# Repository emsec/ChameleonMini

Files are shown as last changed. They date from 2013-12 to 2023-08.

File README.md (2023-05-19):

Chameleon-Mini
==============
This is the official repository of ChameleonMini, a freely programmable, portable tool for NFC security analysis that can emulate and clone contactless cards, read RFID tags and sniff/log RF data. Thanks to over 1700 backers from our [Kickstarter project](https://www.kickstarter.com/projects/1980078555/chameleonmini-a-versatile-nfc-card-emulator-and-mo), the current Revision G has been realized by Kasper & Oswald GmbH.

The ChameleonMini RevG is now also available via the Kasper & Oswald [Webshop](https://shop.kasper.it/). Thank you for supporting the project!

IMPORTANT: Third-party Clones
------------------
We are aware of various third-party ChameleonMini clones or modified variants that are available on the Internet. Warning: We have evidence that some of these devices are defective or suffer from reading problems et cetera. Please understand that we cannot give support for these non-official devices, as we have no schematics / layout or other information, nor do we know the manufacturers. In case of problems, please contact the manufacturers of your device directly.

Note to the manufacturers: Some of the third-party ChameleonMini are violating the ChameleonMini license, please obey the license (see LICENSE.txt)!

First Steps
-----------
To upgrade the firmware of your ChameleonMini, please visit the [Getting Started page](https://cdn.statically.io/gh/emsec/ChameleonMini/master/Doc/Doxygen/html/Page_GettingStarted.html) from the [doxygen documentation](https://cdn.statically.io/gh/emsec/ChameleonMini/master/Doc/Doxygen/html/index.html).

Supported Cards and Codecs
--------------------------
See [here](https://github.com/emsec/ChameleonMini/wiki/Supported-Cards-and--Codecs). The linked wiki page also includes notes on DESFire emulation and certain cases of application specific emulation (Gallagher).

Questions
---------
If you have any questions, please visit the [Issues page](https://github.com/emsec/ChameleonMini/issues) and ask your questions there so everyone benefits from the answer.

**Please note that we cannot give any support if you have issues with the RevE-rebooted hardware or any GUI. Please use this issues page only for problems with the RevG hardware as distributed by Kasper & Oswald and for problems with the firmware from this page.** 

External Contributions
----------------------
We appreciate every contribution to the project. Have a look at the [External Contributions page](https://github.com/emsec/ChameleonMini/wiki/External-Contributions).

Repository Structure
--------------------
The code repository contains
* Doc: A doxygen documentation
* Drivers: Chameleon drivers for Windows and Linux
* Dumps: Dumps of different smartcards
* Hardware: The layout and schematics of the PCB
* Firmware: The complete firmware including a modified Atmel DFU bootloader and LUFA
* Software: Contains a python tool for an easy configuration (and more) of the ChameleonMini, Note that this is currently under construction
* RevE: Contains the whole contents of the discontinued RevE repository.
* RevE-light: Contains our development files for the RevE-light - **WARNING:** currently not supported / not functional

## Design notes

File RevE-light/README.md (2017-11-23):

Chameleon-Mini RevE-light
==============

**WARNING:** The files in this folder are our current development version. *The hardware and software is not functional yet* - so do not use it. We will not answer any support inquiry regarding this version at the moment.

Structure
--------------------
This part of the code repository contains

* Hardware: The layout and schematics of the RevE-light - *NOT FUNCTIONAL*
* Firmware: The RevE-light firmware - *NOT FUNCTIONAL*

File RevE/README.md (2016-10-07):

Warning
=======
The whole content of this directory is outdated and discontinued.

Chameleon-Mini
==============

Further information can be found in the [project wiki](https://github.com/emsec/ChameleonMini/wiki) 
and the [doxygen documentation](http://htmlpreview.github.io/?https://github.com/emsec/ChameleonMini/blob/master/Doc/Doxygen/html/index.html)

The code repository contains
* Doc: A doxygen documentation 
* Drivers: LUFA Drivers for the USB-CDC interface
* Dumps: Dumps of different smart cards
* EAGLE: The full EAGLE board and schematics in two alternate versions
* Firmware: The complete firmware including a modified Atmel DFU bootloader and LUFA

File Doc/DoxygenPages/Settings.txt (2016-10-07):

/** \file */
/**
 * \page Page_Settings Settings
 * 
 * The ChameleonMini can act in different ways, the behavior is defined by \ref Page_Configurations "configurations". But also, the ChameleonMini has slots, which are a layer above the configurations. With the slots, it is possible to switch between different configurations and respective content, e.g., a card dump together with the configuration as Mifare Classic 1k card.
 * 
 * Properties
 * ==========
 * A slot is defined by settings: \ref SettingsEntryType.
 * 
 * Slot Changing Procedure
 * =======================
 * When the current slot is changed, the following procedure is applied:
 * -# Break potentially pending timeout commands.
 * -# Store the memory of the setting to the Flash.
 * -# Set the slot number of the currently active slot to the number of the new slot.
 * -# Set the slot pointer of the currently active slot to the pointer of the new slot.
 * -# Since the slot also contains the configuration, apply the \ref Anchor_ConfigurationChange "configuration changing procedure" with the new configuration for the new slot.
 * -# Log the slot change.
 * -# Recall the new content of the slot from the permanent Flash.
 * -# Signalize the slot change with an \ref Page_LED "LED", if an LED is configured to `SETTING_CHANGE`.
 */

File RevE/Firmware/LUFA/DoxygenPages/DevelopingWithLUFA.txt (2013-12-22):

/** \file
 *
 *  This file contains special DoxyGen information for the generation of the main page and other special
 *  documentation pages. It is not a project source file.
 */

/**
 *  \page Page_DevelopingWithLUFA Developing With LUFA
 *
 *  This section of the manual contains information on LUFA development, such as Getting Started information,
 *  information on compile-time tuning of the library and other developer-related sections.
 *
 *  <b>Subsections:</b>
 *  \li \subpage Page_BuildSystem - The LUFA Buildsystem
 *  \li \subpage Page_TokenSummary - Summary of Compile Time Tokens
 *  \li \subpage Page_Migration - Migrating from an Older LUFA Version
 *  \li \subpage Page_VIDPID - Allocated USB VID and PID Values
 *  \li \subpage Page_OSDrivers - Operating System Driver Information
 *  \li \subpage Page_BuildLibrary - Building as a Linkable Library
 *  \li \subpage Page_ExportingLibrary - Exporting LUFA for IDE Use
 *  \li \subpage Page_WritingBoardDrivers - How to Write Custom Board Drivers
 *  \li \subpage Page_SoftwareBootloaderStart - How to jump to the bootloader in software
 */

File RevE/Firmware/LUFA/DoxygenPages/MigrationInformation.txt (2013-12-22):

/** \file
 *
 *  This file contains special DoxyGen information for the generation of the main page and other special
 *  documentation pages. It is not a project source file.
 */

/** \page Page_Migration Migrating from Older Versions
 *
 *  Below is migration information for updating existing projects based on previous versions of the LUFA library
 *  to the next version released. It does not indicate all new additions to the library in each version change, only
 *  areas relevant to making older projects compatible with the API changes of each new release.
 *
 *  \section Sec_Migration130901 Migrating from 130303 to 130901
 *  <b>Non-USB Library Components</b>
 *    - The Board Dataflash \c Dataflash_Init() function now automatically configures the appropriate communication interface.
 *
 *  \section Sec_Migration130303 Migrating from 120730 to 130303
 *  <b>Device Mode</b>
 *    - The \ref HID_KEYBOARD_LED_KANA macro was previously misspelled as \c HID_KEYBOARD_LED_KATANA, and had an incorrect value. User applications requiring this
 *      constant should use the new name, and remove any workarounds for the previously incorrect macro definition.
 *    - The \c HID_KEYBOARD_SC_EQUAL_SIGN macro has been renamed to \ref HID_KEYBOARD_SC_KEYPAD_EQUAL_SIGN, and the previous definition of
 *      \c HID_KEYBOARD_SC_KEYPAD_EQUAL_SIGN has been renamed \ref HID_KEYBOARD_SC_KEYPAD_EQUAL_SIGN_AS400 to conform to the definitions in the HID specification.
 *
 *  <b>Host Mode</b>
 *    - The \ref HID_KEYBOARD_LED_KANA macro was previously misspelled as \c HID_KEYBOARD_LED_KATANA, and had an incorrect value. User applications requiring this
 *      constant should use the new name, and remove any workarounds for the previously incorrect macro definition.
 *    - The \c HID_KEYBOARD_SC_EQUAL_SIGN macro has been renamed to \ref HID_KEYBOARD_SC_KEYPAD_EQUAL_SIGN, and the previous definition of
 *      \c HID_KEYBOARD_SC_KEYPAD_EQUAL_SIGN has been renamed \ref HID_KEYBOARD_SC_KEYPAD_EQUAL_SIGN_AS400 to conform to the definitions in the HID specification.
 *
 *  \section Sec_Migration120730 Migrating from 120219 to 120730
 *  <b>Device Mode</b>
 *    - The device mode Audio Class driver now requires an additional configuration parameter, the Audio Control interface index. Existing applications should
 *      be adjusted to specify the additional configuration parameter.
 *    - The HID_DESCRIPTOR_JOYSTICK() macro no longer takes a variable number of axis as a parameter, due to OS incompatibilities; this macro now uses a fixed
 *      3 axis of data. User applications should update their calls to this macro and their report structures to suit a fixed 3-axis joystick report. If a user
 *      application requires more than 3 axis' of data, a custom report descriptor will need to be constructed by hand.
 *    - The \ref Endpoint_ConfigureEndpoint() function no longer takes in masks for the banks and direction; the number of banks is now an integer argument, and
 *      the direction is obtained from the full endpoint address within the device. Applications calling Endpoint_ConfigureEndpoint() should update their API
 *      call to use a full endpoint address (including ENDPOINT_DIR_IN or ENDPOINT_DIR_OUT direction in the MSB of the endpoint address) and an integer number
 *      of banks.
 *    - All endpoint functions now operate on full endpoint addresses within the device, rather than a directionless endpoint index. Applications should update
 *      their API calls to use full endpoint addresses when required within the device.
 *    - All device mode class drivers have been updated to use a new unified endpoint description structure for all endpoints; existing applications will need
 *      to update their class driver struct instantiation to match the new scheme (see \ref USB_Endpoint_Table_t).
 *    - The \c ENDPOINT_BANKS_SUPPORTED() and \c ENDPOINT_MAX_ENDPOINT_SIZE() macros have been removed, as these do not function correctly with the new addressing
 *      scheme for the endpoint APIs. Please refer to the target device's datasheet for the maximum bank size of each endpoint.
 *    - The MIDI class driver \ref MIDI_EventPacket_t event packet no longer contains separate \c CableIndex and \c Command entries; these have been combined
 *      into a single \c Event element which can be constructed using the new macro \ref MIDI_EVENT(). Existing applications should use the new macro and structure
 *      element name.
 *
 *  <b>Host Mode</b>
 *    - The Android Accessory Host class driver property strings are now a array of \c char* rather than a struct of named pointers. Existing applications
 *      should use C99 Designated Initializers with the property string indexes located in \ref AOA_Strings_t instead.
 *    - The \ref Pipe_ConfigurePipe() function no longer takes in masks for the banks and token; the number of banks is now an integer argument, and the token
 *      is now inferred from the full pipe address within the device, and the pipe type. Applications calling Pipe_ConfigurePipe() should update their API
 *      call to use a full pipe address (including PIPE_DIR_IN or PIPE_DIR_OUT direction in the MSB of the pipe address) and an integer number of banks.
 *    - All pipe functions now operate on full pipe addresses within the device, rather than a directionless pipe index. Applications should update their API
 *      calls to use full pipe addresses when required within the device.
 *    - All host mode class drivers have been updated to use a new unified pipe description structure for all pipes; existing applications will need to update
 *      their class driver struct instantiation to match the new scheme (see \ref USB_Pipe_Table_t).
 *    - The MIDI class driver \ref MIDI_EventPacket_t event packet no longer contains seperate \c CableIndex and \c Command entries; these have been combined
 *      into a single \c Event element which can be constructed using the new macro \ref MIDI_EVENT(). Existing applications should use the new macro and structure
 *      element name.
 *    - The library "LUFA/Drivers/USB/Core/ConfigDescriptor.c" source file has been renamed "LUFA/Drivers/USB/Core/ConfigDescriptors.c" as this was clashing with
 *      files in some low level host mode demo applications, preventing parallel project builds. If you are referencing the project source files directly instead
 *      of using the makefile module names, you will need to adjust your project makefile.
 *
 *  \section Sec_Migration120219 Migrating from 111009 to 120219
 *  <b>USB Core</b>
 *    - The HID_KEYBOARD_MODIFER_* macros in the HID class driver have been corrected to HID_KEYBOARD_MODIFIER_* (note the spelling of "modifier").
 *      Existing applications should switch over to the correctly spelled macro names.
 *    - The names of the USB Device and USB Host class driver files have changed; a new "ClassDevice" and "ClassHost" postfix has been added to the
 *      respective class driver files. Projects referencing the class driver source files by filename rather than the LUFA_SRC_USBCLASS makefile
 *      variable should append these postfixes to the source file names. Projects including the USB class driver dispatch headers directly should either
 *      switch to including the main USB driver header instead, or use the updated header filenames.
 *    - The USB_CONFIG_ATTR_BUSPOWERED constant has been renamed to USB_CONFIG_ATTR_RESERVED, as this was misnamed. All devices must set this bit in
 *      the Configuration descriptor's attributes field. As all devices are assumed to be bus-powered unless stated otherwise with the
 *      USB_CONFIG_ATTR_SELFPOWERED flag a replacement constant for bus powered devices is not provided.
 *
 *  <b>Device Mode</b>
 *    - The device mode Audio class driver now requires a new user application callback, \ref CALLBACK_Audio_Device_GetSetInterfaceProperty().
 *      Existing applications must implement this new callback, however if no audio entities are defined in the audio device's descriptors,
 *      this function may be hard-coded to always return false for previous behaviour to be retained.
 *
 *  \section Sec_Migration111009 Migrating from 110528 to 111009
 *  <b>Non-USB Library Components</b>
 *    - The \c JTAG_DEBUG_ASSERT() macro has been renamed \ref JTAG_ASSERT() to be consistent with \ref STDOUT_ASSERT().
 *
 *  <b>USB Core</b>
 *    - By default, unordered Endpoint and Pipe configuration is now allowed once again, via the previous workaround of
 *      reconfiguring all Endpoints/Pipes in order each time a new Endpoint/Pipe is created. To minimize the compiled program
 *      size, the new \c ORDERED_EP_CONFIG compile time option may be defined in the project makefile to restrict the ordering
 *      in exchange for a smaller compiled binary size.
 *    - The previous \c F_CLOCK symbol, required in the project makefile, has been renamed to \c F_USB. This is due to the previous name
 *      being far too generic for use in future architecture ports, where multiple clock domains are used.
 *
 *  <b>Device Mode</b>
 *    - The Endpoint stream functions now all require a \c BytesProcessed parameter instead of the previous callback parameter.
 *      This should be set to \c NULL to retain previous behaviour of the functions, or point to a location where the number of bytes
 *      processed in the current transaction can be stored. If the \c BytesProcessed parameter is non \c NULL, each time the endpoint
 *      bank becomes full and the packet is sent, the routine will exit with the new \ref ENDPOINT_RWSTREAM_IncompleteTransfer
 *      error code to allow the user application to determine when to send the next chunk of data.
 *    - The \ref CDC_Device_SendString() function now expects a null terminated string instead of an explicit length. Existing code
 *      should use the new \ref CDC_Device_SendData() function, or remove the length parameter from the function call.
 *    - The \c Endpoint_ResetFIFO() function has been renamed to \ref Endpoint_ResetEndpoint(), to make the API function names more
 *      consistent. Existing applications using the old function name should simply replace it with a call to the new function name.
 *    - The \c Endpoint_*_Byte() functions have been renamed Endpoint_*_8() to ensure they are correct across all architectures. Existing
 *      code using these functions should replace the previous function names with the new function names.
 *    - The \c Endpoint_*_Word() functions have been renamed Endpoint_*_16() to ensure they are correct across all architectures. Existing
 *      code using these functions should replace the previous function names with the new function names.
 *    - The \c Endpoint_*_DWord() functions have been renamed Endpoint_*_32() to ensure they are correct across all architectures. Existing
 *      code using these functions should replace the previous function names with the new function names.
 *    - The Device mode RNDIS class driver no longer stores the incoming and outgoing packets in the class driver instance; the user is
 *      now expected to manually define a storage location for the packet data. Packets must now be sent and received manually via a call
 *      to \ref RNDIS_Device_ReadPacket() and/or \ref RNDIS_Device_SendPacket().
 *    - The definition of the Audio class \ref USB_Audio_Descriptor_Format_t has been altered, to remove the fixed singular
 *      audio sample rate in the descriptor definition, and to rename the \c SampleFrequencyType to the more appropriate
 *      \c TotalDiscreteSampleRates. Existing applications will need to add an array of \ref USB_Audio_SampleFreq_t elements
 *      immediately following any \ref USB_Audio_Descriptor_Format_t descriptors, and insert the appropriate sampling rates
 *      supported by the device, as well as rename the descriptor elements to match the updated element names.
 *    - The device mode Audio class driver now requires a new user application callback, \ref CALLBACK_Audio_Device_GetSetEndpointProperty().
 *      Existing applications must implement this new callback, however if multiple sample rates or pitch control is not used,
 *      this function may be hard-coded to always return false for previous behaviour to be retained.
 *    - The \c USB_ConfigurationNumber, \c USB_RemoteWakeupEnabled and \c USB_CurrentlySelfPowered globals have been renamed to
 *      \ref USB_Device_ConfigurationNumber, \ref USB_Device_RemoteWakeupEnabled and \ref USB_Device_CurrentlySelfPowered to clearly indicate
 *      the USB mode they relate to. Existing applications using these variables should rename all references to the previous names.
 *    - The \c ENDPOINT_DESCRIPTOR_DIR_IN and \c ENDPOINT_DESCRIPTOR_DIR_OUT macros have now been replaced by \ref ENDPOINT_DIR_IN and
 *      \ref ENDPOINT_DIR_OUT to improve code clarity.
 *    - The \ref HID_DESCRIPTOR_JOYSTICK() macro now takes an additional (first) parameter indicating the number of axis in the joystick.
 *
 *  <b>Host Mode</b>
 *    - The Pipe stream functions now all require a \c BytesProcessed parameter instead of the previous callback parameter.
 *      This should be set to \c NULL to retain previous behaviour of the functions, or point to a location where the number of bytes
 *      processed in the current transaction can be stored. If the BytesProcessed parameter is non \c NULL, each time the pipe
 *      bank becomes full and the packet is sent, the routine will exit with the new \ref PIPE_RWSTREAM_IncompleteTransfer
 *      error code to allow the user application to determine when to send the next chunk of data.
 *    - The \ref PRNT_Host_SendString() and \ref CDC_Host_SendString() functions now expect a null terminated string instead of an explicit
 *      length. Existing code should use the new \ref PRNT_Host_SendData() and \ref CDC_Host_SendData() functions, or remove the
 *      length parameter from the function call.
 *    - The \c Pipe_ClearErrorFlags() function has been removed, as the pipe error flags are now automatically cleared when the
 *      \ref Pipe_ClearError() function is called.
 *    - The \c Pipe_*_Byte() functions have been renamed Pipe_*_8() to ensure they are correct across all architectures. Existing code using
 *      these functions should replace the previous function names with the new function names.
 *    - The \c Pipe_*_Word() functions have been renamed Pipe_*_16() to ensure they are correct across all architectures. Existing code using
 *      these functions should replace the previous function names with the new function names.
 *    - The \c Pipe_*_DWord() functions have been renamed Pipe_*_32() to ensure they are correct across all architectures. Existing code using
 *      these functions should replace the previous function names with the new function names.
 *    - The \c USB_Host_ClearPipeStall() function has been renamed to USB_Host_ClearEndpointStall(), as it operates on a full endpoint address
 *      within the attached device and not a pipe within the host. Existing code using the old function name should update the function calls and
 *      check for correct usage.
 *
 *  \section Sec_Migration101122 Migrating from 100807 to 101122
 *  <b>USB Core</b>
 *    - A new USB driver source file, \c Drivers/USB/HighLevel/EndpointStream.c now exists. This source file should be added
 *      to all project makefiles using the USB driver of LUFA, or the makefile should be updated to use the new module source
 *      variables.
 *    - A new USB driver source file, \c Drivers/USB/HighLevel/PipeStream.c now exists. This source file should be added to all
 *      project makefiles using the USB driver of LUFA, or the makefile should be updated to use the new module source variables.
 *    - The \c EVENT_USB_InitFailure() event has been removed, as the \ref USB_Init() function will no longer fail; if not USB mode is
 *      specified, the controller will default to UID selection mode.
 *    - The USB mode specifier constants have been moved into a new enum and renamed. Existing projects should use the equivalent
 *      value in the new \ref USB_Modes_t enum.
 *    - All class driver headers are now included as part of the standard \c LUFA/Drivers/USB/USB.h master dispatch header, and should
 *      no longer be included separately. Class driver module source files must still be added as a separate module in the project's
 *      makefile if used.
 *
 *  <b>Device Mode</b>
 *    - Endpoints MUST be allocated in ascending order to ensure that bank corruption does not occur. Ensure that your user application
 *      allocated endpoints in ascending order - or if your application uses the USB device mode class drivers, ensure that each instance's
 *      endpoint indexes are not overlapped with other interface's endpoints.
 *    - The signature for the \ref CALLBACK_USB_GetDescriptor() callback has changed, the \c void** \c const \c DescriptorAddress parameter is
 *      now \c const \c void** \c const \c DescriptorAddress. Existing applications should update their callback signatures to match this, and
 *      eliminate any casting of descriptor pointers to a non \c const pointer.
 *    - The names of the class specific descriptor type defines in the USB Class drivers have changed - refer to the driver documentation
 *      for each class driver for the new class specific descriptor type names.
 *    - The \c ENDPOINT_DOUBLEBANK_SUPPORTED() macro is has been renamed \c ENDPOINT_BANKS_SUPPORTED() and now returns the total number of
 *      banks supported by the given endpoint. Existing code should switch to the new naming scheme, and test that the return value of the
 *      macro is equal to or greater than 2 to regain the previous functionality.
 *    - The \c EVENT_USB_Device_UnhandledControlRequest() event is now named \ref EVENT_USB_Device_ControlRequest() and fires before (not after)
 *      the internal library event handlers. Existing code should rename the event handlers in the user application to match the new event
 *      name, and should ensure that the new execution order does not affect the application's operation.
 *
 *  <b>Host Mode</b>
 *    - Pipes MUST be allocated in ascending order to ensure that bank corruption does not occur. Ensure that your user application
 *      allocated pipes in ascending order - or if your application uses the USB host mode class drivers, ensure that each instance's
 *      pipe indexes are not overlapped with other interface's pipes.
 *    - The \c PRNT_Host_SendData() function has been renamed to \ref PRNT_Host_SendString(). Existing applications should simply
 *      replace all references to the obsolete function name with the new function name.
 *    - The names of the class specific descriptor type defines in the USB Class drivers have changed - refer to the driver documentation
 *      for each class driver for the new class specific descriptor type names.
 *    - The Still Image Host class' function prefix has been changed from \c SImage_ to  \c SI_, to remain consistent with the rest of the
 *      driver's enums, type defines and constants.
 *
 *  \section Sec_Migration100807 Migrating from 100513 to 100807
 *
 *  <b>Non-USB Library Components</b>
 *    - The Dataflash board driver stub file has changed, as dataflash functions previously located in the internal
 *      Dataflash driver of the library have now been moved to the individual board files. Existing drivers can
 *      copy-paste the new functions from the board Dataflash stub driver.
 *
 *  <b>USB Core</b>
 *    - A new USB driver source file, \c Drivers/USB/LowLevel/Device.c now exists. This source file should be added to all project
 *      makefiles using the USB driver of LUFA, or the makefile should be updated to use the new module source variables.
 *    - The \c Drivers/USB/LowLevel/DevChapter9.c source file has moved to \c Drivers/USB/HighLevel/DeviceStandardReq.c - this should
 *      be updated in all project makefiles, or the makefile should be updated to use the new module source variables.
 *    - The \c Drivers/USB/LowLevel/HostChapter9.h source file has moved to \c Drivers/USB/HighLevel/HostStandardReq.c - this should
 *      be updated in all project makefiles, or the makefile should be updated to use the new module source variables.
 *    - The \c Drivers/USB/LowLevel/LowLevel.c source file has moved to \c Drivers/LowLevel/USBController.c - this should be updated
 *      in all project makefiles, or the makefile should be updated to use the new module source variables.
 *
 *  <b>Device Mode</b>
 *    - The \c USB_Device_IsRemoteWakeupSent() macro has been removed, as the remote wakeup request is now fully handled by the
 *      enhanced \ref USB_Device_SendRemoteWakeup() function. Existing code may now discard any checks to \c USB_Device_IsRemoteWakeupSent().
 *    - The \c USB_Device_IsUSBSuspended() macro has been removed, as it is obsolete. Existing code should compare \ref USB_DeviceState
 *      to see if it the device is in the \ref DEVICE_STATE_Suspended state instead.
 *    - The \ref CDC_Device_ReceiveByte() function has changed, and now returns a signed 16-bit integer, with -1 indicating no data was
 *      received. This allows for more efficient coding, as a call to \ref CDC_Device_BytesReceived() is no longer needed if the exact
 *      number of queued bytes received is not needed.
 *
 *  <b>Host Mode</b>
 *    - The \ref CDC_Host_ReceiveByte() function has changed, and now returns a signed 16-bit integer, with -1 indicating no data was
 *      received. This allows for more efficient coding, as a call to \ref CDC_Host_BytesReceived() is no longer needed if the exact
 *      number of queued bytes received is not needed.
 *    - The \ref CDC_Host_USBTask() now calls \ref CDC_Host_Flush() automatically, flushing any queued data to the attached device. Manual
 *      flushing of the interface is no longer needed if the flushes should be in sync with calls to \ref CDC_Host_USBTask().
 *
 *  \section Sec_Migration100513 Migrating from 100219 to 100513
 *
 *  <b>Non-USB Library Components</b>
 *    - The \ref TWI_StartTransmission() function now takes in a timeout period, expressed in milliseconds, within which the addressed
 *      device must respond or the function will abort.
 *
 *  <b>Device Mode</b>
 *    - The \ref USB_Init() function no longer calls \c sei() to enable global interrupts, as the user application may need
 *      to perform other initialization before it is ready to handle global interrupts. The user application is now responsible
 *      for enabling global interrupts before or shortly after calling \ref USB_Init() to ensure that the enumeration process
 *      functions correctly.
 *    - The \c USBInterrupt.c USB driver source file has been relocated from \c LUFA/Drivers/USB/HighLevel/ to \c LUFA/Drivers/USB/LowLevel.
 *      Projects must update their makefile SRC values accordingly.
 *    - The HID Device Class driver's function signature for the \ref CALLBACK_HID_Device_ProcessHIDReport() function has been changed, to
 *      allow for a new \c ReportType parameter. This new parameter must be added in all user applications using the Device mode HID Class
 *      Driver, but may be ignored unless Host-to-Device FEATURE HID reports are used.
 *
 *  <b>Host Mode</b>
 *    - The \ref USB_Init() function no longer calls \c sei() to enable global interrupts, as the user application may need
 *      to perform other initialization before it is ready to handle global interrupts. The user application is now responsible
 *      for enabling global interrupts before or shortly after calling \ref USB_Init() to ensure that the enumeration process
 *      functions correctly.
 *    - The \c USBInterrupt.c USB driver source file has been relocated from \c LUFA/Drivers/USB/HighLevel/ to \c LUFA/Drivers/USB/LowLevel.
 *      Projects must update their makefile \c SRC values accordingly.
 *    - The HID Host Class driver's function signature for the \ref HID_Host_SendReportByID() function has been changed, to allow for a new
 *      ReportType parameter. Existing calls to this function should substitute \c REPORT_ITEM_TYPE_Out as this parameter's value.
 *
 *  \section Sec_Migration100219 Migrating from 091223 to 100219
 *
 *  <b>Non-USB Library Components</b>
 *    - Due to some ADC channels not being identical to their ADC MUX selection masks for single-ended conversions on some AVR models,
 *      the ADC driver now has explicit masks for each of the standard ADC channels (see \ref Group_ADC). These masks should be used
 *      when calling the ADC functions to ensure proper operation across all AVR models. Note that the \ref ADC_SetupChannel() function
 *      is an exception, and should always be called with a channel number rather than a channel mask.
 *
 *  <b>Host Mode</b>
 *    - The MIDI Host Class driver send and receive routines now operate on packed events, where multiple MIDI events may be
 *      packed into a single USB packet. This means that the sending of MIDI events will now be delayed until the MIDI send
 *      pipe bank is full. To override this new behaviour and revert to the previous behaviour, the user application may manually
 *      flush the queued event(s) to the device by calling \ref MIDI_Host_Flush().
 *    - The \ref Pipe_IsEndpointBound() function now takes the endpoint's direction into account, by checking if the MSB of the endpoint's address
 *      is set to denote IN endpoints. If the previous functionality where the direction is to be discounted is required, mask the endpoint
 *      address against the \ref PIPE_EPNUM_MASK token before calling \ref Pipe_IsEndpointBound().
 *
 *  <b>Device Mode</b>
 *    - The MIDI Device Class driver send and receive routines now operate on packed events, where multiple MIDI events may be
 *      packed into a single USB packet. This means that the sending of MIDI events will now be delayed until the MIDI send
 *      endpoint bank is full. To override this new behaviour and revert to the previous behaviour, the user application may manually
 *      flush the queued event(s) to the host by calling \ref MIDI_Device_Flush().
 *
 *  \section Sec_Migration091223 Migrating from 091122 to 091223
 *
 *  <b>Host Mode</b>
 *    - The Still Image Host Class driver \ref SI_Host_USBTask() and \ref SI_Host_ConfigurePipes() functions were misnamed, and are
 *      now named \c SImage_Host_USBTask() and \c SImage_Host_ConfigurePipes() respectively.
 *    - The \c HOST_SENDCONTROL_DeviceDisconnect enum value has been renamed to \ref HOST_SENDCONTROL_DeviceDisconnected to be in
 *      line with the rest of the library error codes.
 *    - The HID Parser item usages no longer contain separate minimum and maximum values, as this was a violation of the HID
 *      specification. Instead, the values are distributed evenly across each item as its usage value, to ensure that all items
 *      can be distinguished from one-another.
 *
 *  <b>Device Mode</b>
 *    - The \ref CALLBACK_HID_Device_CreateHIDReport() HID Device Class driver callback now has a new \c ReportType parameter to
 *      indicate the report type to generate. Existing applications may simply add and ignore this additional parameter.
 *
 *  \section Sec_Migration091122 Migrating from 090924 to 091122
 *
 *  <b>Host Mode</b>
 *    - The \c HID_PARSE_UsageStackOverflow HID parser error constant is now named \ref HID_PARSE_UsageListOverflow
 *    - The \ref CALLBACK_HIDParser_FilterHIDReportItem() HID Parser callback now passes a complete \ref HID_ReportItem_t to the
 *      user application, instead of just its attributes.
 *    - The \c USB_GetDeviceConfigDescriptor() function was incorrectly named and is now called \ref USB_Host_GetDeviceConfigDescriptor().
 *
 *  \section Sec_Migration090924 Migrating from 090810 to 090924
 *
 *  <b>Non-USB Library Components</b>
 *    - The \c ADC_Off() function has been renamed to \c ADC_ShutDown() to be consistent with the rest of the library.
 *    - The \ref SPI_Init() routine's parameters have changed, so that the clock polarity and data sampling modes can be set. See
 *      the \ref SPI_Init() function documentation for more details
 *    - The \ref Dataflash_Init() routine no longer initializes the SPI bus - the SPI bus should be initialized manually via a
 *      call to \ref SPI_Init() before using the Dataflash driver
 *
 *  <b>Host Mode</b>
 *    - The \c USB_GetDeviceConfigDescriptor() function's parameters and behaviour has changed; the user is required to
 *      preallocate the largest allowable buffer, and pass the size of the buffer to the function. This allows for a single
 *      call to the function to retrieve, size check and validate the Configuration Descriptor rather than having the user
 *      application perform these intermediary steps.
 *    - The HID report parser now requires a mandatory callback in the user code, to filter only the items the application
 *      is interested in into the processed HID report item structure to save RAM. See \ref CALLBACK_HIDParser_FilterHIDReportItem().
 *    - The HID report parser now always parses FEATURE and always ignores constant-data items - the \c HID_ENABLE_FEATURE_PROCESSING
 *      and \c HID_INCLUDE_CONSTANT_DATA_ITEMS compile time tokens now have no effect.
 *    - The \c USE_NONSTANDARD_DESCRIPTOR_NAMES compile time token has been removed - there are now separate \c USB_Descriptor_*
 *      and \c USB_StdDescriptor_* structures for both the LUFA and standardized element naming conventions so that both may be used in
 *      the one project. For existing projects using the standardized names, change all code to use the \c USB_StdDescriptor_* variants.
 *
 *  <b>Device Mode</b>
 *    - The \c USE_NONSTANDARD_DESCRIPTOR_NAMES compile time token has been removed - there are now separate \c USB_Descriptor_*
 *      and \c USB_StdDescriptor_* structures for both the LUFA and standardized element naming conventions so that both may be used in
 *      the one project. For existing projects using the standardized names, change all code to use the \c USB_StdDescriptor_* variants.
 *
 *  \section Sec_Migration090810 Migrating from 090605 to 090810
 *
 *  <b>All</b>
 *    - The "Simple Scheduler" has been <i>deprecated</i>, as it was little more than an abstracted loop and caused much confusion.
 *      User applications using the scheduler should switch to regular loops instead. The scheduler code will be removed in a future
 *      release.
 *    - The "Dynamic Memory Block Allocator" has been removed, as it was unused in (and unrelated to) the LUFA library and never
 *      used in user applications.
 *
 *  <b>Non-USB Library Components</b>
 *    - The \c ATTR_NOINLINE function attribute macro has been renamed to \ref ATTR_NO_INLINE to be in line with the rest of the function attribute
 *      macro names.
 *
 *  <b>Library Demos</b>
 *    - Most demos now have a corresponding Class Driver implementation, which uses the new internal library class drivers for the standard
 *      USB classes. This allows for more rapid device and host development, and so should be used in preference to the low level APIs where
 *      possible so that fixes to the class drivers propagate to all applications which use them automatically with each new LUFA release.
 *
 *  <b>Host Mode</b>
 *    - The \c HIDParser.c module has moved from \c LUFA/Drivers/USB/Class/ to \c LUFA/Drivers/USB/Class/Host/.
 *    - The \c USB_GetDeviceConfigDescriptor() function now requires the desired configuration index within the device as its first
 *      parameter, to add support for multi-configuration devices. Existing code should use a configuration index of 1 to indicate the
 *      first configuration descriptor within the device.
 *    - The non-standard "Ready" host state has been removed. Existing \ref HOST_STATE_Configured code should be moved to the end of
 *      the existing \ref HOST_STATE_Addressed state, and the existing HOST_STATE_Ready state code should be moved to the \ref HOST_STATE_Configured
 *      state.
 *    - The \c USB_IsConnected global has been removed, as it is too vague for general use. Test \ref USB_HostState explicitly to ensure the host is
 *      in the desired state instead.
 *    - The USB event names have been changed and their firing conditions changed to properly separate out Host mode events from Device mode
 *      events. See the \ref Group_Events page for details on the new event names and firing conditions.
 *
 *  <b>Device Mode</b>
 *    - The \ref CALLBACK_USB_GetDescriptor() function now takes an extra parameter to specify the descriptor's memory space so that
 *      descriptors in mixed memory spaces can be used. The previous functionality can be returned by defining the \c USE_FLASH_DESCRIPTORS
 *      token in the project makefile to fix all descriptors into FLASH space and remove the extra function parameter.
 *    - The \c USB_IsSuspended global has been removed - test \ref USB_DeviceState against \ref DEVICE_STATE_Suspended instead.
 *    - The \c USB_IsConnected global has been removed, as it is too vague for general use. Test \ref USB_DeviceState explicitly to ensure the device
 *      is in the desired state instead.
 *    - The VBUS events have been removed, as they are already exposed to the user via the \c USB_Connect and \c USB_Disconnect events.
 *    - The USB event names have been changed and their firing conditions changed to properly separate out Host mode events from Device mode
 *      events. See the \ref Group_Events page for details on the new event names and firing conditions.
 *
 *  \section Sec_Migration090605 Migrating from 090510 to 090605
 *
 *  <b>Device Mode</b>
 *    - Support for non-control data endpoint interrupts has been dropped due to many issues in the implementation. All existing
 *      projects using interrupts on non-control endpoints should switch to polling. For control interrupts, the library can
 *      manage the control endpoint via interrupts automatically by compiling with the \c INTERRUPT_CONTROL_ENDPOINT token defined.
 *    - The \c DESCRIPTOR_ADDRESS() macro has been removed. User applications should use normal casts to obtain a descriptor's memory
 *      address.
 *    - The library events system has been rewritten, so that all macros have been removed to allow for clearer user code. See
 *      \ref Group_Events for new API details.
 *    - The \c STREAM_CALLBACK() macro has been removed. User applications should replace all instances of the macro with regular
 *      function signatures of a function accepting no arguments and returning a \c uint8_t value.
 *    - The \c Event_DeviceError() event no longer exists, as its sole caller (unlinked \c USB_GetDescriptor() function) now produces a
 *      compilation error rather than a runtime error. The \c StdDescriptors.c file no longer exists as a result, and should be removed
 *      from project makefiles.
 *    - The \c USB_GetDescriptor() function has been renamed to \ref CALLBACK_USB_GetDescriptor() to be in line with the new \c CALLBACK_
 *      function prefixes for functions which <i>must</i> be implemented in the user application.
 *
 *  <b>Host Mode</b>
 *    - Support for non-control data pipe interrupts has been dropped due to many issues in the implementation. All existing
 *      projects using interrupts on non-control pipes should switch to polling.
 *    - The library events system has been rewritten, so that all macros have been removed to allow for clearer user code. See
 *      \ref Group_Events for new API details.
 *    - The \c STREAM_CALLBACK() macro has been removed. User applications should replace all instances of the macro with regular
 *      function signatures of a function accepting no arguments and returning a \c uint8_t value.
 *    - The \c DESCRIPTOR_COMPARATOR() macro has been removed. User applications should replace all instances of the macro with
 *      regular function signatures of a function accepting a void pointer to the descriptor to test, and returning a \c uint8_t value.
 *
 *  \section Sec_Migration090510 Migrating from 090401 to 090510
 *
 *  <b>All</b>
 *    - The \c ButtLoadTag.h header has been removed, as it was never used for its intended purpose. Projects should either remove all
 *      \c BUTTLOADTAG() elements, or download and extract \c ButtLoadTag.h header from the ButtLoad project.
 *    - The \c Drivers/AT90USBXXX/ directory has been renamed to \c Drivers/Peripheral/.
 *    - The \c Serial_Stream driver has been renamed to \c SerialStream to remain consistent with the rest of the library naming scheme.
 *    - The HWB driver has changed to the \c Buttons driver. See the board Buttons driver documentation for the new API.
 *
 *  <b>Dual Role Mode</b>
 *    - The \c USB_PowerOnFail event has been renamed to \c USB_InitFailure.
 *    - The functions in \c OTG.h have been renamed to remain more consistent with the library API. See the functions in \c OTG.h for more
 *      details.
 *
 *  <b>Device Mode</b>
 *    - The \c Endpoint_ClearCurrentBank() macro has been removed, and is now replaced with the \ref Endpoint_ClearIN(), \ref Endpoint_ClearOUT()
 *      macros. See \c Endpoint.h documentation for more details on the new endpoint management macros.
 *    - The \c Endpoint_ReadWriteAllowed() macro has been renamed to \ref Endpoint_IsReadWriteAllowed() to be more consistent with the rest of
 *      the API naming scheme.
 *    - The \c Endpoint_IsSetupINReady() and \c Endpoint_IsSetupOUTReceived() macros have been renamed to \ref Endpoint_IsINReady() and
 *      \ref Endpoint_IsOUTReceived() respectively.
 *    - The \c Endpoint_IsSetupReceived() macro has been renamed to \ref Endpoint_IsSETUPReceived().
 *    - The \c Endpoint_ClearSetupReceived() macro has been renamed to \ref Endpoint_ClearSETUP().
 *    - All endpoint read/write/discard aliases which did not have an explicitly endianness specifier (such as \c Endpoint_Read_Word()) have
 *      been removed for clarity. Existing projects should use the \c _LE suffix on such calls to use the explicit Little Endian versions.
 *    - The \c USB_UnhandledControlPacket event no longer has any parameters. User code should no longer attempt to read in the remainder of
 *      the Control Request header as all Control Request header data is now preloaded by the library and made available in the
 *      USB_ControlRequest structure.
 *    - The \c FEATURELESS_CONTROL_ONLY_DEVICE token has been renamed to \c CONTROL_ONLY_DEVICE.
 *    - The \c STATIC_ENDPOINT_CONFIGURATION is no longer applicable as the library will apply this optimization when appropriate automatically.
 *    - The values of the \ref Endpoint_Stream_RW_ErrorCodes_t and \ref Endpoint_ControlStream_RW_ErrorCodes_t enums have had the \c ERROR_ portion
 *      of their names removed.
 *
 *  <b>Host Mode</b>
 *    - The \ref USB_Host_SendControlRequest() function no longer automatically selects the Control pipe (pipe 0) to allow it to be used on
 *      other control type pipes. Care should be taken to ensure that the Control pipe is always selected before the function is called
 *      in existing projects where the Control pipe is to be operated on.
 *    - The USB Host management task now saves and restores the currently selected pipe before and after the task runs. Projects no longer
 *      need to manage this manually when calling the USB management task.
 *    - The \c Pipe_ClearCurrentBank() macro has been removed, and is now replaced with the Pipe_ClearIN(), Pipe_ClearOUT() macros. See
 *      Pipe.h documentation for more details on the new pipe management macros.
 *    - The \c Pipe_ReadWriteAllowed() macro has been renamed to \ref Pipe_IsReadWriteAllowed() to be more consistent with the rest of the API
 *      naming scheme.
 *    - The \c Pipe_IsSetupINReceived() and \c Pipe_IsOutReady() macros have been renamed to \ref Pipe_IsINReceived() and \ref Pipe_IsOUTReady()
 *      respectively.
 *    - The new \ref Pipe_ClearSETUP() macro should be used to send SETUP transactions, rather than the previous \c Pipe_ClearSetupOUT() macro.
 *    - The \c Pipe_IsSetupSent() macro has been renamed to \ref Pipe_IsSETUPSent().
 *    - The \c Pipe_ClearSetupSent() macro is no longer applicable and should be removed.
 *    - All pipe read/write/discard aliases which did not have an explicitly endianness specifier (such as \c Pipe_Read_Word()) have
 *      been removed for clarity. Existing projects should use the \c _LE suffix on such calls to use the explicit Little Endian versions.
 *    - The \c Host_IsResetBusDone() macro has been renamed to \c Host_IsBusResetComplete().
 *    - The \c Pipe_Ignore_Word() and \c Pipe_Ignore_DWord() functions have been renamed to \c Pipe_Discard_Word() and \c Pipe_Discard_DWord()
 *      to remain consistent with the rest of the pipe API.
 *    - It is no longer needed to manually include the headers from \c LUFA/Drivers/USB/Class, as they are now included along with the rest
 *      of the USB headers when \c LUFA/Drivers/USB/USB.h is included.
 *    - Functions in the \c ConfigDescriptor.h header file no longer have \c Host_ as part of their names.
 *    - The \c ProcessHIDReport() has been renamed to \ref USB_ProcessHIDReport(), \c GetReportItemInfo() has been renamed to \ref USB_GetHIDReportItemInfo()
 *      and \c SetReportItemInfo() has been renamed to \ref USB_GetHIDReportItemInfo().
 *    - The values of the \ref DSearch_Return_ErrorCodes_t and \ref DSearch_Comp_Return_ErrorCodes_t enums have had their respective \c Descriptor_Search
 *      and \c Descriptor_Search_Comp prefixes changed to all caps.
 *    - The \c USB_HostRequest global has been renamed to \ref USB_ControlRequest, and is used in Device mode also. The \c USB_Host_Request_Header_t
 *      structure type has been renamed to \ref USB_Request_Header_t.
 *    - The values of the \ref Pipe_Stream_RW_ErrorCodes_t enum have had the \c ERROR_ portion of their names removed.
 *
 *  \section Sec_Migration090401 Migrating from 090209 to 090401
 *
 *  <b>All</b>
 *    - LUFA projects must now give the raw input clock frequency (before any prescaling) as a compile time constant \c F_USB,
 *      defined in the project makefile and passed to the compiler via the -D switch.
 *    - The makefile EEPROM programming targets for FLIP and dfu-programmer no longer program in the FLASH data in addition to the
 *      EEPROM data into the device. If both are to be programmed, both the EEPROM and FLASH programming targets must be called.
 *    - As the avr-libc macro has been corrected in recent avr-libc distributions, the \c SetSystemClockPrescaler() macro has been removed.
 *      Include \c <avr/power.h> and call \c clock_prescale_set(clock_div_1); instead on recent avr-libc distributions.
 *
 *  <b>Library Demos</b>
 *    - The USBtoSerial demo now discards all data when not connected to a host, rather than buffering it for later transmission.
 *
 *  <b>Non-USB Library Components</b>
 *    - The \c ATTR_ALWAYSINLINE function attribute macro has been renamed to \ref ATTR_ALWAYS_INLINE.
 *    - Custom board Dataflash drivers now require the implementation of \ref Dataflash_SelectChipFromPage() and \ref Dataflash_SendAddressBytes().
 *
 *  <b>Device Mode</b>
 *    - The \c NO_CLEARSET_FEATURE_REQUEST compile time token has been renamed to \c FEATURELESS_CONTROL_ONLY_DEVICE, and its function expanded
 *      to also remove parts of the Get Status chapter 9 request to further reduce code usage. On all applications currently using the
 *      \c NO_CLEARSET_FEATURE_REQUEST compile time token, it can be replaced with the \c FEATURELESS_CONTROL_ONLY_DEVICE token with no further
 *      modifications required.
 *
 *  \section Sec_Migration090209 Migrating from 081217 to 090209
 *
 *  <b>Device Mode</b>
 *    - The \c ENDPOINT_MAX_ENDPOINTS constant has been renamed to the more appropriate name of \c ENDPOINT_TOTAL_ENDPOINTS.
 *    - The \c USB_STREAM_TIMEOUT_MS stream timeout default period has been extended to 100ms. This can be overridden in the user
 *      makefile if desired to restore the previous 50ms timeout.
 *
 *  <b>Host Mode</b>
 *    - The \c PIPE_MAX_ENDPOINTS constant has been renamed to the more appropriate name of \c PIPE_TOTAL_ENDPOINTS.
 *    - The \c USB_STREAM_TIMEOUT_MS stream timeout default period has been extended to 100ms. This can be overridden in the user
 *      makefile if desired to restore the previous 50ms timeout.
 *    - The \c USB_DeviceEnumerationFailed event now contains a second \c SubErrorCode parameter, giving the error code of the function
 *      which failed.
 *    - The \c HID_PARSE_Sucessful enum member constant name has been corrected to \ref HID_PARSE_Successful.
 *
 *  <b>Non-USB Library Components</b>
 *    - The previous \c SPI_SendByte() functionality is now located in \ref SPI_TransferByte(). \ref SPI_SendByte() now discards the return byte
 *      for speed, to compliment the new \ref SPI_ReceiveByte() function. If bidirectional SPI transfers are required, calls to \ref SPI_SendByte()
 *      should be changed to \ref SPI_TransferByte().
 *    - The serial driver now sets the Tx line as an output explicitly, and enables the pull-up of the Rx line.
 *    - The \ref Serial_Init() and \c SerialStream_Init() functions now take a second \c DoubleSpeed parameter, which indicates if the USART
 *      should be initialized in double speed mode - useful in some circumstances for attaining baud rates not usually possible at the given AVR
 *      clock speed.
 *
 *  \section Sec_Migration171208 Migrating from V1.5.3 to 081217
 *
 *  <b>All</b>
 *    - The MyUSB project name has been changed to LUFA (Lightweight Framework for USB AVRs). All references to MyUSB, including macro names,
 *      have been changed to LUFA.
 *
 *  <b>Library Demos</b>
 *    - The ReconfigureUSART() routine in the USBtoSerial demo was not being called after new line encoding
 *      parameters were set by the host. Projects built on the USBtoSerial code should update to the latest version.
 *    - The HID Parser now supports multiple report (on a single endpoint) HID devices. The MouseHostWithParser and
 *      KeyboardHostWithPaser demos use the updated API functions to function correctly on such devices. Projects
 *      built on either "WithParser" demo should update to the latest code.
 *    - The RNDIS demo TCP stack has been modified so that connections can be properly closed. It is still not
 *      recommended that the MyUSB RNDIS demo TCP/IP stack be used for anything other than demonstration purposes,
 *      as it is neither a full nor a standards compliant implementation.
 *
 *  <b>Non-USB Library Components</b>
 *    - The Serial_IsCharReceived() macro has been changed to the correct spelling of Serial_IsCharReceived() in Serial.h.
 *
 *  <b>Device Mode</b>
 *    - The MANUAL_PLL_CONTROL compile time token has been removed, and replaced with a USB_OPT_MANUAL_PLL mask
 *      to be used in the Options parameter of the USB_Init() function.
 *    - Calling USB_Init() now forces a complete USB interface reset and enumeration, even if the USB interface is
 *      currently initialized.
 *    - Interrupts are now disabled when processing control requests, to avoid problems with interrupts causing the library
 *      or user request processing code to exceed the strict USB timing requirements on control transfers.
 *    - The USB Reset event now resets and disables all device endpoints. If user code depends on endpoints remaining configured
 *      after a Reset event, it should be altered to explicitly re-initialize all user endpoints.
 *    - The prototype for the GetDescriptor function has been changed, as the return value was redundant. The function now
 *      returns the size of the descriptor, rather than passing it back via a parameter, or returns NO_DESCRIPTOR if the specified
 *      descriptor does not exist.
 *    - The NO_DESCRIPTOR_STRING macro has been renamed NO_DESCRIPTOR, and is now also used as a possible return value for the
 *      GetDescriptor function.
 *
 *  <b>Host Mode</b>
 *    - The MANUAL_PLL_CONTROL compile time token has been removed, and replaced with a USB_OPT_MANUAL_PLL mask
 *      to be used in the Options parameter of the USB_Init() function.
 *    - The HID report parser now supports multiple Report IDs. The HID report parser GetReportItemInfo() and
 *      SetReportItemInfo() routines now return a boolean, set if the requested report item was located in the
 *      current report. If sending a report to a multi-report device, the first byte of the report is automatically
 *      set to the report ID of the given report item.
 *    - Calling USB_Init() now forces a complete USB interface reset and enumeration, even if the USB interface is
 *      currently initialized.
 *
 *  \section Sec_Migration152 Migrating from V1.5.2 to V1.5.3
 *
 *  <b>Library Demos</b>
 *    - Previously, all demos contained a serial number string descriptor, filled with all zeros. A serial number
 *      string is required in Mass Storage devices, or devices which are to retain settings when moved between
 *      ports on a machine. As people were not changing the serial number value, this was causing conflicts and so
 *      the serial number descriptor has been removed from all but the Mass Storage demo, which requires it.
 *    - The AudioOut and AudioIn demos did not previously silence their endpoints when the host has deactivated
 *      them. Projects built upon either demo should upgrade to the latest code.
 *    - The FEATURE_ENDPOINT macro has been renamed FEATURE_ENDPOINT_HALT, and is now correctly documented.
 *    - The MassStoreHost demo contained errors which caused it to lock up randomly on certain devices. Projects built
 *      on the MassStoreDemo code should update to the latest version.
 *    - The Interrupt type endpoint in the CDC based demos previously had a polling interval of 0x02, which caused
 *      problems on some Linux systems. This has been changed to 0xFF, projects built on the CDC demos should upgrade
 *      to the latest code.
 *    - The HID keyboard and mouse demos were not previously boot mode compatible. To enable boot mode support, projects
 *      built on the keyboard or mouse demos (or derivatives) should upgrade to the latest code.
 *    - The Mass Storage demo was not previously standards compliant. Projects built on the Mass Storage demo should
 *      upgrade to the latest code.
 *    - The USART was not being reconfigured after the host sent new encoding settings in the USBtoSerial demo. This was
 *      previously discovered and fixed, but the change was lost. Projects built on the USBtoSerial demo should update
 *      to the latest code.
 *
 *  <b>Device Mode</b>
 *    - The endpoint non-control stream functions now have a default timeout of 50ms between packets in the stream.
 *      If this timeout is exceeded, the function returns the new ENDPOINT_RWSTREAM_ERROR_Timeout error value. The
 *      timeout value can be overridden by defining the USB_STREAM_TIMEOUT_MS in the project makefile to the desired
 *      timeout duration in ms.
 *    - Rather than returning fixed values, the flags indicating if the device has Remote Wakeup currently enabled
 *      and/or is self-powered are now accessed and set through the new USB_RemoteWakeupEnabled and
 *      USB_CurrentlySelfPowered macros. See the DevChapter9.h documentation for more details.
 *    - All endpoint stream functions now require an extra Callback function parameter. Existing code may be updated
 *      to either supply NO_STREAM_CALLBACK as the extra parameter, or disable stream callbacks altogether by passing
 *      the token NO_STREAM_CALLBACKS to the compiler using the -D switch.
 *
 *  <b>Host Mode</b>
 *    - The pipe non-control stream functions now have a default timeout of 50ms between packets in the stream.
 *      If this timeout is exceeded, the function returns the new PIPE_RWSTREAM_ERROR_Timeout error value. The
 *      timeout value can be overridden by defining the USB_STREAM_TIMEOUT_MS in the project makefile to the desired
 *      timeout duration in ms.
 *    - CollectionPath_t has been renamed to HID_CollectionPath_t to be more in line with the other HID parser structures.
 *    - All pipe stream functions now require an extra Callback function parameter. Existing code may be updated
 *      to either supply NO_STREAM_CALLBACK as the extra parameter, or disable stream callbacks altogether by passing
 *      the token NO_STREAM_CALLBACKS to the compiler using the -D switch.
 *
 *  \section Sec_Migration151 Migrating from V1.5.1 to V1.5.2
 *
 *  <b>Library Demos</b>
 *    - The RNDIS demo application has been updated so that it is functional on Linux under earlier implementations
 *      of the RNDIS specification, which had non-standard behaviour. Projects built upon the demo should upgrade
 *      to the latest code.
 *    - The DFU class bootloader has had several bugs corrected in this release. It is recommended that where
 *      possible any existing devices upgrade to the latest bootloader code.
 *
 *  \section Sec_Migration150 Migrating from V1.5.0 to V1.5.1
 *
 *  <b>Library Demos</b>
 *    - The USBtoSerial demo was broken in the 1.5.0 release, due to incorrect register polling in place of the
 *      global "Transmitting" flag. The change has been reverted in this release. Projects built upon the demo
 *      should upgrade to the latest code.
 *    - The HID class demos did not implement the mandatory GetReport HID class request. Projects built upon the HID
 *      demos should upgrade to the latest code.
 *    - The HID class demos incorrectly reported themselves as boot-protocol enabled HID devices in their descriptors.
 *      Projects built upon the HID demos should upgrade to the latest code.
 *    - The MIDI device demo had incorrect AudioStreaming interface descriptors. Projects built upon the MIDI demo
 *      should upgrade to the latest code.
 *    - The AudioOut demo did not correctly tristate the speaker pins when USB was disconnected, wasting power.
 *      Projects built upon the AudioOut demo should upgrade to the latest code.
 *
 *  \section Sec_Migration141 Migrating from V1.4.1 to V1.5.0
 *
 *  <b>Library Demos</b>
 *    - Previous versions of the library demos had incorrectly encoded BCD version numbers in the descriptors. To
 *      avoid such mistakes in the future, the VERSION_BCD macro has been added to StdDescriptors.h. Existing
 *      projects should at least manually correct the BCD version numbers, or preferably update the descriptors to
 *      encode the version number in BCD format using the new macro.
 *    - The mandatory GetReport class-specific request was accidentally omitted from previous versions of the demos
 *      based on the Human Interface Device (HID) class. This has been corrected, and any user projects based on the
 *      HID demos should also be updated accordingly.
 *    - The CDC demos now correctly send an empty packet directly after a full packet, to end the transmission.
 *      Failure to do this on projects which always or frequently send full packets will cause buffering issues on
 *      the host OS. All CDC user projects are advised to update their transmission routines in the same manner as
 *      the library CDC demos.
 *    - The previous interrupt-driven Endpoint/Pipe demos did not properly save and restore the currently selected
 *      Endpoint/Pipe when the ISR fired. This has been corrected - user projects based on the interrupt driven
 *      demos should also update to properly save and restore the selected Endpoint/Pipe.
 *
 *  <b>Non-USB Library Components</b>
 *    - The Atomic.h and ISRMacro.h header files in MyUSB/Common have been removed, as the library is now only
 *      compatible with avr-libc library versions newer than the time before the functionality of the deleted
 *      headers was available.
 *
 *  <b>Device Mode</b>
 *    - The GetDescriptor function (see StdDescriptors.h) now has a new prototype, with altered parameter names and
 *      functions. Existing projects will need to update the GetDescriptor implementation to reflect the new API.
 *      The previously split Type and Index parameters are now passed as the original wValue parameter to the
 *      function, to make way for the USB specification wIndex parameter which is <i>not</i> the same as the
 *      previous Index parameter.
 *    - The USB_UnhandledControlPacket event (see Events.h) now has new parameter names, to be in line with the
 *      official USB specification. Existing code will need to be altered to use the new parameter names.
 *    - The USB_CreateEndpoints event (see Events.h) has been renamed to USB_ConfigurationChanged, which is more
 *      appropriate. It fires in an identical manner to the previously named event, thus the only change to be made
 *      is the event name itself in the user project.
 *    - The USB_Descriptor_Language_t structure no longer exists in StdDescriptors.h, as this was a
 *      pseudo-descriptor modeled on the string descriptor. It is replaced by the true USB_Descriptor_String_t type
 *      descriptor as indicated in the USB specification, thus all device code must be updated accordingly.
 *    - The names of several Endpoint macros have been changed to be more consistent with the rest of the library,
 *      with no implementation changes. This means that existing code can be altered to use the new macro names
 *      with no other considerations required. See Endpoint.h for the new macro names.
 *    - The previous version of the MassStorage demo had an incorrect value in the SCSI_Request_Sense_Response_t
 *      structure named SenseData in SCSI.c which caused some problems with some hosts. User projects based on this
 *      demo should correct the structure value to maintain compatibility across multiple OS platforms.
 *    - By default, the descriptor structures use the official USB specification names for the elements. Previous
 *      versions of the library used non-standard (but more verbose) names, which are still usable in the current
 *      and future releases when the correct compile time option is enabled. See the StdDescriptors.h file
 *      documentation for more details.
 *
 *  <b>Host Mode</b>
 *    - The USB_Host_Request_Header_t structure in HostChapter9.h (used for issuing control requests) has had its
 *      members renamed to the official USB specification names for requests. Existing code will need to be updated
 *      to use the new names.
 *    - The names of several Pipe macros have been changed to be more consistent with the rest of the library,
 *      with no implementation changes. This means that existing code can be altered to use the new macro names
 *      with no other considerations required. See Pipe.h for the new macro names.
 *    - By default, the descriptor structures use the official USB specification names for the elements. Previous
 *      versions of the library used non-standard (but more verbose) names, which are still usable in the current
 *      and future releases when the correct compile time option is enabled. See the StdDescriptors.h file
 *      documentation for more details.
 *    - The names of the macros in Host.h for controlling the SOF generation have been renamed, see the Host.h
 *      module documentation for the new macro names.
 *
 *  <b>Dual Role Mode</b>
 *    - The OTG.h header file has been corrected so that the macros now perform their stated functions. Any existing
 *      projects using custom headers to fix the broken OTG header should now be altered to once again use the OTG
 *      header inside the library.
 *    - The USB_DeviceEnumerationComplete event (see Events.h) now also fires in Device mode, when the host has
 *      finished enumerating the device. Projects relying on the event only firing in Host mode should be updated
 *      so that the event action only occurs when the USB_Mode global is set to USB_MODE_HOST.
 */

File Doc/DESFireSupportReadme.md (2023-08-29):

# Chameleon Mini firmware support for DESFire tag emulation

## Quick configuration of cloned DESFire tags

### Chameleon Mini terminal addons to support DESFire tag configurations

#### Selecting a DESFire configuration

```bash
CONFIG=?
CONFIG=MF_DESFIRE
CONFIG=MF_DESFIRE_2KEV1
CONFIG=MF_DESFIRE_4KEV1
CONFIG=MF_DESFIRE_4KEV2
```

#### DF_SETHDR -- Set PICC header information 

The UID for the tag can be set using separate Chameleon terminal commands as 
usual for all other configurations.
We can modify the remaining tag header information emulated by the tag as follows:
```bash
DF_SETHDR=ATS NNxxxx[...]
DF_SETHDR=ATQA xxxx
DF_SETHDR=ManuID xx
DF_SETHDR=HwType xx
DF_SETHDR=HwSubtype xx
DF_SETHDR=HwProtoType xx 
DF_SETHDR=HwVers mmMM
DF_SETHDR=SwType xx
DF_SETHDR=SwSubtype xx
DF_SETHDR=SwProtoType xx
DF_SETHDR=SwVers mmMM
DF_SETHDR=BatchNo xxxxxxxxxx
DF_SETHDR=ProdDate WWYY
```
Warning! The ATS bytes have the following structure `NNxxxx[...]` where NN is the length of the entire ATS, including the length byte. The ATS (inc. the len byte) can be from 3 to 20 bytes long. The default is `067577810280`.

##### Examples:

The default ATS bytes for a DESFire tag are the same as specifying:
```bash
DF_SETHDR=ATS 067577810280
```
To set the ATS bytes reported to emulate a JCOP tag:
```bash
DF_SETHDR=ATS 0675f7b102
```
To reset the ATQA value returned in the anticollision loop handshaking:
```
DF_SETHDR=ATQA 0344
DF_SETHDR=ATQA 2838
```

##### Documentation for cloning specific tag types

```cpp
/* Other HW product types for DESFire tags: See page 7 of
 * https://www.nxp.com/docs/en/application-note/AN12343.pdf
 */
// typedef enum DESFIRE_FIRMWARE_ENUM_PACKING {
//     NATIVEIC_PHYS_CARD                 = 0x01,
//     LIGHT_NATIVEIC_PHYS_CARD           = 0x08,
//     MICROCONTROLLER_PHYS_CARDI         = 0x81,
//     MICROCONTROLLER_PHYS_CARDII        = 0x83,
//     JAVACARD_SECURE_ELEMENT_PHYS_CARD  = 0x91,
//     HCE_MIFARE_2GO                     = 0xa1,
// } DESFireHWProductCodes;
```
An up-to-date listing of bytes that indicate the tag manufacturer ID is 
found in the [Proxmark3 client source](https://github.com/RfidResearchGroup/proxmark3/blob/65b9a9fb769541f5d3e255ccf2c17d1cb77ac126/client/src/cmdhf14a.c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):
```cpp
static const manufactureName_t manufactureMapping[] = {
    // ID,  "Vendor Country"
    { 0x01, "Motorola UK" },
    { 0x02, "ST Microelectronics SA France" },
    { 0x03, "Hitachi, Ltd Japan" },
    { 0x04, "NXP Semiconductors Germany" },
    { 0x05, "Infineon Technologies AG Germany" },
    { 0x06, "Cylink USA" },
    { 0x07, "Texas Instrument France" },
    { 0x08, "Fujitsu Limited Japan" },
    { 0x09, "Matsushita Electronics Corporation, Semiconductor Company Japan" },
    { 0x0A, "NEC Japan" },
    { 0x0B, "Oki Electric Industry Co. Ltd Japan" },
    { 0x0C, "Toshiba Corp. Japan" },
    { 0x0D, "Mitsubishi Electric Corp. Japan" },
    { 0x0E, "Samsung Electronics Co. Ltd Korea" },
    { 0x0F, "Hynix / Hyundai, Korea" },
    { 0x10, "LG-Semiconductors Co. Ltd Korea" },
    { 0x11, "Emosyn-EM Microelectronics USA" },
    { 0x12, "INSIDE Technology France" },
    { 0x13, "ORGA Kartensysteme GmbH Germany" },
    { 0x14, "SHARP Corporation Japan" },
    { 0x15, "ATMEL France" },
    { 0x16, "EM Microelectronic-Marin SA Switzerland" },
    { 0x17, "KSW Microtec GmbH Germany" },
    { 0x18, "ZMD AG Germany" },
    { 0x19, "XICOR, Inc. USA" },
    { 0x1A, "Sony Corporation Japan" },
    { 0x1B, "Malaysia Microelectronic Solutions Sdn. Bhd Malaysia" },
    { 0x1C, "Emosyn USA" },
    { 0x1D, "Shanghai Fudan Microelectronics Co. Ltd. P.R. China" },
    { 0x1E, "Magellan Technology Pty Limited Australia" },
    { 0x1F, "Melexis NV BO Switzerland" },
    { 0x20, "Renesas Technology Corp. Japan" },
    { 0x21, "TAGSYS France" },
    { 0x22, "Transcore USA" },
    { 0x23, "Shanghai belling corp., ltd. China" },
    { 0x24, "Masktech Germany Gmbh Germany" },
    { 0x25, "Innovision Research and Technology Plc UK" },
    { 0x26, "Hitachi ULSI Systems Co., Ltd. Japan" },
    { 0x27, "Cypak AB Sweden" },
    { 0x28, "Ricoh Japan" },
    { 0x29, "ASK France" },
    { 0x2A, "Unicore Microsystems, LLC Russian Federation" },
    { 0x2B, "Dallas Semiconductor/Maxim USA" },
    { 0x2C, "Impinj, Inc. USA" },
    { 0x2D, "RightPlug Alliance USA" },
    { 0x2E, "Broadcom Corporation USA" },
    { 0x2F, "MStar Semiconductor, Inc Taiwan, ROC" },
    { 0x30, "BeeDar Technology Inc. USA" },
    { 0x31, "RFIDsec Denmark" },
    { 0x32, "Schweizer Electronic AG Germany" },
    { 0x33, "AMIC Technology Corp Taiwan" },
    { 0x34, "Mikron JSC Russia" },
    { 0x35, "Fraunhofer Institute for Photonic Microsystems Germany" },
    { 0x36, "IDS Microchip AG Switzerland" },
    { 0x37, "Thinfilm - Kovio USA" },
    { 0x38, "HMT Microelectronic Ltd Switzerland" },
    { 0x39, "Silicon Craft Technology Thailand" },
    { 0x3A, "Advanced Film Device Inc. Japan" },
    { 0x3B, "Nitecrest Ltd UK" },
    { 0x3C, "Verayo Inc. USA" },
    { 0x3D, "HID Global USA" },
    { 0x3E, "Productivity Engineering Gmbh Germany" },
    { 0x3F, "Austriamicrosystems AG (reserved) Austria" },
    { 0x40, "Gemalto SA France" },
    { 0x41, "Renesas Electronics Corporation Japan" },
    { 0x42, "3Alogics Inc Korea" },
    { 0x43, "Top TroniQ Asia Limited Hong Kong" },
    { 0x44, "Gentag Inc. USA" },
    { 0x45, "Invengo Information Technology Co.Ltd China" },
    { 0x46, "Guangzhou Sysur Microelectronics, Inc China" },
    { 0x47, "CEITEC S.A. Brazil" },
    { 0x48, "Shanghai Quanray Electronics Co. Ltd. China" },
    { 0x49, "MediaTek Inc Taiwan" },
    { 0x4A, "Angstrem PJSC Russia" },
    { 0x4B, "Celisic Semiconductor (Hong Kong) Limited China" },
    { 0x4C, "LEGIC Identsystems AG Switzerland" },
    { 0x4D, "Balluff GmbH Germany" },
    { 0x4E, "Oberthur Technologies France" },
    { 0x4F, "Silterra Malaysia Sdn. Bhd. Malaysia" },
    { 0x50, "DELTA Danish Electronics, Light & Acoustics Denmark" },
    { 0x51, "Giesecke & Devrient GmbH Germany" },
    { 0x52, "Shenzhen China Vision Microelectronics Co., Ltd. China" },
    { 0x53, "Shanghai Feiju Microelectronics Co. Ltd. China" },
    { 0x54, "Intel Corporation USA" },
    { 0x55, "Microsensys GmbH Germany" },
    { 0x56, "Sonix Technology Co., Ltd. Taiwan" },
    { 0x57, "Qualcomm Technologies Inc USA" },
    { 0x58, "Realtek Semiconductor Corp Taiwan" },
    { 0x59, "Freevision Technologies Co. Ltd China" },
    { 0x5A, "Giantec Semiconductor Inc. China" },
    { 0x5B, "JSC Angstrem-T Russia" },
    { 0x5C, "STARCHIP France" },
    { 0x5D, "SPIRTECH France" },
    { 0x5E, "GANTNER Electronic GmbH Austria" },
    { 0x5F, "Nordic Semiconductor Norway" },
    { 0x60, "Verisiti Inc USA" },
    { 0x61, "Wearlinks Technology Inc. China" },
    { 0x62, "Userstar Information Systems Co., Ltd Taiwan" },
    { 0x63, "Pragmatic Printing Ltd. UK" },
    { 0x64, "Associacao do Laboratorio de Sistemas Integraveis Tecnologico - LSI-TEC Brazil" },
    { 0x65, "Tendyron Corporation China" },
    { 0x66, "MUTO Smart Co., Ltd. Korea" },
    { 0x67, "ON Semiconductor USA" },
    { 0x68, "TUBITAK BILGEM Turkey" },
    { 0x69, "Huada Semiconductor Co., Ltd China" },
    { 0x6A, "SEVENEY France" },
    { 0x6B, "ISSM France" },
    { 0x6C, "Wisesec Ltd Israel" },
    { 0x7C, "DB HiTek Co Ltd Korea" },
    { 0x7D, "SATO Vicinity Australia" },
    { 0x7E, "Holtek Taiwan" },
    { 0x00, "no tag-info available" } // must be the last entry
};
```
Similarly, the PM3 source maintains the authoritative way to 
fingerprint the DESFire tag subtype in the 
[client source files](https://github.com/RfidResearchGroup/proxmark3/blob/65b9a9fb769541f5d3e255ccf2c17d1cb77ac126/client/src/cmdhfmfdes.c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):
```cpp
    if (major == 0x00)
        return DESFIRE_MF3ICD40;
    if (major == 0x01 && minor == 0x00)
        return DESFIRE_EV1;
    if (major == 0x12 && minor == 0x00)
        return DESFIRE_EV2;
    if (major == 0x22 && minor == 0x00)
        return DESFIRE_EV2_XL;
    if (major == 0x42 && minor == 0x00)
        return DESFIRE_EV2;
    if (major == 0x33 && minor == 0x00)
        return DESFIRE_EV3;
    if (major == 0x30 && minor == 0x00)
        return DESFIRE_LIGHT;
    if (major == 0x11 && minor == 0x00)
        return PLUS_EV1;
    if (major == 0x10 && minor == 0x00)
        return NTAG413DNA;
    return DESFIRE_UNKNOWN;
```
Table 2 in section 2.1 of [NXP AN10833](https://www.nxp.com/docs/en/application-note/AN10833.pdf) (page 5) lists
standard Mifare tag identifications for several tags. This byte is represented by setting 
``Picc.HwType`` using the Chameleon terminal command ``DF_SETHDR=HwType xx``. The default setting for the 
Chameleon DESFire tags is ``0x01`` (*MIFARE DESFire*). The table in the application note is reproduced 
below for reference. The NXP documentation says: "*The upper nibble [X] defines if the
device is a native MIFARE IC (``0x0``), an implementation (``0x8``), an applet on a Java Card
(``0x9``) or MIFARE 2GO (``0xA``).*"

| Second Byte of GetVersion Response (``Picc.HwType``) | NXP Type Tag |
| :---: | :-- |
| ``0xX1`` | *MIFARE DESFire* |
| ``0xX2`` | *MIFARE Plus* |
| ``0xX3`` | *MIFARE Ultralight* |
| ``0xX4`` | *NTAG* |
| ``0xX5`` | *RFU* |
| ``0xX6`` | *RFU* |
| ``0xX7`` | *NTAG I2C* |
| ``0xX8`` | *MIFARE DESFire Light* |

#### DF_COMM_MODE -- Manually sets the communication mode of the current session

The supported (work in progress) DESFire communication modes include: 
PLAINTEXT, PLAINTEXT-MAC, ENCIPHERED-CMAC-3DES, and ENCIPHERED-CMAC-AES128. 
It should be clear from the prior commands issued in the session which ``CommMode`` 
congiguration we are supposed to be working within. This command let's the user 
reset it intentionally at will for testing and debugging purposes. 

The syntax is as follows:
```bash
DF_COMM_MODE=Plaintext
DF_COMM_MODE=Plaintext:MAC
DF_COMM_MODE=Enciphered:3K3DES
DF_COMM_MODE=Enciphered:AES128
```
Use of this experimental command may cause unexpected results, vulnerabilities exposing 
your keys and sensitive (a priori) protected data to hackers and sniffers, and is 
discouraged unless you know what you are doing :) Try not to report bugs with the 
DESFire emulation if things suddenly fail after a call to this terminal command. 
Putting the Chameleon through a full power recycle (battery off) should reset the setting 
to the defaults. 

#### DF_COMM_MODE -- Manually sets the communication mode of the current session

This commanf sets the encryption mode for cryptographic operations. 
The two supported modes are ECB and CBC. 
The default mode for AES and DES (all types) of encryption is ECB mode. 
This is the supported mode for DESFire tags using the latest Proxmark3 software. 

The syntax is demonstrated by the following examples:
```bash
DF_ENCMODE=ECB
DF_ENCMODE=DES:ECB
DF_ENCMODE=AES:ECB
DF_ENCMODE=CBC
DF_ENCMODE=DES:CBC
DF_ENCMODE=AES:CBC
```

## Supported functionality

### Proxmark3 (PM3) compatibility and support 

The next PM3 commands are known to work with the Chameleon DESFire tag emulation (using both the RDV4 and Easy device types). 
The sample outputs obtained running the ``pm3`` command line utility below may vary by usage and proximity to the PM3 hardware.

#### PM3 logging and debugging setup script (run this first)

```bash
hw dbg -4
prefs set clientdebug --full
data setdebugmode -2
```

#### Listing initial tag response

```bash
[usb] pm3 --> hf mfdes list
[=] downloading tracelog data from device
[+] Recorded activity (trace len = 146 bytes)
[=] start = start of start frame end = end of frame. src = source of transfer
[=] ISO14443A - all times are in carrier periods (1/13.56MHz)

      Start |        End | Src | Data (! denotes parity error)                                           | CRC | Annotation
------------+------------+-----+-------------------------------------------------------------------------+-----+--------------------
          0 |        992 | Rdr |52                                                                       |     | WUPA
       2116 |       4484 | Tag |04  03                                                                   |     | 
       7040 |       9504 | Rdr |93  20                                                                   |     | ANTICOLL
      10580 |      16404 | Tag |88  08  e2  38  5a                                                       |     | 
      19072 |      29600 | Rdr |93  70  88  08  e2  38  5a  95  d5                                       |  ok | SELECT_UID
      30660 |      34180 | Tag |24  d8  36                                                               |     | 
      35584 |      38048 | Rdr |95  20                                                                   |     | ANTICOLL-2
      39124 |      44948 | Tag |f6  12  53  42  f5                                                       |     | 
      47616 |      58080 | Rdr |95  70  f6  12  53  42  f5  cb  66                                       |  ok | SELECT_UID-2
      59220 |      62804 | Tag |20  fc  70                                                               |     | 
      64512 |      69280 | Rdr |e0  80  31  73                                                           |  ok | RATS
```

#### Getting a summary of tag information

The output of this command will change significantly if the header and 
manufacturer bytes are changed using the Chameleon terminal commands above. 
The tag type reported will also vary depending on which EV0/EV1/EV2 generation of the
DESFire configuration is used:
```bash
[usb] pm3 --> hf mfdes info
[#] BCC2 incorrect, got 0xf5, expected 0x12
[#] Aborting
[#] Can't select card
[#] switch_off
[!] ⚠️  Can't select card
[usb] pm3 --> hf mfdes info
[#] pcb_blocknum 0 == 2 
[#] [WCMD <--: : 08/08] 02 90 60 00 00 00 14 98 
[#] pcb_blocknum 1 == 3 
[#] [WCMD <--: : 08/08] 03 90 af 00 00 00 1f 15 
[#] pcb_blocknum 0 == 2 
[#] [WCMD <--: : 08/08] 02 90 af 00 00 00 34 11 
[#] halt warning. response len: 4
[#] Halt error
[#] switch_off

[=] ---------------------------------- Tag Information ----------------------------------
[+]               UID: 08 E2 38 F6 12 53 42 
[+]      Batch number: BB 27 CB 35 08 
[+]   Production date: week 01 / 2005

[=] --- Hardware Information
[=]    raw: 04010100011A05
[=]      Vendor Id: NXP Semiconductors Germany
[=]           Type: 0x01
[=]        Subtype: 0x01
[=]        Version: 0.1 ( DESFire MF3ICD40 )
[=]   Storage size: 0x1A ( 8192 bytes )
[=]       Protocol: 0x05 ( ISO 14443-2, 14443-3 )

[=] --- Software Information
[=]    raw: 04010100011805
[=]      Vendor Id: NXP Semiconductors Germany
[=]           Type: 0x01
[=]        Subtype: 0x01
[=]        Version: 0.1
[=]   Storage size: 0x18 ( 4096 bytes )
[=]       Protocol: 0x05 ( ISO 14443-3, 14443-4 )

[=] --------------------------------- Card capabilities ---------------------------------
[#] error DESFIRESendRaw Current configuration/status does not allow the requested command
[#] error DESFIRESendRaw Unknown error
[#] error DESFIRESendRaw Current configuration/status does not allow the requested command
[#] error DESFIRESendApdu Command code not supported
[#] error DESFIRESendApdu Command code not supported
[+] ------------------------------------ PICC level -------------------------------------
[+] Applications count: 0 free memory n/a
[+] PICC level auth commands: 
[+]    Auth.............. YES
[+]    Auth ISO.......... YES
[+]    Auth AES.......... YES
[+]    Auth Ev2.......... NO
[+]    Auth ISO Native... NO
[+]    Auth LRP.......... NO

[=] --- Free memory
[+]    Card doesn't support 'free mem' cmd
```

#### ISODES authentication with the PICC and PICC master key

```bash
[usb] pm3 --> hf mfdes auth -n 0 -t 3tdea -k 000000000000000000000000000000000000000000000000 -v -c native -a
[=] Key num: 0 Key algo: 3tdea Key[24]: 00 00 00 00 00 00 00 00 00 00 00 00 00 00 00 00 00 00 00 00 00 00 00 00 
[=] Secure channel: n/a Command set: native Communication mode: plain
[+] Setting ISODEP -> inactive
[+] Setting ISODEP -> NFC-A
[=] AID 000000 is selected
[=] Auth: cmd: 0x1a keynum: 0x00
[+] raw>> 1A 00 
[+] raw<< AF EE 91 30 1E E8 F5 84 D6 C7 85 1D 05 65 13 90 A6 C6 D5 
[#] encRndB: EE 91 30 1E E8 F5 84 D6 
[#] RndB: CA FE BA BE 00 11 22 33 
[#] rotRndB: FE BA BE 00 11 22 33 CA FE BA BE 00 11 22 33 CA 
[#] Both   : 01 02 03 04 05 06 07 08 09 10 11 12 13 14 15 16 FE BA BE 00 11 22 33 CA FE BA BE 00 11 22 33 CA 
[+] raw>> AF 30 EB 55 F3 29 39 04 96 77 88 CE EF 33 A3 C8 7B 18 66 1A F1 62 78 A0 28 53 84 67 98 7C BB DB 03 
[+] raw<< 00 9B 71 57 8F FB DF 80 A8 F6 EF 33 4A C6 CD F9 7A 7D BE 
[=] Session key : 01 02 03 04 CA FE BA BE 07 08 09 10 22 33 CA FE 13 14 15 16 00 11 22 33 
[=] Desfire  authenticated
[+] PICC selected and authenticated succesfully
[+] Context: 
[=] Key num: 0 Key algo: 3tdea Key[24]: 00 00 00 00 00 00 00 00 00 00 00 00 00 00 00 00 00 00 00 00 00 00 00 00 
[=] Secure channel: ev1 Command set: native Communication mode: plain
[=] Session key [24]: 01 02 03 04 CA FE BA BE 07 08 09 10 22 33 CA FE 13 14 15 16 00 11 22 33  
[=]     IV [8]: 00 00 00 00 00 00 00 00 
[+] Setting ISODEP -> inactive
```

#### AES (128-bit) authentication with the PICC and PICC master key

```bash
[usb] pm3 --> hf mfdes auth -n 0 -t aes -k 00000000000000000000000000000000 -v -c native -a
[=] Key num: 0 Key algo: aes Key[16]: 00 00 00 00 00 00 00 00 00 00 00 00 00 00 00 00 
[=] Secure channel: n/a Command set: native Communication mode: plain
[+] Setting ISODEP -> inactive
[+] Setting ISODEP -> NFC-A
[=] AID 000000 is selected
[=] Auth: cmd: 0xaa keynum: 0x00
[+] raw>> AA 00 
[+] raw<< AF EA 8C 8F 55 42 BB 7B 81 7C 26 44 EC EC 73 85 AB 8B AF 
[#] encRndB: EA 8C 8F 55 42 BB 7B 81 
[#] RndB: CA FE BA BE 00 11 22 33 
[#] rotRndB: FE BA BE 00 11 22 33 CA FE BA BE 00 11 22 33 CA 
[#] Both   : 01 02 03 04 05 06 07 08 09 10 11 12 13 14 15 16 FE BA BE 00 11 22 33 CA FE BA BE 00 11 22 33 CA 
[+] raw>> AF 04 25 9E 8B C4 49 26 DD 5D 9F 1E 84 1F 2F 13 E4 F1 BD 8E 58 72 AD A6 29 D3 CC 93 91 52 99 BC 71 
[+] raw<< 00 59 2D 75 D8 BE 6A 4B C1 25 E9 9D 95 D4 B1 B0 D2 D1 5D 
[=] Session key : 01 02 03 04 CA FE BA BE 13 14 15 16 00 11 22 33 
[=] Desfire  authenticated
[+] PICC selected and authenticated succesfully
[+] Context: 
[=] Key num: 0 Key algo: aes Key[16]: 00 00 00 00 00 00 00 00 00 00 00 00 00 00 00 00 
[=] Secure channel: ev1 Command set: native Communication mode: plain
[=] Session key [16]: 01 02 03 04 CA FE BA BE 13 14 15 16 00 11 22 33  
[=]     IV [16]: 00 00 00 00 00 00 00 00 00 00 00 00 00 00 00 00 
[+] Setting ISODEP -> inactive
```

### Compatibility with external USB readers and LibNFC

The DESFire configurations are known to work with the anticollision and RATS handshaking utility ``nfc-anticol`` 
from [LibNFC](https://github.com/nfc-tools/libnfc). The following is the output of this utility using the 
ACS ACR-122U reader over USB (with the ``pcscd`` dameon not running):
```bash
$ sudo nfc-anticol -f
NFC reader: ACS / ACR122U PICC Interface opened

Sent bits:     26 (7 bits)
Received bits: 04  03  
Sent bits:     93  20  
Received bits: 88  08  c7  df  98  
Sent bits:     93  70  88  08  c7  df  98  9c  ae  
Received bits: 24  d8  36  
Sent bits:     95  20  
Received bits: f1  02  fc  6c  63  
Sent bits:     95  70  f1  02  fc  6c  63  3a  98  
Received bits: 20  fc  70  
Sent bits:     e0  50  bc  a5  
Received bits: 06  75  00  81  02  80  66  fd  
Sent bits:     50  00  57  cd  
Received bits: 50  00  57  cd  

Found tag with
 UID: 08c7dff102fc6c
ATQA: 0304
 SAK: 20
 ATS: 06  75  00  81  02  80  66  fd
```
The DESFire support for the Chameleon Mini is tested with the LibNFC-based source code 
[developed in this directory](https://github.com/emsec/ChameleonMini/tree/master/Software/DESFireLibNFCTesting) with 
[sample dumps and output here](https://github.com/emsec/ChameleonMini/tree/master/Software/DESFireLibNFCTesting/SampleOutputDumps).
The Mifare DESFire commands installed by [LibFreefare](https://github.com/nfc-tools/libfreefare) 
do not work with the Chameleon Mini. 

The developers are actively working to ensure compatibility of the Chameleon DESFire emulation with external USB readers used 
running ``pcscd`` and ``pcsc_spy``. This support does not work with the HID Omnikey 5022CL reader. 
The ACS ACR-122U reader recognizes the Chameleon running the vanilla ``CONFIG=MF_DESFIRE`` over PCSC (driver ``pcscd``) 
as shown in the output of the ``pcsc_spy -v`` command:
```bash
$ sudo pcsc_scan -v
Using reader plug'n play mechanism
Scanning present readers...
Waiting for the first reader...found one
Scanning present readers...
0: ACS ACR122U PICC Interface 00 00
 
Mon Jul 25 19:26:28 2022
 Reader 0: ACS ACR122U PICC Interface 00 00
  Event number: 3
  Card state: Card removed, 
   
Mon Jul 25 19:26:37 2022
 Reader 0: ACS ACR122U PICC Interface 00 00
  Event number: 4
  Card state: Card inserted, 
  ATR: 3B 81 80 01 80 80

ATR: 3B 81 80 01 80 80
+ TS = 3B --> Direct Convention
+ T0 = 81, Y(1): 1000, K: 1 (historical bytes)
  TD(1) = 80 --> Y(i+1) = 1000, Protocol T = 0 
-----
  TD(2) = 01 --> Y(i+1) = 0000, Protocol T = 1 
-----
+ Historical bytes: 80
  Category indicator byte: 80 (compact TLV data object)
+ TCK = 80 (correct checksum)

Possibly identified card (using /usr/share/pcsc/smartcard_list.txt):
3B 81 80 01 80 80
	RFID - ISO 14443 Type A - NXP DESFire or DESFire EV1 or EV2
	"Reiner LoginCard" (or "OWOK", how they name it) - they have been distributed by a german computer magazine ("Computer BILD")
	https://cardlogin.reiner-sct.com/
	Belgium A-kaart (Antwerp citycard)
	Oyster card - Transport for London (second-gen "D")
	https://en.wikipedia.org/wiki/Oyster_card
	Kaba Legic Advant 4k
	Sydney Opal card public transport ticket (Transport)
	https://www.opal.com.au
	TH Köln (University of Applied Sciences Cologne) - Student Identity Card
	https://www.th-koeln.de/en/academics/multica_5893.php
	German red cross blood donation service
	http://www.blutspende-nordost.de/
	Greater Toronto/Hamilton/Ottawa PRESTO contactless fare card
	http://en.wikipedia.org/wiki/Presto_card
	Electic vehicle charging card of the EMSP EnBW Energie Baden-Württemberg AG, Tarif ADAC e-Charge, Germany
   
Mon Jul 25 19:26:37 2022
 Reader 0: ACS ACR122U PICC Interface 00 00
  Event number: 5
  Card state: Card removed, 
```

## Credits 

### Direct funding sources for this project

The author would like to thank the following direct sources of funding and support
for development of this project:
* Professor [Josephine Yu](http://people.math.gatech.edu/~jyu67/) and the
  [School of Mathematics](https://math.gatech.edu) at the
  Georgia Institute of Technology for allowing me to work on this as a secondary
  project as a Ph.D. candidate over the Summer and Fall of 2020. 
* More work to improve and add compatibility with the PM3 devices over the Spring of 2022 was supported by
  Georgia Tech to work as a RA through the university COVID-19 relief funding.
* The [KAOS manufacturers](https://shop.kasper.it) for providing support in the form of discounted Chameleon RevG
  devices to support my active development on the project.

### Sources of external code and open information about the DESFire specs

The project began based on a few open source Java-based emulation projects (Android based) and the 
prior initial work to add this support on the Chameleon Mini by **@dev-zzo**. 
The starting point of the current firmware code for this project was compiled from 
[this firmware mod fork](https://github.com/dev-zzo/ChameleonMini/tree/desfire) as 
were the known instruction (command) and status codes from the 
[Android HCE (Java based code)](https://github.com/jekkos/android-hce-desfire) 
repository maintained by **@jekkos**. 
After that point, **@maxieds** reorganized and began work modifying and debugging the 
compiled source base in [this repository](https://github.com/maxieds/ChameleonMiniDESFireStack). 
Most of the preliminary testing of these firmware mods was done using the 
[Chameleon Mini Live Debugger](https://github.com/maxieds/ChameleonMiniLiveDebugger) 
Android logger application, and with ``libnfc`` via a 
USB NFC tag reader (host-based testing code is 
[available here](https://github.com/maxieds/ChameleonMiniDESFireStack/tree/master/Firmware/Chameleon-Mini/Application/DESFire/Testing)). 

The source code for much of this implementation has been directly adapted, or modified, from mostly Java
language open source code for Android using several primary sources. Where possible, the license and credits
for the original sources for this ``avr-gcc``-compatible C language code are as specified in the next
repositories and code bases:
* [Prior DESFire Chameleon Mini Firmware Sourced (dev-zzo)](https://github.com/dev-zzo/ChameleonMini)
* [Android DESFire Host Card Emulation / HCE (jekkos)](https://github.com/jekkos/android-hce-desfire)
* [Android HCE Framework Library (kevinvalk)](https://github.com/kevinvalk/android-hce-framework)
* [AVRCryptoLib in C](https://github.com/cantora/avr-crypto-lib)
* [LibFreefare DESFire Code (mostly as a reference and check point)](https://github.com/nfc-tools/libfreefare/tree/master/libfreefare)

### Links to public datasheets and online specs 

The following links are the original online resource links are
archived here for documentation on how this firmware operates:
* [ISO/IEC 7816-4 Standard](http://www.unsads.com/specs/ISO/7816/ISO7816-4.pdf)
* [DESFire Functional specification (MF3ICD81, November 2008)](https://web.archive.org/web/20201115030854/https://marvin.blogreen.org/~romain/nfc/MF3ICD81%20-%20MIFARE%20DESFire%20-%20Functional%20specification%20-%20Rev.%203.5%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)
* [DESFire EV0 Datasheet (M075031, April 2004)](https://web.archive.org/web/20170201031920/http://neteril.org/files/M075031_desfire.pdf)
* [NXP Application Note AN12343](https://www.nxp.com/docs/en/application-note/AN12343.pdf) 
* [TI DESFire EV1 Tag AES Auth Specs (sloa213.pdf)](https://www.ti.com/lit/an/sloa213/sloa213.pdf)
* [NXP Application Note AN10833](https://www.nxp.com/docs/en/application-note/AN10833.pdf)
* My favorite conference submission in grad school is (by far) about this project -- even though I did not present my talk that year.
  In rare form, the [presentation slides (tentative; see uploads)](https://archive.org/details/@maxiedschmidt) and the 
  [accepted manuscript](https://archive.org/download/ftc2021-presentation-slides-with-notes/schmidt-ftc2021-submission.pdf) 
  (published in print form by Springer) document the scarce details of the DESFire spec and command sets gleaned while working 
  on this project as a conference proceedings article.
  Grace Hopper would have approved :)

## New development sources of DESFire support for the Chameleon Mini

David Oswald has added a [DESFire emulation project](https://github.com/orgs/emsec/projects?type=classic) to organize tasks in 
progress for DESFire emulation support on the Chameleon Mini. The 
[original development sources](https://github.com/maxieds/ChameleonMiniDESFireStack/releases) are now archived and 
not kept up to date with the latest firmware pull requests and development sources. There are development sources for pull request projects in 
progress written by **@maxieds** are [located here](https://github.com/maxieds/ChameleonMini). 
For example, a newer branch can be built by running
```bash
$ git clone https://github.com/maxieds/ChameleonMini.git
$ cd ChameleonMini
$ git checkout DESFireNFCExternalUSBReaderPatches-LibNFCTestCode
$ cd Firmware/ChameleonMini
$ make desfire-dev
```
Other GitHub users are developing modifications of the main firmware sources for projects that include Mifare DESFire Plus support elsewhere.

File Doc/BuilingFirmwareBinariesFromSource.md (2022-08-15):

# Building the Chameleon Mini RevG firmware from source

Users that are preparing to reflash their older generation RevE devices should 
see [this software](https://github.com/iceman1001/ChameleonMini-rebooted) 
for the latest sources to compile fresh binaries to flash onto their Chameleon Mini. 
Because the AVR chips on the Chameleon Mini RevE devices have less memory, the configurations 
such as those for 
[DESFire tags](https://github.com/emsec/ChameleonMini/blob/master/Doc/DESFireSupportReadme.md) 
will (most likely) not work if the firmware binaries are built 
using the source code in this repository. 

## Prerequisites

Users need to install ``avr-gcc`` developer packages and GNU ``make`` to compile the sources.
To flash the firmware onto the Chameleon over USB, users will need to install software such as 
``avrdude``. On Linux and Unix systems, users will likely need to setup extra ``udev`` rules on their 
system so the Chameleon Mini is recognized as a USB device in bootloader (flash) and runtime modes. 
Details on this configuration are found on the 
[getting started WIKI](https://rawgit.com/emsec/ChameleonMini/master/Doc/Doxygen/html/_page__getting_started.html).

## Cloning

```bash
$ git clone ttps://@github.com/emsec/ChameleonMini.git
$ cd ChameleonMini/Firmware/ChameleonMini
```
If you are working from an older cloned source, make sure to update to the latest by running 
```bash
$ git pull
```

## Customizing the build

The complexity and memory requirements needed to have all possible 
[configurations](https://rawgit.com/emsec/ChameleonMini/master/Doc/Doxygen/html/_page__configurations.html) 
(list not comprehensive) 
enabled for use on the Chameleon are too demanding for the onboard AVR chip. 
Users will have to choose a subset that includes support for only a few configurations at 
a time (reflash to use firmware built with others). 
There are several custom targets that make building specialized firmware possible. 
They include one of the following strings (henceforth ``BUILD_TARGET``):
```bash
mifare, mifare-classic, desfire, desfire-dev, iso-modes, ntag215, vicinity, sls2s2002, titagit, em4233, misc-tags
```
Precise up-to-date information about which configurations are supported by each build variant are found by reviewing the 
[build script source](https://github.com/emsec/ChameleonMini/blob/master/Firmware/Chameleon-Mini/BuildScripts/custom_build_targets.mk). 
The per-build configuration lists are currently as follows:

* ``mifare``: ``MF_CLASSIC_MINI_4B``, ``MF_CLASSIC_1K``, ``MF_CLASSIC_1K_7B``, ``MF_CLASSIC_4K``, ``MF_CLASSIC_4K_7B`` and ``MF_ULTRALIGHT``
* ``mifare-classic``: ``MF_CLASSIC_MINI_4B``, ``MF_CLASSIC_1K``, ``MF_CLASSIC_1K_7B``, ``MF_CLASSIC_4K`` and ``MF_CLASSIC_4K_7B``
* ``desfire``, ``desfire-dev``: ``MF_DESFIRE``, ``MF_DESFIRE_2KEV1``, ``MF_DESFIRE_4KEV1`` and ``MF_DESFIRE_4KEV2``
* ``iso-modes``: ``ISO14443A_SNIFF``, ``ISO14443A_READER``, ``ISO15693_SNIFF`` and ``MF_ULTRALIGHT``
* ``ntag215``: ``NTAG215``
* ``vicinity``: ``VICINITY``
* ``sl2s2002``: ``SL2S2002``
* ``titagit``: ``TITAGITSTANDARD`` and ``TITAGITPLUS``
* ``em4233``: ``EM4233``
* ``misc-tags``: ``NTAG215``, ``VICINITY``, ``SL2S2002``, ``TITAGITSTANDARD``, ``TITAGITPLUS`` and ``EM4233``

### Choosing prepacakaged firmware binaries

Latest builds supporting ISO14443, ISO1593 and DESFire (non development) are generated automatically on the 
main Chameleon Mini firmware repository 
(see [this listing](https://github.com/emsec/ChameleonMini/actions) and the [active latest firmware builds here](https://github.com/emsec/ChameleonMini/releases)). 

### More customized builds

Users that wish to build a hybrid of any of the above ``make`` targets may edit the 
``Makefile`` in the current working directory (as set in the cloning step above) and set the 
``BUILD_TARGET`` varaible to empty (i.e., build the source by just running ``make`` below). 
*Caveat emptor*: the warning is again that enabling too much functionality in the firmware build may cause 
errors due to memory restrictions. 

## Compiling the source

Build the source by running
```bash
$ make $BUILD_TARGET
```
For example, to build the firmware with DESFire support and extra printing of debugging information that 
can be printed with ``LOGMODE=LIVE`` and viewed with the 
[Chameleon Mini Live Debugger](https://github.com/maxieds/ChameleonMiniLiveDebugger) 
application for Android phones, we run
```bash
$ make desfire-dev
```

## Flashing the firmware 

See the [getting started documentation](https://rawgit.com/emsec/ChameleonMini/master/Doc/Doxygen/html/_page__getting_started.html) 
for more information. The flash command using ``avrdude`` on Linux is the following:
```bash
$ export FIRMWARE_TARGET=Chameleon-Mini
$ sudo avrdude -c flip2 -p ATXMega128A4U -B 60 -P usb -U application:w:$FIRMWARE_TARGET.hex:i -U eeprom:w:$FIRMWARE_TARGET.eep:i
```
More information about flashing Chameleon devices on odd platforms and hardware setups is 
[found here (Linux/Unix)](https://github.com/iceman1001/ChameleonMini-rebooted/wiki/Flashing-Linux-(Unix)) and [here (Mac OSX)](https://github.com/iceman1001/ChameleonMini-rebooted/wiki/Flashing-OSX).

## Getting up and running with the Chameleon Mini over serial USB

Users can install ``minicom`` to interface to the Chameleon Mini. 
Configuration details are OS specific and are found elsewhere. 
Alternately, if users wish to use a portable interface and log viewer on their 
Android device with Google Play Store, see the 
[CMLD application WIKI](https://github.com/maxieds/ChameleonMiniLiveDebugger/wiki/GettingStarted).
Python-based software to download and view the logs on the Chameleon is located 
[in this directory](https://github.com/emsec/ChameleonMini/tree/master/Software/ChamTool). 
Sample dumps for several configuration types that can be uploaded onto the running 
Chameleon device are [located here](https://github.com/emsec/ChameleonMini/tree/master/Dumps).

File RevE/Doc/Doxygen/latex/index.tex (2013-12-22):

Chameleon is a versatile emulator for I\-S\-O 14443 contactless smartcards. It is meant to be a programmable platform to assess security aspects in R\-F\-I\-D environments and can be used in different attack scenarios like replay or relay attacks and even for emulating an existing smartcard, thus behaving as a perfect clone of a given card.

The Chameleon Project has been started by the Chair for Embedded Security at the German University in Bochum and has been licensed as open source to let everyone benefit from the work that has been done so far.

We are always looking forward to any means of contributing or contacting us.

{\itshape Pages\-:}
\begin{DoxyItemize}
\item \hyperlink{Page_GettingStarted}{Getting Started}
\item \hyperlink{Page_CommandLine}{The chameleon command line}
\item \hyperlink{Page_FirmwareUpgrade}{Device Firmware Upgrade (D\-F\-U)}
\item \hyperlink{Page_UploadingDownloading}{Uploading and Downloading Memory dumps} 
\end{DoxyItemize}

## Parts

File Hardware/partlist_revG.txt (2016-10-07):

Partlist

Exported from ChameleonMini-RevG.sch at 07.10.2016 23:09:59

EAGLE Version 6.6.0 Copyright (c) 1988-2014 CadSoft

Assembly variant: 

Part     Value            Device                  Package             Library                    Sheet

B+       TPTP18SQ         TPTP18SQ                TP18SQ              testpad                    1
B-       TPTP18SQ         TPTP18SQ                TP18SQ              testpad                    1
BAT1     3002             3002                    BATTCON_20MM        Keystone-3002              1
C1       10n              C-EUC1206K              C1206K              rcl                        1
C2       10n              C-EUC1206K              C1206K              rcl                        1
C3       4u7              C-EUC0603K              C0603K              rcl                        1
C4       4u7/10V/X5R      C-EUC0603K              C0603K              rcl                        1
C5       10n              C-EUC0603K              C0603K              rcl                        1
C6       22p              C-EUC0603K              C0603K              rcl                        1
C7       22p              C-EUC0603K              C0603K              rcl                        1
C8       4u7              C-EUC0603K              C0603K              rcl                        1
C9       4u7              C-EUC0603K              C0603K              rcl                        1
C10      100n             C-EUC0603K              C0603K              rcl                        1
C11      150p             C-EUC0603K              C0603K              rcl                        2
C12      100n             C-EUC0603K              C0603K              rcl                        2
C13      100n             C-EUC0603K              C0603K              rcl                        1
C14      100n             C-EUC0603K              C0603K              rcl                        1
C15      100n             C-EUC0603K              C0603K              rcl                        1
C16      100p             C-EUC0603K              C0603K              rcl                        2
C17      100p             C-EUC0603K              C0603K              rcl                        2
C18      100n             C-EUC0603K              C0603K              rcl                        1
C19      100n             C-EUC0603K              C0603K              rcl                        1
C20      150p/NP0         C-EUC0603K              C0603K              rcl                        2
C22      100n             C-EUC0603K              C0603K              rcl                        2
C23      1n               C-EUC0603K              C0603K              rcl                        2
C24      22p              C-EUC0603K              C0603K              rcl                        2
C25      22p              C-EUC0603K              C0603K              rcl                        2
C26      22p              C-EUC0603K              C0603K              rcl                        2
C27      22p              C-EUC0603K              C0603K              rcl                        2
C28      150p             C-EUC0603K              C0603K              rcl                        2
C29      N.M.             C-EUC0603K              C0603K              rcl                        2
C30      N.M.             C-EUC0603K              C0603K              rcl                        2
C31      100n             C-EUC0603K              C0603K              rcl                        2
C32      100n             C-EUC0603K              C0603K              rcl                        2
C33      100n             C-EUC0603K              C0603K              rcl                        1
D1       N.M.             SMAJ                    DO214AC             Suppressor                 2
D2       BAS70-05W        BAS70-05W               SOT323              NXP-Diode                  2
D3       BAS70-05W        BAS70-05W               SOT323              NXP-Diode                  2
D4       BAS70-05W        BAS70-05W               SOT323              NXP-Diode                  2
D5       Schottky         1PS76SB70               SOD323(F)           nxp_60                     2
D8       BAS70-05W        BAS70-05W               SOT323              NXP-Diode                  2
IC1      ATxmega128A4U-AU ATXMEGA_A4-A            TQFP44              _ATxmega                   1
IC2      MCP1700          MCP1702                 SOT23               Microchip-MCP1702          1
IC3      7408             74LVC1G08DCK            SC70-5              74xx-little-de             1
IC4      7486             74AHC1G86DCK            SC70-5              74xx-little-de             1
IC5      MB85RS256        MB85RS                  SO-08               Fujitsu-FRAM               1
IC6      7474             74LVC1G74DC             VSSOP8              74LVC1G74                  2
IC7      7432             74AHC1G32DCK            SC70-5              74xx-little-de             2
IC9      7432             74AHC1G32DCK            SC70-5              74xx-little-de             2
J1       Micro USB        USB-MICROB-2            USB-MICROB-10118194 we-con                     1
L1       33R@100MHz       L-EUL2012C              L2012C              rcl                        1
L2       270n             L-EUL2012C              L2012C              rcl                        2
L3       270n             L-EUL2012C              L2012C              rcl                        2
LBUTTON                   SWITCH_SPST_4_PINSQUARE TACTILE-SWITCH-SMD  SparkFun-Electromechanical 1
LEDGREEN HSMG-C190        LED-0603                CHIPLED-0603        led                        1
LEDRED   HSMS-C190        LED-0603                CHIPLED-0603        led                        1
PE0      PAD              WIREPADSMD1,27-254      SMD1,27-2,54        wirepad                    1
Q1       Si1967DH         BSS84AKS                SOT363              NXP-MOS                    1
Q2       13.56 MHz        TXC7B                   5MMX3.2MM           TXC-Crystal                1
Q3       BSS138           BSS138BKW               SOT323              NXP-MOS                    2
Q4       BC846W           BC84XW                  SOT323              NXP-BJT                    2
Q5       BSS84            BSS84AKW                SOT323              NXP-MOS                    2
Q6       BSS84            BSS84AKW                SOT323              NXP-MOS                    2
Q7       BSS138           BSS138BKW               SOT323              NXP-MOS                    2
Q8       BSS138           BSS138BKW               SOT323              NXP-MOS                    2
R1       10k              R-EU_R0603              R0603               rcl                        1
R2       4k7              R-EU_R0603              R0603               rcl                        1
R3       10k              R-EU_R0603              R0603               rcl                        1
R4       47k              R-EU_R0603              R0603               rcl                        1
R5       1Meg             R-EU_R0603              R0603               rcl                        1
R6       3R3              R-EU_R0603              R0603               rcl                        2
R7       3R3              R-EU_R0603              R0603               rcl                        2
R8       100k             R-EU_R0603              R0603               rcl                        2
R9       47k              R-EU_R0603              R0603               rcl                        2
R10      1k               R-EU_R0603              R0603               rcl                        2
R11      10k              R-EU_R0603              R0603               rcl                        2
R12      100k             R-EU_R0603              R0603               rcl                        1
R13      220R             R-EU_R0603              R0603               rcl                        1
R14      220R             R-EU_R0603              R0603               rcl                        1
R15      0R               R-EU_R0603              R0603               rcl                        2
R16      100k             R-EU_R0603              R0603               rcl                        2
R17      0R               R-EU_R0603              R0603               rcl                        2
R18      0R               R-EU_R0603              R0603               rcl                        2
R19      220R             R-EU_R0603              R0603               rcl                        2
R20      100k             R-EU_R0603              R0603               rcl                        2
R21      6k8              R-EU_R0603              R0603               rcl                        2
R22      220R             R-EU_R0603              R0603               rcl                        2
R23      10k              R-EU_R0603              R0603               rcl                        2
R24      47k              R-EU_R0603              R0603               rcl                        1
R25      47k              R-EU_R0603              R0603               rcl                        2
R26      680R             R-EU_R0603              R0603               rcl                        2
R27      100k             R-EU_R0603              R0603               rcl                        2
R29      0R               R-EU_R0603              R0603               rcl                        2
R30      100k             R-EU_R0603              R0603               rcl                        2
R31      10k              R-EU_R0603              R0603               rcl                        2
RBTN                      SWITCH_SPST_4_PINSQUARE TACTILE-SWITCH-SMD  SparkFun-Electromechanical 1
SW1      AYZ0102AGRLC     AYZ0102AGRLC            AYZ0102AGRLC        C&K-Switch                 1
U1       MCP73832T        MCP73831                SOT23-5             SparkFun                   1
X1       N.M.             PINHD-2X3-2.54-EDGE     PINHD-2X3-2.54-EDGE PINHD                      1
X3       U.FL-R-SMT       U.FL-R-SMT              U.FL-R-SMT          Hirose-UFL                 2

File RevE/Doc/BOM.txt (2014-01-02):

Stückliste exportiert aus D:/Chameleon-Mini/trunk/EAGLE/Chameleon-Mini-RevE-2.sch am 02.01.2014 08:00:53

Menge Wert            Device              Bauteile                                   
1                     PINHD-2X3-2.54-EDGE X2                                         
1     1Meg            R-EU_R1206          R14                                        
2     1k              R-EU_R0603          R2, R9                                     
1     1k              R-EU_R1206          R7                                         
1     4k7             R-EU_R0603          R8                                         
1     10R             R-EU_R0603          R3                                         
4     10k             R-EU_R0603          R1, R6, R12, R27                           
2     10n             C-EUC1206K          C1, C16                                    
1     10u/6.3V/X5R    C-EUC1206K          C3                                         
1     12MHz           TXC7B               Q4                                         
1     22R             R-EU_R1206          R19                                        
2     22p             C-EUC0603K          C7, C8                                     
1     22p/NP0         C-EUC0603K          C6                                         
1     33R@100MHz      L-EUL2012C          L1                                         
1     47k             R-EU_R0603          R11                                        
2     100k            R-EU_R0603          R10, R16                                   
9     100n            C-EUC0603K          C10, C11, C12, C13, C14, C15, C17, C18, C19
1     100n            C-EUC1206K          C5                                         
1     120k            R-EU_R0603          R15                                        
1     200k            R-EU_R0603          R13                                        
5     220R            R-EU_R0603          R4, R17, R18, R28, R29                     
1     220p            C-EUC0603K          C9                                         
1     470R            R-EU_R1206          R5                                         
1     AT45DB081D-SSU  AT45DB041B          IC10                                       
1     ATxmega32A4U-AU ATXMEGA_A4-A        IC2                                        
1     B3U-3000P-B     B3U-3000P-B         SW2                                        
6     BAS70-07S       BAS70-07S           D1, D2, D3, D4, D6, D8                     
1     BC846B          BC846BSMD           Q3                                         
1     BSS138BK        BSS123              Q1                                         
1     BZX384-C2V7     BZX384              D5                                         
1     HSMG-C110       HSMX-C110           LED4                                       
1     HSMS-C110       HSMX-C110           LED2                                       
1     N.M.            C-EUC1206           C4                                         
1     SN74LVC1G08DCK  74LVC1G08DCK        IC1                                        
1     SN74LVC1G74DCU  74LVC1G74DC         IC3                                        
1     SN74LVC1G86DCK  74AHC1G86DCK        IC4                                        
1     TLVH431(A)IDBZR TLVH431-SOT23       VR1                                        
1     TZC3P200A110    TZC3P               C2                                         
1     U.FL-R-SMT      U.FL-R-SMT          X3                                         
1     ZX62-B-5PA      ZX62-B-5PA-LONG     X1

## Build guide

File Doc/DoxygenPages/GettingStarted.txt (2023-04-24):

/** @file */

/** @page Page_GettingStarted Getting Started
 *
 * Finally, you hold your brand-new ChameleonMini RevG in your hands! What to do now?!
 * In the factory, a test firmware including a USB bootloader has been programmed into the microcontroller of the Chameleon. This page describes the next steps in order to upload the current firmware, as developed in this project, via the USB bootloader. After having done that, you may want to have a look at the \ref Page_CommandLine page or explore the [Chameleon Android App](https://play.google.com/store/apps/details?id=com.maxieds.chameleonminilivedebugger), which is an external contribution to this project. Development and maintenance can be found [here](https://github.com/maxieds/ChameleonMiniLiveDebugger) (please also ask questions regarding the app there).
 *
 * Step 1: Trigger the USB Bootloader
 * =================================
 * The bootloader can be executed in two different ways:
 * -# Make sure the Chameleon is switched off (power switch on the side is in the position `OFF`). Now, hold down the right button (RBUTTON) and keep it pressed while connecting the Chameleon to a PC via a USB cable.
 * -# OR: Plug your Chameleon via USB to a PC and use your favorite terminal application to connect with the test firmware of the ChameleonMini. Type `upgrade` and hit Enter.
 *
 *
 * In either way, the ChameleonMini now jumps to the bootloader and waits patiently for a firmware upgrade.
 *
 *
 * Step 2: Upgrade the Firmware
 * ===========================
 * Once the ChameleonMini is in the bootloader, you can flash a new firmware, i.e., the files Chameleon-Mini.hex and the Chameleon-Mini.eep, into the microcontroller. The [release page](https://github.com/emsec/ChameleonMini/releases) contains these files precompiled but you can of course also compile the code yourself. Create a new folder and copy the two files into it. The following depends on your operating system:
 *
 * ## Upgrade Procedure for Linux Users ##
 * In order to upgrade the firmware under Linux you first have to install `avrdude`, e.g. under Ubuntu with the command `sudo apt-get install avra avrdude`. Then change to the directory where you have saved the hex and eep files and run `sudo avrdude -c flip2 -p ATXMega128A4U -B 60 -P usb -U application:w:Chameleon-Mini.hex:i -U eeprom:w:Chameleon-Mini.eep:i`.
 *
 * You also can use `sudo make program` in the source code directory, which basically does the same.
 *
 * After running this command you need to restart your Chameleon, e.g. by reattaching the Chameleon to the PC.
 *
 * \note If you are using Ubuntu 14.04, avrdude may not support flip2. In this case, you can run `add-apt-repository ppa:pmjdebruijn/avrdude-release`, then `apt-get update` and finally `apt-get install avrdude` to upgrade to a version of avrdude that supports flip2.
 *
 * Optionally copy [Drivers/98-ChameleonMini.rules](https://cdn.statically.io/gh/emsec/ChameleonMini/master/Drivers/98-ChameleonMini.rules) to /etc/udev/rules.d/, to allow non-root users to open the chameleon serial port at /dev/chameleon.
 * `sudo cp (Path to Chameleon Repo)/Drivers/98-ChameleonMini.rules /etc/udev/rules.d/`
 * Remember to restart the udev daemon, or reboot to activate the rule.
 * 'sudo udevadm control --reload'
 *
 * ## Upgrade Procedure for Mac OS Users ##
 * When running [Homebrew](https://brew.sh) you can install avrdude with `brew install avrdude`. After this, change to the directory where you have saved the hex and eep files and run `sudo avrdude -c flip2 -p ATXMega128A4U -B 60 -P usb -U application:w:Chameleon-Mini.hex:i -U eeprom:w:Chameleon-Mini.eep:i`.
 *
 * ## Upgrade Procedure for Windows Users ##
 * For upgrading the firmware under Windows please
 * -# download https://github.com/emsec/ChameleonMini/raw/master/Doc/DoxygenPages/dfu-programmer-win-0.7.2.zip and extract to an arbitrary directory. Make sure to use the DFU programmer Version 0.7.2!
 * -# Go to the extraction directory and then open the folder `dfu-prog-usb-1.2.2`. Install the `atmel_usb_dfu.inf` driver (right click -> install).
 * -# Copy `dfu-programmer.exe` from the extraction directory to the directory where you have saved the hex and eep files.
 * -# Save the [ChameleonFirmwareUpgrade.bat](https://cdn.statically.io/gh/emsec/ChameleonMini/master/Firmware/Chameleon-Mini/ChameleonFirmwareUpgrade.bat) in the same directory as the hex and eep files.
 * -# Run the `ChameleonFirmwareUpgrade.bat` as Administrator (right click -> run as Administrator) and wait for the firmware upgrade to terminate. Upon success, the green LED of the ChameleonMini should light up.
 *
 * Finally, install the driver for Chameleon:
 * Download both [ChameleonDriver.inf](https://cdn.statically.io/gh/emsec/ChameleonMini/master/Drivers/ChameleonDriver.inf) and [ChameleonDriver.cat](https://cdn.statically.io/gh/emsec/ChameleonMini/master/Drivers/ChameleonDriver.cat) from the Drivers directory and install the INF file (right click -> install). \note If you have problems with the driver installation, try the instructions in [sections 6.2.1 and 6.2.2 from this Atmel document](http://www.atmel.com/images/doc8429.pdf).
 *
 * Now, Chameleon should appear in the Windows device manager and you should be able to open a terminal program such as TeraTerm and connect to the Chameleon-Mini via the COM port shown in the device manager. On Mac or Linux you can use screen (`screen /dev/tty.usbmodem1421`, please replace your device path with the appropriate one) to communicate with your Chameleon. Further information about how to "talk" to the Chameleon can be found here: \ref Page_CommandLine.
 */

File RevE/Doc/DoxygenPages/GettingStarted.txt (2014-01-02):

/** @file */

/** @page Page_GettingStarted Getting Started
 * The first thing you should do is to program the fuse bits and the bootloader 
 * to the Chameleon-Mini.
 * Use your preferred tool to set the fuse bits as follows:
 * 
 * - FUSE1: 0x00
 * - FUSE2: 0xBE
 * - FUSE4: 0xFF
 * - FUSE5: 0xE9
 * 
 * Next, program the appropriate bootloader from the Firmware/Bootloader directory into the chip.
 * The ATxmega chip now automatically enumerates with its DFU bootloader. 
 * Now you can use Atmel's FLIP software or the open source dfu-programmer to program the 
 * Chameleon-Mini.hex/.eep into the FLASH and EEPROM using the bootloader. For this you should
 * follow the instructions of the particular DFU tool.
 * For windows machines, there is an example batch file in the Firmware/Chameleon-Mini directory.
 *
 * Once you have got the Chameleon up and running, it should enumerate as the LUFA CDC device.
 * On windows, you should use the supplied LUFA VirtualSerial.inf in the Drivers folder.
 * When the installation is successful, a new COM port or /dev/ttyS shows up on your system.
 * 
 * This serial port is your means of controlling the Chameleon-Mini from any computer either
 * using a simple terminal emulator, like TeraTerm or your self-crafted scripts and applications.
 *
 * More info on how to use the serial interface can be found here: @ref Page_CommandLine
 *
 */

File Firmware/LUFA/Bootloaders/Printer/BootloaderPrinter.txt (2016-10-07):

/** \file
 *
 *  This file contains special DoxyGen information for the generation of the main page and other special
 *  documentation pages. It is not a project source file.
 */

/** \mainpage Printer Class USB AVR Bootloader
 *
 *  \section Sec_Compat Demo Compatibility:
 *
 *  The following list indicates what microcontrollers are compatible with this demo.
 *
 *  \li Series 7 USB AVRs (AT90USBxxx7)
 *  \li Series 6 USB AVRs (AT90USBxxx6)
 *  \li Series 4 USB AVRs (ATMEGAxxU4)
 *  \li Series 2 USB AVRs (AT90USBxx2, ATMEGAxxU2)
 *
 *  \section Sec_Info USB Information:
 *
 *  The following table gives a rundown of the USB utilization of this demo.
 *
 *  <table>
 *   <tr>
 *    <td><b>USB Mode:</b></td>
 *    <td>Device</td>
 *   </tr>
 *   <tr>
 *    <td><b>USB Class:</b></td>
 *    <td>Printer Class</td>
 *   </tr>
 *   <tr>
 *    <td><b>USB Subclass:</b></td>
 *    <td>Printer Subclass</td>
 *   </tr>
 *   <tr>
 *    <td><b>Relevant Standards:</b></td>
 *    <td>USBIF Printer Class Standard</td>
 *   </tr>
 *   <tr>
 *    <td><b>Supported USB Speeds:</b></td>
 *    <td>Full Speed Mode</td>
 *   </tr>
 *  </table>
 *
 *  \section Sec_Description Project Description:
 *
 *  This bootloader enumerates to the host as a Generic Text Only Printer device, capable of reading and parsing
 *  "printed" plain-text Intel HEX files to load firmware onto the AVR.
 *
 *  Out of the box this bootloader builds for the AT90USB1287 with an 8KB bootloader section size, and will fit
 *  into 4KB of bootloader space. If you wish to alter this size and/or change the AVR model, you will need to
 *  edit the MCU, FLASH_SIZE_KB and BOOT_SECTION_SIZE_KB values in the accompanying makefile.
 *
 *  When the bootloader is running, the board's LED(s) will flash at regular intervals to distinguish the
 *  bootloader from the normal user application.
 *
 *  \section Sec_Running Running the Bootloader
 *
 *  On the USB AVR8 devices, setting the \c HWBE device fuse will cause the bootloader to run if the \c HWB pin of
 *  the AVR is grounded when the device is reset.
 *
 *  The are two behaviours of this bootloader, depending on the device's fuses:
 *
 *  <b>If the device's BOOTRST fuse is set</b>, the bootloader will run any time the system is reset from
 *  the external reset pin, unless no valid user application has been loaded. To initiate the bootloader, the
 *  device's external reset pin should be grounded momentarily.
 *
 *  <b>If the device's BOOTRST fuse is not set</b>, the bootloader will run only if initiated via a software
 *  jump, or if the \c HWB pin was low during the last device reset (if the \c HWBE fuse is set).
 *
 *  For board specific exceptions to the above, see below.
 *
 *  \subsection SSec_XPLAIN Atmel Xplain Board
 *  Ground the USB AVR JTAG's \c TCK pin to ground when powering on the board to start the bootloader. This assumes the
 *  \c HWBE fuse is cleared and the \c BOOTRST fuse is set as the HWBE pin is not user accessible on this board.
 *
 *  \subsection SSec_Leonardo Arduino Leonardo Board
 *  Ground \c IO13 when powering the board to start the bootloader. This assumes the \c HWBE fuse is cleared and the
 *  \c BOOTRST fuse is set as the HWBE pin is not user accessible on this board.
 *
 *  \section Sec_Installation Driver Installation
 *
 *  This bootloader uses the Generic Text-Only printer drivers inbuilt into all modern operating systems, thus no
 *  additional drivers need to be supplied for correct operation.
 *
 *  \section Sec_HostApp Host Controller Application
 *
 *  This bootloader is compatible with Notepad under Windows, and the command line \c lpr utility under Linux.
 *
 *  \subsection SSec_Notepad Notepad (Windows)
 *
 *  While most text applications under Windows will be compatible with the bootloader, the inbuilt Notepad utility
 *  is recommended as it will introduce minimal formatting changes to the output stream. To program with Notepad,
 *  open the target HEX file and print it to the Generic Text Only printer device the bootloader creates.
 *
 *  \subsection SSec_LPR LPR (Linux)
 *
 *  While the CUPS framework under Linux will enumerate the bootloader as a Generic Text-Only printer, many
 *  applications will refuse to print to the device due to the lack of rich formatting options available. As a result,
 *  under Linux HEX files must be printed via the low level \c lpr utility instead.
 *
 *  \code
 *  cat Mouse.hex | lpr
 *  \endcode
 *
 *  \section Sec_API User Application API
 *
 *  Several user application functions for FLASH and other special memory area manipulations are exposed by the bootloader,
 *  allowing the user application to call into the bootloader at runtime to read and write FLASH data.
 *
 *  By default, the bootloader API jump table is located 32 bytes from the end of the device's FLASH memory, and follows the
 *  following layout:
 *
 *  \code
 *  #define BOOTLOADER_API_TABLE_SIZE          32
 *  #define BOOTLOADER_API_TABLE_START         ((FLASHEND + 1UL) - BOOTLOADER_API_TABLE_SIZE)
 *  #define BOOTLOADER_API_CALL(Index)         (void*)((BOOTLOADER_API_TABLE_START + (Index * 2)) / 2)
 *
 *  void    (*BootloaderAPI_ErasePage)(uint32_t Address)               = BOOTLOADER_API_CALL(0);
 *  void    (*BootloaderAPI_WritePage)(uint32_t Address)               = BOOTLOADER_API_CALL(1);
 *  void    (*BootloaderAPI_FillWord)(uint32_t Address, uint16_t Word) = BOOTLOADER_API_CALL(2);
 *  uint8_t (*BootloaderAPI_ReadSignature)(uint16_t Address)           = BOOTLOADER_API_CALL(3);
 *  uint8_t (*BootloaderAPI_ReadFuse)(uint16_t Address)                = BOOTLOADER_API_CALL(4);
 *  uint8_t (*BootloaderAPI_ReadLock)(void)                            = BOOTLOADER_API_CALL(5);
 *  void    (*BootloaderAPI_WriteLock)(uint8_t LockBits)               = BOOTLOADER_API_CALL(6);
 *
 *  #define BOOTLOADER_MAGIC_SIGNATURE_START   (BOOTLOADER_API_TABLE_START + (BOOTLOADER_API_TABLE_SIZE - 2))
 *  #define BOOTLOADER_MAGIC_SIGNATURE         0xDCFB
 *
 *  #define BOOTLOADER_CLASS_SIGNATURE_START   (BOOTLOADER_API_TABLE_START + (BOOTLOADER_API_TABLE_SIZE - 4))
 *  #define BOOTLOADER_PRINTER_SIGNATURE       0xDF20
 *
 *  #define BOOTLOADER_ADDRESS_START           (BOOTLOADER_API_TABLE_START + (BOOTLOADER_API_TABLE_SIZE - 8))
 *  #define BOOTLOADER_ADDRESS_LENGTH          4
 *  \endcode
 *
 *  From the application the API support of the bootloader can be detected by reading the FLASH memory bytes located at address
 *  \c BOOTLOADER_MAGIC_SIGNATURE_START and comparing them to the value \c BOOTLOADER_MAGIC_SIGNATURE. The class of bootloader
 *  can be determined by reading the FLASH memory bytes located at address \c BOOTLOADER_CLASS_SIGNATURE_START and comparing them
 *  to the value \c BOOTLOADER_PRINTER_SIGNATURE. The start address of the bootloader can be retrieved by reading the bytes of FLASH
 *  memory starting from address \c BOOTLOADER_ADDRESS_START.
 *
 *  \subsection SSec_API_MemLayout Device Memory Map
 *  The following illustration indicates the final memory map of the device when loaded with the bootloader.
 *
 *  \verbatim
 *  +----------------------------+ 0x0000
 *  |                            |
 *  |                            |
 *  |                            |
 *  |                            |
 *  |                            |
 *  |                            |
 *  |                            |
 *  |                            |
 *  |      User Application      |
 *  |                            |
 *  |                            |
 *  |                            |
 *  |                            |
 *  |                            |
 *  |                            |
 *  |                            |
 *  +----------------------------+ FLASHEND - BOOT_SECTION_SIZE
 *  |                            |
 *  |   Bootloader Application   |
 *  | (Not User App. Accessible) |
 *  |                            |
 *  +----------------------------+ FLASHEND - 96
 *  |   API Table Trampolines    |
 *  | (Not User App. Accessible) |
 *  +----------------------------+ FLASHEND - 32
 *  |    Bootloader API Table    |
 *  |   (User App. Accessible)   |
 *  +----------------------------+ FLASHEND - 8
 *  |   Bootloader ID Constants  |
 *  |   (User App. Accessible)   |
 *  +----------------------------+ FLASHEND
 *  \endverbatim
 *
 *
 *  \section Sec_KnownIssues Known Issues:
 *
 *  \par On Linux machines, new firmware fails to be sent to the device via CUPS.
 *  Only a limited subset of normal printer functionality is exposed via the
 *  bootloader, causing CUPS to reject print requests from applications that
 *  are unable to handle true plain-text printing. For best results, the low
 *  level \c lpr command should be used to print new firmware to the bootloader.
 *
 *  \section Sec_Options Project Options
 *
 *  The following defines can be found in this demo, which can control the demo behaviour when defined, or changed in value.
 *
 *  <table>
 *   <tr>
 *    <td>
 *     None
 *    </td>
 *   </tr>
 *  </table>
 */

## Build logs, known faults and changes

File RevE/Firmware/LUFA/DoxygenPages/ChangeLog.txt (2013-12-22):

/** \file
 *
 *  This file contains special DoxyGen information for the generation of the main page and other special
 *  documentation pages. It is not a project source file.
 */

 /** \page Page_ChangeLog Project Changelog
  *
  *  \section Sec_ChangeLog130901 Version 130901
  *  <b>New:</b>
  *  - Core:
  *   - Added additional MIDI command definitions to the MIDI class driver (thanks to Daniel Dreibrodt)
  *   - Added new CONCAT() and CONCAT_EXPANDED() convenience macros
  *   - Added new Printer Device Class driver
  *   - Added support for the XMEGA C3 Xplained board
  *   - Added support for the U2S board (thanks to megal0maniac)
  *   - Added TWI Master driver for the XMEGA architecture (thanks to Michael Janssen)
  *  - Library Applications:
  *   - Added new Printer class bootloader
  *   - Added new Mass Storage class bootloader
  *   - Added XMEGA support for class driver device demos (where applicable)
  *   - Added Python host application example for the Generic HID class driver device demo
  *   - Added Python alternative host application for the HID class bootloader
  *
  *  <b>Changed:</b>
  *  - Core:
  *   - Updated the BUILD build system module to produce binary BIN files in addition to Intel HEX files
  *   - Updated the Android Accessory Class to accept version 2 protocol devices (with version 1 functionality)
  *   - All board drivers now implement dummy functions and constants when BOARD is set to NONE
  *   - Added missing LEDs to the XMEGA A3BU Xplained board LED driver (thanks to Michael Janssen)
  *   - Changed board Dataflash drivers to automatically configure the appropriate SPI interface for the selected board
  *  - Library Applications:
  *   - Re-added Set Control Line State request handling to the CDC class bootloader to prevent issues with the .NET serial
  *     class (thanks to Erik Lins)
  *   - TemperatureDataLogger project dummy RTC mode now tracks real time (thanks to David Lazarus)
  *
  *  <b>Fixed:</b>
  *  - Core:
  *   - Fixed Low Speed USB devices broken when using the library HID Class driver (thanks to Michael)
  *   - Fixed possible register corruption in USB Host mode on AVR8 devices when ORDERED_EP_CONFIG is used (thanks to Martin Aakerberg)
  *   - Fixed Pipe_GetBoundEndpointAddress() returning invalid endpoint directions on AVR8 architecture devices (thanks to decerri)
  *     under some circumstances
  *   - Fixed incorrect USB device state set when a suspended LUFA device is woken while addressed but not configured (thanks to Balaji Krishnan)
  *   - Fixed broken USART SPI driver for the AVR8 architecture due to incorrect initialization
  *   - Fixed re-enumeration issue of XMEGA architecture targets (thanks to Jaroslav Jedlinsky)
  *   - Fixed error receiving PIMA events via the Still Image Host class driver
  *  - Library Applications:
  *   - Added handler for SCSI_CMD_START_STOP_UNIT in demos using the Mass Storage class, to prevent ejection errors on *nix systems due to an
  *     unknown SCSI command
  *   - Fixed incorrect HID report descriptor generated for 16-bit axis ranges by the HID_DESCRIPTOR_MOUSE() and HID_DESCRIPTOR_JOYSTICK()
  *     macros (thanks to Armory)
  *   - Fixed incorrect HID report descriptor generated for button multiples of 8 by the HID_DESCRIPTOR_MOUSE() and HID_DESCRIPTOR_JOYSTICK()
  *     macros
  *   - Fixed race condition in the DFU class bootloader causing failed device reprogramming in some circumstances (thanks to Luis Mendes)
  *   - Fixed incorrect time/date configuration data order in the TempDataLogger host application (thanks to David Lazarus)
  *
  *  \section Sec_ChangeLog130303 Version 130303
  *  <b>New:</b>
  *  - Core:
  *   - Added support for the Arduino Leonardo board
  *   - Added support for the Atmel UC3-A3 Xplained board
  *   - Added support for the Xevelabs USB2AX revision 3.1 board
  *   - Added support for the Dimex Stange-ISP board (thanks to Gerhard Wesser)
  *   - Added new \c doxygen_upgrade and \c doxygen_create targets to the DOXYGEN build system module
  *   - Added new Board Hardware Information board driver
  *  - Library Applications:
  *   - Added a different device serial number when the AVRISP-MKII Clone project is in libUSB compatibility mode, so that
  *     both the libUSB and Jungo drivers can be installed at the same time without having to use a filter driver
  *
  *  <b>Changed:</b>
  *  - Core:
  *   - Added workaround for broken VBUS detection on AVR8 devices when a bootloader starts the application
  *     via a software jump without first turning off the OTG pad (thanks to Simon Inns)
  *  - Library Applications:
  *   - Increased throughput in the USBtoSerial project now that data transmission is non-blocking (thanks to Joseph Lacerte)
  *   - Updated bootloader makefiles to remove dependency on the \c bc command line calculator tool
  *   - Updated AVRISP-MKII Clone Programmer project so that the SCK clock period is saved in EEPROM (thanks to Gerhard Wesser)
  *   - Changed all *_SendByte() function prototypes to accept a void pointer for the input buffer (thanks to Simon Kuppers)
  *
  *  <b>Fixed:</b>
  *  - Core:
  *   - Fixed incorrectly issuing STALL response to unsupported control request SETUP packets, rather than in the data/status stage
  *   - Fixed inverted LEDs_GetLEDs() function implementation for the Benito, Minimus and Arduino UNO boards
  *   - Fixed missing Windows 32-bit compatibility sections in the LUFA INF driver files (thanks to Christan Beharrell)
  *   - Fixed logic hole breaking USB operations on a USB controller with only one supported USB mode and no USB_DEVICE_ONLY or USB_HOST_ONLY
  *     configuration token set
  *   - Fixed possible rounding in the VERSION_BCD() macros for some 0.01 step increments (thanks to Oliver Zander)
  *   - Fixed incorrect Dataflash functionality in the USBKEY board if the driver is modified for a single Dataflash chip (thanks to Jonathan Oakley)
  *   - Fixed incorrect definitions of \c HID_KEYBOARD_LED_KANA, \c HID_KEYBOARD_SC_KEYPAD_EQUAL_SIGN and \c HID_KEYBOARD_SC_KEYPAD_EQUAL_SIGN_AS400
  *     and added a missing definition for \c HID_KEYBOARD_SC_APPLICATION (thanks to David Monro)
  *   - Fixed maximum allowed keyboard key code usage of \c 0x65 rather than \c 0xFF for the \c HID_DESCRIPTOR_KEYBOARD() macro (thanks to David Monro)
  *   - Fixed hardware race condition that could cause failed device enumerations for AVR8 and UC3 architectures (thanks to Mike Beyhs)
  *   - Fixed incorrect Minimus board LED definitions (thanks to Joonas Lahtinen)
  *   - Fixed incorrect ordering of the linker options in the build system causing link failures in some cases
  *   - Fixed bug in the TWI peripheral driver for the AVR8 devices causing incorrect failure codes to be returned in some cases (thanks to Peter K)
  *   - Fixed swapped LED3 and LED4 masks for the Olimex-32U4 development board LED driver
  *   - Fixed potential NULL pointer dereference in the HID Host mode Class Driver (thanks to Pavel Kuzmin)
  *  - Library Applications:
  *   - Fixed broken RESET_TOGGLES_LIBUSB_COMPAT compile time option in the AVRISP-MKII project
  *   - Fixed incompatibility in the CDC class bootloader on some systems (thanks to Sylvain Munaut)
  *   - Fixed lengthy timeouts in the USBtoSerial project if no application on the host is consuming data (thanks to Nicolas Saugnier)
  *   - Fixed lengthy automatic data flushing in the CDC and MIDI device class drivers
  *   - Fixed incorrect LED masks for received data display in the Device GenericHID demos (thanks to Denys Berkovskyy)
  *   - Fixed incorrect output in the HIDReportViewer project when no device is connected (thanks to Pavel Kuzmin)
  *
  *  \section Sec_ChangeLog120730 Version 120730
  *  <b>New:</b>
  *  - Core:
  *   - Added new, revamped modular build system with new makefile templates
  *   - Added support for the BitWizard Multio and Big-Multio boards
  *   - Added support for the DorkbotPDX Duce board
  *   - Added support for the Olimex AVR-USB-32U4 board
  *   - Added support for the Olimex AVR-USB-T32U4 board
  *   - Added support for the Olimex AVR-ISP-MK2 board
  *   - Added new Endpoint_ConfigureEndpointTable() function
  *   - Added new Pipe_ConfigurePipeTable() function
  *   - Added build test to verify correct compilation of all board drivers using all driver APIs
  *   - Added build test to verify correct compilation of all bootloaders using all supported devices
  *   - Added build test to verify that there are no detectable errors in the codebase via static analysis
  *   - Added new JTAG_ENABLE() macro for the AVR8 architecture
  *  - Library Applications:
  *   - Modified the CDC Host demos to set a default CDC Line Encoding on enumerated devices
  *   - Added Dataflash operational checks and aborts to all projects using the Dataflash to ensure it is working correctly before use
  *   - Added new SerialToLCD user project contributed by Simon Foster
  *   - Added new RESET_TOGGLES_LIBUSB_COMPAT compile time option to the AVRISP-MKII clone programmer project (thanks to Robert Spitzenpfeil)
  *
  *  <b>Changed:</b>
  *  - Core:
  *   - Android Accessory Host property strings changed from a struct of pointer to an array to prevent unaligned access on greater than 8-bit architectures
  *   - Audio Device Class driver changed to also require the index of the Audio Control interface within the device, for SET/GET/CUR/MIN/MAX/RES property adjustments
  *   - Removed variable axis support from the HID_DESCRIPTOR_JOYSTICK() macro due to OS incompatibilities, replaced with fixed 3-axis joystick report structure
  *   - Removed the old pseudo-scheduler from the library as it was unused and deprecated since the 090810 release
  *   - Endpoint indexes are now specified as full endpoint addresses within the device in device mode, rather than a logical index
  *   - The Endpoint_ConfigureEndpoint() function no longer takes an endpoint direction as a parameter, as this is now deduced from the specified full endpoint
  *     address and type
  *   - The Endpoint_ConfigureEndpoint() function no longer takes a number of banks as a special mask; the number of banks is now specified as an integer parameter
  *   - Endpoints are now configured via instances of a new struct USB_Endpoint_Table_t in all device mode class drivers, rather than a list of endpoint parameters
  *   - Pipe indexes are now specified as full pipe addresses within the host in host mode, rather than a logical index
  *   - The Pipe_ConfigurePipe() function no longer takes an pipe token as a parameter, as this is now deduced from the specified full pipe address and type
  *   - The Pipe_ConfigurePipe() function no longer takes a number of banks as a special mask; the number of banks is now specified as an integer parameter
  *   - Pipes are now configured via instances of a new struct USB_Pipe_Table_t in all host mode class drivers, rather than a list of pipe parameters
  *   - Added support for various assert and debugging macros for the UC3 devices
  *   - Changed MIDI event structure MIDI_EventPacket_t to use a single field for the combined virtual cable index and command ID, to prevent bitfield packing issues
  *     on some architectures (thanks to Darren Gibbs)
  *   - Changed board LED driver implementations of LEDs_ToggleLEDs() for the AVR8 architecture to use the fast PIN register toggle alternative function for speed
  *  - Library Applications:
  *   - Raised the guard bits in the AVRISP-MKII clone project when in PDI and TPI to 32, to prevent communication errors on low quality connections to a target
  *   - Added additional bootloader API data to expose the bootloader start address and class to the DFU and CDC class bootloaders
  *   - Reverted AVRISP-MKII clone project watchdog based command timeout patch in favour of a hardware timer, to allow for use in devices with WDTRST fuse programmed
  *   - The library bootloaders will now correctly start the user application after a watchdog-based application start, even if the /HWB line is held low externally
  *     during the reset phase
  *   - Increased endpoint polling interval for all demos and projects to 5ms, as 1ms was causing some enumeration issues on some machines (thanks to Riku Salminen)
  *
  *  <b>Fixed:</b>
  *  - Core:
  *   - Fixed possible enumeration error if the user application selects a pipe other than the default Control pipe between the Powered and Default states of
  *     the host state machine
  *   - Fixed incorrect call to the user callback CALLBACK_Audio_Device_GetSetInterfaceProperty() in the Audio Class device driver (thanks to Tiit Ratsep)
  *   - Fixed compile error for the UC3 architecture when INTERRUPT_CONTROL_ENDPOINT is specified (thanks to Andrus Aaslaid)
  *   - Fixed compile error if LEDs_Disable() is called and BOARD=NONE is set (thanks to Sam Lin)
  *   - Fixed inverted LED logic in the OLIMEX162 board LED driver
  *   - Fixed incorrect response to GET STATUS requests in device mode if NO_DEVICE_SELF_POWER or NO_DEVICE_REMOTE_WAKEUP tokens are defined (thanks to Georg Glock)
  *   - Fixed inverted LED logic in the USB2AX board LED driver
  *   - Fixed possible deadlock in the CDC device driver if the USB connection is dropped while the CDC_REQ_SetLineEncoding control request is being processed by
  *     the stack (thanks to Jonathan Hudgins)
  *   - Fixed broken MIDI host driver MIDI_Host_ReceiveEventPacket() function due to not unfreezing the MIDI data IN pipe before use (thanks to Michael Brown)
  *   - Fixed swapped Little Endian/Big Endian endpoint and pipe write code for the UC3 devices (thanks to Andrew Chu)
  *   - Fixed the JTAG_DISABLE() macro clearing all other bits in MCUSR when called
  *   - Fixed incorrect Micropendous board LED driver LEDs_SetAllLEDs() and LEDs_ChangeLEDs() function implementations (thanks to MitchJS)
  *   - Fixed endianess issues in the RNDIS host class driver for UC3 devices (thanks to Andrew Chu)
  *  - Library Applications:
  *   - Fixed error in the AVRISP-MKII programmer when ISP mode is used at 64KHz (thanks to Ben R. Porter)
  *   - Fixed AVRISP-MKII programmer project failing to compile for the U4 chips when VTARGET_ADC_CHANNEL is defined to an invalid channel and NO_VTARGET_DETECT is
  *     defined (thanks to Steven Morehouse)
  *   - Fixed AVRISP-MKII programmer project reset line polarity inverted when the generated EEP file is loaded into the USB AVR's EEPROM and avr-dude is used
  *   - Fixed CDC and DFU bootloaders failing to compile when the bootloader section size is 8KB or more (thanks to Georg Glock)
  *   - Fixed CDC and DFU bootloaders API function offsets incorrect on some devices (thanks to Rod DeMay)
  *   - Fixed incorrect DFU version number reported to the host in the  DFU bootloader descriptors (thanks to Georg Glock)
  *   - Fixed incorrect version hundredths value encoding in VERSION_BCD() macro (thanks to Georg Glock)
  *   - Fixed invalid configuration descriptor in the low level KeyboardMouse device demo (thanks to Jun Wako)
  *   - Fixed CDC and DFU bootloaders API page erase and write function failures (thanks to Martin Lambert)
  *
  *  \section Sec_ChangeLog120219 Version 120219
  *  <b>New:</b>
  *  - Core:
  *   - Added support for the XMEGA A3BU Xplained board
  *   - Added support for the new B series XMEGA devices
  *   - Added support for version 2 of the Teensy boards (thanks to Christoph Redecker)
  *   - Added support for the USB2AX boards, hardware revision 1-3
  *   - Added new Android Accessory Host class driver
  *   - Added new USB_Host_GetDescriptor(), USB_Host_GetDeviceConfiguration() and USB_Host_GetInterfaceAltSetting() functions
  *   - Added new CALLBACK_Audio_Device_GetSetInterfaceProperty() callback to the Audio Device Class driver
  *   - Added new LEDs_Disable(), Buttons_Disable() and Joystick_Disable() functions to the board hardware drivers
  *   - Added support for the Micropendous family of boards (Arduino-like revisions 1 and 2, DIP, 32U2, A, 1, 2, 3 and 4)
  *   - Added INVERTED_VBUS_ENABLE_LINE and NO_AUTO_VBUS_MANAGEMENT compile time options (thanks to Opendous Inc.)
  *   - Added support for the Atmel XMEGA B1 Xplained board
  *   - Added Serial USART peripheral driver for the XMEGA architecture
  *   - Added Master Mode SPI USART peripheral driver for the XMEGA and AVR8 architectures
  *   - Added build test to verify correct compilation of as many modules as possible under as many architectures as possible under the C and C++ languages
  *   - Added build test to verify correct compilation of the USB driver when forced into single USB mode under as many architectures as possible
  *  - Library Applications:
  *   - Added User Application APIs to the CDC and DFU class bootloaders
  *   - Added INVERTED_ISP_MISO compile time option to the AVRISP-MKII clone project (thanks to Chuck Rohs)
  *   - Added new Android Accessory Host demo (thanks to Opendous Inc.)
  *
  *  <b>Changed:</b>
  *  - Core:
  *   - When automatic PLL management mode is enabled on the U4 series AVR8 chips, the PLL is now configured for 48MHz and not
  *     a divided 96MHz, to lower power consumption and to keep the system within the datasheet specs for 3.3V operation (thanks to Scott Vitale)
  *   - Added Class, ClassDevice, ClassHost and ClassCommon to the internal class driver source filenames to prevent ambiguities
  *   - Altered the Mass Storage Host class driver so that SCSI data STALLs from the attached device can be recovered from automatically without
  *     having to reset the Mass Storage interface
  *   - USB_CONFIG_ATTR_BUSPOWERED constant renamed to USB_CONFIG_ATTR_RESERVED, as this was misnamed (thanks to NXP Semiconductors)
  *   - Reordered board name definition indexes so that a misspelled BOARD compile option will default to BOARD_USER rather than BOARD_USBKEY
  *   - Altered the HID class driver to only try to construct at maximum one packet per USB frame, to reduce CPU usage
  *   - All USB Class Driver configuration struct values are now non-const, to allow for run-time modifications if required before configuring an instance
  *  - Library Applications:
  *   - Altered the Mass Storage Host LowLevel demo so that SCSI data STALLs from the attached device can be recovered from automatically without
  *     having to reset the Mass Storage interface
  *   - Updated the AVRISP-MKII Clone programmer project to be compatible with the latest version of AVR Studio (version 5.1)
  *   - Changed the AVRISP-MKII Clone programmer project to report a fixed 3.3V VTARGET voltage on USB AVRs lacking an ADC instead of 5V to prevent
  *     warnings in AVR Studio 5.1 when programming XMEGA devices
  *   - Allow serial strings to be generated on the older AVR8 devices which do not explicitly state they contain unique values in the datasheet,
  *     as this appears to be implemented in hardware
  *
  *  <b>Fixed:</b>
  *  - Core:
  *   - Fixed ring buffer size limited to 255 elements, instead of the intended 65535 elements.
  *   - Fixed CDC class drivers not saving and sending all 16-bits of the control line states (thanks to Matthew Swabey)
  *   - Fixed race conditions in the CDC, HID and Mass Storage class drivers when processing some control requests
  *   - Fixed misspelled HID_KEYBOARD_MODIFIER_* macros in the HID class driver (thanks to Laszlo Monda)
  *   - Fixed broken AVR32 endpoint/pipe communications when ORDERED_EP_CONFIG compile time option is not enabled (thanks to Matthias Jahr)
  *   - Fixed broken compilation for the AVR32 devices if the NO_SOF_EVENTS compile time option was not enabled (thanks to Matthias Jahr)
  *   - Fixed compiler warning on GCC with \c -wundef compile flag is used (thanks to Georg Glock)
  *   - Fixed incorrect implementation of LEDs_ToggleLEDs() for the Adafruit-U4 board (thanks to Caroline Saliman)
  *   - Fixed broken compilation of LUFA under C++ compilers when the Serial peripheral module header file is included in a C++ source file
  *   - Fixed missing semicolon in the UC3 architecture host pipe functions
  *   - Fixed failed compilation for the XMEGA architecture if USB_DEVICE_ONLY us not specified
  *   - Fixed UC3 architecture ignoring the pipe size when Pipe_ConfigurePipe() is called
  *  - Library Applications:
  *   - Added reliability patches to the AVRISP-MKII Clone project's PDI/TPI protocols (thanks to Justin Mattair)
  *   - Fixed AVRISP-MKII Clone compile warning on AVR8 U4 targets even when NO_VTARGET_DETECT is enabled
  *   - Fixed AVRISP-MKII Clone failing to start application firmware once a TPI programming session is exited
  *   - Fixed DFU class bootloader not resetting the LED pins as high impedance inputs when a software jump to the user applications is requested
  *   - Fixed AVRISP-MKII Clone timing out on long programming commands such as programming the EEPROM on an ATMEGA8 (thanks to Martin Kelling)
  *   - Fixed invalid PID value used in the TempDataLogger project host application (thanks to Anupam Pathak)
  *
  *  \section Sec_ChangeLog111009 Version 111009
  *  <b>New:</b>
  *  - Core:
  *   - Added USE_LUFA_CONFIG_HEADER compile time option to include a LUFAConfig.h header in the user director for LUFA configuration
  *     tokens as an alternative to tokens defined in the project makefile
  *   - Added new USB_Host_SetInterfaceAltSetting() convenience function for the selection of an interface's alternative setting
  *   - Added Audio class control request definitions
  *   - Added new CALLBACK_Audio_Device_GetSetEndpointProperty() callback to the Audio Device Class driver to allow for endpoint control manipulations
  *     such as data sample rates
  *   - Added support for the Audio class GET STATUS request in the Audio Device Class driver so that it is correctly ACKed when sent by the host
  *   - Added new EVENT_Audio_Device_StreamStartStop() event to the Audio Device Class driver to detect stream start/stop events
  *   - Added board driver support for the Busware TUL board
  *   - Added board hardware driver support for the EVK1100 board
  *   - Added board hardware driver support for the EVK1104 board
  *   - Added new Host mode Audio Class driver
  *   - Added new SPI_GetCurrentMode() function to the SPI peripheral driver
  *   - Added RingBuffer_GetFreeCount() function to the Ring Buffer driver
  *   - Added new HID_Host_SetIdlePeriod() function to the HID Host Class driver
  *   - Added new USB_Host_ConfigurationNumber global variable to indicate the selected configuration in an attached device
  *   - Added new USB_Host_GetDeviceStatus() function to the host standard request function set
  *   - Added AVR USB XMEGA architecture port (currently incomplete/experimental)
  *   - Added new STRINGIFY() and STRINGIFY_EXPANDED() convenience macros
  *   - Added new JTAG_DISABLE() macro for the AVR8 architecture
  *   - Added Device Qualifier standard descriptor structure definitions USB_StdDescriptor_DeviceQualifier_t and USB_Descriptor_DeviceQualifier_t
  *  - Library Applications:
  *   - Added RNDIS device mode to the Webserver project
  *   - Added new incomplete AndroidAccessoryHost Host LowLevel demo
  *   - Added new HIDReportViewer project
  *   - Added new MediaControl project
  *   - Added new AudioInputHost Host ClassDriver demo
  *   - Added new AudioOutputHost Host ClassDriver demo
  *   - Added new AudioInputHost Host LowLevel demo
  *   - Added new AudioOutputHost Host LowLevel demo
  *   - Added new "checksource" target to all library project makefiles
  *   - Added new VTARGET_USE_INTERNAL_REF configuration option to the AVRISP-MKII clone project (thanks to Volker Bosch)
  *
  *  <b>Changed:</b>
  *  - Core:
  *   - Altered the definition of the USB_Audio_Descriptor_Format_t descriptor so that the user is now responsible for supplying
  *     the supported audio sampling rates, to allow for multiple audio interfaces with different numbers of supported rates and/or
  *     continuous sample rates
  *   - Pipe_BoundEndpointNumber() has been renamed to Pipe_GetBoundEndpointAddress(), and now returns the correct endpoint direction
  *     as part of the endpoint address
  *   - Renamed global state variables that are specific to a certain USB mode to clearly indicate which mode the variable relates to,
  *     by changing the USB_* prefix to USB_Device_* or USB_Host_*
  *   - Removed the HOST_STATE_WaitForDeviceRemoval and HOST_STATE_Suspended host state machine states, as these are no longer required
  *   - Altered the USB_Host_SetDeviceConfiguration() function to update the global Host state machine state and the new
  *     USB_Host_ConfigurationNumber global as required
  *   - Added endian correcting code to the library USB class drivers for multiple architecture support
  *   - Removed the ENDPOINT_DESCRIPTOR_DIR_* macros, replaced by ENDPOINT_DIR_* instead
  *   - Renamed the JTAG_DEBUG_ASSERT() macro to JTAG_ASSERT()
  *   - Added variable number of axis to HID_DESCRIPTOR_JOYSTICK() for multi-axis joysticks above just X and Y
  *   - Renamed USB_Host_ClearPipeStall() to USB_Host_ClearEndpointStall() as the function works on an endpoint address within the attached device,
  *     and not a Pipe within the host
  *   - The MS_Host_ResetMSInterface() now performs a full Mass Storage reset sequence to prevent data corruption in the event of a device
  *     lock up or timeout (thanks to David Lyons)
  *   - Added endian-correction to the CDC driver's Line Encoding control request handlers.
  *  - Library Applications:
  *   - Modified the Low Level and Class Driver AudioInput and AudioOutput demos to support multiple audio sample rates
  *   - Updated all host mode demos and projects to use the EVENT_USB_Host_DeviceEnumerationComplete() event callback for device configuration
  *     instead of manual host state machine manipulations in the main application task
  *   - Changed the reports in the GenericHID device demos to control the board LEDs, to reduce user confusion over the callback routines
  *   - Added reliability patches to the AVRISP-MKII Clone project's ISP and PDI/TPI protocols (thanks to Justin Mattair)
  *
  *  <b>Fixed:</b>
  *  - Core:
  *   - Large number of documentation and code comment corrections (thanks to Andrey from Microsin.ru)
  *   - Fixed possibility of the AVR's SPI interface being pulled out of master mode if the /SS pin is a input and pulled low (thanks
  *     to Andrey from Microsin.ru)
  *   - Fixed compile error when FIXED_CONTROL_ENDPOINT_SIZE compile time option was disabled, and a USE_*_DESCRIPTORS compile time
  *     option was not enabled on the AVR8s
  *   - Fixed lack of C++ compatibility in some internal header files causing compile errors when using LUFA in C++ projects
  *   - Fixed error in the pipe unordered allocation algorithm for the AVR8 devices breaking compatibility with some devices
  *   - Fixed USB_USBTask not being called internally in stream transfers between packets when Partial Stream Transfers are used
  *   - Fixed swapped TWI_ADDRESS_READ and TWI_ADDRESS_WRITE values
  *   - Fixed TWI_ReadPacket() not releasing the TWI bus on read completion
  *   - Fixed optimization error in the HID Parser item value USB_SetHIDReportItemInfo() and USB_GetHIDReportItemInfo() routines if the report item was
  *     \c NULL (which should be allowable according to the API)
  *   - Fixed HID Parser CALLBACK_HIDParser_FilterHIDReportItem() callback function not being passed a cacheable report item pointer
  *   - Fixed HID Parser's largest report size bit count not including the size of the last parsed report item
  *   - Fixed HID host driver's largest HID report size count corrupt when the number of report bits exceeds 255
  *  - Library Applications:
  *   - Fixed incorrect signature in the CDC and DFU class bootloaders for the ATMEGA8U2
  *   - Fixed KeyboardHost and KeyboardHostWithParser demos displaying incorrect values when numerical keys were pressed
  *   - Fixed compile errors in the incomplete BluetoothHost demo application (thanks to Timo Lindfors)
  *   - Fixed incorrect Dataflash buffer use in the DataflashManager_WriteBlocks_RAM() function of several demos/projects (thanks to Jeremy Willden)
  *   - Fixed incorrect logging interval (always 500ms longer than requested) in the TempDataLogger project
  *   - Fixed incorrect buffer size check in the USBtoSerial project (thanks to Yuri A Nikiforov)
  *   - Fixed port state table corruption in the TCP layer of the RNDIS Ethernet device demos
  *
  *  \section Sec_ChangeLog110528 Version 110528
  *  <b>New:</b>
  *  - Core:
  *   - Added new ORDERED_EP_CONFIG compile time option to restrict endpoint/pipe configuration to ascending order
  *     in exchange for a smaller compiled program binary size
  *   - Added a new general RingBuff.h miscellaneous ring buffer library driver header
  *   - Added new GCC_FORCE_POINTER_ACCESS() macro to correct GCC's mishandling of struct pointer accesses
  *   - Added new GCC_MEMORY_BARRIER() macro to prevent instruction reordering across boundaries
  *   - Added basic driver example use code to the library documentation
  *   - Added new Endpoint_Null_Stream() and Pipe_Null_Stream() functions
  *   - Added new ADC_GET_CHANNEL_MASK() convenience macro
  *   - Added new HID report item macros (with HID_RI_ prefix) to allow for easy creation and editing of HID report descriptors
  *   - Added new HID_DESCRIPTOR_MOUSE(), HID_DESCRIPTOR_KEYBOARD(), HID_DESCRIPTOR_JOYSTICK() and HID_DESCRIPTOR_VENDOR() macros
  *     for easy automatic creation of basic USB HID device reports
  *   - Added new MAX() and MIN() convenience macros
  *   - Added new Serial_SendData() function to the Serial driver
  *   - Added board driver support for the Sparkfun ATMEGA8U2 breakout board
  *   - Added TWI baud rate prescaler and bit length parameters to the TWI_Init() function (thanks to Thomas Herlinghaus)
  *   - Internal restructuring for eventual multiple architecture ports
  *   - Added AVR32 UC3 architecture port (currently incomplete/experimental)
  *   - Added new architecture independent functions to enable, disable, save and restore the Global Interrupt Enable flags
  *   - Added new RNDIS Device Class Driver packet send and receive functions
  *  - Library Applications:
  *   - Added ability to write protect Mass Storage disk write operations from the host OS
  *   - Added new MIDIToneGenerator project
  *   - Added new KeyboardMouseMultiReport Device ClassDriver demo
  *   - Added new VirtualSerialMassStorage Device ClassDriver demo
  *   - Added HID class bootloader, compatible with a modified version of the command line Teensy loader from PJRC.com
  *   - Added LED flashing to the CDC and DFU class bootloaders to indicate when they are running
  *
  *  <b>Changed:</b>
  *  - Core:
  *   - Unordered Endpoint/Pipe configuration is now allowed once again by default via the previous reconfig workaround
  *   - Refactored Host mode Class Driver *_Host_ConfigurePipes() routines to be more space efficient when compiled
  *   - Added new *_ENUMERROR_PipeConfigurationFailed error codes for the *_Host_ConfigurePipes() routines
  *   - The USARTStream global is now public and documented in the SerialStream module, allowing for the serial USART
  *     stream to be accessed via its handle rather than via the implicit stdout and stdin streams
  *   - The FAST_STREAM_TRANSFERS compile time option has been removed due to lack of use and low cost/benefit ratio
  *   - Altered all endpoint/pipe stream transfers so that the new BytesProcessed parameter now points to a location
  *     where the number of bytes in the transfer that have been completed can be stored (or NULL if entire transaction
  *     should be performed in one chunk)
  *   - The NO_STREAM_CALLBACKS compile time option has now been removed due to the new partial stream transfer feature
  *   - Changed over all project and demo HID report descriptors to use the new HID report item macros
  *   - Moved the HIDParser.c source file to the LUFA/Drivers/USB/Class/Common/ directory from the LUFA/Drivers/USB/Class/Host/
  *   - Added support to the HID parser for extended USAGE items that contain the usage page as well as the usage index
  *   - Removed the SerialStream driver, rolled functionality into the regular Serial peripheral driver via the new
  *     Serial_CreateStream() and Serial_CreateBlockingStream() functions
  *   - Renamed the low level Serial byte send/receive functions, to be consistent with the CDC class driver byte functions
  *   - Altered the behaviour of the serial byte reception function so that is is non-blocking, and now returns a negative
  *     value if no character is received (to remain consistent with the CDC class driver byte reception routines)
  *   - Renamed the PRNT_Host_SendString(), CDC_Host_SendString() and CDC_Device_SendString() functions to *_SendData(), and
  *     added new versions of the *_SendString() routines that expect a null terminated string instead
  *   - Renamed all driver termination *_ShutDown() functions to the more logical name *_Disable()
  *   - Reduced latency for executing the Start-Of-Frame events (if enabled in the user application)
  *   - Removed Pipe_ClearErrorFlags(), pipe error flags are now automatically cleared when Pipe_ClearError() is called
  *   - Endpoint_ResetFIFO() renamed to Endpoint_ResetEndpoint(), to be consistent with the Pipe_ResetPipe() function name
  *   - Implemented on-demand PLL clock generation for the U4, U6 and U7 series USB AVRs when automatic PLL mode is specified
  *   - F_CLOCK changed to F_USB to be more descriptive, and applicable on future architecture ports
  *   - Renamed all low level Endpoint_Read_*, Endpoint_Write_* and Endpoint_Discard_* functions to use the number of bits instead of
  *     a symbolic size (Byte, Word, DWord) so that the function names are applicable and correct across all architectures
  *   - Renamed all low level Pipe_Read_*, Pipe_Write_* and Pipe_Discard_* functions to use the number of bits instead of
  *     a symbolic size (Byte, Word, DWord) so that the function names are applicable and correct across all architectures
  *   - Separated out board drivers by architecture in the library internals for better organisation
  *  - Library Applications:
  *   - Changed the XPLAINBridge software UART to use the regular timer CTC mode instead of the alternative CTC mode
  *     via the Input Capture register, to reduce user confusion
  *   - Combined page and word ISP programming mode code in the AVRISP-MKII clone project to reduce compiled size and
  *     increase maintainability of the code
  *   - Changed over library projects to use the new general ring buffer library driver module
  *   - Added new high level TWI packet read/write commands, altered behaviour of the TWI_StartTransmission() function
  *   - Changed TempDataLogger project's DS1307 driver to simplify the function interface and prevent a possible race condition
  *   - Changed AVRISP-MKII project to use the Watchdog interrupt for command timeouts, to reduce CPU usage and free timer 0
  *     for other uses
  *   - Updated the software USART code in the XPLAIN Bridge application so that the incoming bits are sampled at their mid-point
  *     instead of starting point, to give maximum reliability (thanks to Anton Staaf)
  *
  *  <b>Fixed:</b>
  *  - Core:
  *   - Fixed broken USBFOO board drivers due to missing BOARD_USBFOO define
  *   - Fixed HID host class driver incorrectly binding to HID devices that do not have an OUT endpoint
  *   - Fixed incorrect definition of the HID_KEYBOARD_SC_D constant in the HID class driver (thanks to Opendous Inc.)
  *   - Fixed incorrect definition of the HID_KEYBOARD_SC_RIGHT_ARROW constant in the HID class driver (thanks to Joby Taffey)
  *   - Fixed incorrect endpoint initialisation order in the several device demos (thanks to Rick Drolet)
  *   - Fixed inverted Minimus board LEDs
  *   - Fixed incorrect byte ordering in the Audio_Device_WriteSample24 function (thanks to WZab)
  *   - Fixed several functions in the Host mode Still Image Class driver returning an error code from the incorrect
  *     error code enum (thanks to Daniel Seibert)
  *   - Fixed ReportID not being removed from the feature/out report data array in the HID class driver when Report IDs are used
  *   - Fixed incorrect BUTTONS_BUTTON1 definition for the Minimus board
  *   - Fixed Still Image Host class driver exiting the descriptor search routine prematurely if the data pipes (but not event pipe)
  *     is found
  *   - Fixed missing call to Pipe_SetInfiniteINRequests() in the Pipe_ConfigurePipe() routine
  *   - Fixed Remote Wakeup broken on the AVRs due to the mechanism only operating when the SUSPI bit is set (thanks to Holger Steinhaus)
  *   - Fixed possible invalid program execution when in host mode if corrupt descriptor lengths are supplied by the attached device
  *  - Library Applications:
  *   - Fixed Benito project discarding incoming data from the USB virtual serial port when the USART is busy
  *   - Fixed broken DFU bootloader, added XPLAIN support for bootloader start when XCK jumpered to ground
  *   - Fixed broken HID_REQ_GetReport request handler in the Low Level GenericHID demo
  *   - Fixed possible lost data in the XPLAINBridge, USBtoSerial and Benito projects when the host exceeds the packet
  *     timeout period on received packets as set by USB_STREAM_TIMEOUT_MS (thanks to Justin Rajewski)
  *   - Fixed possible programming problem in the AVRISP-MKII clone project when programming specific patterns into a target
  *     memory space that is only byte (not page) addressable
  *   - Fixed errors in the incomplete Test and Measurement device demo preventing proper operation (thanks to Pavel Plotnikov)
  *   - Fixed programming errors in the AVRISP-MKII project when the programming packet is a round multiple of the endpoint bank
  *     size under avrdude (thanks to Steffan Woltjer)
  *
  *
  *  \section Sec_ChangeLog101122 Version 101122
  *  <b>New:</b>
  *  - Core:
  *    - Added new SCSI_ASENSE_NOT_READY_TO_READY_CHANGE constant to the Mass Storage class driver, to indicate when a previously
  *      not ready removable medium has now become ready for the host's use (thanks to Martin Degelsegger)
  *    - Moved the Pipe and Endpoint stream related code to two new USB library core source files EndpointStream.c and PipeStream.c
  *    - Added new USB_Device_GetFrameNumber() and USB_Host_GetFrameNumber() functions to retrieve the current USB frame number
  *    - Added new USB_Host_EnableSOFEvents(), USB_Host_DisableSOFEvents() and EVENT_USB_Host_StartOfFrame() for the user application
  *      handling of USB Start of Frame events while in USB Host mode
  *    - Added new PRNT_Host_BytesReceived(), PRNT_Host_ReceiveByte(), PRNT_Host_SendByte() and PRNT_Host_Flush() functions to the
  *      Print Host Class driver
  *    - Added class specific descriptor alternative struct type defines with standard USB-IF element naming
  *    - Added new project makefile template to the library and moved board driver stub files into in a new "CodeTemplates" directory
  *    - Added board hardware driver support for the Adafruit U4 breakout board
  *    - Added board hardware driver support for the Arduino Uno development board
  *    - Added board hardware driver support for the Blackcat USB JTAG board (thanks to the PSGroove team)
  *    - Added board hardware driver support for the Busware BUI development board
  *    - Added board hardware driver support for the Busware CUL V3 868MHZ radio board (thanks to Dirk Tostmann)
  *    - Added board hardware driver support for the Kernel Concepts USBFOO development board
  *    - Added board hardware driver support for the Linnix UDIP development board
  *    - Added board hardware driver support for the Olimex AVR-USB-162 development board (thanks to Steve Fawcett)
  *    - Added board hardware driver support for the Maximus board (thanks to the PSGroove team)
  *    - Added board hardware driver support for the Microsin AVR-USB162 breakout board
  *    - Added board hardware driver support for the Minimus board (thanks to the PSGroove team)
  *    - Added new NO_CLASS_DRIVER_AUTOFLUSH compile time option to disable automatic flushing of interfaces when the USB management
  *      tasks for each driver is called
  *    - Added standard keyboard HID report scan-code defines (thanks to Laszlo Monda)
  *    - Added new Pipe_GetBusyBanks(), Endpoint_GetBusyBanks() and Endpoint_AbortPendingIN() functions
  *  - Library Applications:
  *    - Added default test tone generation mode to the Device mode AudioInput demos
  *    - Added new NO_BLOCK_SUPPORT, NO_EEPROM_BYTE_SUPPORT, NO_FLASH_BYTE_SUPPORT and NO_LOCK_BYTE_WRITE_SUPPORT compile time options to the
  *      CDC class bootloader
  *    - Added new XCK_RESCUE_CLOCK_ENABLE compile time option to the AVRISP-MKII clone programmer project (thanks to Tom Light)
  *
  *  <b>Changed:</b>
  *  - Core:
  *    - Removed complicated logic for the Endpoint_ConfigureEndpoint() function to use inlined or function called versions
  *      depending of if the given bank size is a compile time constant, as the compiler does a better job of optimizing
  *      with basic code
  *    - Changed the signature of the CALLBACK_USB_GetDescriptor() callback function so that the descriptor pointer is const, to remove
  *      the need for extra casting inside the callback (thanks to Jonathan Kollasch)
  *    - Reduced HOST_DEVICE_SETTLE_DELAY_MS to 1000ms down from 1500ms to improve device compatibility while in USB Host mode
  *    - Removed the EVENT_USB_InitFailure() event, not specifying a USB mode correctly now defaults to UID selection mode
  *    - Renamed and moved class driver common constant definitions to make the naming scheme more uniform
  *    - Moved the USB mode specifier constants into a new enum, so that they are semantically related to one another
  *    - Renamed ENDPOINT_DOUBLEBANK_SUPPORTED() to ENDPOINT_BANKS_SUPPORTED() and changed it to return the maximum number of supported banks for
  *      the given endpoint
  *    - Better algorithm to extract and convert the internal device serial number into a string descriptor (if present)
  *    - All USB class drivers are now automatically included when LUFA/Drivers/USB.h is included, and no longer need to be separately included
  *    - The MIDI class drivers now automatically flushes the MIDI interface when the MIDI class driver's USBTask() function is called
  *    - Renamed the EVENT_USB_Device_UnhandledControlRequest() event to EVENT_USB_Device_ControlRequest() as it is now fired before the library
  *      request handlers, not afterwards
  *  - Library Applications:
  *    - Changed over all device demos to use a clearer algorithm for the configuring of the application's endpoints
  *    - Added missing DataflashManager_CheckDataflashOperation() function to the MassStorageKeyboard demo, removed redundant
  *      SCSI_Codes.h file as these values are part of the MassStorage Class Driver
  *    - Added compile time error to the AVRISP-MKII project when built for the U4 chips, as the default VTARGET detection ADC channel
  *      does not exist on these chips (thanks to Marco)
  *    - Changed all Device mode LowLevel demos and Device Class drivers so that the control request is acknowledged and any data
  *      transferred as quickly as possible without any processing in between sections, so that long callbacks or event handlers will
  *      not break communications with the host by exceeding the maximum control request stage timeout period
  *    - Changed over all demos, drivers and internal functions to use the current frame number over the Start of Frame flag where possible
  *      to free up the Start of Frame flag for interrupt use in the user application
  *    - All project makefiles now correctly clean intermediate build files from assembly and C++ sources (thanks to Daniel Czigany)
  *    - Changed default value for the reset polarity parameter in the AVRISP-MKII project so that it defaults to active low drive
  *    - Changed configuration descriptor parser for all host mode projects and class drivers to ensure better compatibility with devices
  *    - All LowLevel demos changed to use the constants and types defined in the USB class drivers
  *    - Changed AudioInput and AudioOutput demos to reload the next sample via an interrupt rather than polling the sample timer
  *    - Rescue clock of the AVRISP-MKII moved to the AVR's OCR1A pin, so that the clock can be generated at all times
  *    - Changed ClassDriver MIDI demos to process all incoming events in a loop until the bank becomes empty rather than one at a time
  *    - Changed LowLevel MIDI demos to only clear the incoming event bank once it has become empty to support packed event packets
  *
  *  <b>Fixed:</b>
  *  - Core:
  *    - Fixed USB_GetHIDReportItemInfo() function modifying the given report item's data when the report item does not exist
  *      within the supplied report of a multiple report HID device
  *    - Fixed critical pipe/endpoint memory allocation issue where the bank memory address space could be silently overlapped
  *      in the USB controller if the endpoints or pipes were allocated in anything other than ascending order (thanks to Martin Degelsegger)
  *    - Added LEDs_ToggleLEDs() function to several board LED drivers which were missing it (thanks to Andrei Krainev)
  *    - Fixed SET FEATURE and CLEAR FEATURE control requests directed at an unconfigured endpoint causing request timeouts
  *    - Fixed USB_Host_ClearPipeStall() incorrectly determining the endpoint direction from the currently selected pipe
  *    - Fixed JTAG_DEBUG_POINT() and JTAG_DEBUG_BREAK() macros not compiling under pure C99 standards mode
  *    - Fixed endpoint selection within the CALLBACK_HID_Device_CreateHIDReport() callback function causing broken GET REPORT requests
  *    - Fixed incorrect command name for EEPROM memory programming in the makefile dfu-ee target
  *    - Fixed incorrect LEDs_ChangeLEDs() function in the Benito board LED driver
  *    - Fixed incorrect USB_DeviceState value when unconfiguring the device without an address set
  *    - Fixed SPI driver not explicitly setting /SS and MISO pins as inputs when SPI_Init() is called
  *    - Fixed random enumeration failure while in device mode due to interrupts causing the Set Address request to exceed maximum timings
  *    - Fixed MIDI_Host_Flush() not aborting early when the specified MIDI host interface was not configured
  *    - Fixed MIDI class driver send routines silently discarding packets if the endpoint or pipe is busy (thanks to Robin Green)
  *  - Library Applications:
  *    - Fixed MassStorage based demos and projects resetting the SCSI sense values before the command is executed, leading to
  *      missed SCSI sense values when the host retrieves the sense key (thanks to Martin Degelsegger)
  *    - Fixed USBtoSerial and Benito project SetLineEncoding calls failing if the USART is busy, due to the RX ISR delaying the control
  *      request handler
  *    - Fixed LowLevel PrinterHost demo not sending control requests to the attached printer with the correct printer interface wIndex value
  *    - Fixed incorrect signature reported in the CDC class bootloader for the ATMEGA32U2
  *    - Fixed BootloaderCDC project failing on some operating systems due to removed Line Encoding options (thanks to Alexey Belyaev)
  *    - Fixed broken FLASH/EEPROM programming in the AVRISP-MKII clone project when writing in non-paged mode and the polling byte cannot be used
  *    - Fixed ISR definition conflict in the XPLAIN bridge between the software UART and the AVRISP-MKII ISP modules
  *    - Fixed USBtoSerial and XPLAINBridge demos discarding data from the PC if the send buffer becomes full
  *    - Fixed broken input in the MagStripe reader project due to an incorrect HID report descriptor
  *    - Fixed incorrect PollingIntervalMS values in the demo/project/bootloader endpoint descriptors (thanks to MCS Electronics)
  *    - Fixed AVRISP-MKII clone project not starting the target's program automatically after exiting TPI programming mode
  *
  *
  *  \section Sec_ChangeLog100807 Version 100807
  *  <b>New:</b>
  *  - Added new ADC_DisableChannel() function (thanks to Mich Davis)
  *  - Added new VTARGET_REF_VOLTS and VTARGET_SCALE_FACTOR compile time defines to the AVRISP-MKII programmer project to set
  *    the VTARGET reference voltage and scale factor
  *  - Added new pgm_read_ptr() macro to Common.h for reading of pointers out of flash memory space
  *  - Added new SWAPENDIAN_16() and SWAPENDIAN_32() macros to Common.h for statically initialized variables at compile time
  *  - Added new Drivers/USB/LowLevel/Device.c file to house Device mode specific functions that are more complicated than simple macros
  *  - Added new AVRStudio 4 project files for all library demos, projects and bootloaders
  *  - Added ability to set the serial baud rate via the user's terminal in the XPLAINBridge project
  *  - Added new LUFA module variables for the different source modules in the core library makefile to simplify project makefiles
  *  - Added start of a new Test and Measurement class demo (thanks to Peter Lawrence)
  *  - Added new SPI_ORDER_* data order masks to the SPI peripheral driver
  *  - Added support to the AVRISP-MKII project for ISP speeds slower than 125KHz via a new software SPI driver
  *  - Added support for the new button/LED on the latest model USBTINY-MKII
  *
  *  <b>Changed:</b>
  *  - The RingBuff library code has been replaced in the XPLAINBridge, Benito and USBtoSerial projects with an ultra lightweight
  *    ring buffer to help improve the reliability of the projects
  *  - The EEPROM stream read/write functions now use eeprom_update_byte() instead of eeprom_write_byte(), so that only
  *    changed bytes are written to EEPROM to preserve its lifespan
  *  - Changed over the AVRISP-MKII and TemperatureDataLogger projects to use eeprom_update_byte() when writing non-volatile
  *    parameters to EEPROM to preserve its lifespan
  *  - Removed unused line encoding data and control requests from the CDC Bootloader code, to save space
  *  - Renamed SERIAL_STREAM_ASSERT() macro to STDOUT_ASSERT()
  *  - The USB_Device_IsRemoteWakeupSent() and USB_Device_IsUSBSuspended() macros have been deleted, as they are now obsolete
  *  - Rewrote the implementation of the SwapEndian_16() and SwapEndian_32() functions so that they compile down in most instances to
  *    minimal loads and stores rather than complicated shifts
  *  - The software UART in the XPLAINBridge has been largely altered to try to improve upon its performance and reliability
  *  - The USBtoSerial and Benito projects now flushes received data via a flush timer, so that several bytes can be transmitted at once
  *  - Removed the automated checking of event names in the demo, project and bootloader makefiles due to inconsistencies between the
  *    behaviour of the command line tools used to perform the check on each platform
  *  - Internal USB driver source files renamed and moved to ease future possible architecture ports
  *  - All internal pseudo-function macros have been converted to true inline functions for type-safety and readability
  *  - Changed LED indicator masks for the AVRISP-MKII project, so that there are defined roles for each LED
  *  - Altered the CDC Device and Host Class drivers' receive byte routines, so that no data is indicated by the function returning a
  *    negative value (thanks to Andreas Paulin)
  *  - Added auto flushing of OUT data to the CDC Host Class driver's USBTask function to automatically flush the send pipe buffer
  *
  *  <b>Fixed:</b>
  *  - Fixed AVRISP project sending a LOAD EXTENDED ADDRESS command to 128KB AVRs after programming or reading from
  *    the last page of FLASH (thanks to Gerard Sexton)
  *  - Fixed AVRISP project not sending a full erase-and-write EEPROM command to XMEGA targets when writing to the EEPROM
  *    instead of the split write-only command (thanks to Tim Margush)
  *  - Fixed RNDISEthernet demos crashing when calculating checksums for Ethernet/TCP packets of more than ~500 bytes due to
  *    an overflow in the checksum calculation loop (thanks to Kevin Malec)
  *  - Fixed XPLAINBridge project not correctly reading the XMEGA's supply voltage when reporting back to the host
  *  - Fixed incorrect signature for the ATMEGA32U2 in the DFU bootloader (thanks to Axel Rohde)
  *  - Fixed internal device serial not being accessible on the ATMEGAXXU2 AVRs (thanks to Axel Rohde)
  *  - Fixed void pointer arithmetic in ConfigDescriptor.h breaking C++ compatibility (thanks to Michael Hennebry)
  *  - Fixed broken PDI EEPROM Section Erase functionality in the AVRISP-MKII project
  *  - Fixed USB_Device_SendRemoteWakeup() not working when the USB clock was frozen during USB bus suspend (thanks to Brian Dickman)
  *  - Fixed occasional lockup of the AVRISP project due to the timeout extension code incorrectly extending the timeout in
  *    PDI and TPI programming modes infinitely
  *  - Fixed HID device class driver still using PrevReportINBuffer for GetReport control requests even when it has been
  *    set to NULL by the user application (thanks to Axel Rohde)
  *  - Fixed MIDI_Device_SendEventPacket() not correctly waiting for the endpoint to become ready (thanks to Robin Green)
  *  - Fixed Benito and USBtoSerial projects not turning off the USART before reconfiguring it, which could cause incorrect
  *    operation to occur (thanks to Bob Paddock)
  *  - Fixed Serial peripheral driver not turning off the USART before reconfiguring it, which would cause incorrect operation
  *    to occur (thanks to Bob Paddock)
  *  - Fixed software application start command broken in the DFU class bootloader when dfu-programmer is used due to application
  *    start address corruption
  *
  *
  *  \section Sec_ChangeLog100513 Version 100513
  *  <b>New:</b>
  *  - Added incomplete MIDIToneGenerator project
  *  - Added new Relay Controller Board project (thanks to OBinou)
  *  - Added board hardware driver support for the Teensy, USBTINY MKII, Benito and JM-DB-U2 lines of third party USB AVR boards
  *  - Added new ATTR_NO_INIT variable attribute for global variables that should not be automatically cleared on startup
  *  - Added new ENDPOINT_*_BusSuspended error code to the Endpoint function, so that the stream functions early-abort if the bus
  *    is suspended before or during a transfer
  *  - Added new EVENT_CDC_Device_BreakSent() event and CDC_Host_SendBreak() function to the Device and Host CDC Class drivers
  *  - Added ReportType parameter to the HID device class driver CALLBACK_HID_Device_ProcessHIDReport() function so that FEATURE
  *    reports from the host to the device can be correctly processed
  *  - Added ReportType parameter to the HID host class driver HID_Host_SendReportByID() function so that FEATURE reports can be
  *    issued to the attached device
  *
  *  <b>Changed:</b>
  *  - AVRISP programmer project now has a more robust timeout system
  *  - Added a timeout value to the TWI_StartTransmission() function, within which the addressed device must respond
  *  - Webserver project now uses the board LEDs to indicate the current IP configuration state
  *  - Added ENABLE_TELNET_SERVER compile time option to the Webserver project to disable the TELNET server if desired
  *  - Increased throughput of the USBtoSerial demo on systems that send multiple bytes per packet (thanks to Opendous Inc.)
  *  - Double bank CDC endpoints in the XPLAIN Bridge project, re-enable JTAG once the mode selection pin has been sampled.
  *  - Standardized the naming scheme given to configuration descriptor sub-elements in the Device mode demos, bootloaders
  *    and projects
  *  - All Class Driver Host mode demos now correctly set the board LEDs to READY once the enumeration process has completed
  *  - Added LIBUSB_FILTERDRV_COMPAT compile time option to the AVRISP programmer project to make the code compatible with Windows
  *    builds of avrdude at the expense of AVRStudio compatibility
  *  - Removed two-step endpoint/pipe bank clear and switch sequence for smaller, faster endpoint/pipe code
  *  - The USB_Init() function no longer calls sei() - the user is now responsible for enabling interrupts when they are ready
  *    for them to be enabled (thanks to Andrei Krainev)
  *  - The Audio_Device_IsSampleReceived() and Audio_Device_IsReadyForNextSample() functions are now inline, to reduce overhead
  *  - Removed the cast to uint16_t on the set baud rate in the USBtoSerial project, so that the higher >1M baud rates can be
  *    selected (thanks to Steffan Woltjer)
  *  - Removed software PDI and TPI emulation from the AVRISP-MKII clone project as it was very buggy and slow - PDI and TPI must
  *    now be implemented via separate programming headers
  *  - The CDC class bootloader now uses a watchdog reset rather than a soft-reset when exited to ensure that all hardware is
  *    properly reset to their defaults
  *  - Device mode class driver callbacks are now fired before the control request status stage is sent to prevent the host from
  *    timing out if another request is immediately fired and the device has a lengthy callback routine
  *  - The TeensyHID bootloader has been removed, per request from Paul at PJRC
  *  - The LIBUSB_FILTERDRV_COMPAT compile time option in the XPLAINBridge and AVRISP-MKII projects has been renamed
  *    LIBUSB_DRIVER_COMPAT, as it applies to all software on all platforms using the libUSB driver
  *
  *  <b>Fixed:</b>
  *  - Fixed possible device lockup when INTERRUPT_CONTROL_ENDPOINT is enabled and the control endpoint is not properly
  *    selected when the ISR completes
  *  - Fixed AVRISP-MKII clone project not correctly issuing LOAD EXTENDED ADDRESS commands when the extended address
  *    boundary is crossed during programming or read back (thanks to Gerard Sexton)
  *  - Fixed warnings when building the AVRISP-MKII clone project with the ENABLE_XPROG_PROTOCOL compile time option disabled
  *  - Fixed software PDI/TPI programming mode in the AVRISP project not correctly toggling just the clock pin
  *  - Fixed TWI_StartTransmission() corrupting the contents of the GPIOR0 register
  *  - Fixed TWI driver not aborting when faced with no response after attempting to address a device on the bus
  *  - Fixed ADC routines not correctly returning the last result when multiple channels were read
  *  - Fixed ADC routines failing to read the extended channels (Channels 8 to 13, Internal Temperature Sensor) on the
  *    U4 series USB AVR parts
  *  - Fixed LowLevel MassStorage demo broken on the U2 series USB AVRs due to unsupported double-banked endpoint modes used
  *  - Fixed compilation error in the AudioInput demos when MICROPHONE_BIASED_TO_HALF_RAIL is defined (thanks to C. Scott Ananian)
  *  - Fixed incorrect definition of HID_ALIGN_DATA() causing incorrect HID report item data alignment
  *  - Fixed Still Image Host class driver not resetting the transaction ID when a new session is opened, fixed driver not sending
  *    a valid session ID to the device
  *  - Removed invalid dfu and flip related targets from the bootloaders - bootloaders can only be replaced with an external programmer
  *  - Fixed Set/Clear Feature requests directed to a non-configured endpoint not returning a stall to the host
  *  - Fixed HID Device Class Driver not allocating a temporary buffer when the host requests a report via the control endpoint and the
  *    user has set the PrevReportINBuffer driver configuration element to NULL (thanks to Lars Noschinski)
  *  - Fixed device state not being reset to DEVICE_STATE_Default if the host sets a 0x00 device address
  *  - Fixed device not stalling configuration requests before the device's address has been set
  *  - Fixed possibility of internal signature retrieval being corrupted if an interrupt occurs during a signature byte
  *    read (thanks to Andrei Krainev)
  *  - Fixed device state not being reset back to the default state if the host sets the address to 0
  *  - Fixed Set Configuration requests not being stalled until the host has set the device's address
  *  - Fixed Host mode HID class driver not sending the correct report type when HID_Host_SendReportByID() was called and the
  *    HID_HOST_BOOT_PROTOCOL_ONLY compile time option is set
  *  - Fixed INTERRUPT_CONTROL_ENDPOINT compile time option preventing other interrupts from occurring while the control endpoint
  *    request is being processed, causing possible lockups if a USB interrupt occurs during a transfer
  *  - Remove incorrect Abstract Call Management class specific descriptor from the CDC demos, bootloaders and projects
  *
  *
  *  \section Sec_ChangeLog100219 Version 100219
  *
  *  <b>New:</b>
  *  - Added TPI programming support for 6-pin ATTINY devices to the AVRISP programmer project (thanks to Tom Light)
  *  - Added command timeout counter to the AVRISP project so that the device no longer freezes when incorrectly connected
  *    to a target
  *  - Added new TemperatureDataLogger application, a USB data logger which writes to the device's dataflash and appears to
  *    the host as a standard Mass Storage device when inserted
  *  - Added MIDI event packing support to the MIDI Device and Host mode Class drivers, allowing for multiple MIDI events to
  *    sent or received in packed form in a single USB packet
  *  - Added new MIDI send buffer flush routines to the MIDI Device and Host mode Class drivers, to flush packed events
  *  - Added master mode hardware TWI driver for easy TWI peripheral control
  *  - Added ADC MUX masks for the standard ADC input channels on all AVR models with an ADC, altered demos to use these masks
  *    as on some models, the channel number is not identical to its single-ended ADC MUX mask
  *  - New Webserver project, a RNDIS host USB webserver using the open source uIP TCP/IP network stack and FatFS library
  *  - New BOARD value option BOARD_NONE (equivalent to not specifying BOARD) which will remove all board hardware drivers which
  *    do not adversely affect the code operation (currently only the LEDs driver)
  *  - Added keyboard modifier masks (HID_KEYBOARD_MODIFER_*) and LED report masks (KEYBOARD_LED_*) to the HID class driver and
  *    Keyboard demos
  *  - Added .5MHz recovery clock to the AVRISP programmer project when in ISP programming mode to correct mis-set fuses
  *
  *  <b>Changed:</b>
  *  - Slowed down software USART carried PDI programming in the AVRISP project to prevent transmission errors
  *  - Renamed the AVRISP project folder to AVRISP-MKII to reduce confusion
  *  - Renamed the RESET_LINE_* makefile tokens in the AVRISP MKII Project to AUX_LINE_*, as they are not always used for target
  *    reset
  *  - Changed over the MassStorageKeyboard Class driver device demo to use Start of Frame events rather than a timer to keep track
  *    of elapsed milliseconds
  *  - Inlined currently unused (but standardized) maintenance functions in the Device and Host Class drivers to save space
  *  - The XPLAINBridge project now selects between a USB to Serial bridge and a PDI programmer on startup, reading the JTAG port's
  *    TDI pin to determine which mode to use
  *  - Removed the stream example code from the Low Level VirtualSerial demos, as they were buggy and only served to add clutter
  *
  *  <b>Fixed:</b>
  *  - Fixed AVRISP project not able to enter programming mode when ISP protocol is used
  *  - Fixed AVRISP PDI race condition where the guard time between direction changes could be interpreted as a start bit
  *  - Fixed ADC_IsReadingComplete() returning an inverted result
  *  - Fixed blocking CDC streams not aborting when the host is disconnected
  *  - Fixed XPLAIN board Dataflash driver broken due to incorrect preprocessor commands
  *  - Fixed inverted XPLAIN LED driver output (LED turned on when it was supposed to be turned off, and vice-versa)
  *  - Fixed Class Driver struct interface numbers in the KeyboardMouse and VirtualSerialMouse demos (thanks to Renaud Cerrato)
  *  - Fixed invalid USB controller PLL prescaler values for the ATMEGAxxU2 controllers
  *  - Fixed lack of support for the ATMEGA32U2 in the DFU and CDC class bootloaders
  *  - Fixed Benito project not resetting the target AVR automatically when programming has completed
  *  - Fixed DFU bootloader programming not discarding the correct number of filler bytes from the host when non-aligned programming
  *    ranges are specified (thanks to Thomas Bleeker)
  *  - Fixed CDC and RNDIS host demos and class drivers - bidirectional endpoints should use two separate pipes, not one half-duplex pipe
  *  - Fixed Pipe_IsEndpointBound() not taking the endpoint's direction into account
  *  - Fixed EEPROM and FLASH ISP programming in the AVRISP project
  *  - Fixed incorrect values of USB_CONFIG_ATTR_SELFPOWERED and USB_CONFIG_ATTR_REMOTEWAKEUP tokens (thanks to Claus Christensen)
  *  - Fixed SerialStream driver blocking while waiting for characters to be received instead of returning EOF
  *  - Fixed SerialStream driver not setting stdin to the created serial stream (thanks to Mike Alexander)
  *  - Fixed USB_GetHIDReportSize() returning the number of bits in the specified report instead of bytes
  *  - Fixed AVRISP project not extending the command delay after each successful page/word/byte program
  *  - Fixed accuracy of the SERIAL_UBBRVAL() and SERIAL_2X_UBBRVAL() macros for higher baud rates (thanks to Renaud Cerrato)
  *
  *
  *  \section Sec_ChangeLog091223 Version 091223
  *
  *  <b>New:</b>
  *  - Added activity LED indicators to the AVRISP project to indicate when the device is busy processing a command
  *  - The USB target family and allowable USB mode tokens are now public and documented (USB_CAN_BE_*, USB_SERIES_*_AVR)
  *  - Added new XPLAIN USB to Serial Bridge project (thanks to John Steggall for initial proof-of-concept, David Prentice
  *    and Peter Danneger for revised software USART code)
  *  - Added new RNDIS Ethernet Host LowLevel demo
  *  - Added new RNDIS Ethernet Host Class Driver
  *  - Added new RNDIS Ethernet Host ClassDriver demo
  *  - Added CDC_Host_Flush() function to the CDC Host Class driver to flush sent data to the attached device
  *  - Added PDI programming support for XMEGA devices to the AVRISP programmer project (thanks to Justin Mattair)
  *  - Added support for the XPLAIN board Dataflash, with new XPLAIN_REV1 board target for the different Dataflash used
  *    on the first revision boards compared to the one mounted on later revisions
  *  - Added new HID_ALIGN_DATA() macro to return the pre-retrieved value of a HID report item, left-aligned to a given datatype
  *  - Added new PreviousValue to the HID Report Parser report item structure, for easy monitoring of previous report item values
  *  - Added new EVK527 board target
  *  - Added new USB_Host_GetDeviceStringDescriptor() convenience function
  *  - Added new LEDNotification project to the library, to give a visual LED notification on new events from the host
  *  - Added new NO_DEVICE_REMOTE_WAKEUP and NO_DEVICE_SELF_POWER compile time options
  *
  *  <b>Changed:</b>
  *  - Removed code in the Keyboard demos to send zeroed reports between two reports with differing numbers of key codes
  *    as this relied on non-standard OS driver behaviour to repeat key groups
  *  - The SCSI_Request_Sense_Response_t and SCSI_Inquiry_Response_t type defines are now part of the Mass Storage Class
  *    driver common defines, rather than being defined in the Host mode Class driver section only
  *  - The USB_MODE_HOST token is now defined even when host mode is not available
  *  - The CALLBACK_HID_Device_CreateHIDReport() HID Device Class driver callback now has a new ReportType parameter to
  *    indicate the report type to generate
  *  - All Class Drivers now return false or the "DeviceDisconnected" error code of their respective error enums when a function
  *    is called when no host/device is connected where possible
  *  - The HOST_SENDCONTROL_DeviceDisconnect enum value has been renamed to HOST_SENDCONTROL_DeviceDisconnected to be in line
  *    with the rest of the library error codes
  *  - Make MIDI device demos also turn off the on board LEDs if MIDI Note On messages are sent with a velocity of zero,
  *    which some devices use instead of Note Off messages (thanks to Robin Green)
  *  - The CDC demos are now named "VirtualSerial" instead to indicate the demos' function rather than its implemented USB class,
  *    to reduce confusion and to be in line with the rest of the LUFA demos
  *  - The SImage_Host_SendBlockHeader() and SImage_Host_ReceiveBlockHeader() Still Image Host Class driver functions are now public
  *
  *  <b>Fixed:</b>
  *  - Added missing CDC_Host_CreateBlockingStream() function code to the CDC Host Class driver
  *  - Fixed incorrect values for REPORT_ITEM_TYPE_* enum values causing corrupt data in the HID Host Parser
  *  - Fixed misnamed SI_Host_USBTask() and SI_Host_ConfigurePipes() functions
  *  - Fixed broken USB_GetNextDescriptor() function causing the descriptor to jump ahead double the expected amount
  *  - Fixed Pipe_IsEndpointBound() not masking the given Endpoint Address against PIPE_EPNUM_MASK
  *  - Fixed host state machine not enabling Auto VBUS mode when HOST_DEVICE_SETTLE_DELAY_MS is set to zero
  *  - Fixed misnamed Pipe_SetPipeToken() macro for setting a pipe's direction
  *  - Fixed CDCHost failing on devices with bidirectional endpoints
  *  - Fixed USB driver failing to define the PLL prescaler mask for the ATMEGA8U2 and ATMEGA16U2
  *  - Fixed HID Parser not distributing the Usage Min and Usage Max values across an array of report items
  *  - Fixed Mass Storage Host Class driver and Low Level demo not clearing the error condition if an attached device returns a
  *    STALL to a GET MAX LUN request (thanks to Martin Luxen)
  *  - Fixed TeensyHID bootloader not properly shutting down the USB interface to trigger a disconnection on the host before resetting
  *  - Fixed MassStorageHost Class driver demo not having USB_STREAM_TIMEOUT_MS compile time option set properly to prevent slow
  *    devices from timing out the data pipes
  *  - Fixed the definition of the Endpoint_BytesInEndpoint() macro for the U4 series AVR parts
  *  - Fixed MIDI host Class driver MIDI_Host_SendEventPacket() routine not properly checking for Pipe ready before writing
  *  - Fixed use of deprecated struct initializers, removed library unused parameter warnings when compiled with -Wextra enabled
  *  - Fixed Still Image Host Class driver truncating the PIMA response code (thanks to Daniel Seibert)
  *  - Fixed USB_CurrentMode not being reset to USB_MODE_NONE when the USB interface is shut down and both Host and Device modes can be
  *    used (thanks to Daniel Levy)
  *  - Fixed TeensyHID bootloader not enumerating to the host correctly (thanks to Clint Fisher)
  *  - Fixed AVRISP project timeouts not checking for the correct timeout period (thanks to Carl Ott)
  *  - Fixed STK525 Dataflash driver using incorrect bit-shifting for Dataflash addresses (thanks to Tim Mitchell)
  *
  *
  *  \section Sec_ChangeLog091122 Version 091122
  *
  *  <b>New:</b>
  *  - Added new Dual Role Keyboard/Mouse demo
  *  - Added new HID_HOST_BOOT_PROTOCOL_ONLY compile time token to reduce the size of the HID Host Class driver when
  *    Report protocol is not needed
  *  - Added new MIDI LowLevel and ClassDriver Host demo, add new MIDI Host Class driver
  *  - Added new CDC/Mouse ClassDriver device demo
  *  - Added new Joystick Host ClassDriver and LowLevel demos
  *  - Added new Printer Host mode Class driver
  *  - Added new Printer Host mode ClassDriver demo
  *  - Added optional support for double banked endpoints and pipes in the Device and Host mode Class drivers
  *  - Added new stream creation function to the CDC Class drivers, to easily make standard I/O streams from CDC Class driver instances
  *
  *  <b>Changed:</b>
  *  - Removed mostly useless "TestApp" demo, as it was mainly useful only for checking for syntax errors in the library
  *  - MIDI device demos now receive MIDI events from the host and display note ON messages via the board LEDs
  *  - Cleanups to the Device mode Mass Storage demo application SCSI routines
  *  - Changed Audio Class driver sample read/write functions to be inline, to reduce the number of cycles needed to transfer
  *    samples to and from the device (allowing more time for sample processing and output)
  *  - Audio class Device mode demos now work at both 16MHz and 8MHz, rather than just at 8MHz
  *  - The previous USBtoSerial demo has been moved into the projects directory, as it was just a modified CDC demo
  *  - The Endpoint/Pipe functions now use the const qualifier on the input buffer
  *  - Changed the CALLBACK_HIDParser_FilterHIDReportItem() callback to pass a HID_ReportItem_t rather than just the current
  *    item's attributes, to expose more information on the item (including it's type, collection path, etc.)
  *  - Changed MouseHostWithParser demos to check that the report items have a Mouse usage collection as a parent at some point,
  *    to prevent Joysticks from enumerating with the demo
  *  - Corrected the name of the misnamed USB_GetDeviceConfigDescriptor() function to USB_Host_GetDeviceConfigDescriptor().
  *  - Keyboard LowLevel/ClassDriver demos now support multiple simultaneous key presses (up to 6) per report
  *
  *  <b>Fixed:</b>
  *  - Fixed PrinterHost demo returning invalid Device ID data when the attached device does not have a
  *    device ID (thanks to Andrei Krainev)
  *  - Changed LUFA_VERSION_INTEGER define to use BCD values, to make comparisons easier
  *  - Fixed issue in the HID Host class driver's HID_Host_SendReportByID() routine using the incorrect mode (control/pipe)
  *    to send report to the attached device
  *  - Fixed ClassDriver AudioOutput device demo not selecting an audio output mode
  *  - Fixed incorrect SampleFrequencyType value in the AudioInput and AudioOutput ClassDriver demos' descriptors
  *  - Fixed incorrect event name rule in demo/project/bootloader makefiles
  *  - Fixed HID device class driver not reselecting the correct endpoint once the user callback routines have been called
  *  - Corrected HID descriptor in the Joystick Device demos - buttons should be placed outside the pointer collection
  *  - Fixed HID report parser collection paths invalid due to misplaced semicolon in the free path item search loop
  *  - Fixed HID host Class driver report send/receive report broken when issued through the control pipe
  *  - Fixed HOST_STATE_AS_GPIOR compile time option being ignored when in host mode (thanks to David Lyons)
  *  - Fixed LowLevel Keyboard demo not saving the issues report only after it has been sent to the host
  *  - Fixed Endpoint_Write_Control_Stream_* functions not sending a terminating IN when given data Length is zero
  *
  *
  *  \section Sec_ChangeLog090924 Version 090924
  *
  *  <b>New:</b>
  *  - Added new host mode class drivers and matching demos to the library for rapid application development
  *  - Added flag to the HID report parser to indicate if a device has multiple reports
  *  - Added new EVENT_USB_Device_StartOfFrame() event, controlled by the new USB_Device_EnableSOFEvents() and
  *    USB_Device_DisableSOFEvents() macros to give bus-synchronized millisecond interrupts when in USB device mode
  *  - Added new Endpoint_SetEndpointDirection() macro for bidirectional endpoints
  *  - Added new AVRISP project, a LUFA powered clone of the Atmel AVRISP-MKII programmer
  *  - Added ShutDown() functions for all hardware peripheral drivers, so that peripherals can be turned off after use
  *  - Added new CDC_Device_Flush() command to the device mode CDC Class driver to flush Device->Host data
  *  - Added extra masks to the SPI driver, changed SPI_Init() so that the clock polarity and sample modes can be set
  *  - Added new callback to the HID report parser, so that the user application can filter only the items it is interested
  *    in to be stored into the HIDReportInfo structure to save RAM
  *  - Added support for the officially recommended external peripheral layout for the BUMBLEB board (thanks to Dave Fletcher)
  *  - Added new Pipe_IsFrozen() macro to determine if the currently selected pipe is frozen
  *  - Added new USB_GetHIDReportSize() function to the HID report parser to retrieve the size of a given report by its ID
  *  - Added new combined Mass Storage and Keyboard demo (thanks to Matthias Hullin)
  *
  *  <b>Changed:</b>
  *  - SetIdle requests to the HID device driver with a 0 idle period (send changes only) now only affect the requested
  *    HID interface within the device, not all HID interfaces
  *  - Added explicit attribute masks to the device mode demos' descriptors
  *  - Added return values to the CDC and MIDI class driver transmit functions
  *  - Optimized Endpoint_Read_Word_* and Pipe_Read_Word_* macros to reduce compiled size
  *  - Added non-null function parameter pointer restrictions to USB Class drivers to improve user code reliability
  *  - Added new "Common" section to the class drivers, to hold all mode-independent definitions for clarity
  *  - Moved SCSI command/sense constants into the Mass Storage Class driver, instead of the user-code
  *  - Altered the SCSI commands in the LowLevel Mass Storage Host to save on FLASH space by reducing function calls
  *  - Changed the parameters and behaviour of the USB_GetDeviceConfigDescriptor() function so that it now performs size checks
  *    and data validations internally, to simplify user code
  *  - Changed HIDParser to only zero out important values in the Parsed HID Report Item Information structure to save cycles
  *  - The HID report parser now always processed FEATURE items - HID_ENABLE_FEATURE_PROCESSING token now has no effect
  *  - The HID report parser now always ignores constant-data items, HID_INCLUDE_CONSTANT_DATA_ITEMS token now has no effect
  *  - The Benito Programmer project now has its own unique VID/PID pair allocated from the Atmel donated LUFA VID/PID pool
  *  - Add in new invalid event hook check targets to project makefiles to produce compilation errors when invalid event names
  *    are used in a project
  *  - The HID Report Parser now gives information on the total length of each report within a HID interface
  *  - The USE_NONSTANDARD_DESCRIPTOR_NAMES compile time token has been removed - there are now separate USB_Descriptor_* and
  *    USB_StdDescriptor_* structures for both the LUFA and standardized element naming conventions so both may be used
  *
  *  <b>Fixed:</b>
  *  - Fixed possible lockup in the CDC device class driver, when the host sends data that is a multiple of the
  *    endpoint's bank
  *  - Fixed swapped parameters in the HID state memory copy call while processing a HID PUSH item in the HID report parser
  *  - Fixed memory corruption HID report parser when too many COLLECTION or PUSH items were processed
  *  - Fixed HID report parser not resetting the FEATURE item count when a REPORT ID item is encountered
  *  - Fixed USBtoSerial demos not reading in UDR1 when the USART receives data but the USB interface is not enumerated,
  *    causing continuous USART receive interrupts
  *  - Fixed misspelled event name in the Class driver USBtoSerial demo, preventing correct operation
  *  - Fixed invalid data being returned when a GetStatus request is issued in Device mode with an unhandled data recipient
  *  - Added hardware USART receive interrupt and software buffering to the Benito project to ensure received data is not
  *    missed or corrupted
  *  - Fixed Device mode HID Class driver always sending IN packets, even when nothing to report
  *  - Fixed Device mode HID Class driver not explicitly initializing the ReportSize parameter to zero before calling callback
  *    routine, so that ignored callbacks don't cause incorrect data to be sent
  *  - Fixed StillImageHost not correctly freezing and unfreezing data pipes while waiting for a response block header
  *  - Fixed error in the PrinterHost demo preventing the full page data from being sent to the attached device (thanks to John Andrews)
  *  - Fixed CDC based demos and projects' INF driver files under 64 bit versions of Windows (thanks to Ronny Hanson, Thomas Bleeker)
  *  - Re-add in missing flip, flip-ee, dfu and dfu-ee targets to project makefiles (thanks to Opendous Inc.)
  *  - Fix allowable F_CPU values comment in project makefiles to more accurately reflect the allowable values on the USB AVRs
  *  - Fixed DFU and CDC class bootloaders on the series 2 USB AVRs, corrected invalid signatures, added support for the new
  *    ATMEGAxx2 series 2 variant AVRs to the DFU bootloader
  *  - Fixed Low Level USBtoSerial demo not storing received characters (thanks to Michael Cooper)
  *  - Fixed MIDI Device Class driver not sending/receiving MIDI packets of the correct size (thanks to Thomas Bleeker)
  *
  *
  *  \section Sec_ChangeLog090810 Version 090810
  *
  *  <b>New:</b>
  *  - Added new device class drivers and matching demos to the library for rapid application development
  *  - Added new PrinterHost demo (thanks to John Andrews)
  *  - Added USB Missile Launcher project, submitted by Dave Fletcher
  *  - Added new Benito Arduino Programmer project
  *  - Added incomplete device and host mode demos for later enhancement
  *  - Updated MassStorage device block write routines to use ping-pong Dataflash buffering to increase throughput by around 30%
  *  - Error status LEDs shown when device endpoint configuration fails to complete in all demos and projects
  *  - Added new USB_Host_SetDeviceConfiguration() convenience function for easy configuration selection of devices while in USB
  *    host mode
  *  - Added new USB_Host_ClearPipeStall() convenience function to clear a stall condition on an attached device's endpoint
  *  - Added new USB_Host_GetDeviceDescriptor() convenience function to retrieve the attached device's Device descriptor
  *  - Added new Endpoint_ClearStatusStage() convenience function to assist with the status stages of control transfers
  *  - Added new USE_INTERNAL_SERIAL define for using the unique serial numbers in some AVR models as the USB device's serial number,
  *    added NO_INTERNAL_SERIAL compile time option to turn off new serial number reading code
  *  - Added new DATAFLASH_CHIP_MASK() macro to the Dataflash driver, which returns the Dataflash select mask for the given chip index
  *  - Added new HOST_STATE_WaitForDeviceRemoval host state machine state for non-blocking disabling of device communications until the
  *    device has been removed (for use when an error occurs or communications with the device have completed)
  *  - Added new FAST_STREAM_TRANSFERS compile time option for faster stream transfers via multiple bytes copied per stream loop
  *  - Added stdio stream demo code to the CDC device demos, to show how to create standard streams out of the virtual serial ports
  *  - Added new EEPROM and FLASH buffer versions of the Endpoint and Pipe stream functions
  *  - Added new USE_FLASH_DESCRIPTORS and FIXED_NUM_CONFIGURATIONS compile time options
  *  - Added support for the new ATMEGA32U2, ATMEGA16U2 and ATMEGA8U2 AVR models
  *  - Added new USB_DeviceState variable to keep track of the current Device mode USB state
  *  - Added new LEDs_ToggleLEDs() function to the LEDs driver
  *  - Added new Pipe_BoundEndpointNumber() and Pipe_IsEndpointBound() functions
  *  - Added new DEVICE_STATE_AS_GPIOR and HOST_STATE_AS_GPIOR compile time options
  *  - Added 404 Not Found errors to the webserver in the RNDIS demos to indicate invalid URLs
  *
  *  <b>Changed:</b>
  *  - Deprecated pseudo-scheduler and removed dynamic memory allocator from the library (first no longer needed and second unused)
  *  - The device-mode CALLBACK_USB_GetDescriptor() function now has an extra parameter so that the memory space in which the requested
  *    descriptor is located can be specified. This means that descriptors can now be located in multiple memory spaces within a device.
  *  - Removed vague USB_IsConnected global - test USB_DeviceState or USB_HostState explicitly to gain previous functionality
  *  - Removed USB_IsSuspended global - test USB_DeviceState against DEVICE_STATE_Suspended instead
  *  - Extended USB_GetDeviceConfigDescriptor() routine to require the configuration number within the device to fetch
  *  - Dataflash_WaitWhileBusy() now always ensures that the dataflash is ready for the next command immediately after returning,
  *    no need to call Dataflash_ToggleSelectedChipCS() afterwards
  *  - Low level API MIDI device demo no longer blocks if a note change event is sent while the endpoint is not ready
  *  - Pipe_GetErrorFlags() now returns additional error flags for overflow and underflow errors
  *  - Pipe stream functions now automatically set the correct pipe token, so that bidirectional pipes can be used
  *  - Pipe_ConfigurePipe() now automatically defaults IN pipes to accepting infinite IN requests, this can still be changed by calling
  *    the existing Pipe_SetFiniteINRequests() function
  *  - Changed F_USB entries in project makefiles to alias to F_CPU by default, as this is the most common case
  *  - Host mode demos now use sane terminal escape codes, so that text is always readable and events/program output is visually distinguished
  *    from one another using foreground colours
  *  - Internal per-device preprocessing conditions changed to per-device series rather than per-controller group for finer-grain
  *    internal control
  *  - Interrupts are no longer disabled during the processing of Control Requests on the default endpoint while in device mode
  *  - AudioOutput demos now always output to board LEDs, regardless of output mode (removed AUDIO_OUT_LEDS project option)
  *  - Removed SINGLE_DEVICE_CONFIGURATION compile time option in favor of the new FIXED_NUM_CONFIGURATIONS option so that the exact number
  *    of device configurations can be defined statically
  *  - Removed VBUS events, as they are already exposed to the user application via the regular device connection and disconnection events
  *  - Renamed and altered existing events to properly separate out Host and Device mode events
  *  - All demos switched over from GNU99 standards mode to C99 standards mode, to reduce the dependencies on GCC-only language extensions
  *
  *  <b>Fixed:</b>
  *  - Changed bootloaders to use FLASHEND rather than the existence of RAMPZ to determine if far FLASH pointers are needed to fix
  *    bootloaders on some of the USB AVR devices where avr-libc erroneously defines RAMPZ
  *  - Fixes to MassStorageHost for better device compatibility (increase command timeout, change MassStore_WaitForDataReceived()
  *    to only unfreeze and check one data pipe at a time) to prevent incorrect device enumerations and freezes while transferring data
  *  - Make Pipe_ConfigurePipe() mask the given endpoint number against PIPE_EPNUM_MASK to ensure the endpoint IN direction bit is
  *    cleared to prevent endpoint type corruption
  *  - Fixed issue opening CDC-ACM ports on hosts when the CDC device tries to send data before the host has set the line encoding
  *  - Fixed USB_OPT_MANUAL_PLL option being ignored during device disconnects on some models (thanks to Brian Dickman)
  *  - Fixed documentation mentioning Pipe_GetCurrentToken() function when correct function name is Pipe_GetPipeToken()
  *  - Fixed ADC driver for the ATMEGA32U4 and ATMEGA16U4 (thanks to Opendous Inc.)
  *  - Fixed CDCHost demo unfreezing the pipes at the point of configuration, rather than use
  *  - Fixed MassStorage demo not clearing the reset flag when a Mass Storage Reset is issued while not processing a command
  *  - Fixed USB_Host_SendControlRequest() not re-suspending the USB bus when initial device ready-wait fails
  *  - Fixed USB Pad regulator not being disabled on some AVR models when the USB_OPT_REG_DISABLED option is used
  *  - Fixed Host mode to Device mode UID change not causing a USB Disconnect event when a device was connected
  *  - Fixed Mouse/Keyboard demos not performing the correct arithmetic on the Idle period at the right times (thanks to Brian Dickman)
  *  - Fixed GenericHID failing HID class tests due to incorrect Logical Minimum and Logical Maximum values (thanks to Soren Greiner)
  *  - Fixed incorrect PIPE_EPNUM_MASK mask causing pipe failures on devices with endpoint addresses of 8 and above (thanks to John Andrews)
  *  - Fixed report data alignment issues in the MouseHostWithParser demo when X and Y movement data size is not a multiple of 8 bits
  *  - Fixed HID Report Descriptor Parser not correctly resetting internal states when a REPORT ID element is encountered
  *  - Fixed incorrect BUTTONS_BUTTON1 for the STK526 target
  *  - Fixed RNDIS demos freezing when more than one connection was attempted simultaneously, causing memory corruption
  *  - Fixed USBtoSerial demo receiving noise from the USART due to pull-up not being enabled
  *
  *
  *  \section Sec_ChangeLog090605 Version 090605
  *
  *  - Fixed bug in RNDISEthernet and DualCDC demos not using the correct USB_ControlRequest structure for control request data
  *  - Fixed documentation showing incorrect USB mode support on the supported AVRs list
  *  - Fixed RNDISEthernet not working under Linux due to Linux requiring an "optional" RNDIS request which was unhandled
  *  - Fixed Mouse and Keyboard device demos not acting in accordance with the HID specification for idle periods (thanks to Brian Dickman)
  *  - Removed support for endpoint/pipe non-control interrupts; these did not act in the way users expected, and had many subtle issues
  *  - Fixed Device Mode not handling Set Feature and Clear Feature Chapter 9 requests that are addressed to the device (thanks to Brian Dickman)
  *  - Moved control endpoint interrupt handling into the library itself, enable via the new INTERRUPT_CONTROL_ENDPOINT token
  *  - Fixed CDCHost not clearing configured pipes and resetting configured pipes mask when a partially enumerated invalid CDC
  *    interface is skipped
  *  - Clarified the size of library tokens which accept integer values in the Compile Time Tokens page, values now use the smallest datatype
  *    inside the library that is able to hold their defined value to save space
  *  - Removed DESCRIPTOR_ADDRESS() macro as it was largely superfluous and only served to obfuscate code
  *  - Rewritten event system to remove all macros, to make user code clearer
  *  - Fixed incorrect ENDPOINT_EPNUM_MASK mask preventing endpoints above EP3 from being selected (thanks to Jonathan Oakley)
  *  - Removed STREAM_CALLBACK() macro - callbacks now use regular function definitions to clarify user code
  *  - Removed DESCRIPTOR_COMPARATOR() macro - comparators should now use regular function definitions to clarify user code
  *  - USB_IsConnected is now cleared before the USB_Disconnect() event is fired in response to VBUS being removed
  *  - Fixed incorrect PID value being used in the USBtoSerial project (thanks to Phill)
  *  - Deleted StdDescriptors.c, renamed USB_GetDescriptor() to CALLBACK_USB_GetDescriptor, moved ConfigDescriptor.c/.h from the
  *    LUFA/Drivers/USB/Class/ directory to LUFA/Drivers/USB/HighLevel/ in preparation for the new USB class APIs
  *  - Moved out each demos' functionality library files (e.g. Ring Buffer library) to /Lib directories for a better directory structure
  *  - Removed Tx interrupt from the USBtoSerial demo; now sends characters via polling to ensure more time for the Rx interrupt
  *  - Fixed possible enumeration errors from spin-loops which may fail to exit if the USB connection is severed before the exit condition
  *    becomes true
  *
  *
  *  \section Sec_ChangeLog090510 Version 090510
  *
  *  - Added new GenericHIDHost demo
  *  - Corrections to the KeyboardHost and MouseHost demos' pipe handling to freeze and unfreeze the data pipes at the point of use
  *  - KeyboardHost, MouseHost and GenericHIDHost demos now save and restore the currently selected pipe inside the pipe ISR
  *  - Changed GenericHID device demo to use the LUFA scheduler, added INTERRUPT_DATA_ENDPOINT and INTERRUPT_CONTROL_ENDPOINT compile
  *    time options
  *  - All comments in the library, bootloaders, demos and projects have now been spell-checked and spelling mistakes/typos corrected
  *  - Added new PIMA_DATA_SIZE() define to the Still Image Host demo
  *  - Add call to MassStore_WaitForDataReceived() in MassStore_GetReturnedStatus() to ensure that the CSW has been received in the
  *    extended MSC timeout period before continuing, to prevent long processing delays from causing the MassStore_GetReturnedStatus()
  *    to early-abort (thanks to Dmitry Maksimov)
  *  - Move StdRequestType.h, StreamCallbacks.h, USBMode.h from the LowLevel USB driver directory to the HighLevel USB driver directory,
  *    where they are more suited
  *  - Removed all binary constants and replaced with decimal or hexadecimal constants so that unpatched GCC compilers can still build the
  *    code without having to be itself patched and recompiled first
  *  - Added preprocessor checks and documentation to the bootloaders giving information about missing SIGNATURE_x defines due to
  *    outdated avr-libc versions.
  *  - Added support to the CDCHost demo for devices with multiple CDC interfaces which are not the correct ACM type preceding the desired
  *    ACM CDC interface
  *  - Fixed GenericHID demo not starting USB and HID management tasks when not using interrupt driven modes (thanks to Carl Kjeldsen)
  *  - Fixed RNDISEthenet demo checking the incorrect message field for packet size constraints (thanks to Jonathan Oakley)
  *  - Fixed WriteNextReport code in the GenericHIDHost demo using incorrect parameter types and not selecting the correct endpoint
  *  - Adjusted sample CTC timer calculations in the AudioOutput and AudioInput demos to match the CTC calculations in the AVR datasheet,
  *    and to fix instances where rounding caused the endpoint to underflow (thanks to Robin Theunis)
  *  - The USB_Host_SendControlRequest() function no longer automatically selects the Control pipe (pipe 0), so that other control type
  *    pipes can be used with the function
  *  - The USB Host management task now saves and restores the currently selected pipe before and after the task completes
  *  - Fixed GenericHIDHost demo report write routine incorrect for control type requests (thanks to Andrei Krainev)
  *  - Removed Endpoint_ClearCurrentBank() and Pipe_ClearCurrentBank() in favor of new Endpoint_ClearIN(), Endpoint_ClearOUT(),
  *    Pipe_ClearIN() and Pipe_ClearOUT() macros (done to allow for the detection of packets of zero length)
  *  - Renamed *_ReadWriteAllowed() macros to *_IsReadWriteAllowed() to remain consistent with the rest of the LUFA API
  *  - Endpoint_IsSetupReceived() macro has been renamed to Endpoint_IsSETUPReceived(), Endpoint_ClearSetupReceived() macro has been
  *    renamed to Endpoint_ClearSETUP(), the Pipe_IsSetupSent() macro has been renamed to Pipe_IsSETUPSent() and the
  *    Pipe_ClearSetupSent() macro is no longer applicable and should be removed - changes made to compliment the new endpoint and pipe
  *    bank management API
  *  - Updated all demos, bootloaders and projects to use the new endpoint and pipe management APIs (thanks to Roman Thiel from Curetis AG)
  *  - Updated library Doxygen documentation, added groups, changed documentation macro functions to real functions for clarity
  *  - Removed old endpoint and pipe aliased read/write/discard routines which did not have an explicit endian specifier for clarity
  *  - Removed the ButtLoadTag.h header file, as no one used for its intended purpose anyway
  *  - Renamed the main Drivers/AT90USBXXX directory to Drivers/Peripheral, renamed the Serial_Stream driver to SerialStream
  *  - Fixed CDC and USBtoSerial demos freezing where buffers were full while still transmitting or receiving (thanks to Peter Hand)
  *  - Removed "Host_" section of the function names in ConfigDescriptor.h, as most of the routines can now be used in device mode on the
  *    device descriptor
  *  - Renamed functions in the HID parser to have a "USB_" prefix and the acronym "HID" in the name
  *  - Fixed incorrect HID interface class and subclass values in the Mouse and KeyboardMouse demos (thanks to Brian Dickman)
  *  - Capitalized the "Descriptor_Search" and "Descriptor_Search_Comp" prefixes of the values in the DSearch_Return_ErrorCodes_t and
  *    DSearch_Comp_Return_ErrorCodes_t enums
  *  - Removed "ERROR" from the enum names in the endpoint and pipe stream error code enums
  *  - Renamed the USB_PowerOnErrorCodes_t enum to USB_InitErrorCodes_t, renamed the POWERON_ERROR_NoUSBModeSpecified enum value to
  *    USB_INITERROR_NoUSBModeSpecified
  *  - Renamed USB_PowerOnFail event to USB_InitFailure
  *  - Renamed OTG.h header functions to be more consistent with the rest of the library API
  *  - Changed over all deprecated GCC structure tag initializers to the standardized C99 format (thanks to Mike Alexander)
  *  - USB_HostRequest renamed to USB_ControlRequest, entire control request header is now read into USB_ControlRequest in Device mode
  *    rather than having the library pass only partially read header data to the application
  *  - The USB_UnhandledControlPacket event has had its parameters removed, in favor of accessing the new USB_ControlRequest structure
  *  - The Endpoint control stream functions now correctly send a ZLP to the host when less data than requested is sent
  *  - Fixed USB_RemoteWakeupEnabled flag never being set (the REMOTE WAKEUP Set Feature request was not being handled)
  *  - Renamed the FEATURELESS_CONTROL_ONLY_DEVICE compile-time token to CONTROL_ONLY_DEVICE
  *  - Endpoint configuration is now refined to give better output when all configurations have static inputs - removed the now useless
  *    STATIC_ENDPOINT_CONFIGURATION compile time token
  *  - Fixed SPI driver init function not clearing SPI2X bit when not needed
  *  - Fixed PREVENT ALLOW MEDIUM REMOVAL command issuing in the MassStorageHost demo using incorrect parameters (thanks to Mike Alex)
  *  - Fixed MassStorageHost demo broken due to an incorrect if statement test in MassStore_GetReturnedStatus()
  *  - Fixed reversed signature byte ordering in the CDC bootloader (thanks to Johannes Raschke)
  *  - Changed PIPE_CONTROLPIPE_DEFAULT_SIZE from 8 to 64 to try to prevent problems with faulty devices which do not respect the given
  *    wLength value when reading in the device descriptor
  *  - Fixed missing semicolon in the ATAVRUSBRF01 LED board driver code (thanks to Morten Lund)
  *  - Changed LED board driver code to define dummy LED masks for the first four board LEDs, so that user code can be compiled for boards
  *    with less than four LEDs without code modifications (thanks to Morten Lund)
  *  - Changed HWB board driver to Buttons driver, to allow for the support of future boards with more than one mounted GPIO button
  *  - Serial driver now correctly calculates the baud register value when in double speed mode
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

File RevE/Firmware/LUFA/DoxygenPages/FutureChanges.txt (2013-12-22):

/** \file
 *
 *  This file contains special DoxyGen information for the generation of the main page and other special
 *  documentation pages. It is not a project source file.
 */

 /** \page Page_FutureChanges Future Changes
  *
  *  Below is a list of future changes which are proposed for the LUFA library, but not yet started/complete.
  *  This gives an unordered list of future changes which may be available in future releases of the library.
  *  If you have an item to add to this list, please contact the library author via email, the LUFA mailing list,
  *  or post your suggestion as an enhancement request to the project bug tracker.
  *
  *  <b>Targeted for Future Releases:</b>
  *  - Code Features
  *      -# Add hub support when in Host mode for multiple devices
  *      -# Investigate virtual hubs when in device mode instead of composite devices
  *      -# Re-add interrupt Pipe/Endpoint support
  *      -# Update stream APIs to use DMA transfers on supported architectures
  *      -# Pull out third party libraries into a separate folder and reference them as required
  *      -# Add a LUFA_YIELD macro for integration into a third-party RTOS
  *      -# Abstract out Mass Storage byte send/receive to prevent low level API use in projects
  *      -# Fix HID report parser usage support for array types
  *      -# Make HOST_DEVICE_SETTLE_DELAY_MS a global variable that can be changed
  *      -# Add MANDATORY_EVENT_FUNCTIONS compile time option
  *      -# Add watchdog support to the library and apps/bootloaders
  *  - Testing/Verification
  *      -# Re-run USBIF test suite on all classes to formally verify operation
  *      -# Implement automated functional testing of all demos
  *  - Documentation/Support
  *      -# Add detailed overviews of how each demo works
  *      -# Add board overviews
  *      -# Write LUFA tutorials
  *  - Demos/Projects
  *      -# Add class driver support for Test and Measurement class
  *      -# Add class driver support for EEM class
  *      -# Add class driver support for ECM class
  *      -# Add class driver generic HID report host demo
  *      -# Implement flow control for USB to Serial project
  *  - Ports
  *      -# Port all demos to multiple architectures
  *      -# Finish USB XMEGA port
  *      -# Add AVR32 UC3C, UC3D and UC3L support
  *      -# Other (commercial) C compilers
  */

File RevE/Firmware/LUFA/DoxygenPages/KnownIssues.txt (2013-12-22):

/** \file
 *
 *  This file contains special DoxyGen information for the generation of the main page and other special
 *  documentation pages. It is not a project source file.
 */

 /** \page Page_KnownIssues Known Issues
  *  The following are known issues present in each official LUFA release. This list should contain all known
  *  issues in the library. Most of these issues should be corrected in the future release - see
  *  \ref Page_FutureChanges for a list of planned changes in future releases.
  *
  *  \section Sec_KnownIssues130901 Version 130901
  *  - AVR8 Architecture
  *    - No known issues.
  *  - UC3 Architecture
  *    \warning The UC3 device support is currently <b>experimental</b> (incomplete and/or non-functional), and is included for preview purposes only. \n
  *
  *    - No demos, bootloaders or projects have been ported for the UC3 devices in the current release,
  *      although the architecture is supported in the LUFA core library.
  *    - DMA transfers to and from the USB controller are not yet implemented for this release.
  *    - The UC3C, UC3D and UC3L sub-families of UC3 are not currently supported by the library due to their
  *      altered USB controller design.
  *    - The various \c *_CreateStream() functions for creating standard \c <stdio.h> compatible virtual file
  *      streams are not available on the UC3 architecture, due to a lack of suitable library support.
  *  - XMEGA Architecture
  *    \warning The XMEGA device support is currently <b>experimental</b> (incomplete and/or non-functional), and is included for preview purposes only.
  *
  *    - Endpoints of more than 64 bytes are not currently supported in this release.
  *    - Isochronous endpoints are not currently supported in this release. As a result, the audio class
  *      cannot be used on XMEGA devices.
  *    - Multiple-bank endpoints are not currently supported in this release.
  *    - Early silicon revisions of the ATXMEGA128A1U are incompatible with LUFA, due to their various errata
  *      relating to the USB controller.
  *  - Architecture Independent
  *    - The LUFA library is not watchdog aware, and thus timeouts are possible if short periods are used
  *      and a lengthy USB operation is initiated.
  *    - No LUFA provided driver INF files for Windows are signed, and thus may fail to install on systems where driver signing is enforced (e.g. Windows 8).
  *  - Build System
  *    - No known issues.
  *  - Atmel Studio Integration
  *    - Not all devices are listed in the "Supported Parts" screen when selecting a device. To select an alternative device, change the "Show Device" drop-down to "All Parts".
  *    - When switching boards after changing the device selection, a second conflicting BOARD symbol definition can be created that prevents successful compilation. To fix, open the project properties window (<i>Project->Project {name} Properties...</i> menu item), click the Toolchain tab, click "Symbols" under the "AVR/GNU C Compiler" section and remove the incorrect definition.
  *
  *  \section Sec_KnownIssues130303 Version 130303
  *  - AVR8 Architecture
  *    - No known issues.
  *  - UC3 Architecture
  *    \warning The UC3 device support is currently <b>experimental</b> (incomplete and/or non-functional), and is included for preview purposes only. \n
  *
  *    - No demos, bootloaders or projects have been ported for the UC3 devices in the current release,
  *      although the architecture is supported in the LUFA core library.
  *    - DMA transfers to and from the USB controller are not yet implemented for this release.
  *    - The UC3C, UC3D and UC3L sub-families of UC3 are not currently supported by the library due to their
  *      altered USB controller design.
  *    - The various \c CreateStream() functions for creating standard \c <stdio.h> compatible virtual file
  *      streams are not available on the UC3 architecture, due to a lack of suitable library support.
  *  - XMEGA Architecture
  *    \warning The XMEGA device support is currently <b>experimental</b> (incomplete and/or non-functional), and is included for preview purposes only.
  *
  *    - No demos, bootloaders or projects have been ported for the XMEGA devices in the current release,
  *      although the architecture is supported in the LUFA core library.
  *    - Endpoints of more than 64 bytes are not currently supported in this release.
  *    - Isochronous endpoints are not currently supported in this release. As a result, the audio class
  *      cannot be used on XMEGA devices.
  *    - Multiple-bank endpoints are not currently supported in this release.
  *    - Early revisions of the ATXMEGA128A1U are incompatible with LUFA, due to their various errata
  *      relating to the USB controller.
  *  - Architecture Independent
  *    - The LUFA library is not watchdog aware, and thus timeouts are possible if short periods are used
  *      and a lengthy USB operation is initiated.
  *    - No LUFA provided driver INF files for Windows are signed, and thus may fail to install on systems where driver signing is enforced (e.g. Windows 8).
  *  - Build System
  *    - No known issues.
  *
  *  \section Sec_KnownIssues120730 Version 120730
  *  - AVR8 Architecture
  *    - No known issues.
  *  - UC3 Architecture
  *    \warning The UC3 device support is currently <b>experimental</b> (incomplete and/or non-functional), and is included for preview purposes only. \n
  *
  *    - No demos, bootloaders or projects have been ported for the UC3 devices in the current release,
  *      although the architecture is supported in the LUFA core library.
  *    - DMA transfers to and from the USB controller are not yet implemented for this release.
  *    - The UC3C, UC3D and UC3L sub-families of UC3 are not currently supported by the library due to their
  *      altered USB controller design.
  *    - The various \c CreateStream() functions for creating standard \c <stdio.h> compatible virtual file
  *      streams are not available on the UC3 architecture, due to a lack of suitable library support.
  *  - XMEGA Architecture
  *    \warning The XMEGA device support is currently <b>experimental</b> (incomplete and/or non-functional), and is included for preview purposes only.
  *
  *    - No demos, bootloaders or projects have been ported for the XMEGA devices in the current release,
  *      although the architecture is supported in the LUFA core library.
  *    - Endpoints of more than 64 bytes are not currently supported in this release.
  *    - Isochronous endpoints are not currently supported in this release. As a result, the audio class
  *      cannot be used on XMEGA devices.
  *    - Multiple-bank endpoints are not currently supported in this release.
  *    - Early revisions of the ATXMEGA128A1U are incompatible with LUFA, due to their various errata
  *      relating to the USB controller.
  *  - Architecture Independent
  *    - The LUFA library is not watchdog aware, and thus timeouts are possible if short periods are used
  *      and a lengthy USB operation is initiated.
  *    - No LUFA provided driver INF files for Windows are signed, and thus may fail to install on systems where driver signing is enforced (e.g. Windows 8).
  *  - Build System
  *    - No known issues.
  */

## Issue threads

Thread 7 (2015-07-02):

how to calibrate C2 value ?

Georges760, 2015-07-02:
i have made a ChameleonMini, successfully installed firmware, and have access to console configuration.

When trying to emulate a card, I found cannot scan it with a reader (phone or ACR121). Maybe it is due to the RF antenna filtering, and specially the C2 value.

Can you advise a way to diagnose this issue ? and a explanation of C2 value over antenna spec ?

Thanks

david-oswald, 2015-07-03:
Hi,

a few things to check:

Which card type have you selected in the terminal? Did you check the soldering in the RF area? Some components are quite tiny there. You could probe signals (e.g. DEMOD should show some data from the reader, LOADMOD should be driven by the Xmega, SUBCARRIER as well) and check they are OK. Same goes for the field, use a few turns of wire or an RF probe if you have connected to your scope to see if the chameleon load-modulates correctly.

C2 is not crucial to the function, but can improve range. Bringing the antenna to exact resonance is easiest with a VNA.

You can also remove the circuitry for the passive mode (R5, D2A, D2B, D4A, D4B), some readers don't like it / have minimal range.

Best
David

Closed 2015-08-09.

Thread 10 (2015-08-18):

A problem about the "unknown device"

wyatuestc, 2015-08-18:
I made a ChameleonMini by myself.
Here is my step to download the firmware:
1. connect the board to PC
2. use avr isp mkii to download the bootloader(RevE-atxmega32a4u_104_modified.hex)
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

I can see a device named ATxmega32A4U
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

3.after that, I dowload the firmware/eeprom Chameleon-Mini.hex/Chameleon-Mini.elf with avr isp mkii,and I got this:"Unknown device"(at that time, one led turns on), and I also use the FLIP to download the firmware/eeprom, I got the same result.

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

I want to know what happened.

Tanks :)

--------------------------------------------
I can download the frimware which is provided by the AVR studio6
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

and I got this
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

It seemed like working well...

wyatuestc, 2015-08-18:
There must be something wrong.
When I open VMware and run a virtual machine(ubuntu 14.04),  I found the hardware is working, I test it many times.....
It's wired....
I guess there is something wrong in the USB driver......

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

wyatuestc, 2015-08-19:
I think I solve problem when I used the newest firmware....
There are something promblems on my hardware.....

david-oswald, 2015-08-19:
Yes, you for sure need the newest FW - the older one contained a bug that caused the Chameleon to fail with newer Flash chips (actually this error should have also affected older Flash, but it seemed more tolerant). Anyway, this is fixed in the new FW.

Re VMWare: Have not tried, any reason why you need this? Also, wasn't VMware working before (and now stopped)? Strange bug, if you find out anything pls let us know.

Re command line: Have you seen this page: https://htmlpreview.github.io/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

theforcedk, 2015-09-16:
In order to use USB's in virtualized environments, you usually have to add filters to ensure that the USB is grabbed by the guest OS before the host OS when plugged in, otherwise you'll get stability issues and the USB will connect/disconnect/connect/disconnect. For VirtualBox, this works with ChameleonMini: http://www.atmel.com/webdoc/atmelstudio/atmelstudio.faq.virtualbox.html

Closed 2015-08-21.

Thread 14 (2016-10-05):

Missing RevG BOM/CAD Files

Chankster, 2016-10-05:

emsec, 2016-10-07:
sorted.

Closed 2016-10-07.

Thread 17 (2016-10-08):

Windows 10 can't find the ChameleonMini

PetersPGM, 2016-10-08:
I received my ChameleonMini today. Great!

I checked the Getting Started to learn I had to upgrade the firmware. I downloaded the files and hit the first bump. It needed libusb0.dll. After getting and installing that, I continued.

Pressing the RBUTTON when connecting the device to the PC does not show anything on the device. Is that correct? I expected some indication the device is in bootloader mode.
Connecting the device to the computer without pressing a button shows one green LED.

The second solution, using the test firmware, implies the computer should be able to detect the device. I don't seem to be able to find the device in Device Manager.

david-oswald, 2016-10-08:
Do you have Windows 10 anniversary update? After upgrading one of my systems to this version, I initially noticed similar problems.

I blamed this on the fact that I had the earlier (unsigned) Chameleon driver installed (did you?). Anyway, for me this was fixed by:

- Manually installing the new driver (right-click .inf file, select install)
- Fully unplugging Chameleon and making sure it is fully powered off (removed battey)
- Re-plugged and device shows up

emsec, 2016-10-08:
Hi, we have tested with Windows 10 and there should be no problem. In the bootloader, there is no LED lit so it is a good sign that you have succeeded with the first step to trigger the bootloader. Next you have to follow the "Upgrade Procedure for Windows Users", have you done that? most importantly hav you followed Step 2:  Install the atmel_usb_dfu.inf driver (right click -> install).
After this the ATXmega128A4U DFU should appear in the device manager.  Now you can proceed with the FirmwareUpgrade.bat.

SuperVirus, 2016-10-08:
I had problems installing the driver via right click => install, too. I didn't install the libub0.dll.
Instead installed the driver from the device manager, which worked for me.

With the test-firmware windows 10 it showed up as an com port device, without installing any driver.

SuperVirus, 2016-10-08:
I had problems installing the driver via right click => install, too: I didn't install the libub0.dll.
Instead installed the driver from the device manager, which worked for me.

With the test-firmware windows 10 it showed up as an com port device "USB Serial Device (COMx)", without installing any driver, because it uses the built-in serial port class driver.

Cybersloth, 2016-10-10:
This info may help someone, Devs feel free to pull it if you don't agree

The first problem I overcame was that my browser wanted to display rather than download the .eep and .hex files, not a big problem I selected all (CNTRL A) and copied (CNTRL C), then created new files with the correct filenames and pasted (CNTRL B).  But when I ran the .bat file got the Chameleon may not be in bootloader mode message, but more importantly it mentioned line 7 in the error, this was the clue !. The Chameleon was in bootloader mode, but you can't tell as there is no feedback.  When I copied and pasted the file contents I failed to add a return (Carriage return) after the last line of both files, the .hex file would have given a line 6512 error.

The second issue was that windows did not want to install the unsigned drivers, this can be easily overcome, just google

All working very well now

Note to Devs....is there some way that the Chameleon could indicate it is in bootloader mode ?  I think some people with the issues above will assume the Chameleon has a problem as it provides no feedback

r4b3, 2016-10-10:
@SuperVirus -> when u see the com port, open install new driver and point to the directory where the drivers are.

PetersPGM, 2016-10-10:
I have installed everything according to the manual. I see neither a COMx serial port nor anything similar to ATXmega128A4U DFU in my Device Manager. I will try to find another Windows system this week to test it on that. I will also get my hands on a linux (Raspberry PI) somewhere this week too.

emsec, 2016-10-10:
@Cybersloth: the drivers ARE signed (?!)  you need the .inf and .cat in the same folder, of course. The copy paste approch is NOT recommended as it may result in corrupted firmware files (and this in turn in a defetive ChameleonMini...). Just use right mouse button and "save target as..", that works fine for me. Indication for bootloader mode is that no LED is lit AND something appears in device manager ; even without driver, a new device apperas in the device manager (for Windows). Changes are not planned: The Bootloader is factory-programmed and cannot be updated via USB.

Cybersloth, 2016-10-10:
@emsec  Unfortunately and absolutely the cut an paste will have stripped the signing, maybe a slightly more descriptive getting started would help folk like me ref the lack of indication that bootloader mode is not fed back ?

zenroth1752, 2016-10-14:
Hi,
I have seen the lsusb problem before on Win7 64 bit and Win 10 64bit cant install .inf on a 64 bit machine. I used http://zadig.akeo.ie/ from the days of HackRfOne and SDR. Download it, installed and follow the simple instructions. This will then recognise the usb device ChameleonMini and let you install the rest via Device Manager , ( Right click, browse to ChameleonMini.inf and install ) It is a simple and some say dirty trick but it works. Cheers Zen Roth

theGRK, 2016-10-15:
@zenroth1752 thanks for your suggestion, I got the same issue on win7 64bit.
When installing Zadig what driver should I better choose?

zenroth1752, 2016-10-15:
@theGRK I just installed the default WinUSB as it has the libusb1-0.
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. Then you should be good to go. All the best. Zen

theGRK, 2016-10-23:
Unfortunately, I still cannot make it working on win7 x64
After installing the driver via Zadig, as @zenroth1752 kindly suggested, I see 2 different behaviours.
1. if the device is connected without holding the RBUTTON, windows identifies the device as
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
2.  if the device is connected holding the RBUTTON, windows identifies the device as
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
In any case I cannot locate the COM port to connect to and Tera Term got a grayed out menu for serial communications
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
Also the ChameleonFirmwareUpgrade ends with
> There was an error with executing this command. Maybe your ChameleonMini is not in bootloader mode?

(dfu-programmer error 0xc000007b)

Any other hint?
Thanks

g-c-n, 2016-10-23:
Hi. Just in case, I was just saying in another thread that I was in a similar situation - I thought I tried everything including changing the cables. After trying a third cable out of despair, the Chameleon got detected immediately.

geo-rg, 2016-10-24:
Hi @theGRK,
it seems like you are on the right way: connecting the device holding RBUTTON is correct and the Chameleon also shows up correctly as DFU ATXMEGA128A4U. This means, that the Chameleon is in bootloader mode, where it waits for a new firmware to be flashed via USB.

Unfortunately, I do not know the dfu-programmer error. I suggest using another program for flashing instead of the .bat file, which uses dfu-programmer. An idea would be using http://www.atmel.com/tools/FLIP.aspx. In FLIP it is important that you select ("Device Selection") the correct controller (ATxmega128A4U) and then program the hex file to the flash program memory. For flashing the EEPROM ("Select EEPROM") it is important that you _uncheck_ the first two checkboxes ("Erase", "Blank check").

zenroth1752, 2016-10-25:
Hi,
Did you go into device an install the drivers?
Go to devices the you install the chameleon drives that that will provide the bridge to the vertical port Com6. This is from memory. I will type it too properly if this does not work out.

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

theGRK, 2016-11-05:
Dear @geo-rg and @zenroth1752,
    sorry for the late follow-up.
After many attempts I changed the usb driver with Zadig from WinUSB to libusb-win32.
Using FLIP I programmed the chameleon, which now shows up in Windows Devices as Chameleon-Mini instead of LUFA CDC Demo.
Now I'm trying to connect with TeraTerm but the serial box is still disabled. Any suggestion here?
Thanks for your kindly help.

domoarigatosan, 2016-11-08:
@theGRK
I has similar issue but I read out that you have reinstall the libusb-win32 from Zadig.

Try activate the ChameleonFirmwareUpgrade.bat (Doesn't matter if you can't see the serial box on TeraTerm).

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

Hope it helps

geo-rg, 2016-11-21:
Sorry for the late reply. Are there any updates? Does everything work for you?

theGRK, 2016-12-04:
Sorry guys but I'm abroad without my Chameleon, I'll update you in next few weeks.

cyb4bit, 2016-12-19:
@domoarigatosan
Very good tips i just folow the steps after the uprgrading mode: Go to device manager > install driver > choose "have disk" > Select "ChameleonDriver.inf" and now i have the Chameleon fully functional on Tera Term. I use Xp pro sp3 OS. Thanks for your apport.

geo-rg, 2017-04-05:
Since there has been no updates on this issue, I assume that everything works fine now. If not so, please re-open this issue.

bjenky, 2021-07-01:
today i am going to fucking blow my brains out because i couldnt figure this out. this is unreasonably complicated.  i hate this fucking thing and iceman and all of you for not making this at least graspable for the common man. wtf. yall are elitist pos, and i will haunt you all. fuck the world and everything in it. i hate .all. seeya

bjenky, 2021-07-01:
FUCKING HEEEEEELLLLLPPPPPP
BJENKINSPDX@GMAIL.COM
IM TYING A FUCKING NOOSE IM FUCKING LOSING IT
FUCK THIS COMPLICATED BS! ICEMAN FUCKING HELP ME!!!!!!!

bjenky, 2021-07-01:
I HAVE SPENT 1000$ 10000 HRS HALF A HEAD OF HAIR AND 10 SLEEPLESS NIGHTS STRAIGHT TRYING TO GET THIS OR A PROXMARK WORKING AND NOW I WANT TO END  MY LIFE
I HATE THIS SHIT
PLEASE HELP
BJENKINSPDX@GMAIL.COM

Closed 2017-04-05.

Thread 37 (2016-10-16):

Poor reception/transmission

derfloh, 2016-10-16:
I've been playing around with my Hotel Door (seems to be a Messerschmitt Classic 3 in the mifare version) and after countless hours of wondering what magic cards Messerschmitt is using, because the cards are identifying as MF Ultralight, but the Chameleon can't sniff anything or when emulating a MF Ultralight I didn't even see read requests....

It took me quite a while to notice, that I have to hold the Chameleon in a very specific angle in a very specific distance to get some data with sniffing. In emulation mode I saw some traffic, but in 30 minutes waving the Chameleon in various speeds, angles, directions&distances at the door, I managed to open it only once (so I know it _does_ work... but not reproducible).

I also noticed that when I use my usb dongle (scl3711) I have to be careful with the Chameleon as well. It mustn't be too close, or it would not be recognized. And it happens quite often, that a "nfc-list" lists 2 (identical) tags.

So, as the noob I am... I'm wondering if
- That's an issue "by design"? (Laws of Physics are a b*tch?)
- My device is faulty?
- The readers are stupid?

And if that can be improved somehow? (There's a u-fl-r-smt connector.. can it be used out-of-the-box?)

aleksil, 2016-10-17:
I can confirm having the same issues. Using the Mifare Classic Toolkit on my phone (Sony Xperia Z5) I can sometimes read the emulated mifare classic card, but most of the time i just get an infinite loop of "tag lost/new tag" sounds. Sometimes it will read some sectors, but randomly fail to read others.

Proper card readers that only check the UID usually work. Readers that authenticate with the card and read contents have never worked for me.

david-oswald, 2016-10-17:
We've actually tested full card readouts both with several phones and different types of readers and tried to optimize it as much as possible - including the SCL3711. Do you have a look to determine at which step it fails?

derfloh, 2016-10-17:
So, I don't have any problems with the card if I place it correctly (For example I noticed that it works great if i place the 'empty dummy end' of the chameleon directly on the SCL3711, so that the coil is next to the dongle... if i place the middle of the coil/chameleon on the dongle it doesn't work at all)

So, although it's not like with real Tags that I can drop on the dongle in any position as I want, it's ok for me in that use case.
For "real" use cases, like the hotel door it's simply not acceptable (in the sense of I don't want to do it.. not in the blaming sense ;) ) to have to figure out how to place the chameleon to get a result.

I'll check it later, but what I remember from yesterday was the following:

1) 05976 ms < +5976 ms>:CODEC RX         (1   bytes) [26]
2) 05976 ms <    +0 ms>:GENERIC          (0   bytes) []
3) 05976 ms <    +0 ms>:CODEC TX         (2   bytes) [4400]
4) 05976 ms <    +0 ms>:CODEC RX         (2   bytes) [9320]
5) 05976 ms <    +0 ms>:GENERIC          (0   bytes) []
6) ....

If I placed the chameleon correctly, I see the "26" arriving and transmission of the 4400.. Then purely based on luck (or if my hand holding the chameleon hasn't shaken too much) I'll receive the 9320..
Sometimes it goes a couple of steps further but often communication breaks during the first steps..

Could it be that the Door reader (which is battery powered..) is simply "not strong enough"? (Which is probably a stupid question, because there should be specificiations for that in the ISO I guess...?)

derfloh, 2016-10-18:
As a follow up to my observations with a SCL3711:

I've "destroyed" my Ultralight Application by putting the following at the start of MifareUltralightAppProcess:
```
    uint16_t alevel = AntennaLevelGet();
    LogEntry(LOG_INFO_GENERIC,&alevel,sizeof(uint16_t));

    Buffer[0] = NAK_INVALID_ARG;
    return NAK_FRAME_SIZE;

```

And then started to watch the live logs when I issue a nfc-list on the SCL3711:

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

This is pretty much expected... The chameleon was held with it's center ~5cm above the dongle.

If I move the chameleon closer (the following log was from ~1cm) i get surprising results:

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

(I occasionally also see the 'normal 3 times 0x26 blocks' at that distance)

And I've also seen stuff like this:

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

But that's not very common (I would simply ignore it..)
The "0x85 instead of 0x26" is easily reproducible though.

Any clues where to dive into?

david-oswald, 2016-10-19:
Thanks for the data. There is some tradeoffs between good reading range and emulation range in the Chameleon, which Timo can better explain, so he'll get back.

doegox, 2016-10-25:
@derfloh about the emulation problem with the hotel door you mentioned initially, you may check if it gets better now that the fix for issue #46 has been merged.

derfloh, 2016-10-25:
@doegox I haven't tried the new firmware yet, but on Sunday I had a try with one where I merged your PR for #46 . The result was the same, since communication either breaks at REQA or SELECT for me, so HALT isn't an issue there :(

twiddern, 2017-01-26:
Is it now working @derfloh? With #ea9938b a [new firmware](https://github.com/emsec/ChameleonMini/commit/2316aa5ee8f612ec03ff35b48395acb18d8952d8) was released which seems to be working much better :) See also #83

derfloh, 2017-01-28:
@twiddern I couldn't test it yet, since I'm not booking that hotel anymore. At the one where I'm now usually staying the chameleon is working ;)

geo-rg, 2017-02-13:
@derfloh Do you think your problem is solved or should we leave this issue open?

Closed 2017-02-13.

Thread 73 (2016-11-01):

Test  Buttons: FAILED

testtest666, 2016-11-01:
After the boot, the following error, how to solve?（Repeatedly restarted）

===================================
You can also use the following commands:
* Type "showlog" to show the factory test log
* Type "reset" to re-run the self test (you need to power cycle the Chameleon)

Generating Test Report from SRAM:
Test Report for Chameleon-Mini
* FW version: 0.5
* Test      Buttons: FAILED (Took 16584ms) Time exceeded without input on Left Button, time exceeded without input on Right Button.
* Test       Reader: FAILED (Took 529ms) Could not perform a whole ISO14443A select protocol and finally receive a SAK without errors. Used threshold range: 50 - 4095.
* Test         FRAM: PASSED (Took 149ms) Wrote 32768 pseudorandom bytes to FRAM. Successfully read the same bytes from FRAM.
* Test        Fuses: PASSED (Took 1ms) Read the following fuse bytes (the values in brackets have the form <reference value;mask>). 1: 00(00;FF) - 2: BE(BE;63) - 4: F3(F3;1F) - 5: ED(ED;3F).
* Test    Signature: PASSED (Took 0ms) Read the Device ID 1E9746, expected 1E9746.
* Test     USB Enum: PASSED (Took 137ms) USB Device State is ADDRESSED.
* Test          VCC: PASSED (Took 106ms) Measured a VCC of 3330 mV.
* Test      Antenna: PASSED (Took 107ms) Measured the following RSSI values: 12632 mV, 12503 mV, 12468 mV, 12562 mV, 12457 mV.
* Total Testing Time: 17614ms
Your Chameleon will emulate a card with the UID 3D03F2C9.
Sorry. Some test(s) have FAILED, please unplug chameleon, fix errors and re-test.
Welcome to your ChameleonMini! This is test firmware version 0.5.

Sorry. Some test(s) have FAILED, please unplug chameleon, fix errors and re-test.

Type "upgrade" to jump to the bootloader and install new firmware as described on https://github.com/emsec/chameleonmini

dev-zzo, 2016-11-01:
Have you tried the advice it gives you at the very end (flashing the production firmware)? Do buttons work then?

geo-rg, 2016-11-01:
@testtest666 Please tell us what exactly you did. You received your Chameleon and then plugged it in and typed `showlog` and received this test log? Or did you type `reset` and rebooted the Chameleon in between?

emsec, 2016-11-01:
the test firmware expects you to place a card on the antenna, then press both buttons, and then all tests will pass. however, you don't need the test firmware any more (that was for the factory) so please follow the getting started to program the current firmware.

testtest666, 2016-11-02:
Thank you all。

I have updated the firmware to
Version?
Based on the open-source NFC tool ChameleonMini. Https://github.com/emsec/ChameleonMini commit 2005f46

But I have not tested, I do not know if there are any problems.

Where can I download test firmware version 0.5 (has been compiled)?
I would like to test again. Thank you.

geo-rg, 2016-11-02:
There is no possibility to download it. The test firmware was designed so the factory can check whether there are problems with some of the components. You are not supposed to use the test firmware for testing, it was just for the factory.

If you received your Chameleon and after powering it, _only_ the green LED turned on, everything is fine and you can enjoy your Chameleon. If you do not remember, just try to use the Chameleon as a reader (config=iso14443a_reader) and try to use the buttons (type rbutton=? for help).

testtest666, 2016-11-02:
in my impression：
The first time you use Tera Term to connect to Chameleon-mini, all tests are OK.
Once, I test firmware version 0.5,
executed the  “upgrade”  command, nothing has been done. Because there are other things, I left.
come back, I restart the Chameleon-mini. There  Test Buttons: FAILED.

geo-rg, 2016-11-02:
Ok, then everything is fine. I also noticed, that the test report you gave us in your first post states "Generating Test Report from SRAM". If this would have been the factory test, it would have been generated from FRAM. So what happened is that you restarted the test (I don't know how) and left it alone. Thus, the button test and the reader test failed.

Enjoy your Chameleon!

Closed 2016-11-02.

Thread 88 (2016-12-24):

Bootloader gone

hdpro4u, 2016-12-24:
I seem to have botched the bootloader setup, and now i cannot get the .hex back onto the board.  how do i start over from scratch?  Right now, when plugged into USB, i dont get the Chameleon driver, only the ATMEGA in device manager.

.hex on github only says not valid in FLIP.

hdpro4u, 2016-12-24:
little more update....
When i plug in chameleon, i get "ATMEL USB DEVICES" 'ATxmega128a4u' in device manager.
i cannot update to chameleon firmware using the .bat file.  i cannot get out of bootloader mode.

when i run the .bat file, i get
"Checking memory from 0x0 to 0x1FFFF... Emplty.
Chip already blank, to force erase use --force.
Error Reading Line 1.
there was an error with executing this command.  Maybe your chameleon is not in bootloader mode?"

Thanks.

geo-rg, 2017-01-02:
Since no one else has the problem of a broken hex file, I assume that the current hex file is not broken. (To be sure, you could clone the repository and compile it on your own.)

Usually, it should not be possible to delete or alter the bootloader unless you used an external programmer. Is your Chameleon powered by battery while flashing the Firmware? This could cause problems, so please turn off the battery power! Also, only flash the firmware after pressing the right button on power-up.

hdpro4u, 2017-01-05:
Maybe I'm confused as to how to load the .hex. I have done something that yields no lights on the board at all, I assume it is in boot loader mode since it shows up as a device in dev manager. FLIP doesn't recognize it as a valid hex downloaded right off the repository.

Unplugging and powering on via battery with known good voltage yields no lights either.

hdpro4u, 2017-01-07:
How do i go about erasing everything on the chip and starting over with the boot loader and chameleon hex?  in AVR Stuido i can read the chip, but still says it cannot enter boot loader mode.  holding the RBUTTON does not do anything when powering up.  it still loads in windows device manager as an ATMEL Device "ATxMega128A4U".

domoarigatosan, 2017-01-26:
@hdpro4u

I had similar issue initially, till I have found out the solution. Your bootloader is not erase/empty. It's the upgrade.bat unable to identify the bootloader.

Try check on my step-by-step at here:
https://github.com/emsec/ChameleonMini/issues/17

Try activate the ChameleonFirmwareUpgrade.bat (Doesn't matter if you can't see the serial box on TeraTerm).

Now your Chameleon RevG should be upgrading mode.
Once done, close the ChameleonFirmwareUpgrade.bat
Go to device manager > install driver > choose "have disk" > Select "ChameleonDriver.inf"
Try communicate from TeraTerm again.

geo-rg, 2017-02-13:
@hdpro4u Does this solve your problem?

Peterthegreat, 2017-03-04:
@hdpro4u Are you sure you downloaded the file correctly? My guess is that you right clicked and selected the web link to "save as" instead of the file. You must first click on the link, then you right-click on RAW and select save as.

http://i.imgur.com/B0Y9kD7.png

hdpro4u, 2017-03-06:
Peterthegreat is the GREATEST!  That was it... i was saving as at the level of the initial link, and not clicking raw.  followed the process again, and now have the green light!  good work team.

Closed 2017-03-06.

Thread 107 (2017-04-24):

RF carrier, sub-carrier frequency tuning parameters

ogsts, 2017-04-24:
I observe very weak sensitivity between NFC reader and ChameleonMini while in Mifare Ultralight emulation mode. I can read/write successfully ChameleonMini using Android phone though. Same NFC reader works without issues with http://emutag.com. I assume some fine-grained RF carrier, sub-carrier frequencies tuning is required.
Can this be done by adjusting Codec parameters ?

ogsts, 2017-04-24:
Looks like carrier frequency can be adjusted by changing Codec.h:
#define CODEC_CARRIER_FREQ          13560000
and sub-carrier
#define ISO14443A_SUBCARRIER_DIVIDER    16

geo-rg, 2017-04-25:
Hi @ogsts
the Chameleon actually uses the field generated by the reader. If you change ISO14443A_SUBCARRIER_DIVIDER, the subcarrier definitely will have the wrong frequency.

CODEC_CARRIER_FREQ is only used by the reader part of the Chameleon and thus has no effect on the emulation.

If you have trouble with emulation, this could have different reasons: At first, if your Android phone has a metallic case, the reading range is very limited. The Chameleon also tends to emulate not so good in short ranges and better in like 1cm distance to the reader. Both of the things you want to adjust are with 95 % prob not the cause of your errors.

What is the exact type of your NFC reader?

ogsts, 2017-04-25:
Hi @geo-rg

I want to use ChameleonMini with NFC reader which is out of my
control - I dont have any additional information about model.

What I know is that reader accepts Mifare Ultralight
card emulated by http://emutag.com if it is at the distance ~0-3 cm
from reader.

However, ChameleonMini has several advantages over http://emutag.com:

a) fully open source firmware
b) possibility to use ChameleonMini as NFC reader (without use of phone)
   to clone Mifare Ultralight cards

> the Chameleon actually uses the field generated by the reader

I know that in emulation mode ChameleonMini uses reader field.
My assumption was that reader which I use ChameleonMini with
could use carrier frequency which is slightly off from
standard 13.56 MHz but ChameleonMini is sensitive only in
this standard frequency.

When I turn LOGMODE=memory I dont get anything in the log
after use with reader. Not even ATQA. So, I believe issue is
at RF level

geo-rg, 2017-04-26:
Hi @ogsts
> My assumption was that reader which I use ChameleonMini with
could use carrier frequency which is slightly off from
standard 13.56 MHz but ChameleonMini is sensitive only in
this standard frequency.
I think I was not clear enough in my previous comment about this ;) What I meant is: the Chameleon really uses the frequency from your reader.  If it is slightly different, the Chameleon still should recognize the readers request.

OK, so you are doing `logmode=memory` and there is not even a REQA (0x26) or a WUPA (0x52) from the reader? Or does the Chameleon recognize one message (REQA/WUPA) and does not respond? An idea would be to set `logmode=memory` and `config=ISO14443A_SNIFF` and hold this to your reader. Usually, this should detect the readers requests. You could also set `ledred=field_detected` to see, if the Chameleon even recognizes a 13.56 MHz field.

ogsts, 2017-04-28:
Hi @geo-rg
Led function LED_FIELD_DETECTED is really useful. I captured log using CONFIG_ISO14443A_SNIFF (attached). It contains 0x52 for couple of times but otherwise it looks pretty random.
[data.txt](https://github.com/emsec/ChameleonMini/files/964065/data.txt)

geo-rg, 2017-06-23:
Hi @ogsts
last week we have made an update within the ISO 14443 A emulation codec, just try again with the current "latest" firmware. Does this solve your problem?

geo-rg, 2017-07-26:
I assume your problem is solved. Please simply re-open this issue if not so.

Closed 2017-07-26.

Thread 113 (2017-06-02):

Chameleon memory problem

Peterthegreat, 2017-06-02:
Hello,
So this is a pretty annoying issue. The memory of the IC somehow gets corrupted (mostly if you power it off during startup). The ChameleonMini is not responding - the LEDs power off and not seen on USB. To reproduce the problem, (optional? load some data to be emulated) toggle the power switch fast a couple of times.

I am uploading the boot-loader with an USBASP, using this config for the IC:

part parent ".xmega"
    id      = "x128a4u";
    desc    = "ATxmega128A4U";
    signature   = 0x1e 0x97 0x46;
//    usbpid  = 0x2fde;

    memory "eeprom"
        size        = 0x800;
        offset      = 0x8c0000;
        page_size   = 0x20;
        readsize    = 0x100;
    ;

    memory "application"
        size        = 0x20000;
        offset      = 0x800000;
        page_size   = 0x100;
        readsize    = 0x100;
    ;

    memory "apptable"
        size        = 0x1000;
        offset      = 0x81f000;
        page_size   = 0x100;
        readsize    = 0x100;
    ;

    memory "boot"
        size        = 0x00002000;
        offset      = 0x00820000;
        page_size   = 0x100;
        readsize    = 0x100;
    ;

    memory "flash"
        size        = 0x22000;
        offset      = 0x800000;
        page_size   = 0x100;
        readsize    = 0x100;
    ;

    memory "usersig"
        size        = 0x100;
        offset      = 0x8e0400;
        page_size   = 0x100;
        readsize    = 0x100;
    ;
;
`
Then I upload the code via USB with "ChameleonFirmwareUpgrade.bat"

I don't know sure if the problem is in the flash, in the EEPROM or somewhere else, but one time while having this issue the Chameleon got into boot-loader mode and I was able to rewrite the memory. First I uploaded only the EEPROM.
```
"%~dp0dfu-programmer.exe" atxmega128a4u flash-eeprom "%~dp0Chameleon-Mini.eep" --force
"%~dp0dfu-programmer.exe" atxmega128a4u launch
```
 This did not made any difference, the LEDs where still off, and the Chameleon was still in boot-loader mode. Then I uploaded only the flash, and the result was the same.

To make it work, I have to erase the IC and rewrite the boot-loader and the flash+EEPROM

Things that I have tried:

- different firmware "ChameleonMini RevG 161024 using LDFA 151115 compiled with AVR-GCC 4.9.2"
  (but the same boot-loader version bootloader-atxmega128a4u-104-PA6-SPM)
- replace C1 and C2 with higher values (10u)
- replace the IC with a new one

Attached are the eeprom and flash of the IC when this issue happens

[dead-FLASH.hex.txt](https://github.com/emsec/ChameleonMini/files/1048440/dead-FLASH.hex.txt)
[dead-EEPROM.eep.txt](https://github.com/emsec/ChameleonMini/files/1048441/dead-EEPROM.eep.txt)

My guess is that my power on switch has imperfect contacts and sometimes an on-off toggle is happening while powering on the ChameleonMini. I will replace the switch but it doesn't guarantee that it won't happen again.

Peterthegreat, 2017-06-02:
Also, when this happens, there is no 13.56mhz signal on the oscilator

Peterthegreat, 2017-06-06:
The problem appeared again, this time after using chamlog.py. First the chamlog did not respond, so i did a restart. Then the PC could not see the Chameleon on USB. After another restart, the device was in bootloader mode. I took the chance and uploaded the EEPROM, without erasing the chip first.
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

This made the device disappear from USB, but after pressing RBTN, it was back to bootloader mode.

Then I uploaded the .hex, again without an initial erase:
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

And then with --force argument:
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

And the device was seen via USB. I will now reproduce the problem and will try to upload the flash memory first (.hex)

Peterthegreat, 2017-06-06:
Ok, so that writing without erasing the chip did not lasted long. While trying to reproduce the problem with the on/off toggle, the device was not recognize anymore (VID&PID)
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

After a few more attempts, the correct com was shown and this is what the gui shows
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

After resetting the comunication, the device is unrecognized again.

Peterthegreat, 2017-06-13:
./avrdude -C avrdude.conf -c usbasp -p x128a4u -U flash:v:bootloader-atxmega128a4u-104-PA6-SPM.hex:i -E noreset

avrdude: AVR device initialized and ready to accept instructions

Reading | ################################################## | 100% 0.01s

avrdude: Device signature = 0x1e9746
avrdude: NOTE: Programmer supports page erase for Xmega devices.
         Each page will be erased before programming it, but no chip erase is performed.
         To disable page erases, specify the -D option; for a chip-erase, use the -e option.
avrdude: verifying flash memory against bootloader-atxmega128a4u-104-PA6-SPM.hex:
avrdude: load data flash data from input file bootloader-atxmega128a4u-104-PA6-SPM.hex:
avrdude: input file bootloader-atxmega128a4u-104-PA6-SPM.hex contains 139252 bytes
avrdude: reading on-chip flash data:

Reading | ################################################   | 95% 1.25savrdude: paged_load failed
avr_read(): error reading address 0x20000
    read operation not supported for memory "flash"
avrdude: failed to read all of flash memory, rc=-2

Obvious, the eeprom/flash verify will fail since I upload some data to the slots.

geo-rg, 2017-06-23:
Sorry for the late reply.
We really could not reproduce your problem. Have you tried to replace your power switch? However, I cannot imagine how a bad contact on the power switch would cause memory corruptions within the flash memory. Have you gained any new information on your problem?

Peterthegreat, 2017-06-23:
No worries.
Do you think that my method of programming the IC is ok? I am using a patched fw for my USBASP that allows me to write to Xmega cips, but I am using it only to upload the bootloader, and avrdude verificiation step shows that is done correctly. The UpdateFirmware.bat uses USB and also has an erase command before writing the flash.

Peterthegreat, 2017-06-23:
I did not changed the power switch yet. Meanwhile, I will try my best to find exactly why this is happening, so you can reproduce the problem. Thank you for the support

Peterthegreat, 2017-06-27:
Just changed the power switch and I still get the random "death" of the board. Since I am the only one having this problem, I will recheck the values from the BoM

skuep, 2017-06-27:
Can you give the microcontrollers fuse settings? Maybe the brown out detector is not correctly configured.

Peterthegreat, 2017-06-27:
avrdude -v option doesn't show the fuse bits, I will have to get them some other way. I did not changed the default fuse settings

Peterthegreat, 2017-06-27:
I am not sure this is correct, but here is my attempt:
fuse0: 0xff
fuse1: 0x0
fuse2: 0xff
fuse4: 0xfe
fuse5: 0xff

Peterthegreat, 2017-06-27:
Rechecked the BoM and everything looks fine (I have an equivalent for D5). Did a reflow on the left part of the board, but the problem is still there. Next step I will try a bigger value for C8 and C9 (input and output of the 3.3 voltage regulator)

geo-rg, 2017-06-30:
@Peterthegreat The Fuses you have set are not correct. Just try these:
fuse1: 0x00
fuse2: 0xBE
fuse4: 0xF3
fuse5: 0xED

Peterthegreat, 2017-06-30:
I would gladly try those fuse settings, but first, can you please confirm I got the memory address right? Here is my avrdude config:

`
memory "fuse0"
        size		= 1;
        offset		= 0x8f0020;
    ;

    memory "fuse1"
        size		= 1;
        offset		= 0x8f0021;
    ;

    memory "fuse2"
        size		= 1;
        offset		= 0x8f0022;
    ;

    memory "fuse4"
        size		= 1;
        offset		= 0x8f0024;
    ;

    memory "fuse5"
        size		= 1;
        offset		= 0x8f0025;
    ;`

Peterthegreat, 2017-06-30:
Forgot to post an update. Changed Q1 and got bigger values for C8 and C9, but did not solved anything, except a slightly better read from my phone's NFC . Now I uploaded the fuse bit configuration. Will post the results

Peterthegreat, 2017-07-01:
That was it! No idea how the fuse bits got changed.. Maybe they were wrong form the start. I got the problem a long time ago, but only recent had time to play more intensively with the chameleon.

Thank you guys, now I can focus on closing the other issues.

Closed 2017-07-01.

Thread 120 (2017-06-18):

RevG Board Not Recognized by Computer

ekurt1, 2017-06-18:
I only just discovered this issue recently when attempting to update the firmware, but my ChameleonMini RevG is not being recognized by my computer over USB (in Windows 10 and Ubuntu 16.04). Usually, it is assigned to COM4 in Windows, but I keep getting an error of an "unrecognized USB device." I reinstalled all drivers, and after several restarts, the card is still not recognized under the normal or bootloader modes.

Searching through previous issues, this may be related to the memory corruption issue. However, my ChameleonMini is working fine apart from the terminal connection to program it (I can toggle through my already programmed slots, and I can read/write to the slots from an NFC writer), so I am not sure what the issue could be. The board seems fine physically, so any help in pin-pointing the problem would be appreciated.

The last time I had the board connected to the computer was about 2 months ago, updating to the MFClassic_patch branch, since I was not having any luck in getting the card recognized by a specific  reader.

geo-rg, 2017-06-23:
Hi @ekurt1
first of all: The MFClassic_patch branch has been merged to the master branch and there also have been some bug fixes within the MF Classic emulation.

Regarding your problem: Since your Chameleon works fine, I cannot imagine that the problem is on the Chameleon firmware or hardware. Can you please do the following steps under Ubuntu:
1. Turn off the power switch of your Chameleon
2. Connect the Chameleon to your PC.
3. Type `dmesg | tail -n 20` in a terminal and print the output here in the issue.

Which program are you using within ubuntu to connect with the Chameleon?

ekurt1, 2017-06-26:
My primary way of connecting to the Chameleon had been on my Windows system, using TeraTerm and then the GUI-based application. I had never used Ubuntu to work with the device until I realized that it was not connecting on Windows, but I tried to use the socat method in the terminal to connect (but to no avail).

As for the terminal output (cut it down to just the USB activity):

ekurt@myLinux:~$ dmesg | tail -n 20
[ 3137.154548] usb 3-3: new full-speed USB device number 9 using xhci_hcd
[ 3137.266593] usb 3-3: device descriptor read/64, error -71
[ 3137.482594] usb 3-3: device descriptor read/64, error -71
[ 3137.698584] usb 3-3: new full-speed USB device number 10 using xhci_hcd
[ 3137.810597] usb 3-3: device descriptor read/64, error -71
[ 3138.027366] usb 3-3: device descriptor read/64, error -71
[ 3138.242493] usb 3-3: new full-speed USB device number 11 using xhci_hcd
[ 3138.242621] usb 3-3: Device not responding to setup address.
[ 3138.446748] usb 3-3: Device not responding to setup address.

Peterthegreat, 2017-06-26:
@ekurt1 Do you have a programmer that supports the atxmega family? I recommend an erase and re-flashing the bootloader

ekurt1, 2017-06-26:
I have a USBASP (via my Arduino), which can be modified to work with PDI to program the chip. However, can this be done with the chip still soldered to the Chameleon board, or will I have to unsolder the chip completely?

Peterthegreat, 2017-06-26:
You have breakout for VCC, GND, DATA and CLOCK. There is no need to remove the chip.

Endres, 2017-06-26:
As @Peterthegreat said, you just need to simply solder an 2x6 0.1" header (or bend it a bit to contact nicely even without soldering) on the edge where the PDI-pins are broken out anyway. There should be no need to cut traces or even remove the chip.

Peterthegreat, 2017-06-26:
I am using a patched USBASP and a modified AVR ISP adapter
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

geo-rg, 2017-07-05:
Any news on this, @ekurt1?

ekurt1, 2017-07-05:
Unfortunately no. I have been having trouble with trying to connect to the board to flash the bootloader. I patched my USBasp using two different methods, and despite the wiring modifications being correct, I have not been able to get avrdude to recognize the xmega. I took a break from it over the weekend, but I will take a look at it more this week.

Peterthegreat, 2017-07-05:
I followed [this tutorial for the USBASP and avrdude patch](http://szulat.blogspot.ro/2012/08/atxmega-programmer-for-050.html), and for the avrdude.conf you can take a look at issue #113

geo-rg, 2017-07-06:
@ekurt1 To be honest I cannot imagine a way how your bootloader has been altered as this usually is only possible by using a USBASP or by a bad firmware. However, the latter one can not be the case if you only used our firmware (since nobody else got this problem) and if you are sure you haven't used an ASP by accident ;) - then I think this could be a problem with your PC. Can you try flashing with another PC?

ekurt1, 2017-07-06:
I forgot to mention in my original post, but I have tried to connect the board to several computers (Windows and Linux), and none could recognize the device, even with the correct drivers installed. The Chameleon does everything as expected when connecting or going into bootloader mode (based on the LEDs), but it will just not be recognized correctly. Could the issue be something wrong with the USB circuit? I have not tried a reflow of the board as I am not sure if that would cause more harm.

I am also still not able to get the USBasp to communicate with the board, and I had followed both of the links from Peterthegreat previously, so the USBasp works (used it to program another chip as proof) and it has the correct conf for the xmega. So could the issue be something wrong with the xmega communication in general? However, I am not sure how to go about resolving that.

ekurt1, 2017-07-07:
Actually, I spoke too soon on the board's status. The antenna no longer works, or there is just no RFID signal coming from it. The LEDs light as they should, but I am not getting any signal from the antenna. It is possible the USBasp further messed something up, even though it could not recognize the chip.

Peterthegreat, 2017-07-07:
@ekurt1 If the USBASP with avrdude did not recognized the chip (and you also had the wiring correct), there should be no change from the previous state. How can you tell the antenna no longer works? You tried a reader with the chameleon and it is not longer recognized?

ekurt1, 2017-07-07:
Yes. I tried the chameleon with a reader since it had been working up until now, just not communicating over USB, but it is no longer recognized by the reader. I am not sure what the cause of this could be, but it is a separate issue from the USB issue.

Of note, I did have to resolder the battery case a few days ago since that fell off, and this would have been the first time I tried to use the chameleon after that, so something may have been damaged on the board.

Peterthegreat, 2017-07-07:
What was the response from avrdude when you tried to connect ? Can you post pictures with the terminal?

ekurt1, 2017-07-07:
I will post the terminal information once I return from work. Won't be for few more hours though.

ekurt1, 2017-07-07:
Here is the output from avrdude:

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

skuep, 2017-07-07:
What directly pops into my mind is that the sck period is too low. This results in a SPI frequency that is too high and thus the SPI programming data transfer does not work. The SPI frequency has to be smaller than 1/4th of the ATxmega's clock frequency. Try setting the sck period to 10µs for example. If I remember correctly you have to use `-B 10`

Peterthegreat, 2017-07-08:
also, try adding -E noreset to the command line

ekurt1, 2017-07-08:
Thanks for the ideas. Neither had worked, that was until I discovered that putting physical pressure on the board caused it to work. Only when I press down on the xmega chip itself did the RFID signal work and the computer recognize the board. In the end, it seems the issue was the physical connection of the components, so I think I will need to reflow the board.

For now, any advice on reflowing the board to reconnect the many solder points?

Peterthegreat, 2017-07-09:
Take a look [at this video](https://youtu.be/b9FC9fAlfQE?t=19m17s). Clean and tin the soldering iron first. You will need to apply a lot of flux and use a good solder (60/40 or 63/37 Sn-Pb solder). Also use solder wick for the solder excess.

ekurt1, 2017-07-09:
Would it be better to use a solder reflow oven, since I don't not know which connections are bad? I use the oven to normally repair motherboards and GPUs, but I don't know how a small board like the Chameleon would respond with it.

I can also just go through each pin manually to resolder, but this just seems to be more error-prone with the many small components.

Peterthegreat, 2017-07-14:
If you have soldering paste and you can dispense it properly to the terminals, you can go for the reflow oven (especially if you have done this before).

Whichever method you choose, always do a visual inspection for the soldering.

ekurt1, 2017-07-14:
I forgot to post my update, but since USB seemed to be the only issue, I resoldered Pins 25-27 (PD5-7) individually on the xmega, since they correspond to the USB controls.  Since then, I have had no issue in getting a consistent connection from the board via USB, and I was able to update the firmware to the latest version.  For now, with the board working from the minimal repair, I will save a full reflow for when more extensive repairs are necessary.

Thanks again for everyone's help on the issue.

Closed 2017-07-14.

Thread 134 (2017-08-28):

External antenna for emulation little tag

etmatrix, 2017-08-28:
Can I use an external antenna and replace PCB? I need emulate a mifare with a diamter about 2cm (0.79 inches), ChameleonMini is a good choice for that scope?

geo-rg, 2017-08-29:
Hi @etmatrix,
adjusting the antenna is very complex and we can give no guarantees that emulation or any other functionality will work after your changes. However, it is possible that it could work.

kaliginium, 2018-01-24:
Hi,

 do you know what type is exactly connector on chameleon board?

Endres, 2018-01-24:
It is a standard U.FL plug, so you will need a U.FL jack (usually mounted on a pigtail-style-cable) for connecting to the antenna signal. It is the same type of plug used in modern laptop computers for the Wi-Fi antenna.

kaliginium, 2018-01-31:
Thank you,

 I order connector, make antenna a try if antenna is working on proxmark. Then I connect antenna to chameleon and it did not working. I there needed to somehow switch which antenna either internal oe external should be used?

geo-rg, 2018-02-02:
Hi @kaliginium
it is not trivial / highliy difficult to use another antenna. Note that the whole circuitry is adjusted to the standard antenna. Any small change on the antenna may change the signal arbitrarily and thus may break functionality.

kaliginium, 2018-02-09:
I note that. I hope I can calculate that, but there is the trouble, that I do not know the circuit. I have trouble, that my application is able to comunicate with chameleon only in distance cca 9-13 cm from reader. I rewrite FW to log me, what is happen and chameleon response in standard way. But on standard card is reader responsible only in distance 2-3 cm. So maybe I am not able to emulate a card. Thus I am about to create external antenna to maybe solve this problem.

geo-rg, 2018-03-22:
OK, @kaliginium, let us know if you have success, I hope you can solve your problem. However, do you have any remaining (and related) questions? If so, please re-open this issue. Same for @etmatrix.

Closed 2018-03-22.

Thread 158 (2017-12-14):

no device present

peseta3, 2017-12-14:
Hallo together,
I am a Newbee,  I have the follow problem.
I make all I have to do with the getting started page

[http://rawgit.com/emsec/ChameleonMini/master/Doc/Doxygen/html/Page_GettingStarted.html](url)

And I get with win10 the Massage

> dfu-programmer: no device present.
> There was an error with executing this command. Maybe your ChameleonMini is not in bootloader mode?
>
what can I do with this?

gtpy, 2017-12-14:
@peseta3 Is the LED at the chameleon off if connected it via USB in bootloader mode? - Run as administrator?

>Make sure the Chameleon is switched off (power switch on the side is in the position OFF). Now, hold >down the right button (RBUTTON) and keep it pressed while connecting the Chameleon to a PC via a >USB cable.

peseta3, 2017-12-14:
Yes the LED is off.
I press the black right Bottum and make an usb conection the the cable, together.

Yes I run it with the admin.

gtpy, 2017-12-14:
@peseta3
Question: is it an original from Kasper&Oswald (Rev.G) or chameleon revE rebooted like from iceman1001/ChameleonMini-rebooted
Because you opened one issue here and in iceman1001/ChameleonMini-rebooted
Black button sounds like the RevE Rebooted
If it is so, then please close this issue and let the other one open.

peseta3, 2017-12-14:
ah ok
Yes it is so as you say.
But I get this page from the buyer Homepage with link to link to link bla bla

Ok You sa I am not right here.
thank you for all fast, very fast post.

peseta3, 2017-12-14:
hallo again,
iceman says I have to go to you
hm
and now

iceman1001, 2017-12-14:
Well, I say I don't offer support.  That project just got the firmware to compile...
Basic operations should be covered in the wiki on this repo.

peseta3, 2017-12-14:
Hmm I don`t understand it, the wiki?

I can not open it.

Mist my english is not so well.

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

geo-rg, 2017-12-19:
Hi @peseta3
since your Chameleon is not a genuine one from us but a remake, we cannot give support, especially for the hardware. Your problem looks like a hardware problem, or maybe these Chameleons have another way to enter the bootloader? Did you get any description of how to do firmware upgrades? Anyways, I'm afraid, we cannot give support for this.

peseta3, 2017-12-19:
hmm
but the Company write on her Page that this Page is right for Questions and so on
please have a lock for this
[https://lab401.com/collections/rfid-tools/products/chameleon-mini-reve-rebooted](url)
you can see it under
Community / Usage / Tutorial Resources
[https://github.com/emsec/ChameleonMini/wiki](url)

What can you tell me about that?

geo-rg, 2017-12-19:
Again I'm afraid, but we do not have any knowledge about the product that you have bought. The vendor used this open source project as a base. The have changed many things on hardware and since we do not know anything about what they did exactly, we assume they may also have changed the bootloader software. Anyways, to be clear: **we cannot give support for products that we are not related to**.

gtpy, 2017-12-19:
Hi @peseta3

 The one from Lab401 is maybe own developed from them and also different/modified in the coding_

I never owned a Rev.E neither original nor clone.
But I think if someone of the community have time and money to check it out, they’ll help and contribute with some tips and descriptions.
I can not do it until the new year (maybe I’ll buy the same and test and try to contribute for it)

Maybe you have already seen, that we (some people from the community) are about to expand the repository in the iceman-fork -> like descriptions and some guidelines for this device (see your other issue iceman1001/ChameleonMini-rebooted#9
You are cordially invited to contribute to it, with informations or other help.

Have you already contacted the Lab401 team about you problem or did you get the driver installed and the device running? (issue iceman1001/ChameleonMini-rebooted#9)

peseta3, 2017-12-19:
Hi geo-rg
but why can Lab401 link it to emsec when nobody knows about that????

peseta3, 2017-12-19:
Hallo gtpy,

The company Lab 401 is not the fast one with reanswere for my problems.
I can conect it with win10 with thair GUI-Software.
But in the moment I cannot test it in realtime.
I write them with a discription for firmeware update, but I didn`t heard something from them.

iceman1001, 2017-12-19:
Since the Lab401 revE rebooted version is based upon offical revE,  but it had a locked down firmware and a custom GUI.    As mentioned several times before,  I got the source code for the lockdown firmware and made it open-source again and some people are trying to figure out what it does and not.
..and how to fix the obivous bugs and add all fixes from this repo..

All we got at the moment is the idea that the normal setting up / flashing instructions from this offical repo should work.  That is why everyone pointing back to this wiki here.   Noone knows, not the retailer (lab401) and the manufacturer just say "use the gui".  As @gtpy @geo-rg  et al are saying,  since its not a offical chameleon mini revE,   this repo can't help you either.

The work with filling the wiki at iceman-fork, has begun.  Its not a fast job not do anyone claim to give support,  its a voluntered one.  I understand its frustrating thing to not be able to use your new gadget but this is how it is right now.

peseta3, 2017-12-19:
ok danke iceman

peseta3, 2017-12-19:
@iceman1001
corespodenz with Lab401

•	You can always flash back to the firmware we provide
•	You can always flash to whichever firmware you want
You will need the AVRISP MKII hardware to do any flashing.
https://lab401.com/collections/flashing-tools/products/avrisp-mkii?variant=5004374835231

You would use the software AVR Studio to do your flashing. There are many tutorials online, and it is very easy to do.
A good reference point is here: http://www.atmel.com/webdoc/avrispmkii/avrispmkii.intro_connecting.html

peseta3, 2017-12-19:
@iceman1001

I am a absolute Newbee for that.
I don´t know what I do, or I have to do.
Iceman, do you speak german?
maybe I can speak  per phone or so a few minutes if you want and have time.
thanks a lot

iceman1001, 2017-12-19:
Sorry, I have too little time left as it is.

peseta3, 2017-12-19:
@iceman1001
hmm ok
thank you for all

gtpy, 2017-12-19:
@peseta3 how can I contact you? Mail? IRC? Signal?
We can write in German and I can try to help you with the first steps.

peseta3, 2017-12-19:
great
chameleonatmtrackdotorg

iceman1001, 2017-12-19:
Some great succes tonite,  the firmware compiles and we figured out how to flash the device with it.
Finally bugfixes and enhancements are available!

Closed 2017-12-14.

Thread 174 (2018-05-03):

Broken USB Connector (Please help fix it!)

maxieds, 2018-05-03:
Good morning. I have been testing out my [Android app](https://github.com/maxieds/ChameleonMiniLiveDebugger) and adding some nice new features to it. But before I can get them all working, the microusb connector broke off of the board (pretty flimsy to begin with: see the first image). Now it looks like in there are only three connections broken off and I noticed in the second image that there are three leads that are easily solderable. Can someone confirm / instruct me on which raw wires from a cut up microusb cable I can attach to these pads to get my Chameleon working again? Thank you very much!

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

Peterthegreat, 2018-05-03:
Hello @maxieds
Didn't tried your app yet, but i'm looking forward to do that. Great work btw!

It looks like the pads are not peeled off. Put some solder on the pins then carefully clean it with solder wick. If the solder sticks to the pad, you're all good!

So, if the connector is intact, I would recommend to re-solder it. Use a lot of flux (e.g B-223) and high temperature 300 degrees on the cleaned soldering iron. Don't be afraid to take your time for each USB pin (about 5-7 seconds per pin) unless it feels like the pads are peeling off the PCB (in this case, reduce the temperature or solder the pin faster.

Good luck!

maxieds, 2018-05-03:
My soldering skills are very unpracticed and I'm working with an old iron from Radio Shack. Will it work to solder a pinned out USB cable to the big pads with lots of solder already on them? I know I can get that attached.

P.S. Since my Chameleon is broken until this weekend, I haven't been able to verify that the code improvements work with the board (just basic testing without USB on my dev phone). Would you mind testing out the new beta version [here (signed APK not yet on Play Store)](https://github.com/maxieds/ChameleonMiniLiveDebugger/releases/tag/0.3.7-free), especially the DUMP_MFU printing and cloning features?

ceres-c, 2018-05-03:
You might need some flux, just in case you end up connecting 2 pins. If you're going to wire the usb to pads it shouldn't be needed, as it's easy to do them properly at first try

Peterthegreat, 2018-05-04:
> Will it work to solder a pinned out USB cable to the big pads with lots of solder already on them

If you want to go with that option, it's very recommended to glue the usb cable to the PCB with a glue gun. This way, you won't stress the PCB pads and end up breaking them.

> Would you mind testing out the new beta version here (signed APK not yet on Play Store), especially the DUMP_MFU printing and cloning features?

If I get the old firmware working, I would gladly test it. Hope I can find some time this weekend.

maxieds, 2018-05-07:
I'm still trying to get my hands on a working soldering iron. Hopefully I will be able to get one tomorrow. Please see [this issue](https://github.com/maxieds/ChameleonMiniLiveDebugger/issues/10) in the meantime. If anyone would be kind enough to check that the latest beta release of my app is working correctly, then I can release it to production. I'd really appreciate the help testing!

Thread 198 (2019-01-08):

Not Able to Transmit

herrmanns, 2019-01-08:
Hi, I have the Cameleon mini revG nad it works like charm except the writing/clone mode. It seems everything which has to do with transmitting from device to some reader doesnt work.
when i hold it on to a reader nohting happens. i tried to flash firmware which didnt make a difference.
I got the revG 180912. any help appreciated.

gtpy, 2019-01-08:
Can you give a bit more input.
Which type of config you are using?
Type of Reader?

herrmanns, 2019-01-08:
i tried to read with proxmark3rdv2 also with rdv4. currently i tried it with an acs acr122 reader.
not one card emulation mode works with chameleon.
lets say i set mode to MF_CLASSIC_1K and UID BB9944AA and hold it to any of the reader it just act like nothings there. really odd. i had the chameleon in a box for some months and it was working like charm. but now i got this problem. i have no clue what happened to it.

geo-rg, 2019-01-09:
Hi @herrmanns,
did you buy your Chameleon from Kasper & Oswald or a remake from another vendor? Please note, that some of the remakes do not work well and we cannot give support for this since we do not know any changes they made in the internals.

However, if you bought your ChameleonMini from Kasper & Oswald: Can you please set `logmode=memory`, then `config=MF_CLASSIC_1k`, then hold the Chameleon to the acr122 and run `nfc-list` from libnfc. Then download the log via `logdownload` or with the chamlog tool and finally decode the log with the chamlog tool (if you need any help for these last steps, I can also give you more detailed instructions). Then, post the log here, so we can see what goes on.

herrmanns, 2019-01-09:
yes it is the original from kasper n oswald.
hm thats exactly the problem. no reader could read anything because chameleon is not transmitting at all (or the signal is so weak for some reason that no reader could react).
the antenna and also the antenna connection seems to be fine. because when i turn the chameleon to act like a reader with mode ISO14443A_READER then there is no problem at all. i could hold the card 3 - 5 cm away and chameleon is reading with out any trouble. is there any other firmware i could try (newer)?
--> version?
101:OK WITH TEXT
ChameleonMini RevG 180912 using LUFA 151115 compiled with AVR-GCC 5.4.0. Based on the open-source NFC tool ChameleonMini. https://github.com/emsec/ChameleonMini commit 10144f1

ceres-c, 2019-01-09:
Hi,
I had a similarly curious problem some time ago and it was a PEBKAC error. I had placed the reader on my mouse mat and, for the life of me, couldn't get the chameleon to respond in any way. As it turns out, my mouse mat is made of aluminium, but I couldn't figure it out until I put my hand on it.

I am not saying this is your case, but have you tried to read the chameleon with you cell phone moving away from your current setup?

geo-rg, 2019-01-09:
Hi @herrmanns,
your firmware is up to date. Please set `ledred=codec_rx` and re-try. If the red LED blinks when you hold the Chameleon to the reader, it definitely gets some request (there is no information whether this request is understood correctly, however). As a next step, you could set `ledred=codec_tx`, which would blink, if the Chameleon even responds. In any way it would be useful if you could enable the log and post the decoded log here.

herrmanns, 2019-01-09:
thats the codec_tx log:
https://pastebin.com/VfbWTtCu

thats the codec_rx log:
https://pastebin.com/RF8sfdpv

btw thank you so much for helping me. i m really lost.

geo-rg, 2019-01-09:
Hi @herrmanns,
in both cases, the Chameleon receives and decodes correctly the reader's request and also sends an answer that the reader assumedly does not understand. Please try different setups. Maybe it is really a problem like @ceres-c explained. Have you tried reading the Chameleon with a smartphone?

herrmanns, 2019-01-09:
thats codec_tx first row and second row is rx again but this time i used pm3rdv4 as a reader. hf 14a read.
https://pastebin.com/x2MuzEsy
https://pastebin.com/76VQ4tDu

i was also on the "public real live test reader" and nothing detected. it is just quiet. i coul hold dirty toilet paper on it and i would get the same result (almost) :) .

it is terrible i like this device!

geo-rg, 2019-01-28:
Hi @herrmanns,
since you posted on #196, I assume you solved the problem? If not so, please contact chameleon@kasper-oswald.de and we'll find a way to repair or replace your Chameleon.

herrmanns, 2019-01-30:
yep, problem solved. it was the hardware. a dry solder joint. an extremly rare issue for a chameleon which is a fantastic product... but in general not completely impossible.
my other units running smoothly. the chameleon guys fixed it. thx for that btw !  :D

magicbugpatrol, 2019-11-06:
I have a similar problem. Emulation didn't work.
Reader work.
Tested:
ledred=codec_rx
ledred=codec_tx
How to test further here?
Thanks.

fptrs, 2019-11-08:
Hi @magicbugpatrol,
can you describe your setup (the reader you use, configuration on your chameleon, ...) and provide the chameleon log?

magicbugpatrol, 2019-11-09:
Hi @fptrs,

configuration:
`config=MF_CLASSIC_4K_7B`
`100:OK`
`uid=01020304050607`
`100:OK`
`uid?`
`101:OK WITH TEXT`
`01020304050607`

I use my phone as a reader.
My phone read with NXP taginfo my original classic cards but not the chameleon.
If I configure the chameleon setting to reader it can read the UID of the original card.

With above configuration and
with `ledred=codec_rx` and `ledred=codec_tx`setting the red LED flashes.

Set logmode to memory and get the chameleon log with chamlog.py
https://pastebin.com/6en34Nvj

fptrs, 2019-11-11:
Hi @magicbugpatrol,
in the log you can see that the Chameleon answers with the ATQA to a REQA, so far so good. But afterwards it does not receive a valid command (e.g. SELECT_CL1). Can you try to use an additional reader and provide the corresponding log as well?

magicbugpatrol, 2019-11-11:
Hi @fptrs,
Thanks for the reply.
I was able to borrow an ACR reader from a colleague.
https://pastebin.com/RR3nRFAE
Don't get better results.
Are there other ways to test the functionality?

fptrs, 2019-11-11:
Hi @magicbugpatrol,
sounds like a hardware problem. Where did you order your Chameleon?

magicbugpatrol, 2019-11-11:
Hi @fptrs,
I bought it at Kasper & Oswald (their web shop)
It's been over a year, though.

fptrs, 2019-11-18:
Hi @magicbugpatrol,
since a hardware problem is very unlikely, can tell me which firmware you are using and what the "version?" command answers?

magicbugpatrol, 2019-11-19:
Hi @fptrs,
Now I use the latest firmware.
No change to previous version.
`version?
101:OK WITH TEXT
ChameleonMini RevG 191119 using LUFA 151115 compiled with AVR-GCC 5.4.0. Based on the open-source NFC tool Chameleon
Mini. https://github.com/emsec/ChameleonMini commit a35610f
`

Same problem.

Configuration as reader works:

`setting=2`
`100:OK`
`config=ISO14443A_READER`
`100:OK`
`getuid`
`101:OK WITH TEXT`
`00DDDD1B`
`identify`
`101:OK WITH TEXT`
`MIFARE Classic 1k`
`ATQA:   0400`
`UID:    00DDDD1B`
`SAK:    08`

magicbugpatrol, 2019-12-03:
Thanks. Was fixed by Kasper & Oswald.

Closed 2019-01-28.

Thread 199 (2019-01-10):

Communication problem with chameleon

viertel, 2019-01-10:
Hello Together,

I have flashed the chameleon with respect to this tutorial: https://rawgit.com/emsec/ChameleonMini/master/Doc/Doxygen/html/_page__getting_started.html
Everything seems to work fine. The Chameleon is found into the DeviceManager as "Serial USB-Device (COM7). Then I used TeraTerm to connect to the Chameleon but always the error: "Cannot open COM7 (0x00000079" occurs.

My os is Windows 10 (64bit).

I tried different settings:
Different USB ports, changed the power button from on to off etc.

I have no further ideas why it dont work. Please help me.

Best regards,
viertel

geo-rg, 2019-01-11:
Have you installed the drivers as stated in the [getting started](https://rawgit.com/emsec/ChameleonMini/master/Doc/Doxygen/html/_page__getting_started.html)?

viertel, 2019-01-11:
Hello, thank you for your reply.
Yes I have right clicked the "atmel_usb_dfu.inf" file and clicked install. The Installation was acknowledged successfully.

Greeetings
viertel

geo-rg, 2019-01-11:
Hi @viertel
I am usually not working with Windows but I think the Chameleon should show up as Chameleon Mini in the device manager and not as "Serial USB-Device". Can someone who uses Windows confirm this?

herrmanns, 2019-01-15:
Yes that is correct. It should show something like ChameleonMini Virtual Serial Port (COMX)

jan1702, 2019-01-16:
Hi,
I have a problem with the chameleon mini rev G.
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.

What can i do to fix this?
I tried to upload new firmware 3 times.
May someone has an idea.
Thanks

geo-rg, 2019-01-16:
Hi @jan1702, I opened a new issue #202 for you, since your problem does not refer to this issue.

viertel, 2019-01-18:
Hello toghter,  okay thank you for your feedback. I tried to install the driver multiple times, but in the windows device manager of windows i didn't get something like ChameleonMini Virtual Serial Port (COMX). Any other ideas? Maybe i will try it on linux.
Greetings Fabien

herrmanns, 2019-01-19:
Have you possibly some driver signing issue? (i am not sure if it was proxmark3 or chameleon).
Just in case ... you can try to switch off driver signing. there are several ways to do it but IMHO the "advanced boot version" is the best one to choose.
https://www.howtogeek.com/167723/how-to-disable-driver-signature-verification-on-64-bit-windows-8.1-so-that-you-can-install-unsigned-drivers/
it is only an idea.
I guess you already tried the manual installation of a driver. not automatic.  check this video from minute 1:50
https://www.youtube.com/watch?v=S97hJsg4H20

geo-rg, 2019-02-26:
Hi @viertel
I assume you found a solution. If not so, please re-open this issue and provide further information.

Closed 2019-02-26.

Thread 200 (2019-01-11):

Issue not sure how to resolve?

OlivierLaflamme, 2019-01-11:
when I Run the ChameleonFirmwareUpgrade.bat as Administrator I get this error message in my terminal?

dfu-programmer: no device present.
There was an error with executing this command. Maybe your ChameleonMini is not in bootloader mode?

Do you happen to know what I could do to fix this?

OlivierLaflamme, 2019-01-11:
how would  I put it in bootloader mode?

gtpy, 2019-01-11:
> how would I put it in bootloader mode?

Make sure the Chameleon is switched off (power switch on the side is in the position OFF). Now, hold down the right button (RBUTTON) and keep it pressed while connecting the Chameleon to a PC via a USB cable.

Best way to start is to read the [getting started](https://rawgit.com/emsec/ChameleonMini/master/Doc/Doxygen/html/_page__getting_started.html)

geo-rg, 2019-01-11:
@OlivierLaflamme Does this solve your problem?

OlivierLaflamme, 2019-01-11:
yeah thanks soz for question

Closed 2019-01-11.

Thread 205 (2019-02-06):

Switch button stopped working

dealaddict, 2019-02-06:
My switch button is not working and it is not able to switch cards. This only happens on battery mode. While it is connected to the computer, the switch and lights work, but once disconnected from usb the button no longer works. I can't switch between tags.

Appreciate your help.

gtpy, 2019-02-06:
https://github.com/iceman1001/ChameleonMini-rebooted/issues/65

It sounds that’s a RevE Rebooted device?

Maybe other users of the "RevE rebooted" could tell if it is a normal behavior. I can only guess because I don't own a rebooted device.

gtpy, 2019-02-06:
It looks solved (rebooted device). Pls close issue.

Closed 2019-02-06.

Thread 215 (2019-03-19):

bootloader mode - test FAILED

banannd, 2019-03-19:
HI,
I ran the upgrade command and now I am in the bootloader mode (I did not update firmware). Now when I run the device I have a test failed
showlog
Generating Test Report from SRAM:
Test Report for Chameleon-Mini
* FW version: 0.5
* Test      Buttons: FAILED (Took 16539ms) Time exceeded without input on Left Button, time exceeded without input on Right Button.
* Test       Reader: FAILED (Took 521ms) Could not perform a whole ISO14443A select protocol and finally receive a SAK without errors. Used threshold range: 50 - 4095.
* Test         FRAM: PASSED (Took 143ms) Wrote 32768 pseudorandom bytes to FRAM. Successfully read the same bytes from FRAM.
* Test        Fuses: PASSED (Took 1ms) Read the following fuse bytes (the values in brackets have the form <reference value;mask>). 1: 00(00;FF) - 2: BE(BE;63) - 4: F3(F3;1F) - 5: ED(ED;3F).
* Test    Signature: PASSED (Took 0ms) Read the Device ID 1E9746, expected 1E9746.
* Test     USB Enum: PASSED (Took 120ms) USB Device State is ADDRESSED.
* Test          VCC: PASSED (Took 103ms) Measured a VCC of 3183 mV.
* Test      Antenna: PASSED (Took 104ms) Measured the following RSSI values: 11542 mV, 11625 mV, 11566 mV, 11601 mV, 11660 mV.
* Total Testing Time: 17533ms
Your Chameleon will emulate a card with the UID 8445C51B.
Sorry. Some test(s) have FAILED, please unplug chameleon, fix errors and re-test.
^Croot@nano-LIFEBOOK-E744:~# ^C

geo-rg, 2019-03-19:
Hi @banannd
I assume that before running the upgrade command, the terminal output said something like "all tests have been passed SUCCESSFULLY", right? If so, there is no problem, because your test failed because of two tests that need user interaction. **However, there is no need to restart the test procedure.**

I assume you also typed `reset`, which resets the selftest procedure? This would explain the behavior.

When you are in bootloader mode (directly after typing `upgrage<enter>`), you have to upgrade the firmware according to [the Getting Started](https://rawgit.com/emsec/ChameleonMini/master/Doc/Doxygen/html/_page__getting_started.html) -- please start with Step 2 since you are already in bootloader mode.

banannd, 2019-03-19:
Yes before  Irunning the upgrade command, the terminal output said something like "all tests have been passed SUCCESSFULLY"
and next I also typed reset.

do I have now to upgrade the firmware according ?
or can I abort the procedure and use the device
my FW version: is 0.5
when i now enter the command UID? or VERSION? or HELP system still show:
Welcome to your ChameleonMini! This is test firmware version 0.5.
Sorry. Some test(s) have FAILED, please unplug chameleon, fix errors and re-test.
Type "upgrade" to jump to the bootloader and install new firmware as described on https://github.com/emsec/chameleonmini

You can also use the following commands:
* Type "showlog" to show the factory test log
* Type "reset" to re-run the self test (you need to power cycle the Chameleon)

geo-rg, 2019-03-20:
Hi @banannd
the Chameleon comes with a pre-installed test firmware which is basically useless for you. It has the purpose that you can see that the device did work as expected after production.

You need to upgrade the firmware as I wrote in my last comment.

banannd, 2019-03-20:
Thank you very much.

Closed 2019-03-20.

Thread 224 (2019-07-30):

How to recover bootloader?

gtpy, 2019-07-30:
Hi,

how is the procedure to recover bootloader for RevG with external programmer?

JTAG? MKII? Other? pinout?

Has anybody an idea or a little guideline.

Thanks a lot.

fptrs, 2019-07-31:
Hi @gtpy ,
i think you need to flash the bootloader again. The bootloader firmware is [here](https://github.com/emsec/ChameleonMini/blob/master/Firmware/Atmel%20DFU%20Bootloader/bootloader-atxmega128a4u-104-PA6-SPM.hex).

gtpy, 2019-08-02:
Ok thanks. But how do I flash it?

fptrs, 2019-08-02:
Hi @gtpy,
to flash the bootloader I use an AVR Dragon with the Atmel Studio Software. [Here](http://ww1.microchip.com/downloads/en/devicedoc/atmel-42723-avr-dragon_userguide.pdf) you can find the userguide.

gtpy, 2019-08-08:
Have you a picture how to connect it?

fptrs, 2019-08-09:
Take a look at the picture in section 4.3 of the AVR Dragon user guide. The other end of the cable is connected to the three pins at the bottom of the Chameleon and the read line points to the left. Additionally you have to connect the Chameleon via USB for power.

sp4rrows, 2019-08-11:
Hi @gtpy @fptrs maybe a beginner question:
Where to connect the chameleon RXD?
CLK and DATA I have found on the User Guide.

Would be nice if one of you could help me or expand the doxygen/wiki.

Peterthegreat, 2019-08-26:
Hi. Take a look at my older post. It's a bit of work, but I flashed the bootloader using a patched USBASP

https://github.com/emsec/ChameleonMini/issues/120#issuecomment-313001241

sp4rrows, 2019-08-30:
@Peterthegreat thanks, now I have a AVRispMKii.
But I am not sure how to exactly connect.
Chameleon has 3 points (DATA, RXD, CLK).
My AVRisp has the following pinout:
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
MISO=DATA?
RST=CLK?
Thanks a lot.

Peterthegreat, 2019-08-31:
Yes, that should work.
MISO=DATA
RST=CLK
I am not sure how, but you should change the AVRispMKii to PDI interface. Give it a try

sp4rrows, 2019-08-31:
PDI is possible.
What is RXD on the chameleon for? Anyone knows?

Peterthegreat, 2019-08-31:
I think my comment it's self explanatory. Just connect to the break-out pads. Do you know what breakout means?

> Breakout boards are a common electrical components that take a bundled cable and “breaks out”
> each conductor to a terminal that can easily accept a hook-up wire for distribution to another device.

The ChameleonMini has pads labeled CLK DATA etc. Take a closer look

The next comment (in that issue) by Endres is also helpful

gtpy, 2019-09-01:
@sp4rrows Try to take a look at the schematics.
There you see, that on one side is DATA, RXD, CLK
And on the other you’ll find VCC, TXD, GND.
On the Board maybe a litte bit hidden on one side under some soldering.

gtpy, 2019-09-01:
So you should try a 2x3 Header to connect

Closed 2019-09-02.

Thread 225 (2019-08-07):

Emulating Mifare Classic with 5 sectors

lavanoid, 2019-08-07:
Hello,

I have a dump of a Mifare Classic tag which oddly only has 5 sectors (0-4)? (This tag was read by Mifare Classic Tool, on Android and I have dumped it multiple times with the same result).

I can seem to only get the Chameleon Mini to emulate the tag as if it has 16 sectors (0-15), so it isn't a perfect clone. I am using Chamgo-QT ( https://github.com/WolfgangMau/chamgo-qt ) on Manjaro Linux to write my dumps to the device.

Is it possible to add emulation support for tags that have abnormal sector counts?

I have attached the dumps of the tag:
[Dump_5sec.zip](https://github.com/emsec/ChameleonMini/files/3476190/Dump_5sec.zip)

fptrs, 2019-08-08:
Hi @lavanoid,

I think your tag is a [Mifare Classic Mini](http://www.smartcardworld.com/mifaremini.htm). Currently it is not a supported configuration. We are always happy about contributions and if you send us a tag, we can help you with the development.

lavanoid, 2019-08-08:
Thanks for that! I wasn't aware that Mifare Classic Mini was a thing.

I would love to send a tag, but I no longer have access to the one that I obtained the dump from. I copied it with MFC on Android, back in 2017 and have since lost it ._.

I would assume that we could just modify the current code base for the Mifare Classic and make the Chameleon present only 5 sectors instead of the usual 16, right?

lavanoid, 2019-08-08:
Found some useful information here: https://www.badge-vigik-selecta-copie.fr/index.php/forum/selecta/41-mifare-mini-0-3k-atqa-sens-res-00-04-sak-sel-res-09 and http://newffr.com/viewtopic.php?&forum=235&topic=16208

MFCM ATQA: 0004
MFCM SAK: 09
EEPROM: 320 bytes

Places to purchase:

- https://www.aliexpress.com/item/32812111828.html

Way out of my price range and probably not worth the price since we'd only need a few tags at best.

ceres-c, 2019-08-08:
Last time I had a Mifare Mini on hand it looked like your average Mifare Classic, so I guess you don't need a sample. The datasheet should be enough :-)

timokasper, 2019-08-08:
So probably, duplicating the mf_classic_1k configuration and setting to 5 sectors instead of 16 will result in a suitable "mifare Mini S20" emulation.

lavanoid, 2019-08-08:
🐱 Most likely! Also, I should probably open another issue for this next thing I've encounterd:

When setting a slot to READONLY=1, it doesn't stick when the device is powered off and powered back on. To get around this, I have to use the RECALL command if memory serves correctly for it to save properly?

The READONLY option also seems to apply itself to all slots, meaning that I cannot write to any of my saved tags when I just want one of the slots to be set as read-only.. I don't know if this is reproducible on your end? Some readers check if the UID part of the tag is writable, to determine if it is a clone. And if possible, add an option to make only the UID part of the tag readonly whilst having the other blocks read/write?

lavanoid, 2019-08-10:
For testing purposes, I assume there is more involved than just changing `MIFARE_CLASSIC_1K_MEM_SIZE 1024` to `MIFARE_CLASSIC_1K_MEM_SIZE 320` ?

ceres-c, 2019-08-15:
> For testing purposes, I assume there is more involved than just changing `MIFARE_CLASSIC_1K_MEM_SIZE 1024` to `MIFARE_CLASSIC_1K_MEM_SIZE 320` ?

Well you should create a `MIFARE_CLASSIC_MINI` config and modify accordingly at lease the following files (I might have missed some)

- https://github.com/emsec/ChameleonMini/blob/master/RevE/Firmware/Chameleon-Mini/Configuration.c Here you add the `MIFARE_CLASSIC_MINI` configuration itself
- https://github.com/emsec/ChameleonMini/blob/master/Firmware/Chameleon-Mini/Application/MifareClassic.h Here you add new memory size
- https://github.com/emsec/ChameleonMini/blob/master/Firmware/Chameleon-Mini/Application/MifareClassic.c Here you create the `MifareClassicAppInitMini` function. You'll probably have to check if everything else in this file is already correct or have to be tweaked
- https://github.com/emsec/ChameleonMini/blob/master/RevE/Firmware/Chameleon-Mini/Configuration.c Here, finally, you define your new config alike `CONFIG_MF_CLASSIC_1K_SUPPORT` and `CONFIG_MF_CLASSIC_4K_SUPPORT`

lavanoid, 2019-08-16:
Changes made. The ChameleonMini just freezes when setting a UID for the MifareClassicMini configuration.

These are the changes I made: https://github.com/lavanoid/ChameleonMini/commits/master

lavanoid, 2019-08-16:
Here is a pre-compiled firmware, with the above changes.
[MifareMini-Chameleon-Mini.zip](https://github.com/emsec/ChameleonMini/files/3509428/MifareMini-Chameleon-Mini.zip)

ceres-c, 2019-08-16:
Spotted the bug, I guess. You missed the full configuration in `Configuration.c`, you could use `CONFIG_MF_CLASSIC_4K_SUPPORT` as a reference

lavanoid, 2019-08-16:
Fixed. Now for some reason the emulated tag still has 16 sectors.

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

ceres-c, 2019-08-16:
It might be due to ATQA and SAK values in `MifareClassic.c` which identify your `CONFIG_MF_CLASSIC_MINI` as a Mifare classic for the reader. Set proper values in `MifareClassicAppInitMini`
This document might help: http://www.bdtic.com/DataSheet/NXP/AN10833.pdf

PS Please note there are Mifare Mini with 7 Byte UIDs, so you might want to specify this is a 4 Byte UID version in your config names

lavanoid, 2019-08-16:
It seems that both the 4 byte and 7 byte Mifare Mini cards have the same SAK and ATQA values? Unless I'm missing something?

```4. 4 The 7 byte UID MIFARE Mini has bit 7 = 1, even if the 4 byte NUID mapping is enabled.``` Not sure what that means exactly.

ceres-c, 2019-08-16:
It might be possible. I'm no way expert in ISO14443 since I did not implement anything about it, but if I'm not mistaken the reader gets to know the UID is 7 bytes long during the transmission of the first 4 bytes themselves. So it can be that they have the same SAK/ATQA.
Nonetheless, I'd explicitly mark the configuration as being 4 bytes only, since the UID is hardcoded to be 4 bytes long

lavanoid, 2019-08-16:
Okeydoke, I'll change the configuration name to reflect the fact that it is 4 bytes long.

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

Not sure if those error messages are normal.

ceres-c, 2019-08-16:
Have you had similar errors with an emulated Mifare Classic 1K or with a real Mifare Mini on the same reader?
If any of the two is true I guess we could consider your patches as good, otherwise this has to be digged into

lavanoid, 2019-08-16:
Seems to do it even on a 1K config, so I would assume it has something to do with libnfc not knowing the A and B keys. So that means my patches are fine.
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

ceres-c, 2019-08-16:
Then it's good, I guess :-)

lavanoid, 2019-08-16:
I wonder if we could use the source code for this (when released) to add support for more tags on the Chameleon: https://cyberise.me/multipassme/26-multiclonerv2.html

ceres-c, 2019-08-16:
The fact itself that it's using an ESP32 does not make me fond of it, actually... Apart from personal preferences, the different architecture means it won't probably have any common point with this project so it won't be of any use. It seems to be mainly geared towards programming human implants which can't be produced by your average joe. In fact, if you have a look [at their website](https://cyberise.me) they're selling normal RFID tags, a dumb chinese tag cloner and this product. I could bet this will be just another half-working tag copier...

Also they say it's derived from `Proxmark3 Lite` which I, honestly, don't know what it is.

fptrs, 2019-08-19:
Hi guys,
I have quickly tested your contribution with the NXP TagInfo app and it recognized the Chameleon as a valid MF1S20 tag 👍 Nice work!

Closed 2019-08-19.

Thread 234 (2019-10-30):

Support for Legic Prime

nfc232, 2019-10-30:
Legic Prime is currently not supported. It would be nice, if it were possible to emulate Legic Cards.

david-oswald, 2019-10-31:
Yes, it certainly would - to my knowledge Legic Prime uses an own standard, which they actually tried to standardise as ISO14443 F, see https://events.ccc.de/congress/2009/Fahrplan/attachments/1506_legic-slides.pdf. You will need to write a corresponding codec to sniff or emulate, which is a relatively low-level coding task.

simplysoft, 2020-09-04:
Hi. We are fairly new to this project and have interest in Legic Prime emulation. Given that proxmark3 has working implementation of an emulator, is it doable to implement legic prime emulation for Chameleon? Or are there any limitations (e.g. in terms of hardware) that would make it more difficult to implement it with chameleon compared to proxmark3?
If there are no known road blocks, we might be able to invest some time into this.

david-oswald, 2020-09-07:
@simplysoft that would be really great, a long awaited improvement. Would be great if you could contribute something to the project in this regard.

I don't think there are fundamental issues, see here for the RF layer of Legic Prime:

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

The Chameleon HW should be able to pick up the 10% load mod and generate the reader modulation, however as usual the devil will be in the detail getting the timings right etc.

simplysoft, 2020-09-08:
@david-oswald is there any documentation or other resources that helps getting started with development for the chameleon HW? We did glance though the code and we are still a bit in the dark how to interact with the hardware.

ceres-c, 2020-09-08:
There was a workshop at the 36C3, I don't know whether it was recorded, but the slides are available [here](https://github.com/emsec/ChameleonMini/issues/244)

Also, take a look at ISO14443-2A and ISO15693 codecs, they're well documented and you should be able to understand how data is de/modulated. I've improved ISO15 documentation, but the PR is not yet merged since I still have to fix a compilation error

simplysoft, 2020-09-09:
Thanks for the pointers so far. Any tips on development setup you use for testing / debugging or other tools you wouldn't not want to miss when writing code for Chameleon?

david-oswald, 2020-09-09:
you will definitely need an oscilloscope to check the waveforms on the demod pin etc I'd say. Doesn't have to be high-spec, something like a Rigol DS1054Z (or even cheaper ones) should do.

ceres-c, 2020-09-09:
I thought you might also want to have these
Well you'll need

ceres-c, 2020-09-09:
I thought you might also want to have these Atmel application notes/manuals at hand while reading the code/developing your own

- 8045A-AVR-02/08
- 8071A-AVR-02/08
- 8331F–AVR–04/2013
- DS40002166A

The first two files are specific to interrupts/event system, 8331F is the manual for Xmega AU MCUs (handy to understand ports/interrupts registers) and the last one is the datasheet with all the stuff you'd expect to find in a datasheet and might need.

You'll need:

- An oscilloscope, as David sad. Being a student (≈ poor) I bought an OWON VDS1022I which proved to be sufficient for my needs. Of course a better scope would give better results and probably simplify debugging
- I found myself in need of a programmer to recover a bricked chameleon and opted for a [Atmel ICE](https://eu.mouser.com/ProductDetail/Microchip-Technology-Atmel/ATATMEL-ICE?qs=KLFHFgXTQiDAUrt43H15kQ%3D%3D) which double do as a [debugger](https://ceres-c.it/3debugging-ChameleonMini/). Again, being a student, I bought the [bare PCB](https://eu.mouser.com/ProductDetail/Microchip-Technology-Atmel/ATATMEL-ICE-PCBA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) version of the debugger. Beware, it does not come with cables, so a you'll need a IDC cable (10 pins, 1,27mm pitch) to breakout your own connection board
- A reader/writer compatible with Legic cards, of course

street-grease-coder, 2021-06-26:
Why would a logic analyzer fall short here, compared to an oscilloscope? Asking because they're obviously orders of magnitudes cheaper (and because noob). Thanks for this great code repo.

timokasper, 2021-06-27:
a logic analyzer cannot display analogue signals; you need to see the real voltages at the pins of ChameleonMini in order to set up parameters such as threshold of the comparator, etc.

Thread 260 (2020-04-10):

BOM correction (for selfmade hw)

robots, 2020-04-10:
Hi,
for all of you guys who made Chameleon Mini on their own here is little advice:

Capacitors C29 and C30 should be 47pF.

This tunes the mismatch between transmitter and antenna. It increases reader distance from -1 to about 2-3cm. RSSI without tag changes from 500-600 to ~2500mV.

More about this here: https://my.eng.utah.edu/~mlewis/ref/NFC/AN1445.pdf

timokasper, 2020-04-10:
Hi robots, Thanks for the advice, but I cannot recommend to follow your advice. The RSSI without tag, with exactly the components of the BOM, should be more than 10V - all of the ChameleonMini RevG sold in the webshop of Kasper&Oswald have to pass this test! It seems that you have made some other mistake during manufacture. I have spent about a week for fine-tuning the antenna matching both for emulation and reader operation of Rev.G, before we had several thousand devices produced after the kickstarter project...  and changing the value of a single (or even 2) capacitors affected all capabilities (sniffing, reading, emulating, ...) it was a tidious try-and-improve approach and I think we have found a good compromise for the tuning....     anyway, 2500mV is definitely not enough, there is s.th. wring with your device.

robots, 2020-04-10:
Well, its been 2years since i made the board. I dont remember what parts were ordered, but it could be problem on my side :-) I will replace all RF frontend parts just to be sure.

libin-ka, 2020-05-04:
What is the capacitance value of C29 C30

robots, 2020-05-04:
these capacitors are not populated in BOM

libin-ka, 2020-05-04:
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

libin-ka, 2020-05-04:
> 这些电容器未填充在BOM中
See pictures c29 and c30 in the wiki
https://github.com/emsec/ChameleonMini/wiki

Closed 2020-04-10.

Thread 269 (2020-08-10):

Unable to emulate a card

doublemarkpro, 2020-08-10:
I made the board and SMT all the components by myself. After flashing the hex and eep file by MKII programmer, Rev G can be found at the GUI software. But the RSSI voltage is 0 even when I active one slot and upload the dump file to make the slot a Mifare S50 card.But I can configure the slot to READER mode and read the card type and card number by using _GETUID_ command.

I leave D1 C29 C30 unmounted and C20 is a 150pf capacitor.

Is there a way to find out which part of the circuit is wrong? Like if there should be some waveforms when RSSI works well?
Thanks.

Update: I found the issue: #198 and I config the redled as _CODEC_RX_ and _CODEC_TX_. It blinks when I use my phone or ACR122 reader. I can also read RSSI value in GUI software which is about 2500mV.
I use command _logdownload_ and find that the device only responses 0x04 0x00 which I guess is the card type(Mifare S50 1k).
Below is the decoded data"

_10118ms <+10118 ms?:CODEC RX     (1 bytes)    [26]
10118ms <+        0 ms?:CODEC TX     (2 bytes)    [0400]
10142ms <+      24 ms?:CODEC RX     (2 bytes)    [9201]
11452ms <+  1310 ms?:CODEC RX     (2 bytes)    [ff03]
11452ms <+        0 ms?:CODEC RX     (2 bytes)    [eb01]
11452ms <+        0 ms?:CODEC RX     (3 bytes)    [bddc03]
11452ms <+        0 ms?:CODEC RX     (1 bytes)    [31]
11453ms <+        1 ms?:CODEC RX     (4 bytes)    [6eeca67e]
11465ms <+      12 ms?:CODEC RX     (1 bytes)    [26]
11465ms <+        0 ms?:CODEC TX     (2 bytes)    [0400]
11489ms <+      24 ms?:CODEC RX     (1 bytes)    [cb]
12440ms <+    951 ms?:CODEC RX     (3 bytes)    [38e721]
12441ms <+        1 ms?:CODEC RX     (1 bytes)    [56]
12441ms <+        0 ms?:CODEC RX     (1 bytes)    [31]
12441ms <+        0 ms?:CODEC RX     (4 bytes)    [06ac4c05]
12454ms <+      13 ms?:CODEC RX     (1 bytes)    [26]
12454ms <+        0 ms?:CODEC TX     (2 bytes)    [0400]
12478ms <+      24 ms?:CODEC RX     (3 bytes)    [d9cd03]_

So,could anyone help me with that so I can locate the reason why the transmission is wrong?

Thanks again.

doublemarkpro, 2020-08-15:
Problem solved.

The IC4 74AHC1G86DCK pin 1(_LOADMOD_ pin) and  IC3 pin 4 to Q3 are not mounted well. It works well after I solder them again.

The log system is really useful for me to solve the problem.

Hope everyone can make it successfully. I will close this issue.

Closed 2020-08-15.

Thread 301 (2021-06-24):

Battery draining

overkillzworld, 2021-06-24:
What is the best way to find out why my ChameleonMini always drains the battery even though it is turned off?
Already flashed latest firmware.
Tested different new LIR2032.
Fully charged via USB.
Power switch is turned off.
After one day it is empty.
Some advice on how to proceed would help me.

david-oswald, 2021-06-24:
Hi,

As you can see in the schematics, if the power switch is off the battery is only connected to the charger IC:

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

So I would check how that IC looks / if it gets hot or similar. Another possible issue might be that C4 (parallel to the battery) has failed and conducts (a bit) to ground, do you have a multimeter to check that?

Overall, whether you can repair this yourself would of course depend on your electronics experience.

overkillzworld, 2021-06-25:
Yes I have a multimeter here. However, I am a developer and not an electronics expert :) What is the best way to measure such a small MLCC? Sorry for the stupid question, but only so I can learn something about it.

david-oswald, 2021-06-25:
You can take out the battery and then measure the resistance between battery + and -

This should be high impedance / constantly increase, otherwise there might be an issue with the charging chip or the cap.

overkillzworld, 2021-06-25:
@david-oswald Thanks for the fast reply.
So it is correct:
Position:
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
Measure:
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

david-oswald, 2021-06-25:
Yes, so this looks like there's no low impedance in the cap or charging IC - just to make sure, does it go up further than 3.8 M? (this will depend on the multimeter though)

Also, can you check/read the value of R4 on your device?

Finally, have you measured the battery voltage when "fully charged"?

timokasper, 2021-06-26:
The LIR2032 has 40mAh with 3.6-4.2 Volts. Current=Voltage/Resistance, thus there is a current of about 1 micro Ampere. Thus it takes 40.000 hours / 5 years to drain a full battery ...

so your problem must be elsewhere.

Are you sure you are using an LIR2032 not a CR2032...     You can measure the voltage at the battery. 4.2 is full, 3.6 is empty, <=3.3 is either a wrong battery (CR2032) or a dead LIR cell

overkillzworld, 2021-06-28:
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

It stops at 3.85 M Or like seen in the picture 3.89 M.

overkillzworld, 2021-06-28:
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

I am sure it is a LIR2032. Ordered a pack to test if the old LIR was maybe dead. Measured the LIR2032 full charged it has 4.19 V

overkillzworld, 2021-06-28:
Now that the battery is fully charged, I'll see how long it takes to completely discharge it. Last time it was 1-2 days.

overkillzworld, 2021-07-02:
I have an Idea what could cause the battery problem, but I wanted to look at the schematic first. Short question offtopic: Which program is best to view the Schematic [.sch] files?  If I try it in KiCad it looks not correct
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

david-oswald, 2021-07-02:
It's in Eagle, but there is also a PDF in the folder so that you don't have to install that just to check the schematic.

overkillzworld, 2021-07-02:
Ok. Thanks. I'll take a closer look :)

overkillzworld, 2021-07-06:
Could it have been a short on the board between C15 and IC2 (or C4 and IC2)?  There the solder joints were a bit close together or slightly connected. I have corrected this and now it looks better since a few days. I'll keep watching it.

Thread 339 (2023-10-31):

No communication between old NFC reader and ChameleonTiny Pro

HainBuche, 2023-10-31:
Hi,

I have an old reader (pre 2010) with unknown specifications that was used for 1k MIFARE classic cards.
It can still read the old cards successfully. These cards can also be read on a newer reader (such as ACR-122) and can also be read by the ChameleonTiny and further be successfully copied and emulated and then read by the newer reader. However, emulated cards are not recognized by the old reader, and even more important the ChameleonTiny does not seem to recognize any near field signal from the old reader, as the RF-LED does not light up in neither mode (emulate, read, sniff) and no Log is created.
What might be the reason ? Can there be timing issues ? Other hardware issues ?
Hope you can give me some insights, thanks !

Best regards

ceres-c, 2023-10-31:
Hello, this is the repo for the ChameleonMini, for the ChameleonTiny you should ask [here](https://github.com/RfidResearchGroup/ChameleonMini)

My take on your issue is that the antenna is too small and the reader don’t like it. But I am just guessing

HainBuche, 2023-10-31:
Hey, I actually posted there first, but was unsure.
But thanks for your quick response :-)
If it would be indeed the antenna, how would you approach to fix it, attach some wire?
I had tried moving the ChameleonTiny to different positions and distances, but it did not help.
Thank you for your time!

ceres-c, 2023-10-31:
The problem with the ChameleonTiny is indeed that you can't (AFAIK) attach an external antenna. You can do that on the ChameleonMini, quite easily so with an SMA connector actually, but the other device is more end-user oriented rather than research so IIRC some feature such as the SMA have been dropped in favor of smaller size and sleek looks.
If you were able to, you could indeed try to use an antenna with a different shape/size. There are some tools online to calculate NFC antennas geometries, as well as vendor specific tools: search ST and TI websites.

If I had to guess, I'd say the reader you're dealing with is a bit "deaf" (read: bad antenna design) and doesn't detect the small load induced in its field by the tiny antenna in the ChameleonTiny

HainBuche, 2023-11-01:
Thanks a lot, I'll look into that and see whats possible for me. What puzzles me though is that apparently even when placed between the old reader and a card while they are communicating, no signal is detected by the ChameleonTiny. Might that still be explainable by the antenna issue ?

ceres-c, 2023-11-01:
It is indeed weird, but IIRC the field detector in the ChameleonTiny is essentially just an led connected to the antenna. If indeed the cham/reader antenna coupling is bad, that would explain both because:
1) There will not be enough energy on the Chameleon's side to power up the led
2) It will not be detected by the reader because there is no load

If you think about it, it's like moving a random piece of metal within the reader field

HainBuche, 2023-11-01:
Oh okay that sounds quite plausible. Guess I will have to putter around a little then, hope I don't ruin it.
Thanks again for your quick response.

Closed 2023-11-02.

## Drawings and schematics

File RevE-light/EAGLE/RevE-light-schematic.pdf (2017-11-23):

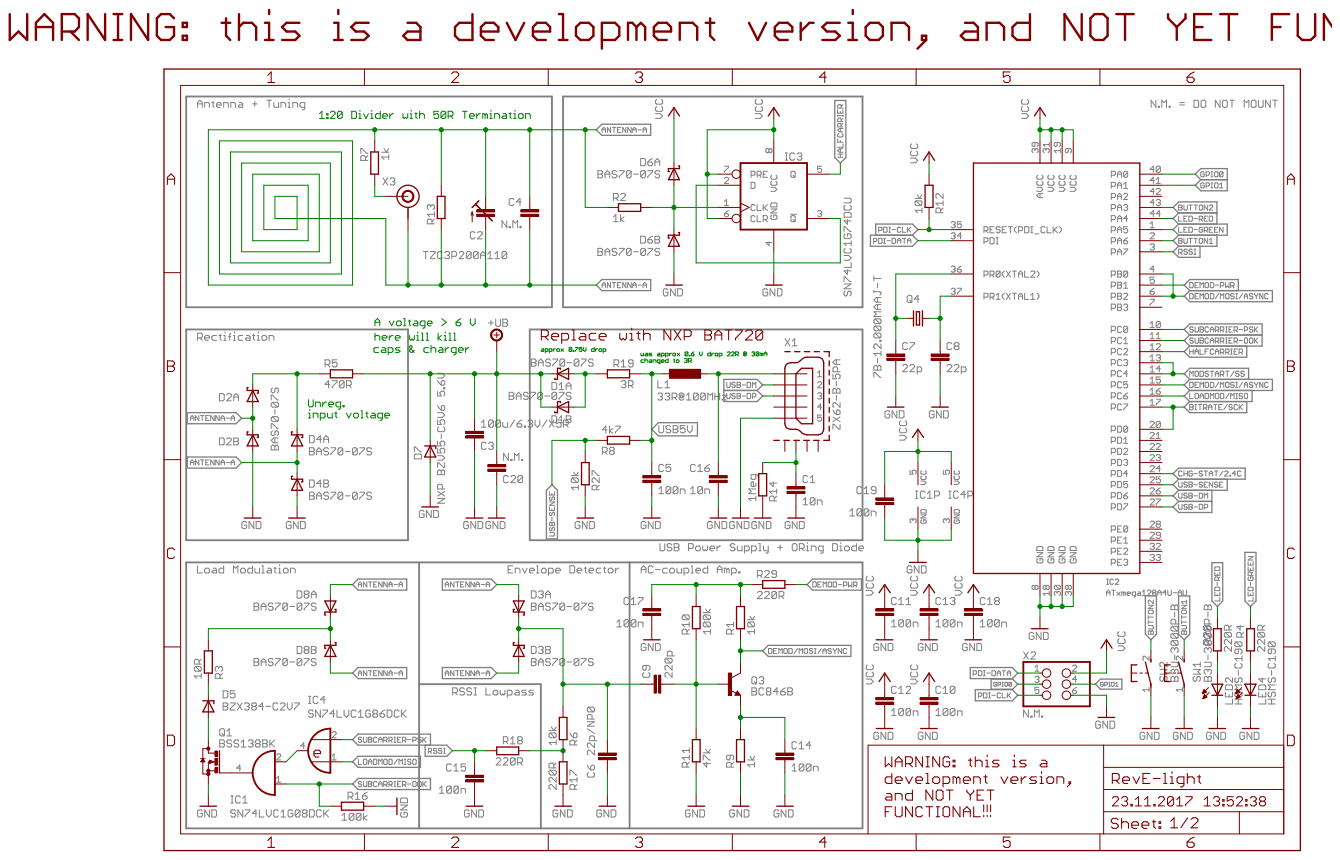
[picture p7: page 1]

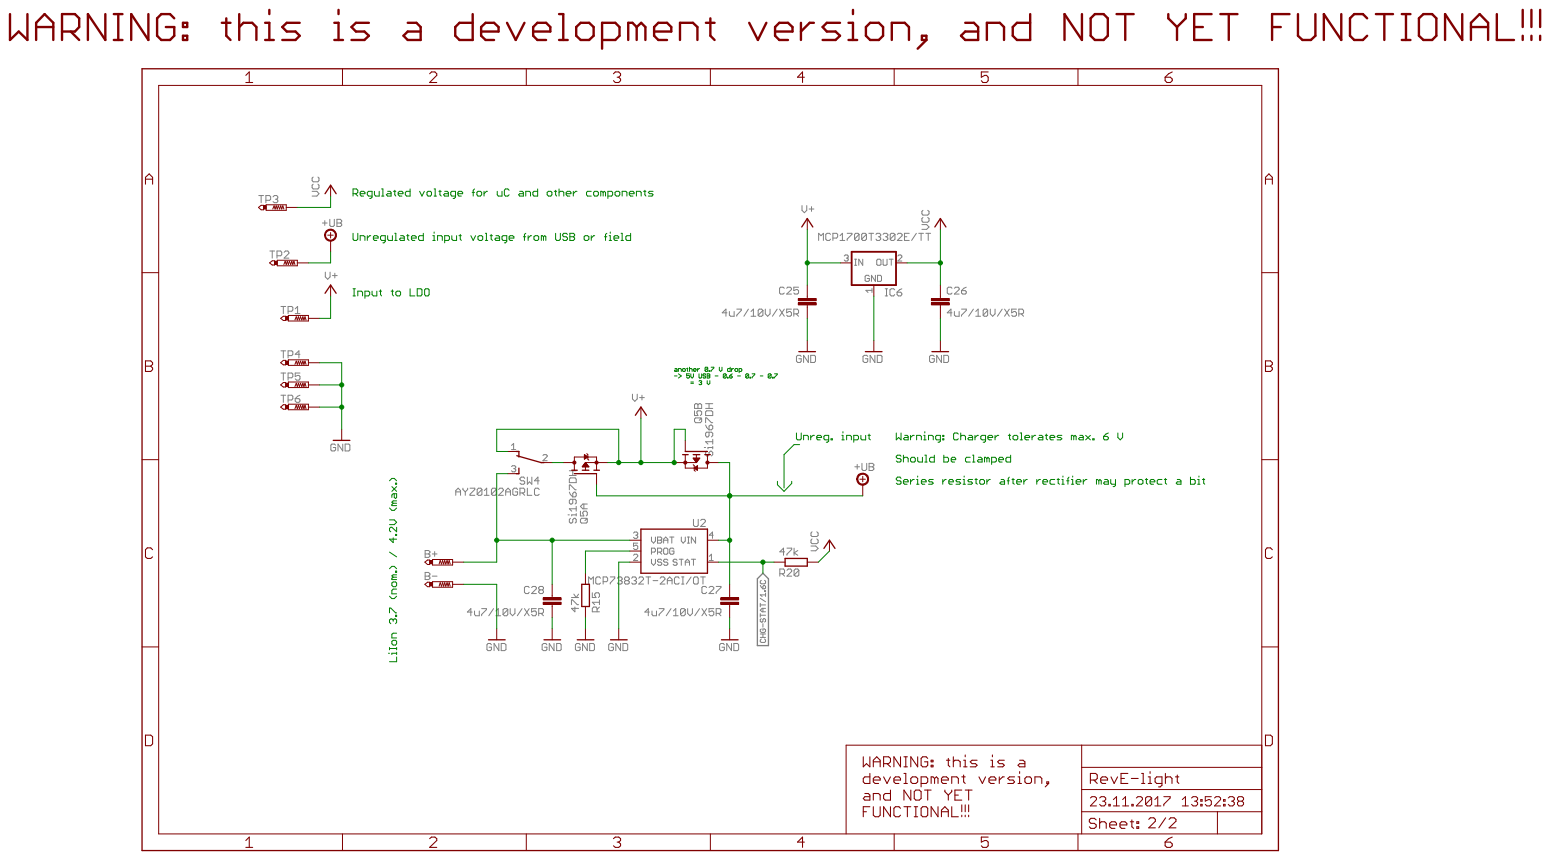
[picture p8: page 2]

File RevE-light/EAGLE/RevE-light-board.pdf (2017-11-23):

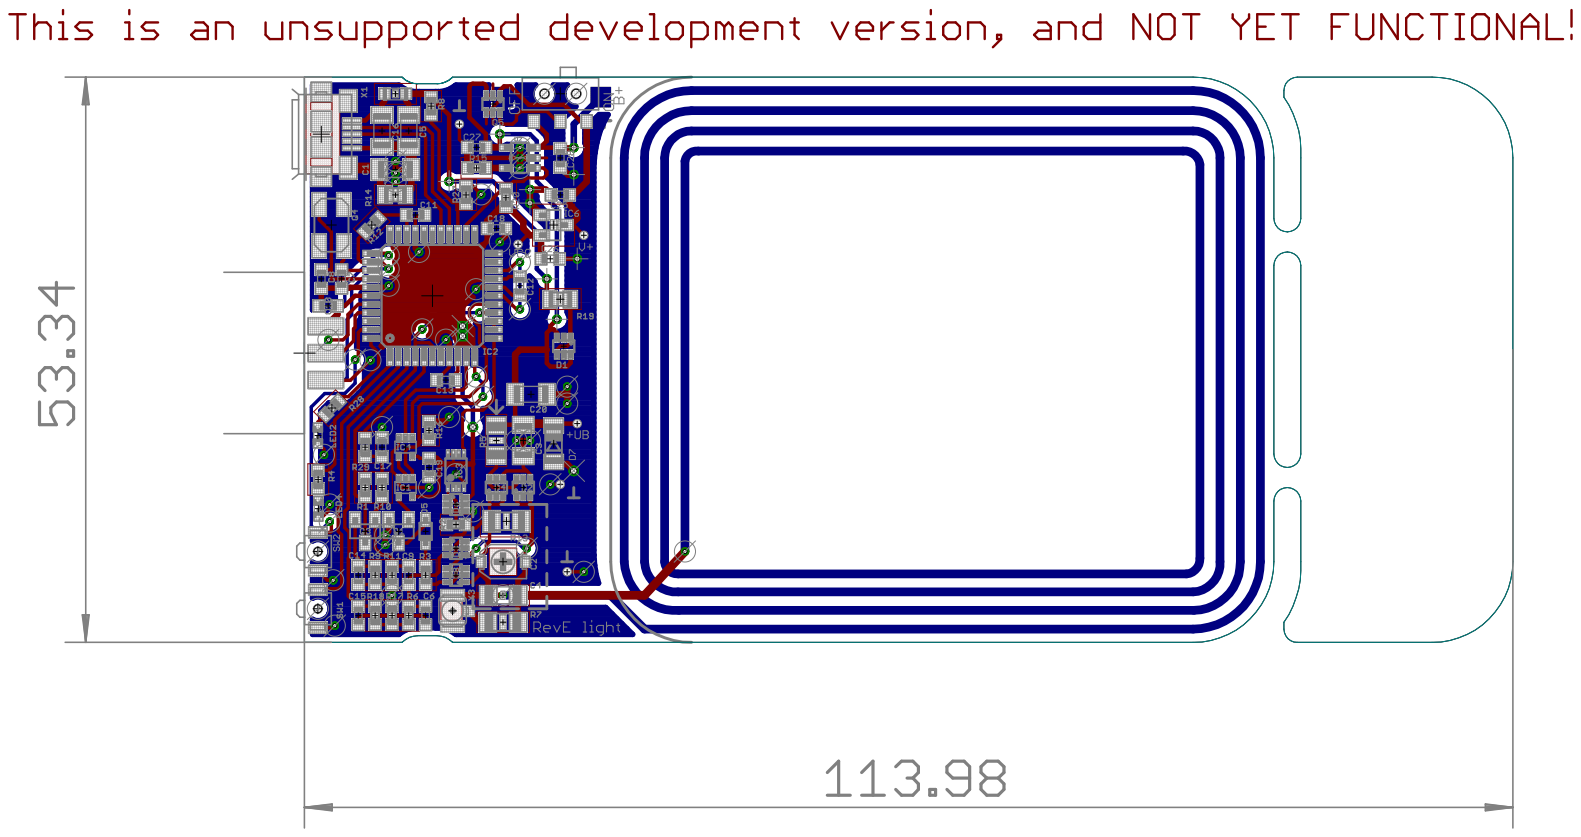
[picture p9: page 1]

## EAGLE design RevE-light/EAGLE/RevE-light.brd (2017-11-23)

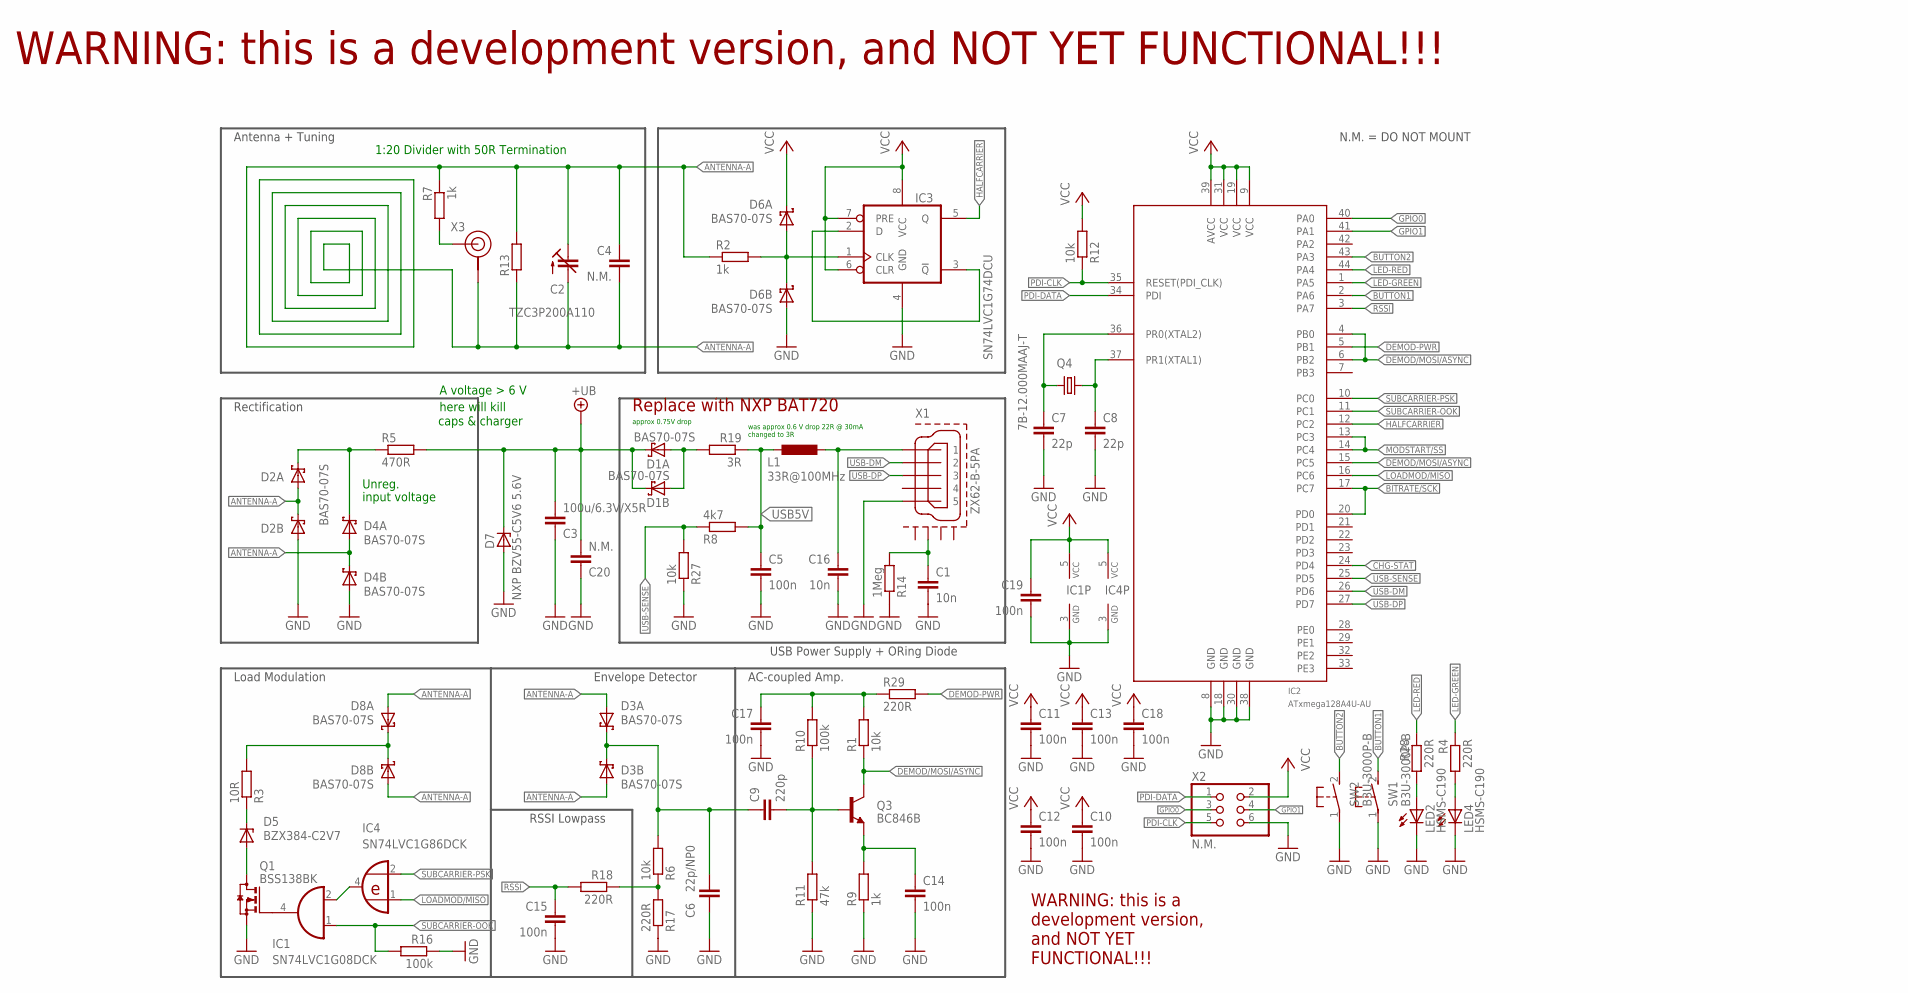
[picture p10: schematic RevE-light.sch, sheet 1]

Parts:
C1, C16: 10n; C1206K
C2: TZC3P200A110; TZC3P
C3: 100u/6.3V/X5R; C1206K
C4: N.M.; C1206
C5: 100n; C1206K
C6: 22p/NP0; C0603K
C7, C8: 22p; C0603K
C9: 220p; C0603K
C10, C11, C12, C13, C14, C15, C17, C18, C19: 100n; C0603K
C20: N.M.; C1206K
D1, D2, D3, D4, D6, D8: BAS70-07S; SOT363_PHILIPS
D5: BZX384-C2V7; SOD323
D7: NXP BZV55-C5V6 5.6V; SOD80C
IC1: SN74LVC1G08DCK; SC70-5
IC2: ATxmega128A4U-AU; TQFP44
IC3: SN74LVC1G74DCU; VSSOP8
IC4: SN74LVC1G86DCK; SC70-5
L1: 33R@100MHz; L2012C
LED2, LED4: HSMS-C190; CHIPLED_0603
Q1: BSS138BK; SOT23
Q3: BC846B; SOT23
Q4: 7B-12.000MAAJ-T; 5MMX3.2MM
R1, R6, R12, R27: 10k; R0603
R2, R9: 1k; R0603
R3: 10R; R0603
R4, R17, R18, R28, R29: 220R; R0603
R5: 470R; R1206
R7: 1k; R1206
R8: 4k7; R0603
R10, R16: 100k; R0603
R11: 47k; R0603
R13: R-EU_M1206; M1206
R14: 1Meg; M0805
R19: 3R; M0805
SW1, SW2: B3U-3000P-B
X1: ZX62-B-5PA; ZX62-B-5PA-LONG
X2: N.M.; PINHD-2X3-2.54-EDGE
X3: U.FL-R-SMT

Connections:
+UB: C3.2, C20.2, D1.3 (C), D1.6 (C), D7.C, R5.2; also elsewhere on the board
ANTENNA-A: C2.1 (A), C2.2 (E), C4.1, C4.2, D2.1 (A), D2.3 (C), D3.1 (A), D3.4 (A), D4.1 (A), D4.3 (C), D8.1 (A), D8.4 (A), R2.1, R7.1, R13.1, R13.2, X3.GND2 (GND)
BITRATE/SCK: IC2.17 (PC7), IC2.20 (PD0)
BUTTON1: IC2.2 (PA6), SW1.2 (S)
BUTTON2: IC2.43 (PA3), SW2.2 (S)
CHG-STAT: IC2.24 (PD4); also elsewhere on the board
DEMOD-PWR: IC2.5 (PB1), R29.2
DEMOD/MOSI/ASYNC: IC2.4 (PB0), IC2.6 (PB2), IC2.15 (PC5), Q3.3 (C), R1.1
GND: C1.2, C3.1, C5.2, C6.2, C7.2, C8.2, C10.2, C11.2, C12.2, C13.2, C14.2, C15.2, C16.2, C17.2, C18.2, C19.2, C20.1, D2.4 (A), D4.4 (A), D6.4 (A), D7.A, IC1.3 (GND), IC2.8 (GND), IC2.18 (GND), IC2.30 (GND), IC2.38 (GND), IC3.4 (GND), IC4.3 (GND), LED2.C, LED4.C, Q1.2 (S), R9.1, R11.1, R14.1, R16.1, R17.1, R27.1, SW1.1, SW2.1, X1.5, X2.6; also elsewhere on the board
GPIO0: IC2.40 (PA0), X2.3
GPIO1: IC2.41 (PA1), X2.4
HALFCARRIER: IC2.12 (PC2), IC3.5 (Q)
LED-GREEN: IC2.1 (PA5), R4.1
LED-RED: IC2.44 (PA4), R28.1
LOADMOD/MISO: IC2.16 (PC6), IC4.1 (I0)
MOD-DEMOD: D8.3 (C), D8.6 (C), R3.2
MOD-DEMOD1: C6.1, C9.1, D3.3 (C), D3.6 (C), R6.2
MODSTART/SS: IC2.13 (PC3), IC2.14 (PC4)
unnamed: C14.1, Q3.2 (E), R9.2
unnamed: D5.2 (A), Q1.3 (D)
unnamed: IC3.2 (D), IC3.3 (!Q)
unnamed: C7.1, IC2.36 (PR0(XTAL2)), Q4.3 (2)
unnamed: R6.1, R17.2, R18.1
unnamed: C16.1, L1.1, X1.1
unnamed: C8.1, IC2.37 (PR1(XTAL1)), Q4.1
unnamed: LED2.A, R28.2
unnamed: D2.6 (C), D4.6 (C), R5.1
unnamed: IC1.2 (I1), IC4.4 (O)
unnamed: D5.1 (C), R3.1
unnamed: LED4.A, R4.2
unnamed: IC1.4 (O), Q1.1 (G)
unnamed: R7.2, X3.SIG
unnamed: C9.2, Q3.1 (B), R10.1, R11.2
unnamed: C1.1, R14.2, X1.P$2 (GND2)
unnamed: D1.1 (A), D1.4 (A), R19.2
unnamed: D6.1 (A), D6.3 (C), IC3.1 (CLK), R2.2
unnamed: C17.1, R1.2, R10.2, R29.1
PDI-CLK: IC2.35 (RESET(PDI_CLK)), R12.1, X2.5
PDI-DATA: IC2.34 (PDI), X2.1
RSSI: C15.1, IC2.3 (PA7), R18.2
SUBCARRIER-OOK: IC1.1 (I0), IC2.11 (PC1), R16.2
SUBCARRIER-PSK: IC2.10 (PC0), IC4.2 (I1)
USB5V: C5.1, L1.2, R8.2, R19.1
USB-DM: IC2.26 (PD6), X1.2
USB-DP: IC2.27 (PD7), X1.3
USB-SENSE: IC2.25 (PD5), R8.1, R27.2
VCC: C10.1, C11.1, C12.1, C13.1, C18.1, C19.1, D6.6 (C), IC1.5 (VCC), IC2.9 (VCC), IC2.19 (VCC), IC2.31 (VCC), IC2.39 (AVCC), IC3.6 (CLR), IC3.7 (PRE), IC3.8 (VCC), IC4.5 (VCC), R12.2, X2.2; also elsewhere on the board

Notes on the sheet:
1:20 Divider with 50R Termination
Envelope Detector
RSSI Lowpass
AC-coupled Amp.
Load Modulation
Rectification
USB Power Supply + ORing Diode
Antenna + Tuning
WARNING: this is a development version, and NOT YET FUNCTIONAL!!!
N.M. = DO NOT MOUNT
Unreg.
input voltage
A voltage > 6 V
here will kill
caps & charger
was approx 0.6 V drop 22R @ 30mA changed to 3R
approx 0.75V drop
Replace with NXP BAT720
WARNING: this is a development version, and NOT YET FUNCTIONAL!!!

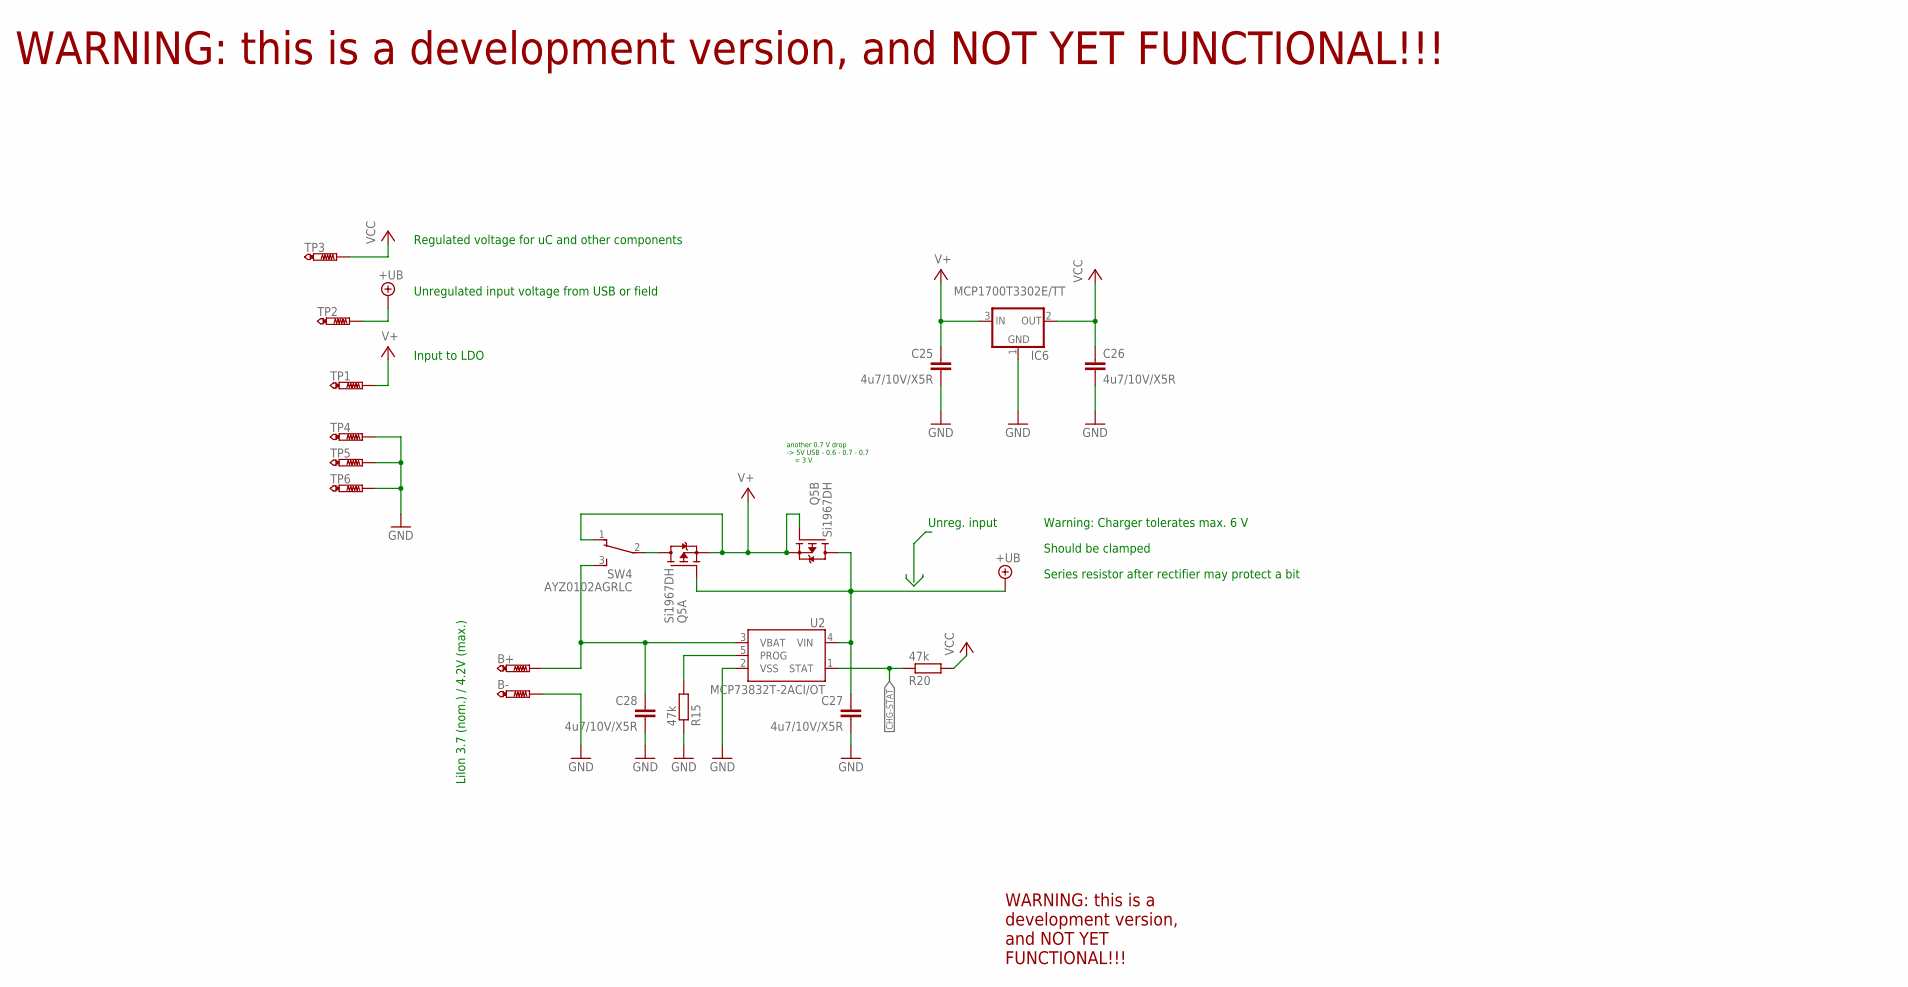
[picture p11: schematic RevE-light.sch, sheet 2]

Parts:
B+: PTR1TP18SQ; TP18SQ
B-: PTR1TP18SQ; TP18SQ
C25, C26, C27, C28: 4u7/10V/X5R; C0603K
IC6: MCP1700T3302E/TT; SOT23
Q5: Si1967DH; SOT363
R15, R20: 47k; R0603
SW4: AYZ0102AGRLC
TP1, TP2, TP3, TP4, TP5, TP6: PTR1TP07R; TP07R
U2: MCP73832T-2ACI/OT; SOT23-5

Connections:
+UB: C27.1, Q5.2 (G), Q5.3 (D), TP2.TP, U2.4 (VIN); also elsewhere on the board
CHG-STAT: R20.1, U2.1 (STAT); also elsewhere on the board
GND: B-.TP, C25.2, C26.2, C27.2, C28.2, IC6.1 (GND), R15.1, TP4.TP, TP5.TP, TP6.TP, U2.2 (VSS); also elsewhere on the board
unnamed: B+.TP, C28.1, SW4.3 (S), U2.3 (VBAT)
unnamed: R15.2, U2.5 (PROG)
unnamed: Q5.6 (D), SW4.2
V+: C25.1, IC6.3 (IN), Q5.1 (S), Q5.4 (S), Q5.5 (G), SW4.1 (O), TP1.TP
VCC: C26.1, IC6.2 (OUT), R20.2, TP3.TP; also elsewhere on the board

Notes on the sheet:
Regulated voltage for uC and other components
Unregulated input voltage from USB or field
Unreg. input
LiIon 3.7 (nom.) / 4.2V (max.)
Input to LDO
Warning: Charger tolerates max. 6 V
Should be clamped
Series resistor after rectifier may protect a bit
another 0.7 V drop -> 5V USB - 0.6 - 0.7 - 0.7 = 3 V
WARNING: this is a development version, and NOT YET FUNCTIONAL!!!
WARNING: this is a development version, and NOT YET FUNCTIONAL!!!

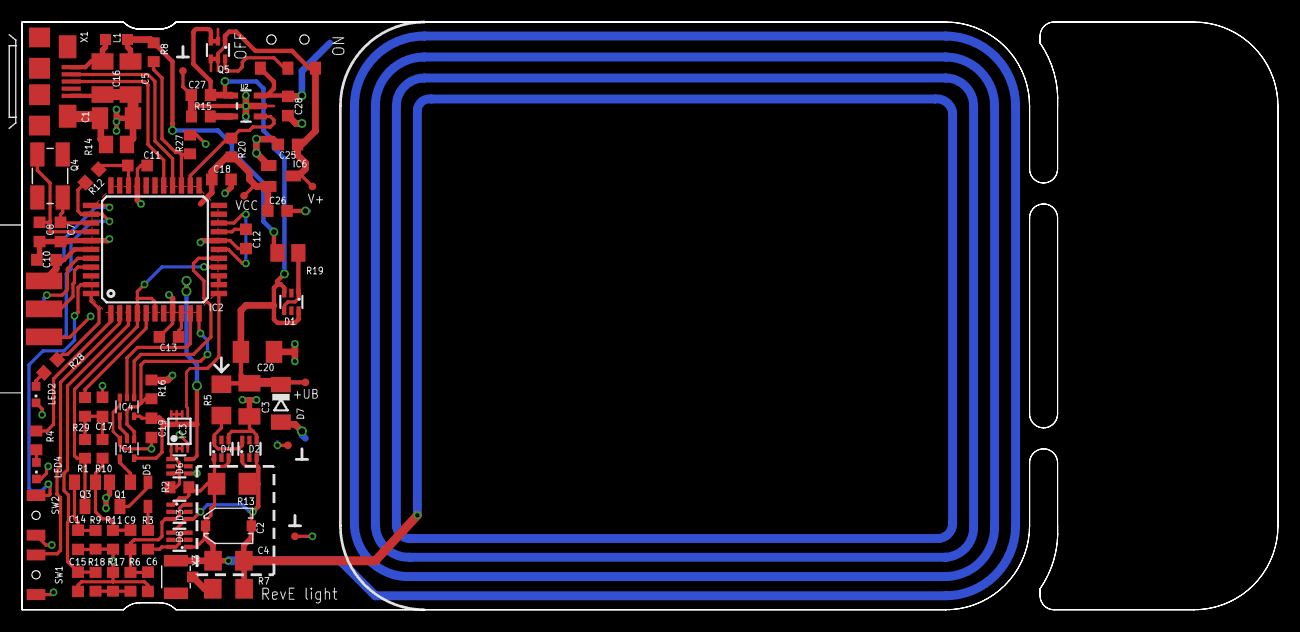
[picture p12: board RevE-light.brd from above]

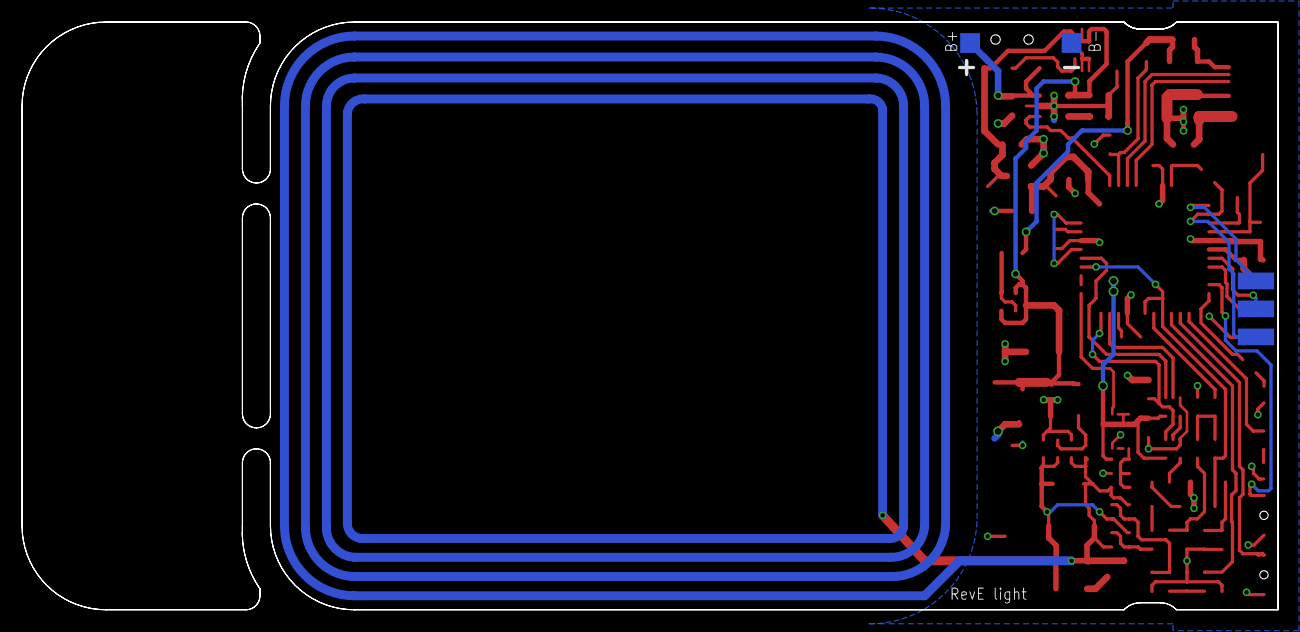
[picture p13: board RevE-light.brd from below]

Board: 2 copper layers, 114.0 x 53.3 mm, 82 parts (2 on the bottom side), 51 nets.

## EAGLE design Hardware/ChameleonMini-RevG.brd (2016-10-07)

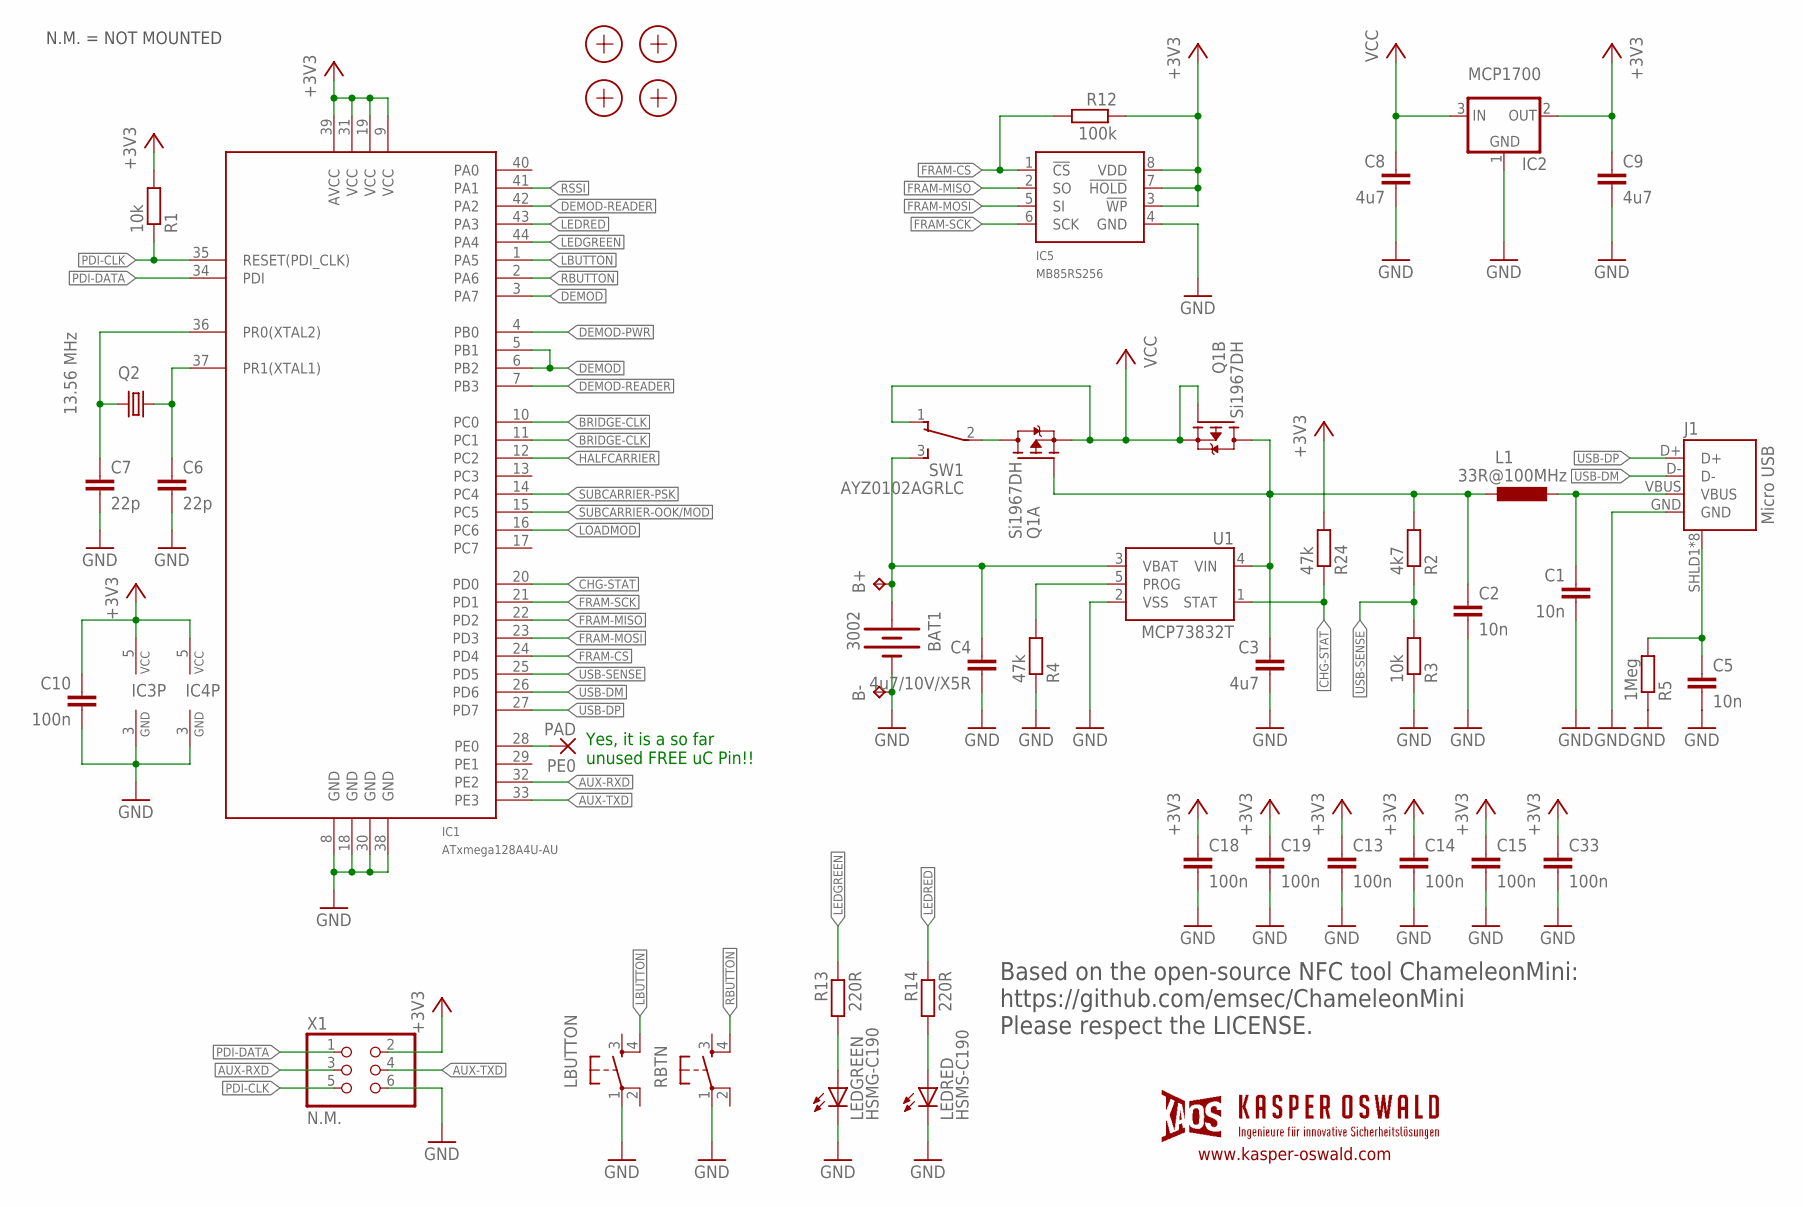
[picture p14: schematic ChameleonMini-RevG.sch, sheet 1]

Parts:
B+: TPTP18SQ; TP18SQ
B-: TPTP18SQ; TP18SQ
BAT1: 3002; BATTCON_20MM
C1, C2: 10n; C1206K
C3, C8, C9: 4u7; C0603K
C4: 4u7/10V/X5R; C0603K
C5: 10n; C0603K
C6, C7: 22p; C0603K
C10, C13, C14, C15, C18, C19, C33: 100n; C0603K
IC1: ATxmega128A4U-AU; TQFP44
IC2: MCP1700; SOT23
IC3: 7408; SC70-5
IC4: 7486; SC70-5
IC5: MB85RS256; SO-08
J1: Micro USB; USB-MICROB-10118194
L1: 33R@100MHz; L2012C
LBUTTON: SWITCH_SPST_4_PINSQUARE; TACTILE-SWITCH-SMD
LEDGREEN: HSMG-C190; CHIPLED-0603
LEDRED: HSMS-C190; CHIPLED-0603
PE0: PAD; SMD1,27-2,54
Q1: Si1967DH; SOT363
Q2: 13.56 MHz; 5MMX3.2MM
R1, R3: 10k; R0603
R2: 4k7; R0603
R4, R24: 47k; R0603
R5: 1Meg; R0603
R12: 100k; R0603
R13, R14: 220R; R0603
RBTN: SWITCH_SPST_4_PINSQUARE; TACTILE-SWITCH-SMD
SW1: AYZ0102AGRLC
U1: MCP73832T; SOT23-5
X1: N.M.; PINHD-2X3-2.54-EDGE
X2, X4, X5, X6: PASSER-07; PASSER_07MM

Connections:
!BRIDGE-CLK: IC1.10 (PC0); also elsewhere on the board
+3V3: C9.1, C10.1, C13.1, C14.1, C15.1, C18.1, C19.1, C33.1, IC1.9 (VCC), IC1.19 (VCC), IC1.31 (VCC), IC1.39 (AVCC), IC2.2 (OUT), IC3.5 (VCC), IC4.5 (VCC), IC5.3 (!WP), IC5.7 (!HOLD), IC5.8 (VDD), R1.2, R12.1, R24.2, X1.2; also elsewhere on the board
AUX-RXD: IC1.32 (PE2), X1.3
AUX-TXD: IC1.33 (PE3), X1.4
BRIDGE-CLK: IC1.11 (PC1); also elsewhere on the board
CHG-STAT: IC1.20 (PD0), R24.1, U1.1 (STAT)
DEMOD: IC1.3 (PA7), IC1.5 (PB1), IC1.6 (PB2); also elsewhere on the board
DEMOD-PWR: IC1.4 (PB0); also elsewhere on the board
DEMOD-READER: IC1.7 (PB3), IC1.42 (PA2); also elsewhere on the board
FRAM-CS: IC1.24 (PD4), IC5.1 (!CS), R12.2
FRAM-MISO: IC1.22 (PD2), IC5.2 (SO)
FRAM-MOSI: IC1.23 (PD3), IC5.5 (SI)
FRAM-SCK: IC1.21 (PD1), IC5.6 (SCK)
GND: B-.TP, BAT1.-, C1.2, C2.2, C3.2, C4.2, C5.2, C6.2, C7.2, C8.2, C9.2, C10.2, C13.2, C14.2, C15.2, C18.2, C19.2, C33.2, IC1.8 (GND), IC1.18 (GND), IC1.30 (GND), IC1.38 (GND), IC2.1 (GND), IC3.3 (GND), IC4.3 (GND), IC5.4 (GND), J1.GND, LBUTTON.1, LEDGREEN.C, LEDRED.C, R3.1, R4.1, R5.1, RBTN.1, U1.2 (VSS), X1.6; also elsewhere on the board
HALFCARRIER: IC1.12 (PC2); also elsewhere on the board
LBUTTON: IC1.1 (PA5), LBUTTON.4
LEDGREEN: IC1.44 (PA4), R13.1
LEDRED: IC1.43 (PA3), R14.1
LOADMOD: IC1.16 (PC6); also elsewhere on the board
unnamed: C7.1, IC1.36 (PR0(XTAL2)), Q2.3 (2)
unnamed: C1.1, J1.VBUS, L1.1
unnamed: C6.1, IC1.37 (PR1(XTAL1)), Q2.1
unnamed: LEDGREEN.A, R13.2
unnamed: LEDRED.A, R14.2
unnamed: Q1.6 (D), SW1.2
unnamed: C2.1, C3.1, L1.2, Q1.2 (G), Q1.3 (D), R2.2, U1.4 (VIN)
unnamed: IC1.28 (PE0), PE0.1
unnamed: R4.2, U1.5 (PROG)
unnamed: B+.TP, BAT1.+2 (+), C4.1, SW1.3 (S), U1.3 (VBAT)
unnamed: C5.1, J1.SHLD1 (SHIELD), J1.SHLD2 (SHIELD), J1.SHLD3 (SHIELD), J1.SHLD4 (SHIELD), J1.SHLD5 (SHIELD), J1.SHLD6 (SHIELD), J1.SHLD7 (SHIELD), J1.SHLD8 (SHIELD), R5.2
PDI-CLK: IC1.35 (RESET(PDI_CLK)), R1.1, X1.5
PDI-DATA: IC1.34 (PDI), X1.1
RBUTTON: IC1.2 (PA6), RBTN.4
RSSI: IC1.41 (PA1); also elsewhere on the board
SUBCARRIER-OOK/MOD: IC1.15 (PC5); also elsewhere on the board
SUBCARRIER-PSK: IC1.14 (PC4); also elsewhere on the board
USB-DM: IC1.26 (PD6), J1.D-
USB-DP: IC1.27 (PD7), J1.D+
USB-SENSE: IC1.25 (PD5), R2.1, R3.2
VCC: C8.1, IC2.3 (IN), Q1.1 (S), Q1.4 (S), Q1.5 (G), SW1.1 (O)

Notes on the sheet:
Based on the open-source NFC tool ChameleonMini: https://github.com/emsec/ChameleonMini Please respect the LICENSE.
N.M. = NOT MOUNTED
Yes, it is a so far unused FREE uC Pin!!
www.kasper-oswald.com

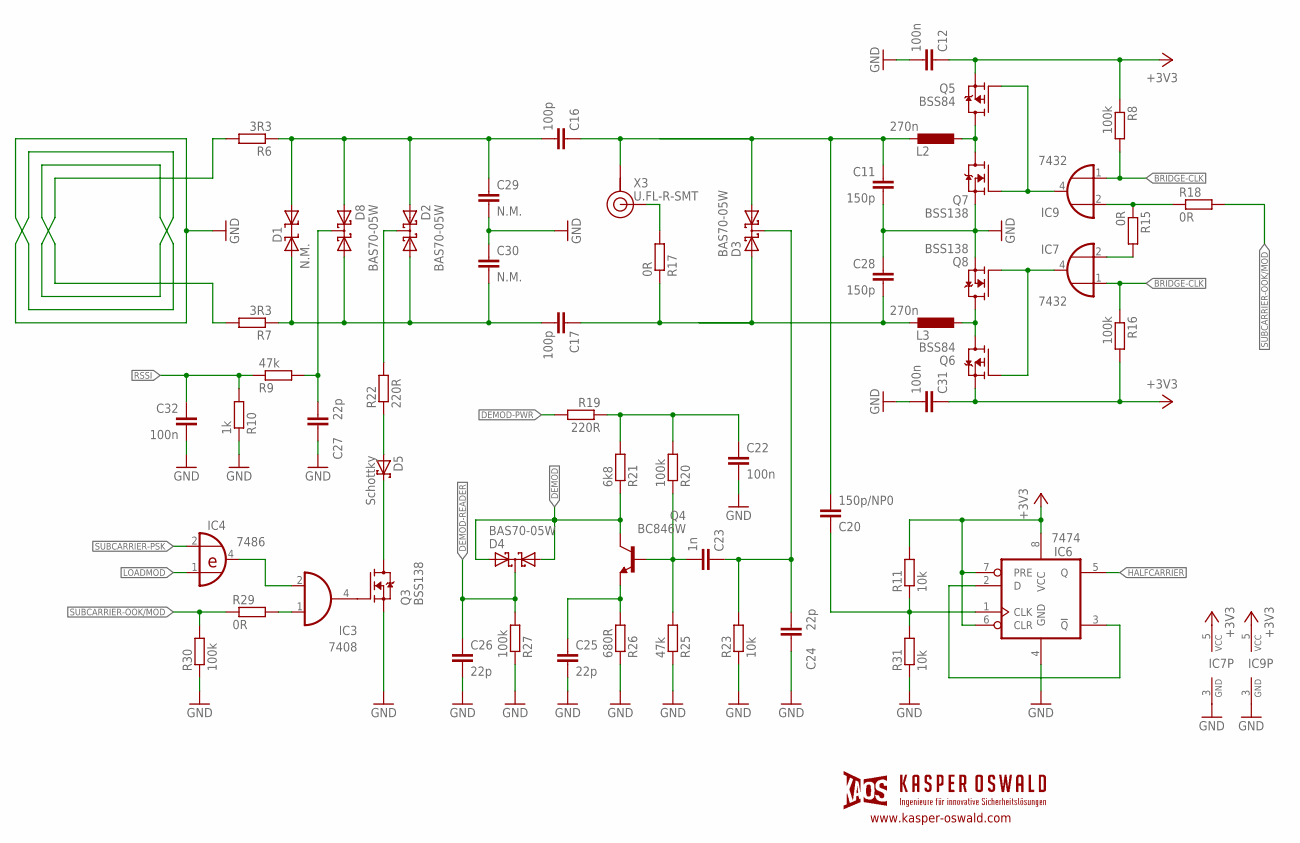
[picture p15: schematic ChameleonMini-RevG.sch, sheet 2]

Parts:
C11, C28: 150p; C0603K
C12, C22, C31, C32: 100n; C0603K
C16, C17: 100p; C0603K
C20: 150p/NP0; C0603K
C23: 1n; C0603K
C24, C25, C26, C27: 22p; C0603K
C29, C30: N.M.; C0603K
D1: N.M.; DO214AC
D2, D3, D4, D8: BAS70-05W; SOT323
D5: Schottky; SOD323(F)
IC3: 7408; SC70-5
IC4: 7486; SC70-5
IC6: 7474; VSSOP8
IC7, IC9: 7432; SC70-5
L2, L3: 270n; L2012C
Q3, Q7, Q8: BSS138; SOT323
Q4: BC846W; SOT323
Q5, Q6: BSS84; SOT323
R6, R7: 3R3; R0603
R8, R16, R20, R27, R30: 100k; R0603
R9, R25: 47k; R0603
R10: 1k; R0603
R11, R23, R31: 10k; R0603
R15, R17, R18, R29: 0R; R0603
R19, R22: 220R; R0603
R21: 6k8; R0603
R26: 680R; R0603
X3: U.FL-R-SMT

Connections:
!BRIDGE-CLK: IC7.1 (I0), R16.1; also elsewhere on the board
+3V3: C12.1, C31.1, IC6.6 (CLR), IC6.7 (PRE), IC6.8 (VCC), IC7.5 (VCC), IC9.5 (VCC), Q5.2 (S), Q6.2 (S), R8.1, R11.2, R16.2; also elsewhere on the board
ANTENNA-A: C11.1, C16.1, C20.2, D3.2 (A2), L2.2, X3.GND1 (GND)
ANTENNA-B: C17.1, C28.2, D3.1 (A1), L3.2, R17.1
BRIDGE-1: IC9.4 (O), Q5.1 (G), Q7.1 (G)
BRIDGE-2: IC7.4 (O), Q6.1 (G), Q8.1 (G)
BRIDGE-CLK: IC9.1 (I0), R8.2; also elsewhere on the board
DEMOD: D4.1 (A1), D4.2 (A2), Q4.3 (C), R21.1; also elsewhere on the board
DEMOD-PWR: R19.2; also elsewhere on the board
DEMOD-READER: C26.1, D4.3 (K), R27.2; also elsewhere on the board
GND: C11.2, C12.2, C22.2, C24.2, C25.2, C26.2, C27.2, C28.1, C29.2, C30.1, C31.2, C32.2, IC6.4 (GND), IC7.3 (GND), IC9.3 (GND), Q3.2 (S), Q7.2 (S), Q8.2 (S), R6.2, R7.2, R10.1, R23.1, R25.1, R26.1, R27.1, R30.1, R31.1; also elsewhere on the board
HALFCARRIER: IC6.5 (Q); also elsewhere on the board
LOADMOD: IC4.1 (I0); also elsewhere on the board
MOD-DEMOD: D2.3 (K), R22.2
MOD-DEMOD1: C23.1, C24.1, D3.3 (K), R23.2
unnamed: C25.1, Q4.2 (E), R26.2
unnamed: IC7.2 (I1), R15.2
unnamed: D5.1 (K), Q3.3 (D)
unnamed: IC6.2 (D), IC6.3 (!Q)
unnamed: C16.2, C29.1, D1.2, D2.1 (A1), D8.1 (A1), R6.1
unnamed: L2.1, Q5.3 (D), Q7.3 (D)
unnamed: IC3.2 (I1), IC4.4 (O)
unnamed: D5.2 (A), R22.1
unnamed: IC3.4 (O), Q3.1 (G)
unnamed: R17.2, X3.SIG
unnamed: L3.1, Q6.3 (D), Q8.3 (D)
unnamed: C17.2, C30.2, D1.1, D2.2 (A2), D8.2 (A2), R7.1
unnamed: C27.1, D8.3 (K), R9.2
unnamed: IC9.2 (I1), R15.1, R18.1
unnamed: C23.2, Q4.1 (B), R20.1, R25.2
unnamed: C20.1, IC6.1 (CLK), R11.1, R31.2
unnamed: IC3.1 (I0), R29.2
unnamed: C22.1, R19.1, R20.2, R21.2
RSSI: C32.1, R9.1, R10.2; also elsewhere on the board
SUBCARRIER-OOK/MOD: R18.2, R29.1, R30.2; also elsewhere on the board
SUBCARRIER-PSK: IC4.2 (I1); also elsewhere on the board

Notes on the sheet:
www.kasper-oswald.com

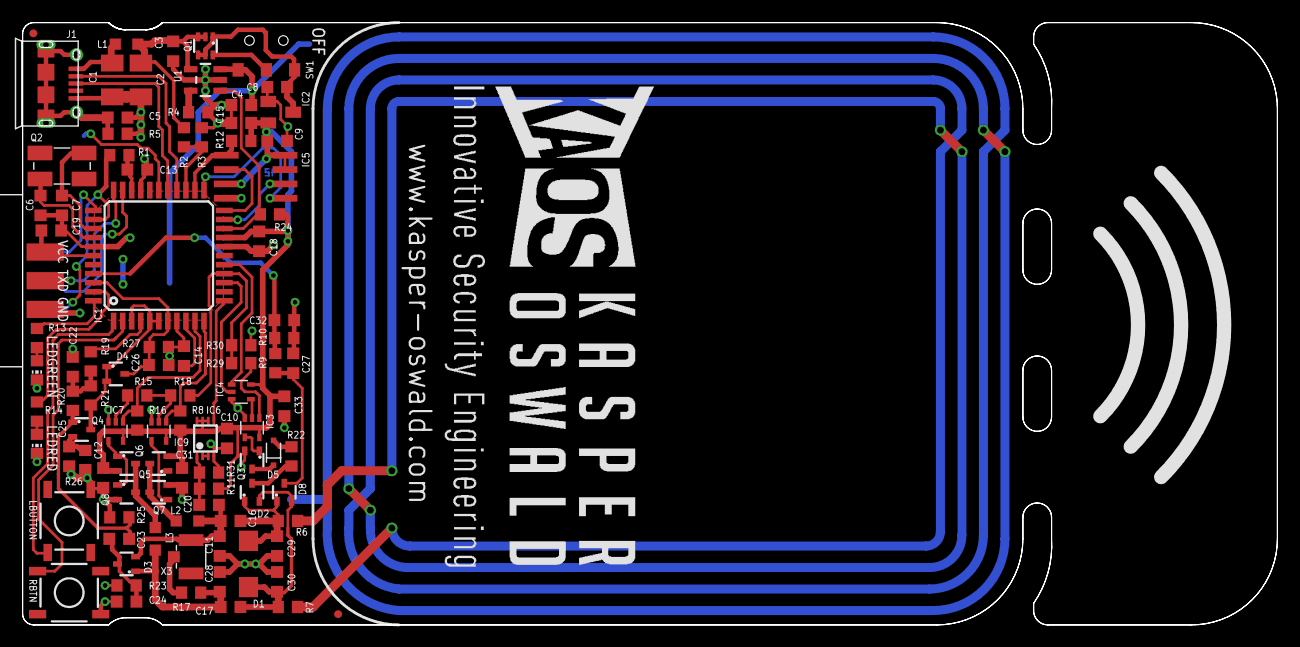
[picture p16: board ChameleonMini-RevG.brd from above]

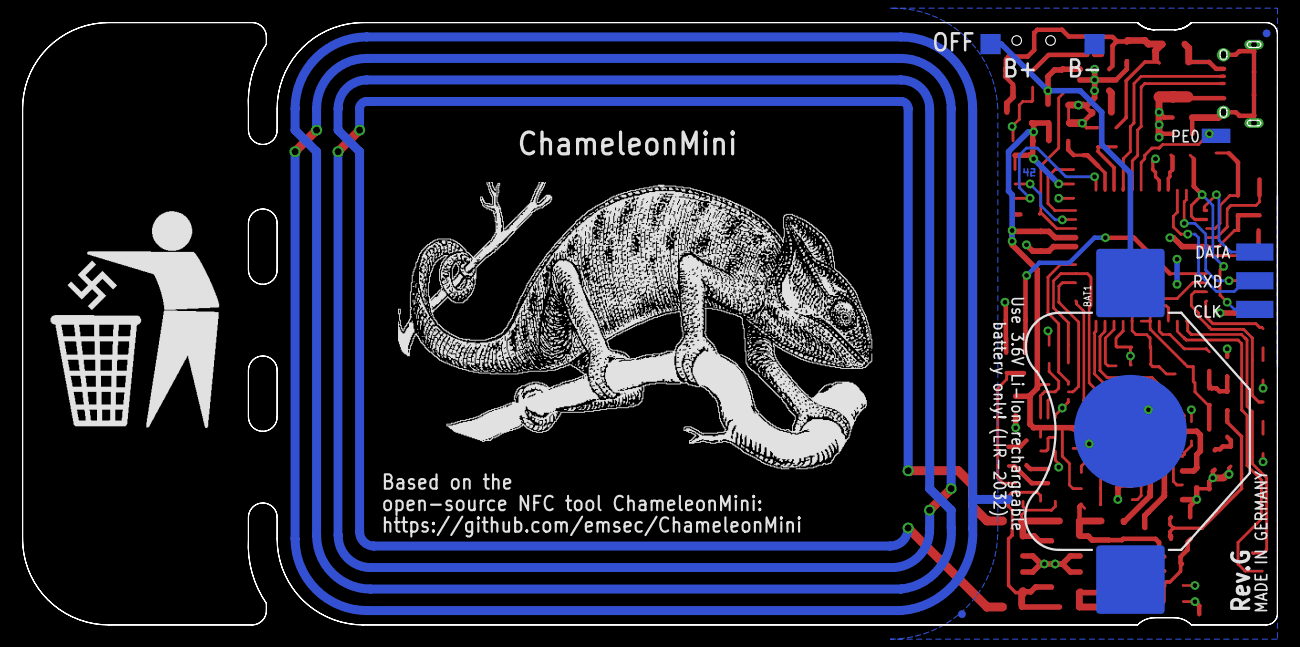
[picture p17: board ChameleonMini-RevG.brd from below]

Board: 2 copper layers, 111.1 x 53.3 mm, 104 parts (6 on the bottom side), 64 nets.

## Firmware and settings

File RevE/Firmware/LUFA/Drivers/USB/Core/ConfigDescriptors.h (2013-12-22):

/*
             LUFA Library
     Copyright (C) Dean Camera, 2013.

  dean [at] fourwalledcubicle [dot] com
           www.lufa-lib.org
*/

/*
  Copyright 2013  Dean Camera (dean [at] fourwalledcubicle [dot] com)

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
  The author disclaims all warranties with regard to this
  software, including all implied warranties of merchantability
  and fitness.  In no event shall the author be liable for any
  special, indirect or consequential damages or any damages
  whatsoever resulting from loss of use, data or profits, whether
  in an action of contract, negligence or other tortious action,
  arising out of or in connection with the use or performance of
  this software.
*/

/** \file
 *  \brief USB Configuration Descriptor definitions.
 *  \copydetails Group_ConfigDescriptorParser
 *
 *  \note This file should not be included directly. It is automatically included as needed by the USB driver
 *        dispatch header located in LUFA/Drivers/USB/USB.h.
 */

/** \ingroup Group_StdDescriptors
 *  \defgroup Group_ConfigDescriptorParser Configuration Descriptor Parser
 *  \brief USB Configuration Descriptor definitions.
 *
 *  This section of the library gives a friendly API which can be used in host applications to easily
 *  parse an attached device's configuration descriptor so that endpoint, interface and other descriptor
 *  data can be extracted and used as needed.
 *
 *  @{
 */

#ifndef __CONFIGDESCRIPTORS_H__
#define __CONFIGDESCRIPTORS_H__

	/* Includes: */
		#include "../../../Common/Common.h"
		#include "USBMode.h"
		#include "HostStandardReq.h"
		#include "StdDescriptors.h"

	/* Enable C linkage for C++ Compilers: */
		#if defined(__cplusplus)
			extern "C" {
		#endif

	/* Preprocessor Checks: */
		#if !defined(__INCLUDE_FROM_USB_DRIVER)
			#error Do not include this file directly. Include LUFA/Drivers/USB/USB.h instead.
		#endif

	/* Public Interface - May be used in end-application: */
		/* Macros: */
			/** Casts a pointer to a descriptor inside the configuration descriptor into a pointer to the given
			 *  descriptor type.
			 *
			 *  Usage Example:
			 *  \code
			 *  uint8_t* CurrDescriptor = &ConfigDescriptor[0]; // Pointing to the configuration header
			 *  USB_Descriptor_Configuration_Header_t* ConfigHeaderPtr = DESCRIPTOR_PCAST(CurrDescriptor,
			 *                                                           USB_Descriptor_Configuration_Header_t);
			 *
			 *  // Can now access elements of the configuration header struct using the -> indirection operator
			 *  \endcode
			 */
			#define DESCRIPTOR_PCAST(DescriptorPtr, Type) ((Type*)(DescriptorPtr))

			/** Casts a pointer to a descriptor inside the configuration descriptor into the given descriptor
			 *  type (as an actual struct instance rather than a pointer to a struct).
			 *
			 *  Usage Example:
			 *  \code
			 *  uint8_t* CurrDescriptor = &ConfigDescriptor[0]; // Pointing to the configuration header
			 *  USB_Descriptor_Configuration_Header_t ConfigHeader = DESCRIPTOR_CAST(CurrDescriptor,
			 *                                                       USB_Descriptor_Configuration_Header_t);
			 *
			 *  // Can now access elements of the configuration header struct using the . operator
			 *  \endcode
			 */
			#define DESCRIPTOR_CAST(DescriptorPtr, Type)  (*DESCRIPTOR_PCAST(DescriptorPtr, Type))

			/** Returns the descriptor's type, expressed as the 8-bit type value in the header of the descriptor.
			 *  This value's meaning depends on the descriptor's placement in the descriptor, but standard type
			 *  values can be accessed in the \ref USB_DescriptorTypes_t enum.
			 */
			#define DESCRIPTOR_TYPE(DescriptorPtr)    DESCRIPTOR_PCAST(DescriptorPtr, USB_Descriptor_Header_t)->Type

			/** Returns the descriptor's size, expressed as the 8-bit value indicating the number of bytes. */
			#define DESCRIPTOR_SIZE(DescriptorPtr)    DESCRIPTOR_PCAST(DescriptorPtr, USB_Descriptor_Header_t)->Size

		/* Type Defines: */
			/** Type define for a Configuration Descriptor comparator function (function taking a pointer to an array
			 *  of type void, returning a uint8_t value).
			 *
			 *  \see \ref USB_GetNextDescriptorComp function for more details.
			 */
			typedef uint8_t (* ConfigComparatorPtr_t)(void*);
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

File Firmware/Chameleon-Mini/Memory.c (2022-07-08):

/*
 * Flash.c
 *
 *  Created on: 20.03.2013
 *      Author: skuser
 */

#include "Memory.h"
#include "Configuration.h"
#include "Common.h"
#include "Settings.h"
#include "LEDHook.h"
#include "System.h"

#define USE_DMA
#define RECV_DMA DMA.CH0
#define SEND_DMA DMA.CH1

/* Convert defines from Makefile */
#define FLASH_DATA_START		FLASH_DATA_ADDR
#define FLASH_DATA_END			(FLASH_DATA_ADDR + FLASH_DATA_SIZE - 1)

/* Definitions for FRAM */
#define FRAM_USART	USARTD0
#define FRAM_PORT	PORTD
#define FRAM_CS		PIN4_bm
#define FRAM_MOSI	PIN3_bm
#define FRAM_MISO	PIN2_bm
#define FRAM_SCK	PIN1_bm

/* Declarations from assembler file */
uint16_t FlashReadWord(uint32_t Address);
void FlashEraseApplicationPage(uint32_t Address);
void FlashLoadFlashWord(uint16_t Address, uint16_t Data);
void FlashEraseWriteApplicationPage(uint32_t Address);
void FlashEraseFlashBuffer(void);
void FlashWaitForSPM(void);

static uint8_t ScrapBuffer[] = {0};

INLINE uint8_t SPITransferByte(uint8_t Data) {
    FRAM_USART.DATA = Data;

    while (!(FRAM_USART.STATUS & USART_RXCIF_bm));

    return FRAM_USART.DATA;
}

#ifdef USE_DMA
INLINE void SPIReadBlock(void *Buffer, uint16_t ByteCount) {
    /* Set up read and write transfers */
    RECV_DMA.ADDRCTRL = DMA_CH_SRCRELOAD_NONE_gc | DMA_CH_SRCDIR_FIXED_gc | DMA_CH_DESTRELOAD_NONE_gc | DMA_CH_DESTDIR_INC_gc;
    RECV_DMA.DESTADDR0 = ((uintptr_t) Buffer >> 0) & 0xFF;
    RECV_DMA.DESTADDR1 = ((uintptr_t) Buffer >> 8) & 0xFF;
    RECV_DMA.TRFCNT = ByteCount;
    SEND_DMA.ADDRCTRL = DMA_CH_SRCRELOAD_NONE_gc | DMA_CH_SRCDIR_FIXED_gc | DMA_CH_DESTRELOAD_NONE_gc | DMA_CH_DESTDIR_FIXED_gc;
    SEND_DMA.SRCADDR0 = ((uintptr_t) ScrapBuffer >> 0) & 0xFF;
    SEND_DMA.SRCADDR1 = ((uintptr_t) ScrapBuffer >> 8) & 0xFF;
    SEND_DMA.TRFCNT = ByteCount;


    /* Enable read and write transfers */
    RECV_DMA.CTRLA |= DMA_CH_ENABLE_bm;
    SEND_DMA.CTRLA |= DMA_CH_ENABLE_bm;

    /* Wait for DMA to finish */
    while (RECV_DMA.CTRLA & DMA_CH_ENABLE_bm)
        ;

    /* Clear Interrupt flag */
    RECV_DMA.CTRLB = DMA_CH_TRNIF_bm | DMA_CH_ERRIF_bm;
    SEND_DMA.CTRLB = DMA_CH_TRNIF_bm | DMA_CH_ERRIF_bm;
}
#else
INLINE void SPIReadBlock(void *Buffer, uint16_t ByteCount) {
    uint8_t *ByteBuffer = (uint8_t *) Buffer;

    while (ByteCount-- > 0) {
        FRAM_USART.DATA = 0;
        while (!(FRAM_USART.STATUS & USART_RXCIF_bm));

        *ByteBuffer++ = FRAM_USART.DATA;
    }
}

#endif

#ifdef USE_DMA
INLINE void SPIWriteBlock(const void *Buffer, uint16_t ByteCount) {
    /* Set up read and write transfers */
    RECV_DMA.ADDRCTRL = DMA_CH_SRCRELOAD_NONE_gc | DMA_CH_SRCDIR_FIXED_gc | DMA_CH_DESTRELOAD_NONE_gc | DMA_CH_DESTDIR_FIXED_gc;
    RECV_DMA.DESTADDR0 = ((uintptr_t) ScrapBuffer >> 0) & 0xFF;
    RECV_DMA.DESTADDR1 = ((uintptr_t) ScrapBuffer >> 8) & 0xFF;
    RECV_DMA.TRFCNT = ByteCount;
    SEND_DMA.ADDRCTRL = DMA_CH_SRCRELOAD_NONE_gc | DMA_CH_SRCDIR_INC_gc | DMA_CH_DESTRELOAD_NONE_gc | DMA_CH_DESTDIR_FIXED_gc;
    SEND_DMA.SRCADDR0 = ((uintptr_t) Buffer >> 0) & 0xFF;
    SEND_DMA.SRCADDR1 = ((uintptr_t) Buffer >> 8) & 0xFF;
    SEND_DMA.TRFCNT = ByteCount;

    /* Enable read and write transfers */
    RECV_DMA.CTRLA |= DMA_CH_ENABLE_bm;
    SEND_DMA.CTRLA |= DMA_CH_ENABLE_bm;

    /* Wait for DMA to finish */
    while (RECV_DMA.CTRLA & DMA_CH_ENABLE_bm)
        ;

    /* Clear Interrupt flag */
    RECV_DMA.CTRLB = DMA_CH_TRNIF_bm | DMA_CH_ERRIF_bm;
    SEND_DMA.CTRLB = DMA_CH_TRNIF_bm | DMA_CH_ERRIF_bm;
}
#else
INLINE void SPIWriteBlock(const void *Buffer, uint16_t ByteCount) {
    uint8_t *ByteBuffer = (uint8_t *) Buffer;

    while (ByteCount-- > 0) {
        FRAM_USART.DATA = *ByteBuffer++;
        while (!(FRAM_USART.STATUS & USART_RXCIF_bm));

        FRAM_USART.DATA; /* Flush Buffer */
    }
}
#endif

INLINE void FRAMRead(void *Buffer, uint16_t Address, uint16_t ByteCount) {
    FRAM_PORT.OUTCLR = FRAM_CS;

    SPITransferByte(0x03); /* Read command */
    SPITransferByte((Address >> 8) & 0xFF);   /* Address hi and lo byte */
    SPITransferByte((Address >> 0) & 0xFF);

    SPIReadBlock(Buffer, ByteCount);

    FRAM_PORT.OUTSET = FRAM_CS;
}

INLINE void FRAMWrite(const void *Buffer, uint16_t Address, uint16_t ByteCount) {
    FRAM_PORT.OUTCLR = FRAM_CS;
    SPITransferByte(0x06); /* Write Enable */
    FRAM_PORT.OUTSET = FRAM_CS;

    asm volatile("nop");
    asm volatile("nop");

    FRAM_PORT.OUTCLR = FRAM_CS;

    SPITransferByte(0x02); /* Write command */
    SPITransferByte((Address >> 8) & 0xFF);   /* Address hi and lo byte */
    SPITransferByte((Address >> 0) & 0xFF);

    SPIWriteBlock(Buffer, ByteCount);

    FRAM_PORT.OUTSET = FRAM_CS;
}

INLINE void FlashRead(void *Buffer, uint32_t Address, uint16_t ByteCount) {
    uint8_t *BufPtr = (uint8_t *) Buffer;

    /* We assume that ByteCount is a multiple of 2 */
    uint32_t PhysicalAddress = Address + FLASH_DATA_ADDR;

    if ((PhysicalAddress >= FLASH_DATA_START) && (PhysicalAddress <= FLASH_DATA_END)) {
        /* Sanity check to limit access to the allocated area */
        while (ByteCount > 1) {
            uint16_t Word = FlashReadWord(PhysicalAddress);

            *BufPtr++ = (Word >> 0) & 0xFF;
            *BufPtr++ = (Word >> 8) & 0xFF;

            PhysicalAddress += 2;
            ByteCount -= 2;
        }
    }
}

INLINE void FlashWrite(const void *Buffer, uint32_t Address, uint16_t ByteCount) {
    const uint8_t *BufPtr = (uint8_t *) Buffer;

    /* We assume that FlashWrite is always called for write actions that are
     * aligned to APP_SECTION_PAGE_SIZE and a multiple of APP_SECTION_PAGE_SIZE.
     * Thus only full pages are written into the flash. */
    uint16_t PageCount = ByteCount / APP_SECTION_PAGE_SIZE;
    uint32_t PhysicalAddress = Address + FLASH_DATA_ADDR;

    if ((PhysicalAddress >= FLASH_DATA_START) && (PhysicalAddress <= FLASH_DATA_END)) {
        /* Sanity check to limit access to the allocated area */

        while (PageCount-- > 0) {
            /* For each page to program, wait for NVM to get ready,
             * erase the flash page buffer, program all data to the
             * flash page buffer and write buffer to flash using
             * the atomic erase and write operation. */

            FlashWaitForSPM();

            FlashEraseFlashBuffer();
            FlashWaitForSPM();

            for (uint16_t i = 0; i < APP_SECTION_PAGE_SIZE; i += 2) {
                uint16_t Word = 0;

                Word |= ((uint16_t) * BufPtr++ << 0);
                Word |= ((uint16_t) * BufPtr++ << 8);

                FlashLoadFlashWord(i, Word);
                FlashWaitForSPM();
            }

            FlashEraseWriteApplicationPage(PhysicalAddress);
            FlashWaitForSPM();

            PhysicalAddress += APP_SECTION_PAGE_SIZE;
        }
    }
}
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

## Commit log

2013-12-22 Changed MCU to ATxmega32A4U
    [Chameleon-Mini-RevE-2.brd, Chameleon-Mini-RevE-2.sch, Chameleon-Mini-RevE.brd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]
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2014-01-02 Fixed bug with Button setting CYCLE_SETTINGS
2014-05-11 Fixed a bug where the wrong SPI mode for the external dataflash has been used in Memory.c/.h
    [Memory.c]
2014-05-11 Due to some readers and/or card standards there might be problems with the comparatively large write times of the external flash memory. This is why we are looking for a better solution on this probl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
    [Memory.c]
2015-03-03 Major improvements (amongst others Mifare Ultralight and 7-Byte UID MF Plus support) and major bug fixes. Thanks to Simon Küppers and Julius Schmalz.
    [Configuration.h]
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2015-03-03 Update and rename Drivers to Drivers/ChameleonDriver.inf
    Created driver .inf for new USB PID
2016-10-07 moved discontinued RevE files to own directory
    [Chameleon-Mini-RevE-2.brd, Chameleon-Mini-RevE-2.sch, Chameleon-Mini-RevE.brd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]
2016-10-07 update to RevG
    [BoardDeviceMap.cfg, BootloaderDeviceMap.cfg, ChameleonMini-RevG.brd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]
2016-10-12 Fix wrong parameter name in LEDSetFuncById() if LED_SETTING_GLOBAL disabled
2016-10-19 Added udev rule in Drivers/
    Added udev rule, allowing non root users on a linux system(assuming udev is used) to open the serial port and talk with the chameleon.
    Also included symlink in rule, so the interface always shows as /dev/chameleon.
2016-10-21 Added linux udev info to Doc/DoxygenPages/GettingStarted.txt
    Info on how to install Drivers/98-ChameleonMini.rules under linux.
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2017-04-04 added Reader_FWT variable Application with this may now change the frame waiting time which may be helpful for ISO14443A-4 processing
2017-04-04 major changes in log function and memory functions: 1. relocated EEPROM accessing functions 2. current FRAM log address is stored in FRAM 3. EEPROM contains flag that indicates whether this address i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
2017-06-15 Add CLONE command
    This command is extended original identify command. Upon execution it
    will do following:
    - change current config to "reader" mode
    - identify card
    - if multiple or no card detected -> end
    - change config to identified card (mifare classic 1k/4k or ultralight)
    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
2017-11-07 fixed LED bug, now blinks faster without problems
    [Memory.c]
2017-11-07 fixed bug within cycle_settings button functionality
2017-11-07 unified indentation
    [Configuration.h]
2017-11-17 UL EV1: initial working version
    [Configuration.h]
2017-11-23 RevE-light development version
    WARNING: The files in this commit are our current development version. The hardware and software is not functional yet - so do not use it. We will not answer any support inquiry regarding this versio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
    [Configuration.h, RevE-light.brd, RevE-light.sch]
2017-11-23 Fixes to Readme and schematics PDF of RevE-light
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2018-08-15 Remove repeately called function: CodecInitCommon and keep demod power on
    (cherry picked from commit 8eb0d58)
2018-08-15 Separate Card->Reader code, works for only one round of traffic Buggy commit. Maybe fix the event channel and reinit the timer when switching
    (cherry picked from commit a43869a)
2018-08-15 Event Channel and PORTB int1 bug fix:
    1. Use event CH2 for timer resetting
    2. Can not sniff the second round of traffic due to the PORTB int1 was disabled in CardSniffInit(). This is reenabled in ReaderSniffInit
    (cherry picked from commit 24b87e2)
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2018-08-15 Fix bug: ACA interrupt start after the card->Reader traffic start, so sometimes get not complete trace
    Another buffer used for store card->reader traffic is added, so that card->reader traffic sniffing can start right after the reader->Card trafic sniffing finished.
    (cherry picked from commit e074fcc)
2018-08-15 Fix bug, card traffic is not right when using logmode=memory
    Print log after a round finished
    Otherwise it will take too much cpu cycles then the card traffic sniffing may not start in time
    (cherry picked from commit 48c89f5)
2018-08-15 Optimise the Card->Reader Manchester decoder in Sniffing to make it faster
    It now decode and sample in the same time, so the decode half bit sampling to Manchester in the CodecTask can be removed.
    This optimisation may also fix the bug that the CodecTask not finished after start of Reader->Card Sampling and make the reader->Card sampling not in perfect timing and cause the Reader ->Card Sniffed data to be wrong.
    Trace from oscilloscope for the Problem:
    ReaderSniffing Enable
    __________ _________
    __| |____________________| |_________
    CardSniffing Enable
    _____________ ____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
2018-08-15 Add Framework for autocalibrate of Sniffing Mode
    (cherry picked from commit c8606be)
2018-08-15 Trace the Reader and card status in sniffing mode
    This will prepare for the autocalibrate of threshold
    If card selection fully detected, then the threshold is good,
    Otherwise it is not good.
    (cherry picked from commit f5c8485)
2018-08-15 Basic auto calibrate for sniffing mode.
    Started from the smallest threshold and when the first good threshold is obtained, stop.
    May also need to extend the TIMEOUT to make this work.
    Need the reader reading all the timing when sniffing in order to auto calibrate
    (cherry picked from commit 2c3d5f5)
2018-08-15 Continue threshold searching from the last searched value or the current configured value
    (cherry picked from commit f3aa7b2)
2018-08-15 Decode sniffing data with parityBit in Python Software
    If parity bit check failed, ! is appended to the data and raw data is diaplayed
    Currently Software layer parity bit check and removal is only enabled in sniffing mode
    (cherry picked from commit 2cfd54a)
2018-08-15 Full implement decoding half-Duplex Data Trans Protocol in iso14443-4 (Show PCB Block infos)
    (cherry picked from commit 9f469be)
2018-08-17 added ISO15693 codec
    [Configuration.h]
2018-08-17 added vdwels changes
    [Configuration.h]
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2018-11-10 Porting Rickventura changes to the main repo
    [Configuration.h]
2018-11-10 Switched to ISO15693Addressed. Fixing indentation
2018-11-28 Added tag family configuration
    [Configuration.h]
2018-11-29 Added bitmask to track locked blocks, Lock Block command, sanity checks on received data.
2018-12-04 Fixed couple of indent mistakes
2018-12-10 EM4233 first draft
    [Configuration.h]
2018-12-25 Current codec status, not working after APP_NO_RESPONSE
2018-12-26 Added comments and fixed a bug in codec's source
    ISO15693 codec was undocumented and without comments in relevant parts. I decided to spend 3 days diving into XMega interrupts and Chameleon's lowest level code. Now, I hope, it should be more readable for everyone, even newbies like my old self was before I started this deep dive.
    Also, I fixed the bug referenced here https://github.com/geo-rg/ChameleonMini/issues/4 which locked the chameleon when no response was to be sent to the reader
2018-12-26 Removed old LockBit masks and updated a couple of commands to mimick real tag behaviour
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2018-12-28 Fixed Select command and some minor bug fixes
    Select command did not fall back to READY state if Select was issued on another tag.
    PrepareFrame allowed the tag to respond to Selected requests even if we were not in SELECTED state.
    Also fixed Read Single and Read Multiple out of bound reads in case of addressed commands.
2019-03-05 Added stub EM mutual auth commands and fixed a couple of bugs
    E0 and E1 commands will be expanded as reverse engineering continues. At the moment E0 will be used to work on reader response to A1 random number.
    Fixed 2 different bugs in Login. Fixed Lock DSFID command
    Removed frame integrity checks from PrepareFrame, since it's already needed to do them before PrepareFrame should be called
2019-03-05 Fixed a couple of validity checks and updated Titagitstandard.c to new PrepareFrame
2019-03-17 Added preliminary support for NTAG215
    [Configuration.h]
2019-08-16 Add Mifare Mini support
    [Configuration.h]
2019-09-17 Added Mifare Ultralight C support. Changed SettingsSetActiveById() to first MemoryRecall() before initializing Application.
    [Configuration.h]
2019-09-17 fixed indentation
    [Configuration.h]
2019-11-15 run make style #237
    [Configuration.h]
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2019-12-08 Faster ISR sharing in ASM
    While in the process of writing a new codec I stumbled upon the long
    standing issue of ISR sharing in AVR MCUs.
    Actually this is accomplished with an ISR written in C, which simply
    calls another plain C function referenced via a function pointer
    updated at runtime.
    This approach is slow because GCC can't optimize the ISR, since it
    does not know which registers will be used, so it defaults to push/pop
    all of them.
    My solution keeps the concept of pointers to functions, but greatly
    improves speed by reducing the ISR itself to the bare minimum to call
    another function, which will be compiled by GCC as a signal.
    This means all interrupt optimizations will be put in pla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
2020-01-14 fixed missing ifdef in configuration
    [Configuration.h]
2020-08-26 Updated code to build with GCC 10 - Updated ISR Sharing
    Since GCC 10, the compiler defaults to -fno-common, thus variables with
    multiple tentative definitions result in linker errors.
    We've (me and @MrMoDDoM) extern-ed the shared variables to fix the issue.
    Also, when I implemented ISR sharing, somehow I forgot about a function
    which was shared as well, so I fixed that mistake and added a couple of
    comments on how shared function calls work.
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2020-09-03 ISO15693 Codec minor fixes
    Unvarying interrupt configuration moved from StartISO15693Demod to CodecInit
    Fixed an old issue (https://github.com/geo-rg/ChameleonMini/issues/4) properly
    overwriting the PERBUF register when no data has to be sent
    Loadmodulation ISR has a new GOTO label which is called when ISO t1 time is
    elapsed, but data is not yet ready. This way it is possible to avoid checking
    for state validity on every ISR hit
    New inline function to clean up interrupts when field noise (garbage)
    is incorrectly picked up
    Bitrate configuration in ISO15693_EOC has been simplified
    Cleaned up header file with useless defines. Moved defines to .c when there was
    no need to share them with other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
2020-09-03 Improved ISO15693 applications performance
    Removed the if-elseif in EM4233 to use a switch case which yields minor
    speed improvements of ~1,5 microseconds
    Avoid reading the UID every AppProcess tick in both EM4233 and TiTagIT
    to save ~11 microseconds.
2020-09-10 Fixed timing issues with Read Multiple Blocks
    ISO15693 CRC calculation is slow and it delayed too much transmission of long
    frames. Some readers marked transmission as unsuccesfull and ignored data.
    Moving CRC calculation inside the codec allows to start modulating the field
    while the CRC is not yet ready but, by the time it has to be trasmitted,
    calculation will be done.
    This fixes https://github.com/emsec/ChameleonMini/issues/262
    In EM4233, there still are issues with Read Multiple command when block
    locking status is requested for more than 0x1F blocks
    Implemented a check in ISO15693 codec to avoid out of bound CRC writes.
2020-10-14 Elf sections check before flash
    Due to the addition of new codecs and applications, code size grew to
    overwrite the part of FRAM currently used to store card slots (settings).
    This simple (although hacky) makefile command verifies if such an
    issue will occur before flashing the firmware.
2020-10-15 Pushing fixes to LiveLogTick, bounds checking for memory functions writing to FRAM within a setting, and elf binary file space reducing modifications to the Makefile
    [Memory.c]
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2020-10-17 Updating the Makefile and relevant source code that has to change to support disabling common config targets
    [Configuration.h]
2020-10-17 The remainder of the changes to the source code made during the DESFire mod development
    [Configuration.h]
2021-04-09 Add implementation of TI Tagit Plus vicinity card. Remove unapparent configuration dependency on CONFIG_ISO15693_SNIFF_SUPPORT for vicinity card applications to compile by extending criteria when to 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
    [Configuration.h]
2022-01-27 Fixing commented multi-line macro in violation of the `make style` guidelines
    [CryptoAES128.h]
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2022-02-03 Working AES128 auth ; Nearly working ISO auth (still debugging) -- Stashing copy for reference
    [Configuration.h]
2022-02-05 Working AES128 auth and ISO auth ; Still need to debug the legacy auth
    [Configuration.h]
2022-02-11 Bug fixes to observations in #313
    [Memory.c]
2022-02-11 Removing default testing nonce B from auth commands ; Running make style
    [Configuration.h]
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2022-02-14 Swapping out previous __flash settings for commands lookup table into last half of LOG_FRAM (code and Makefile defines -- may still need to extract this new section using avr-objcopy -- pending testi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
    [Memory.c]
2022-02-14 *Should* finally be working now -- Problem was that the SETTINGS memory remapped the FLASH memory space used by avr-gcc\'s __flash to a custom .flashdata section after the LUFA build by a second call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
2022-02-23 Sniff15693: Autocalibrate: Detect error case
    Detect the case, that we never receive a valid card frame.
    Restore original/recent threshold in this case.
2022-06-15 Fixing the terminal (echo) printing on MacOS following the last commit for Linux users
2022-06-29 Updating the FLASH_DATA_ADDR value to the correct value for 6 slots (versus standard 8)
2022-07-01 Stashing DESFire updates before tinkering with saving space with PSTR wrappers around the terminal command names
    [Configuration.h]
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2022-07-20 Current firmware builds tested with PM3 and LibNFC test code ; Still takes too long to verify the file mgmt and data manip programs
2022-10-14 Fix frame processing for DESFire EV1 in edge cases
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2022-12-05 Fix loading when changing slots

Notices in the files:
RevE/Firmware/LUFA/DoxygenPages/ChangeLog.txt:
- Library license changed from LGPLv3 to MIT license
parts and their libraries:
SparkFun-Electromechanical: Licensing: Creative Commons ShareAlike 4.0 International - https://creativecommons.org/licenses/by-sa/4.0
